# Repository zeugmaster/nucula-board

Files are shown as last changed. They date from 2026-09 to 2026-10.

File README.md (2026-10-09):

# Nucula Board

An ESP32-C3 hardware prototype with USB-C, battery charging, PN7160 NFC,
an SSD1309 OLED interface, and a detachable I²C keyboard section.

**Current production files: [production-2026-10-09-package.zip](manufacturing/production-2026-10-09-package.zip).**
The current board preserves rev-A NFC copper, matching values and placement,
including its small vias, filled/capped fabrication and JLC04161H-3313 stackup.
It retains the corrected display mapping, USB isolation redesign, MINI-1 module,
six M2 holes, inward battery connector and rounded cable notch.
[Production instructions and validation scope](docs/production-release.md).
All previous October packages are superseded for this order. Revised USB/display
operation and the new NFC substitutes still require bench validation. See the
stock-substitution qualification included in this release.

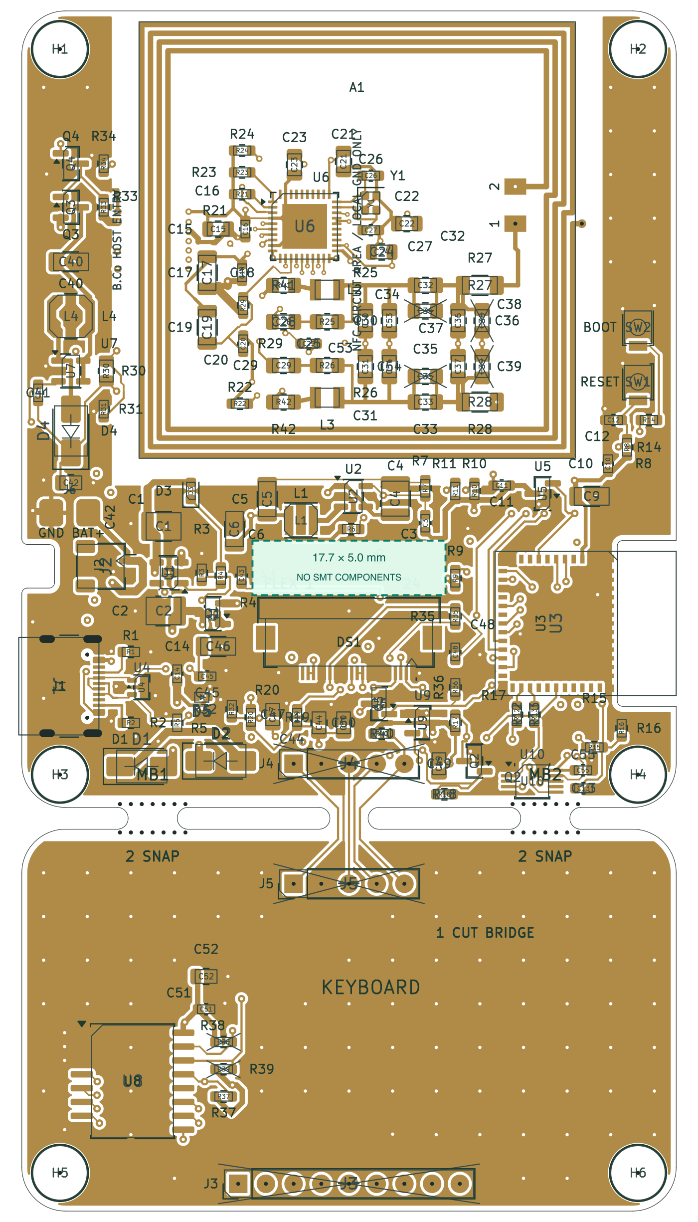
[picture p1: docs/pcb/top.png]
Nucula v2 PCB layout


## Open the design

Clone this repository and open `nucula-v2.kicad_pro` in **KiCad 10** with its
standard symbol, footprint and 3D libraries installed. Project-specific libraries
use relative paths. The project filenames retain the hardware revision name
`nucula-v2`; the GitHub repository is `nucula-board`.

```sh
git clone https://github.com/zeugmaster/nucula-board.git
cd nucula-board
python3 tools/check_schematic.py
```

The check requires Python 3 and KiCad CLI. See [validation and repository
notes](docs/publication.md) for other checks, dependencies and historical inputs.

## Hardware and documentation

The five-sheet schematic contains the ESP32-C3-MINI-1-H4X, native USB-C data,
a 100 mA single-cell Li-ion charger with JST-SH connector, USB/battery supply
selection, a 3.31 V buck rail, and boot/reset/voltage supervision. It is adapted
from Olimex ESP32-C3-DevKit-Lipo **revision C**. It now includes the PN7160 NFC
controller and antenna matching tree, SSD1309 OLED glass driver/boost supply,
and a detachable PCF8574T keyboard section. The four-layer PCB is placed and
routed, with all components on top and the NFC circuitry inside the coil.

- [M2 mounting-hole positions, clearances and validation](docs/mounting-holes.md)
- [MINI-1 compatibility, pin map, antenna fit and firmware requirements](docs/esp32-mini.md)
- [Completed PCB layout, layer drawings and validation](docs/pcb-layout.md)
- [Rev-A display correction, backfeed investigation and measurements](docs/bringup/rev-b-display-and-usb.md)
- [Rev-A bench procedure with enlarged probe-pad map (PDF)](docs/bringup/rev-A-usb-bench-guide.pdf)
- [Routing repair, before/after comparison and geometry audit](docs/routing-review.md)
- [Standard manufacturing package and order settings](docs/manufacturing-release.md)
- [Current prototype manufacturing ZIP](manufacturing/production-2026-10-09-package.zip)
- [Side-entry battery connector selection, polarity and assembly instructions](docs/battery-connector.md)
- [Circuit simulation screening, findings and model limits](docs/simulation/README.md)
- [Schematic PDF](docs/schematic.pdf)
- [Design choices, datasheets and outstanding hardware limits](docs/power-design.md)
- [NFC, OLED, I²C pin map and breakaway keyboard design](docs/peripherals-design.md)
- [35 mm keyboard breakaway geometry and separation instructions](docs/keyboard-breakaway.md)
- [40 mm NFC coil, calculated matching values and prototype tuning guide](docs/nfc-antenna.md)
- [Selected crystal, capacitor calculations and confirmed prototype interfaces](docs/component-refinements.md)
- [Five-board assembly audit and historical sourcing notes](docs/assembly-readiness.md)
- [Manufacturing simplification and ribbon-clearance changes](docs/standard-fabrication.md)
- [BOM](docs/bom.csv) and [verification results](docs/verification.json)
- [Project library sources and licenses](libraries/README.md)

Battery target: approximately 400 mAh, protected single-cell Li-ion/LiPo,
3.7 V nominal / 4.2 V full. J2 is **JST SH SM02B-SRSS-TB(LF)(SN), C160402**:
**side entry, 1.00 mm pitch, 2.95 mm mated height**, opening toward the left
edge. Use an **SHR-02V-S-B** lead, pin 1 positive and pin 2 ground; the old
PH plug no longer fits. Charging remains 100 mA (0.25C at 400 mAh).
Battery operation remains optional. The user accepts intermittent peaks above
the connector's 1 A rating; no current limit is added. Runtime, discharge
qualification and low-battery improvements remain deferred.
[Connector dimensions, current assumption and assembly details](docs/battery-connector.md).
The intended USB source is a dedicated **5 V / at least 1.5 A** supply; the
steady-state planning budget is about 1.10 A including charging. Startup/inrush
must be tested; operation from arbitrary computer hosts is not qualified.

Run `python3 tools/check_schematic.py` to repeat ERC, connectivity, pad/model and
voltage checks. KiCad's standard symbols, footprints and 3D models are required;
`KICAD_CLI` and `KICAD_SHARE` can override their locations. The project-specific
parts and the ESP32 STEP model are included with relative paths in `libraries/`.
The optional PN7160 3D model is omitted because its terms prohibit redistribution;
its symbol and electrical footprint are included.
All 130 schematic components have assigned footprints; the PCB also includes
two breakaway footprints and six mechanical mounting holes. A1 is a reusable four-turn
40 × 40 mm PCB coil with its bottom return and copper keepout included. The NFC
tree retains the rev-A values, 0805 tuning pads and TX isolation links; no retuning
change was made for this release. [A separate bare-coil coupon](prototypes/nfc-antenna/nfc-antenna.kicad_pro)
is available for fabrication and measurement. The OLED now uses the **24-contact
CON24 pinout** in the reference breakout schematic, superseding the earlier
26-contact assumption. DS1 is a Hirose FH12A-24S-0.5SH(55), 0.5 mm top-contact socket (C506794).
[Pinout and regression checks](docs/oled24/README.md) cover all 24 connections.
In the mounted PCB top view, panel pin 1 is left and pin 24 right:
**panel pin n connects to Hirose socket pad 25−n**. The manufacturer footprint
numbering is preserved; the mounted-contact checker now verifies this distinction.
The target panel has ribbon marking **NFP1309-02Y**: 2.4-inch COG,
0.50 mm pitch, 0.30 mm flex, contacts on the emitting face. In its confirmed
mounted position the tip contacts face away from the PCB. The
[top-contact update and checks](docs/oled24/top-contact.md) cover the new lands,
paste apertures and 0.20 mm placement adjustment. The display and external keypad are excluded
from the assembly BOM; DS1 purchases the socket only.
See the library notes for unavailable models.

The shared I²C bus runs at 100 kHz: PN7160 `0x28`, SSD1309 `0x3C`, PCF8574T `0x20`.
PCF8574T is an eight-bit I/O expander; no bus multiplexer is needed.
Its SOIC-16W_7.5x10.3mm_P1.27mm footprint matches the earlier BOM.
J3 is the user-fitted, DNP nine-pin keyboard header: **pins 1 and 9 are NC;
pins 2–8 connect to P0–P6**, preserving the early board's seven-line order.
[Keypad pinout and scanning notes](docs/keyboard-interface.md).
J4/J5 are optional DNP
five-pin headers for reconnecting the keyboard section after separation.

Y1 is now NDK NX2016SA-27.12MHZ-EXS00A-CS06346 (JLCPCB C3008209),
2.0 × 1.6 mm, with calculated 12 pF / 15 pF load-capacitor starts. Power
capacitor ordering codes and larger bulk footprints are selected using archived
manufacturer DC-bias curves. Run `python3 tools/check_component_choices.py` to
reproduce those estimates. RF tuning, oscillator qualification and power
measurements remain prototype bring-up work. **Placement and routing are complete**
for the agreed USB-powered prototype. Native PCB DRC has zero errors and zero unconnected or schematic-parity findings.
The 33 reviewed warnings are cosmetic. The exact NFC comparison covers 43
footprints and 366 routing objects. Strict routing findings inherited from the
proven NFC layout are disclosed and preserved; there are no new routing findings.
The 261 preflight and 57 USB SPICE cases were rerun, plus the independent NFC
numerical cross-check. [Full scope](docs/production-release.md).

Git tracks design files, project libraries and documentation. Local editor state,
lock files, automatic backups and KiCad's `.history` are ignored.

Manufacturing files now target five bare four-layer boards, nominal 1.6 mm,
black mask, white legend and ENIG using the rev-A JLC04161H-3313 stackup.
All small plated round holes require epoxy filling and copper capping; the
restored NFC uses 0.20 mm drill / 0.45 mm land and 0.30 / 0.60 mm vias.
There is no controlled-impedance requirement. The October package includes
119-part placements, stencil data, assembly drawings, and JLCPCB BOM/CPL inputs.
Its BOM includes the USB redesign and side-entry J2. J6 direct battery wire pads
are etched copper and need no purchased component.
[Manufacturing changes and validation](docs/standard-fabrication.md).

The [JLCPCB r2 archive](manufacturing/jlcpcb-2026-09-21-r2-package.zip) records
the previously submitted board and remains unchanged. Its order settings and
placements belong to that earlier design. Use the October prototype package
for the revised design; USB reconnection, ESD and display operation still need
validation on revised hardware.

## License and attribution

The hardware design is distributed under [CERN-OHL-S-2.0](LICENSE), retaining
the attribution and license of the Olimex ESP32-C3-DevKit-Lipo revision C design
from which the power section was adapted. Third-party library assets and
reference documents retain their own terms; see [library attribution](libraries/README.md)
and [LICENSES](LICENSES/). These notices do not grant additional rights to
third-party material. Firmware is not included in this repository.

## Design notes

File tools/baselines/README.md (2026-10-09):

# Sanitized regression inputs

These ZIPs contain the design/report files used by the historical USB and OLED
regression checks. They preserve comparison geometry without publishing private
Git history. Filenames identify the original revision. Personal filesystem paths
and the restricted optional PN7160 3D-model reference have been removed; circuit
connections, pad geometry, placement and routing are preserved.

Read them through `historical_source.read_baseline`. The hardware license and
third-party attribution at the repository root apply to these inputs as well.

`rev-A-nfc.zip` pins the submitted rev-A board/schematic, manufacturing export
stackup and native copper-geometry extraction for the exact NFC freeze audit.
The source board SHA-256 is independently checked against the recorded release.

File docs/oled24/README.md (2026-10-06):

# OLED correction to the 24-contact interface

2026-09-21 · KiCad 10.0.6

**Current socket: FH12A-24S-0.5SH(55), C506794, top contacts.**
The [subsequent top-contact update](top-contact.md) supersedes the socket and
placement described in the historical 26-to-24-contact correction below.
**October correction:** mounted panel pin 1 is PCB-left and pin 24 PCB-right.
Display pin n now maps to **DS1 socket pad 25−n** at the unchanged 180° placement.
Use the [mounted-contact checks](mounted-mapping-check.json) and
[current correction report](../bringup/rev-b-display-and-usb.md).
The sections below record the historical September change against `600d88a`;
their contact numbers describe the panel, not the corrected socket pads.

The user's [exact breakout schematic](../../parts%20documentation/i2c-display-breakout-schematic.png.png)
shows **J1 CON24**. This supersedes the previous 26-contact assumption.
The project symbol, schematic, PCB footprint, 3D socket model, BOM and purchasing
data now use **24 contacts**. The symbol describes the glass interface; the
purchased DS1 item is the socket, **Hirose FH12-24S-0.5SH(55), C202112**.

## Pinout checked against the supplied image

| Contacts | Breakout function | Project connection |
|---|---|---|
| 1, 2, 3 | GND, VLSS, VSS | GND |
| 4 | N.C. | Explicitly unconnected |
| 5 | VDD | +3V0 logic supply |
| 6 | BS1 | +3V0; I²C interface selection |
| 7, 8 | BS2, CS# | GND |
| 9 | RES# | OLED_RES_N, Q5/R35/C48 reset network |
| 10 | D/C# | GND; I²C address 0x3C |
| 11, 12 | R/W#, E/RD# | GND |
| 13 | D0 | I2C_SCL |
| 14, 15 | D1, D2 | Both connect to I2C_SDA |
| 16–20 | D3–D7 | GND |
| 21 | IREF | OLED_IREF, R32 = 910 kΩ to GND |
| 22 | VCOM | OLED_VCOMH, C47 to GND |
| 23 | VOP | OLED_12V5 panel supply |
| 24 | GND | GND |

Pins 1–24 retain their previous net assignments. Only the nonexistent ground
contacts 25 and 26 were removed. Pin 2's label is corrected to VLSS and pin 23's
label to VOP_PANEL. The project's existing 3.0 V logic supply, switched AP3012
boost, reset translation and component values remain unchanged; this update
does not claim to duplicate the breakout's XC6206/HM1308 circuitry.

[Machine-readable source map](pinout.json) records the reference image hash and
all 24 expected connections independently of the symbol and PCB.

## Placement and routing

DS1 remains locked at **(80, 108.65 mm), 180° on F.Cu**. The standard 24-position
footprint is 1 mm narrower than the former 26-position version. Keeping its
center fixed moves each retained contact 0.50 mm left on the board.

The local pad escapes were rerouted, with 43 old segments replaced by 40 new
segments and five existing vias shifted. The board now has **1,066 trace segments
and 321 vias**. Changes are confined to the OLED connector area. Copper zones
were refilled on all four layers without altering zone boundaries or rules.

All other 129 footprints are identical to the saved baseline. Component
positions, population flags, values, antenna copper and keepouts, symmetric NFC
matching branches, USB routing, keyboard breakaway and all board graphics are
preserved, including the user's back silkscreen and black mask settings.

## Regression results

- Native ERC: **0 violations**, five sheets, 128 physical components, 91 nets.
- Native PCB DRC with all-track checking: **0 errors, 0 unconnected items,
  0 schematic parity issues**. The same two U3 silkscreen-edge warnings remain,
  with the same affected item UUIDs as the freshly checked baseline.
- **23/23 existing layout checks pass**, including all-layer NFC pour exclusion,
  fixed placements, matched RF geometry, breakaway crossings and USB ground reference.
- **31/31 connector and regression checks pass**. All 91 nets are identical
  except for removing DS1.25/26 from GND. No unrelated validation constraints
  were relaxed. KiCad's omission of an empty `zone_defaults` element is ignored
  as serialization normalization; actual setup and stackup settings match.
- All physical symbols resolve to footprint pads; referenced 3D models resolve.
  Assembly audit passes with the new exact socket MPN and C-code.
- All **261 scoped ngspice cases** completed without solver errors. Numerical
  results match the previous run exactly, including its already documented
  600 pF I²C stress-limit failure. This is regression evidence for the modeled
  circuits, not full-board or panel simulation.
- The updated OLED schematic and connector rendering were visually reviewed.
  The PCB editor was reloaded after confirming it held no intervening edits.

[Regression report](regression-check.json) · [Baseline DRC](baseline-drc.json) ·
[Current DRC](../pcb/drc.json) · [Layout checks](../pcb/layout-check.json) ·
[Schematic PDF](../schematic.pdf) · [PCB layer PDF](../pcb/layers.pdf) ·
[Simulation scope and findings](../simulation/README.md)

Reproduce with `tools/check_schematic.py`, native KiCad PCB DRC,
`tools/check_pcb_layout.py` (KiCad's Python), `tools/check_assembly_readiness.py`,
`tools/simulate_preflight.py` and finally `tools/check_oled24_update.py`.
The last check compares against commit `600d88a` and requires fresh simulation
and netlist results for the current saved design.

## Panel identification and remaining mechanical check

On 2026-09-21 the user identified one of the intended displays as a **2.4-inch
chip-on-glass panel with `NFP1309-02Y` printed on its ribbon**, and confirmed:

- **0.50 mm contact pitch**.
- **0.30 mm insertion thickness**.
- **Exposed contacts on the same face as the light-emitting display surface**.
- **With the display mounted and ribbon folded into DS1, the tip contacts face
  away from the PCB** (subsequently confirmed by the user).

These are user-confirmed properties of that panel. An exact-marking web search
did not locate a manufacturer datasheet; the ribbon marking is not treated as a
verified manufacturer ordering code. Other display variants must be checked
separately. The supplied CON24 breakout remains the electrical pin-map source.

The selected socket is now **Hirose FH12A-24S-0.5SH(55), C506794**, with top
contacts matching the confirmed insertion orientation. Its manufacturer drawing,
lands, pin order, paste pattern and updated placement have been checked. The
[completed connector update](top-contact.md) includes the revised schematic/PCB,
BOM, sourcing observation and regression reports. The 0.20 mm move toward the
keyboard clears the larger latch while keeping all other footprints fixed.

The panel pin-1 reversal was confirmed during Rev-A testing and corrected in
October. Insertion length, fold strain, enclosure clearance and operation with
the corrected board still require physical prototype checks.

The **OLED panel and external keyboard/keypad remain excluded from the assembly
BOM and CPL**. DS1 purchases only the PCB socket; onboard display support and
keyboard interface components remain populated as specified. J3/J4/J5 remain
DNP/user-fitted. Panel current, sequencing and optical operation still require
prototype validation; no glass assembly model or validated panel SPICE model
is claimed.

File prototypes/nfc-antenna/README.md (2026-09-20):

# Bare NFC coil measurement coupon

Open `nfc-antenna.kicad_pro` in KiCad 10. This **46 × 48 mm** coupon contains
the same reusable antenna footprint assigned to A1 in the main schematic.
It is a passive two-terminal coil, without NFC controller, matching network or
ground plane. It is not the main product PCB.

Fabrication assumptions:

- Two copper layers, 1.6 mm FR4, 35 µm finished copper per layer.
- Four turns, 40 × 40 mm outer winding copper, 0.50 mm traces / 0.30 mm gaps.
- Two **plated** 0.40 mm holes complete the bottom-layer return; do not make them NPTH.
- Retain soldermask over the windings and underpass. Expose only the feed pads
  shown in the mask Gerbers. The inner hole has no mask opening.
- No copper pours, metal backing, ferrite, components or added test loops.
- `gerbers/` contains the copper/mask/silk/outline files and separate PTH/NPTH
  Excellon drill files. The NPTH drill file is intentionally empty.

Solder a short calibrated fixture to terminals 1 and 2 and measure while
unpowered. The two terminals are expected to be DC-connected through the coil.
Avoid adding a cable loop or measurement-fixture ground plane behind the coil.
Save the raw impedance sweep, fixture calibration and final assembly environment.

See [the design and tuning guide](../../docs/nfc-antenna.md) for measurements,
calculations, limitations and how to use the footprint in the main layout.
Native KiCad DRC and independent same-net clearance checks pass; RF behavior
still requires measurement.

Regenerate the coupon using `tools/nfc/check_coil.py` with KiCad's `pcbnew`
Python. This regenerates the `.kicad_pcb` and validation preview, so preserve
any manual coupon changes first. Re-export Gerber/drill outputs after edits.

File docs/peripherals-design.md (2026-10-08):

# NFC, OLED and detachable keyboard

Updated for MINI-1, 2026-10-08; peripheral circuitry is unchanged. The project now has five schematic sheets:
system interconnect, power/ESP32, NFC, OLED, and keyboard.
[Combined drawing](schematic.pdf), [BOM](bom.csv), [verification](verification.json).
The main PCB is placed and routed, with its 35 mm detachable keyboard section
and five preserved breakaway interconnects. See the [layout report](pcb-layout.md)
for layer drawings and validation. Firmware remains to be completed. A separate
NFC coil measurement coupon and reusable coil footprint are available.

## Shared I²C and MCU connections

| Function | ESP32 GPIO | MINI-1 module pad | Notes |
|---|---:|---:|---|
| SDA | 4 | 18 | Shared open-drain data |
| SCL | 5 | 19 | Shared open-drain clock |
| NFC IRQ | 6 | 20 | PN7160 interrupt |
| NFC VEN | 7 | 21 | High enables NFC; external default low |
| OLED power | 3 | 6 | High connects boost input; external default low |
| OLED reset | 10 | 16 | High asserts reset through Q5 |
| Keyboard INT_N | 20 | 30 | Active-low, open-drain interrupt |

USB stays on GPIO18/19; battery ADC, USB detection, boot straps and reset
supervision are preserved. GPIO21 remains available for later additions.

| Device | Reference | Seven-bit address | Address selection |
|---|---|---|---|
| PN7160A1HN/C100E | U6 | `0x28` | ADR1/ADR0 pulled low |
| SSD1309 OLED glass | DS1 | `0x3C` | SA0 low |
| PCF8574T | U8 | `0x20` | A2/A1/A0 grounded |

Use **100 kHz**, the PCF8574T's maximum bus speed. R19/R20 provide the only
populated SDA/SCL pull-ups: 2.2 kΩ to **3.0 V**. Keep ESP internal pull-ups off.
U9, MCP1700T-3002E/TT, supplies the OLED logic and these pull-ups from +3V3.
Its SOT-23 pinout is **1 GND, 2 OUT, 3 IN**. C49/C50 provide local bypassing.

The SSD1309 specifies 3.3 V maximum operating logic supply, while the existing
buck's static upper bound is 3.393 V. A dedicated 3.0 V rail provides margin.
The estimated regulated range, including temperature and a full-load allowance,
is 2.865–3.135 V. This exceeds the largest calculated high-level requirement
of 2.545 V across the bus devices. At 400 pF, the pull-up RC estimate is 753 ns,
within the 1 µs standard-mode rise-time limit; low-level sink current is about
1.26 mA at 0.4 V. These checks assume U9 is regulating: measure low-current
dropout, startup and load transients on hardware, especially near low-battery
reset. Keep wiring short and total capacitance at or below 400 pF.
[MCP1700 datasheet](https://ww1.microchip.com/downloads/en/DeviceDoc/MCP1700-Data-Sheet-20001826F.pdf),
[PCF8574 datasheet](https://www.nxp.com/docs/en/data-sheet/PCF8574_PCF8574A.pdf),
[ESP32-C3-MINI-1 datasheet](https://documentation.espressif.com/esp32-c3-mini-1_datasheet_en.pdf).

## PN7160 and antenna network

The full balanced matching tree comes from the user-supplied
[PN7160 breakout schematic](../parts%20documentation/PN7160_schematic-3.pdf).
The I²C variant is **PN7160A1HN/C100E**, with a local symbol, HVQFN40 footprint
and STEP model. Pin numbers were checked against the
[NXP datasheet](https://www.nxp.com/docs/en/data-sheet/PN7160_PN7161.pdf) and
[hardware design guide AN12988](https://www.nxp.com/docs/en/application-note/AN12988.pdf).

VDD_PAD uses +3V3. VBAT/VBAT2 and VDD_UP use VSYS, allowing USB-only operation
without a battery. R29 is the 0 Ω VDD_UP feed. Internal regulator output pin 31
feeds VDDA/VDD pins 26/27; internal TX regulator pin 14 feeds pins 18/22.
Neither internal output is tied to an external supply. C15–C25 decouple each
domain and VMID; all ground pads, including exposed pad 41, are connected.

VEN and DWL_REQ default low. WKUP_REQ is grounded for I²C wake-up. ANT1/ANT2
and VDHF are unused; firmware must use the corresponding normal RF-detection
configuration. I²C address selection is documented in
[NXP UM11495](https://www.nxp.com/docs/en/user-manual/UM11495.pdf).

| Supplied RF reference | Project refs | Role |
|---|---|---|
| L1 / L2 | L2 / L3 | Series EMC inductors |
| C53 / C54 | C30 / C31 | Post-inductor shunt capacitors |
| C52 / C56 | C32 / C33 | Primary series matching |
| C51 / C55 | C34 / C35 | Parallel series trim, DNP |
| C61 / C63 | C36 / C37 | Antenna-side shunt capacitors |
| C62 / C64 | C38 / C39 | Parallel shunt trim, DNP |
| R13 / R14 | R27 / R28 | Series damping |
| C59 + R11 | C28 + R25 | RXN tap from the TX1 post-inductor node |
| C58 + R12 | C29 + R26 | RXP tap from the TX2 post-inductor node |
| A1 | A1 | New etched loop: pads 1/2 only, no ground or center tap |

The [NFC antenna design and tuning guide](nfc-antenna.md) supersedes the former
RF placeholders. A1 is now a 40 × 40 mm four-turn loop, 0.50 mm tracks, 0.30 mm
gaps and 35 µm copper, with an estimated 1.56 µH inductance. The complete
starting tree uses 150 nH / (330 + 33) pF EMC filtering, 68 pF series / 100 pF shunt
matching, 2.7 Ω damping and 2.2 kΩ / 1 nF RX taps. RF capacitors use hand-solder
0805 footprints and 100 V C0G. Damping resistors use high-power 1206 parts.
C53/C54 are populated 33 pF parallel EMC capacitors; R41/R42 add removable TX isolation links.
The selected target is 20 Ω differential; start at TVDD ≤3.3 V. Values remain
prototype starts requiring VNA, receive-level and current/thermal validation.

Y1 is NDK **NX2016SA-27.12MHZ-EXS00A-CS06346**, 27.12 MHz, 10 pF load,
2.0 × 1.6 mm, an explicit AN14518 reference (JLCPCB C3008209).
C26 = 12 pF and C27 = 15 pF are calculated prototype starts, 0603 C0G.
C21/C22 and C23/C24 are now separate 2.2 µF 0805 capacitors for the local
logic and TX supply pins, per AN12988. Selected ordering codes, oscillator
assumptions and power-capacitor bias calculations are in
[component refinements](component-refinements.md). Frequency/startup/drive
and power transients still need measurement after layout.

## OLED glass and boost supply

The supplied [exact CON24 breakout schematic](../parts%20documentation/i2c-display-breakout-schematic.png.png)
defines a **24-contact SSD1309 glass interface**, correcting the earlier
26-contact assumption. DS1 represents the glass interface; the controller is
already on the glass. Pin 6/BS1 is high, BS2 and CS are low, and pin 10/SA0 is
low. Pin 13/D0 is SCL; **14/D1 and 15/D2 both connect to SDA** for data and
acknowledgement. Unused parallel inputs are grounded; pin 4 is NC.
[All 24 pins are independently checked](oled24/README.md).

The project retains its shared 3.0 V logic supply and switched AP3012 boost
instead of the breakout's XC6206 and HM1308 stages. All I²C hosts share compatible
voltage levels and open-drain signaling. Q5 translates the MCU reset signal
without applying a 3.3 V push-pull level to the OLED logic rail.

U7 is **AP3012KTR-E1**, with 10 µH Coilcraft LPS4018-103MRC and an SS14
Schottky output diode. R30/R31 = 1.8 MΩ / 200 kΩ, both 0.1%, set nominal
**12.5 V**. Reference/bias/divider corner estimates are 11.50–13.50 V, within
SSD1309's 7–16 V range. R32 = 910 kΩ retains the reference IREF starting point;
contrast and actual panel current still require validation.
[AP3012 datasheet](https://www.diodes.com/datasheet/download/AP3012.pdf),
[Coilcraft LPS4018 specifications](https://www.coilcraft.com/en-us/products/power/shielded-inductors/ferrite-drum/lps/lps4018/lps4018-103/),
[SSD1309 datasheet](https://files.waveshare.com/wiki/2.42inch-OLED-Module/SSD1309Datasheet.pdf).

Q3/Q4 disconnect the **input** of the boost stage, including its diode
feed-through path, while the OLED logic stays powered. The boost defaults off.
There is no active OLED-rail discharge, following SSD1309's guidance to let
VCC float when switched off. Firmware must:

1. Keep OLED power off while logic stabilizes; assert GPIO10 high for reset.
2. Hold reset for at least 3 µs (use 1 ms), release it, and allow the reset RC
   to rise (at least 5 ms for the present 10 kΩ / 100 nF network).
3. Initialize the SSD1309, enable OLED power, wait for the boost to settle,
   then issue display-on `AFh`.
4. On shutdown, issue display-off `AEh`, disable the boost and keep logic
   powered. Validate power-fail/rapid restart behavior on the actual glass.

A 30 mA panel-load scenario at 3 V input, 75% assumed efficiency, minimum
switching frequency and −20% inductance gives approximately 0.313 A peak
inductor current. The AP3012's 500 mA switch limit is **typical**, not a
guaranteed display-output rating. Full-white current, efficiency and overshoot
must be measured before fixing brightness limits.

DS1 uses **Hirose FH12A-24S-0.5SH(55)**, a 24-way 0.50 mm top-contact socket,
JLCPCB **C506794**. The OLED panel is supplied separately and excluded from the
assembly BOM. The user-confirmed NFP1309-02Y flex has 0.30 mm thickness and its
mounted tip contacts face away from the PCB. The
[connector update](oled24/top-contact.md) preserves all 24 net assignments and
rotates nothing, moving DS1 only 0.20 mm toward the keyboard for latch clearance.

## Breakaway keyboard

U8 is **PCF8574T**, an eight-bit quasi-bidirectional I/O expander, in the same
wide SOIC-16 footprint as the earlier BOM. J3 is a **DNP/user-fitted 1×9,
2.54 mm header**: **pins 1 and 9 are unconnected**, and **pins 2–8 connect
to P0–P6**. U8 P7/pin 12 is also unused and marked NC. This preserves the old
board's J2.1–7 → P0–P6 order, shifted into the center seven positions.
All seven are matrix signals; the keypad header has no fixed ground or power
pin. For the common Adafruit 3845 arrangement, rows are P1/P6/P5/P3 and
columns are P2/P0/P4. Other keypad families can use another firmware map.
Write 1 to release a PCF pin for input and drive one scan column low at a time.
See [researched pinout, orientation and scanning notes](keyboard-interface.md).

Every physical part on `keyboard.kicad_sch` carries
`PCB Region = BREAKAWAY_KEYBOARD`. Only five nets cross the break line:
+3V3, GND, SDA, SCL and INT_N. J4 on the main board and J5 on the detachable
section are DNP 1×5, 2.54 mm headers with matching pin order:

| Pin | Signal |
|---:|---|
| 1 | +3V3 |
| 2 | GND |
| 3 | SDA |
| 4 | SCL |
| 5 | INT_N |

The [implemented 35 mm breakaway](keyboard-breakaway.md) uses two perforated
support tabs and a separate central electrical bridge. Cut that bridge before
snapping the support tabs. While attached, PCB traces provide these connections. After separation,
populate J4/J5 and reconnect straight through. R37 provides the module INT
pull-up; R40 keeps the MCU input defined when the module is absent. R38/R39
are DNP optional bus pull-ups for standalone use; leave them unpopulated when
connected to the main board. Layout must keep parts/pads away from fracture
areas and control every trace and plane crossing. Hot-plug operation and long
cables are not designed or qualified.

## Power budget

NFC transmitter and OLED boost power come directly from VSYS; their load is
additional to the existing buck rail. An illustrative simultaneous upper-load
scenario at 3.2 V VSYS is:

| Load assumption | Approximate VSYS current |
|---|---:|
| 3.31 V rail at its 500 mA design target, 85% buck efficiency | 609 mA |
| NFC allowance: 250 mA transmitter plus 40 mA controller | 290 mA |
| OLED at 12.5 V / 30 mA, 75% boost efficiency | 156 mA |
| Total, before small auxiliary currents | 1.06 A |

This is a planning scenario, not a measured consumption claim or guaranteed
worst case. NFC matching/configuration and display content affect actual load.
A 400 mAh pack would need roughly 2.7C capability for this scenario; many small
packs cannot supply it. Select a suitable protected cell or constrain concurrent
RF/Wi-Fi/display use and brightness. D1/D2 are upgraded to B340A for current
margin, but voltage drop, temperature and copper still need verification.

Battery performance is now deferred by user instruction. Charging remains
100 mA. For this USB-powered prototype, use the user-confirmed source of
5 V / at least 1.5 A; the updated steady-state estimate is 1.10 A including
charging. See [USB calculation and limits](component-refinements.md#usb-operation-and-deferred-battery-work).
Ordinary USB-host current/suspend behavior and inrush are not qualified.

## Verification and remaining selections

`python3 tools/check_schematic.py` passes native ERC on all five sheets:
**128 components, 91 nets, zero errors/warnings**. It checks 58 named net groups,
additional internal connections and ground/NC pads, all physical symbol-to-pad
mappings, DNP/region/address fields, available model paths and static voltage
calculations. The five-page PDF was rendered and visually inspected.

Crystal and critical supply MLCC ordering codes are now selected; see
[component refinements](component-refinements.md). The user supplied the
24-contact OLED reference and confirmed the 5 V / at least 1.5 A USB-C supply.
PCB placement and routing are complete. RF/oscillator tuning, display sequencing/current and USB power
transients require prototype measurements. Battery runtime and improved
low-battery behavior are deferred, as accepted by the user.

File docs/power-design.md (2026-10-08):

# USB-C, battery power and ESP32-C3 draft

**6 October redesign:** the accepted Rev-A backfeed path is removed in the
editable design. U4 now clamps data to ground, D5 protects VBUS separately,
and U10 isolates the data pair when VBUS is absent. R17/R18 are now 10 kΩ.
See the [current circuit, checks and remaining bench validation](bringup/usb-backfeed-fix.md).
The September circuit discussion below is historical where it describes U4 or USB tuning capacitors.

Revision B-draft, updated 2026-09-20. Open `nucula-v2.kicad_pro` in KiCad 10.
The schematic is complete for this draft. The PCB is now placed and routed;
see the [layout and validation report](pcb-layout.md).
[PDF drawing](schematic.pdf), [BOM](bom.csv), [verification results](verification.json).

## Reference and scope

Adapted from Olimex **ESP32-C3-DevKit-Lipo revision C**, dated 2026-01-09,
from the local reference repository at commit
`5d93e79d46cf3b05782d9fe0f95a8a2e1ca6abbe`:
`HARDWARE/ESP32-C3-DevKit-Lipo_Rev_C/ESP32-C3-DevKit-Lipo_Rev_C.kicad_sch`.
[Upstream hardware repository](https://github.com/OLIMEX/ESP32-C3-DevKit-Lipo).

The retained circuit is TP4054 charging, Schottky/MOSFET USB-priority power
selection, and an SY8089 buck converter. The current MINI-1-H4X uses the smaller module family from the reference
design, replacing the previous WROOM-02-N4. Its 53 physical pins were checked
against Espressif's datasheet. [Compatibility and pin map](esp32-mini.md).
This circuit is now on `power-mcu.kicad_sch`. NFC, OLED and I/O expansion are
integrated on separate sheets; see [peripheral design](peripherals-design.md).
Firmware remains outside this draft. PCB placement and routing are documented
in the separate layout report.

## Power behavior

- USB: J1 VBUS → D1 → `USB_5V`. This supplies the charger and, through D2,
  `VSYS`. Q1 is off, separating the running system from charge-current sensing.
- Battery only: R5 pulls Q1's gate low. Q1 conducts from battery to `VSYS`.
  **Q1 drain is VBAT; source is VSYS.** Its body diode points from battery
  toward the system. D2 blocks current toward the USB supply branch.
- U2 converts `VSYS` to nominal 3.31 V. EN is tied to its input supply.
  The present rail target is 500 mA, conditional on input power and thermal/layout
  verification; the IC's advertised 2 A rating is not a rating for this board.
- USB can run the circuit without a battery. Battery-only operation is supported.
  Hot-plug/load-step performance still requires measurements on a laid-out board.

Battery target: **approximately 400 mAh, protected single-cell Li-ion/LiPo,
3.7 V nominal / 4.2 V full**, with pack protection against overdischarge,
short circuit and overcurrent. J6 offers direct BAT+/GND wire solder pads in parallel with J2; use one battery
connection at a time. J2 is **2-pin JST-SH, 1.0 mm pitch**,
side-entry SM02B-SRSS-TB(LF)(SN) / C160402, **2.95 mm mated height**: **pin 1 positive, pin 2 ground**. Purchased packs do not have universal
connector polarity. The exact pack, polarity, charge limits and discharge-current
rating must be checked before assembly. There is no battery protection IC,
cell-temperature sensor, or physical off switch in this draft.

For the current iteration, battery operation is an optional experiment. The
user accepts the present low-battery/reset behavior and defers runtime and
discharge-budget refinement. USB operation does not require a battery.

Use a matching **SHR-02V-S-B** housing and **SSH-003T-P0.2-H** contacts with
28 AWG wire. The old PH lead is incompatible. SH is available on small flat
packs, including [LiPol's protected 400 mAh LP572528](https://www.lipobattery.us/lp572528-400mah-3-7v-1-48wh-lipo-battery-with-pcm-and-cables-50mm-and-jst-shr-02v-s-b/).
No final battery model is selected. Keep **100 mA charge current**, equivalent
to **0.25C at 400 mAh**, subject to the chosen pack's own limits.

JST rates this connector at **1 A with 28 AWG**. On 7 October the user accepted
intermittent excursions above that rating and requested no new current limiter
or operating restriction. This is a prototype assumption, not a manufacturer
pulse-current guarantee. Confirm voltage drop and heating under actual peak
loads as part of battery validation. [Selection and assembly notes](battery-connector.md).

U1 is the Top Power **TP4054-42-SOT25R**, not the BL4054 symbol name carried by
the reference. R3 = 10 kΩ sets 100 mA nominal; the data sheet specifies
90–110 mA at its stated conditions; the existing 115 mA power-budget allowance
remains conservative. Termination is approximately 10 mA.
C1 and C2 provide input/battery bypassing. D3 indicates charging.
The charger has internal thermal regulation, which does not measure cell temperature.
[Selected C32574 manufacturer datasheet](../parts%20documentation/TP4054-42-SOT25R-C32574-datasheet.pdf).
The catalogue ordering suffix replaces the former SOT235 entry; pins 1–5
remain CHRG, GND, BAT, VCC, PROG and the 10 kΩ setting remains 100 mA.

D1/D2 now use **B340A-13-F**, 3 A / 40 V in SMA, for additional current margin
with NFC and OLED loads. The footprint and topology are unchanged. This rating
depends on terminal temperature and copper area; verify both diode temperatures
in the finished layout. Their forward drop reduces charging headroom: a low USB
voltage or resistive cable can prevent reaching full charge. At a pessimistic
4.75 V input and 0.5 V D1 drop, only 4.25 V reaches U1, close to the battery's
4.242 V maximum float voltage and sleep threshold. Full-charge performance at
minimum VBUS is **not guaranteed**. Validate this corner or replace D1 with a
lower-loss input stage before a product release.
[B340A datasheet](https://www.diodes.com/datasheet/download/B340A.pdf),
[Q1 IRLML6402 pinout and ratings](https://www.infineon.com/assets/row/public/documents/24/49/infineon-irlml6402-datasheet-en.pdf).

## Regulator and low battery

R6/R7 are **220 kΩ / 48.7 kΩ, both 0.1%**. With the 0.6 V feedback reference,
`VOUT = 0.6 × (1 + 220 / 48.7) = 3.310 V`.
Static limits including reference tolerance and ±50 nA feedback current are
approximately 3.228–3.393 V. C3 = 22 pF is the feed-forward capacitor.
C5/C6 provide 44 µF nominal output capacitance; C9/C10 decouple the module.
[Silergy SY8089 application note, supplied by Olimex](https://www.olimex.com/Products/Components/IC/SY8009A/resources/SY8089AAAC.pdf).

L1 is Taiyo Yuden **LSXND3030QKT2R2MNG**, the renamed NRS3015T2R2MNGH used in
Rev C: 2.2 µH, 1.48 A rated current. A 500 mA load scenario with 5.5 V input,
−20% inductance and an assumed 0.8 MHz switching frequency gives about
0.962 A peak. The app note specifies 1 MHz typical, not a guaranteed minimum;
this estimate is not a worst-case guarantee. The 69.6 mΩ maximum DCR exceeds
Silergy's preferred 50 mΩ target; verify loss and temperature in layout.
[Manufacturer specifications and name change](https://ds.yuden.co.jp/TYCOMPAS/eu/detail?pn=LSXND3030QKT2R2MNG&u=M).

The buck cannot maintain 3.3 V over the entire battery discharge curve.
U5, **TLV803EA30DBZR**, monitors the rail and pulls ESP_EN low around 3.08 V.
Its minimum static falling threshold is 3.018 V; maximum release threshold,
including hysteresis, is about 3.189 V, below the calculated minimum regulated
rail. Reset release is delayed about 200 ms. Fast dips still require transient
verification; the supervisor has propagation/glitch delays and EN has capacitance.
It does not disconnect the cell, so a protected battery remains necessary.
The stocked **DBZ/SOT-23 variant has pins 1 GND, 2 RESET, 3 VDD**.
It replaces the out-of-stock DCK/SC70 package; threshold, delay and wiring remain
the same. Use the new SOT-23 footprint, not the old SC70 land pattern.
[TI datasheet](https://www.ti.com/lit/ds/symlink/tlv803e.pdf).

## USB, boot and sensing

J1 has separate 5.1 kΩ CC pulldowns. Both D− contacts feed U4 channel 1,
then R12 = 22 Ω and **GPIO18 / module pin 26**. Both D+ contacts feed U4 channel 2,
then R13 = 22 Ω and **GPIO19 / module pin 27**. U4's pass-through pairs are
pins 1–6 and 3–4. C7/C8 are **DNP**, reserved for USB tuning.
Native USB provides Serial/JTAG and ROM download; there is no UART bridge.
[ST USBLC6-2 datasheet](https://www.st.com/resource/en/datasheet/usblc6-2.pdf),
[Espressif schematic guidance](https://docs.espressif.com/projects/esp-hardware-design-guidelines/en/latest/esp32c3/schematic-checklist.html).

GPIO2/8/9 have pullups. Hold BOOT and tap RESET for download mode.
ESP_EN has the recommended 10 kΩ / 1 µF network plus the supervisor.
GPIO21 remains reserved with an explicit no-connect marker. GPIO4/5 now carry
I²C; GPIO6/7 control NFC; GPIO3/10 control the OLED; GPIO20 receives keyboard INT.

GPIO0/ADC1 senses half the battery voltage through 470 kΩ / 470 kΩ and 100 nF.
The calculated maximum is 2.142 V; use calibrated 11/12 dB attenuation and
allow at least 200 ms after the sensed rail settles for an initial <0.1% RC
settling target. The [simulation screening](simulation/README.md) finds that
120 ms can leave about 1% settling error at +R/+C tolerance; ADC acquisition,
leakage and capacitor temperature effects are separate. High divider impedance and
ADC sampling/calibration need firmware validation. GPIO1 receives inverted
VBUS presence through Q2: LOW means USB present. This avoids a 5 V divider
injecting current into an unpowered GPIO. R18 discharges the VBUS detector.
Firmware must manage USB attachment when VBUS is absent; this is not implemented
by the schematic alone. See the
[ESP32-C3-MINI-1 datasheet](https://documentation.espressif.com/esp32-c3-mini-1_datasheet_en.pdf).

## Boundaries before PCB

This preserves Rev C's simple input arrangement. **It does not implement USB
input-current negotiation/limiting, charger suspend control, or controlled
charging of the input capacitors.** C1+C4 alone total 44 µF nominal behind the
diodes. Do not treat two CC resistors or a zero-error ERC as USB compliance.
A full 500 mA rail load plus charging can exceed a legacy USB 2.0 port's 500 mA
budget. The prototype's user-confirmed source is **5 V USB-C with at least
1.5 A available at 5 V**; the updated planning estimate is 1.10 A including
charging. See [component refinements](component-refinements.md). Adequate
source current capability does not replace USB host enumeration, suspend or
inrush requirements. Product-level use with arbitrary hosts needs a power-budget
and input-management revision before layout. The added NFC and OLED loads are
supplied from VSYS. Simultaneous peak use can exceed 1 A at a low battery;
the 400 mAh capacity alone does not establish a suitable discharge rating.
See the explicit load assumptions in [peripheral power budget](peripherals-design.md#power-budget).
[USB-IF specifications](https://www.usb.org/document-library/usb-20-specification).

Critical MLCC ordering codes are now selected using archived manufacturer
DC-bias curves: C1/C2/C4 use 22 µF 25 V X7R 1210; C5/C6/C9 use 22 µF
25 V X5R 1206. The screening estimates retain >10 µF each at the input
and >22 µF combined for C5/C6. These are estimates, not guaranteed
combined-corner specifications. Check charger heat, Wi-Fi load steps, low-cell reset,
USB insertion/removal, charging termination and battery-only leakage. Verify
90 Ω USB routing, short ESD return paths, buck switching loops and feedback
routing, and the module antenna keepout when PCB work begins.

## Verification and libraries

`python3 tools/check_schematic.py` runs native KiCad ERC, exports the netlist,
checks critical pin groups independently of drawing coordinates, checks selected
values/tolerances and DNP flags, matches physical symbol pins to footprint pads,
resolves assigned models, and recalculates the static limits above.
The combined draft has **128 components across five sheets and zero ERC
errors/warnings**. Footprint
filter checking is enabled. The drawing was also rendered and visually inspected.
This is schematic verification, not circuit simulation or hardware validation.

`Nucula_Project` is registered with `${KIPRJMOD}` paths. It contains the exact H4X
module, TP4054, SY8089 and TLV803 symbols, module footprint/STEP and the inductor
footprint. Standard components use KiCad's installed libraries/models.
L1 has **no assigned 3D model**: the stock footprint's referenced model is missing,
and the manufacturer's old/new part download links returned HTTP 404. The local
footprint omits that broken reference. All other assigned models resolve.
BOM passives remain specification-based rather than procurement-ready ordering
codes. Downloaded datasheets are under `parts documentation/`; ST's PDF link is
recorded above because its direct file download failed.

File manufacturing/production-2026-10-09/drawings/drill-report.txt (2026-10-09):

Drill report for nucula-v2.kicad_pcb
Created on 2026-10-09T12:55:11

Copper Layer Stackup:
    =============================================================
    L1 :  F.Cu                      front
    L2 :  In1.Cu                    in1
    L3 :  In2.Cu                    in2
    L4 :  B.Cu                      back

Drill file 'nucula-v2-PTH.drl' contains
    plated through holes:
    =============================================================
    T1  0.200mm  0.0079"  (14 holes))
    T2  0.300mm  0.0118"  (299 holes))
    T3  0.400mm  0.0157"  (2 holes))
    T4  0.700mm  0.0276"  (4 holes)  (with 4 slots)
    T5  1.000mm  0.0394"  (19 holes))

    Total plated holes count 338

Drill file 'nucula-v2-NPTH.drl' contains
    unplated through holes:
    =============================================================
    T1  0.600mm  0.0236"  (28 holes))
    T2  0.650mm  0.0256"  (2 holes))
    T3  2.200mm  0.0866"  (6 holes))

    Total unplated holes count 36

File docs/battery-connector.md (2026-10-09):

# Battery connector, cable notch and direct wire pads — 8 October 2026

Fit **JST SM02B-SRSS-TB(LF)(SN), JLCPCB C160402**, a **1.00 mm pitch JST-SH
side-entry SMT header, 2.95 mm high when mated**. Its opening faces the left
PCB edge; the battery lead lies parallel to the board. Use a matching
**SHR-02V-S-B** crimp housing (or SHR-02V-S without handling protrusions),
with **SSH-003T-P0.2-H** contacts and 28 AWG wire. **The existing 2.0 mm JST-PH
battery plug does not fit.** Preserve **pin 1 = battery positive, pin 2 = GND**;
purchased battery leads do not have universal polarity.

**J6 provides two direct battery-lead solder pads above J2.** Each exposed
front copper land is **2.2 × 2.5 mm**, on **3.4 mm centres**, with no holes or
stencil paste. Viewed from the top with USB at the bottom, the **left pad is
GND (pin 2)** and the **right pad is BAT+ (pin 1)**; both are marked on the
front silkscreen. J6 is wired directly in parallel with J2 and adds no height
before soldering. The ground pad uses **0.25 mm thermal clearance and 0.4 mm
copper spokes** to make hand soldering easier. Use either J2 or J6 for **one protected 1S battery**, not two
batteries simultaneously. Secure the cable in the enclosure so pulling it does
not load the solder joints. The charge circuit and its 100 mA setting are unchanged.

J6 is etched PCB copper, excluded from the purchasing BOM and placement files.
No assembly-house component is needed. Its pad centres are **(56.1, 96.0) mm
for BAT+** and **(52.7, 96.0) mm for GND**, in native PCB coordinates.

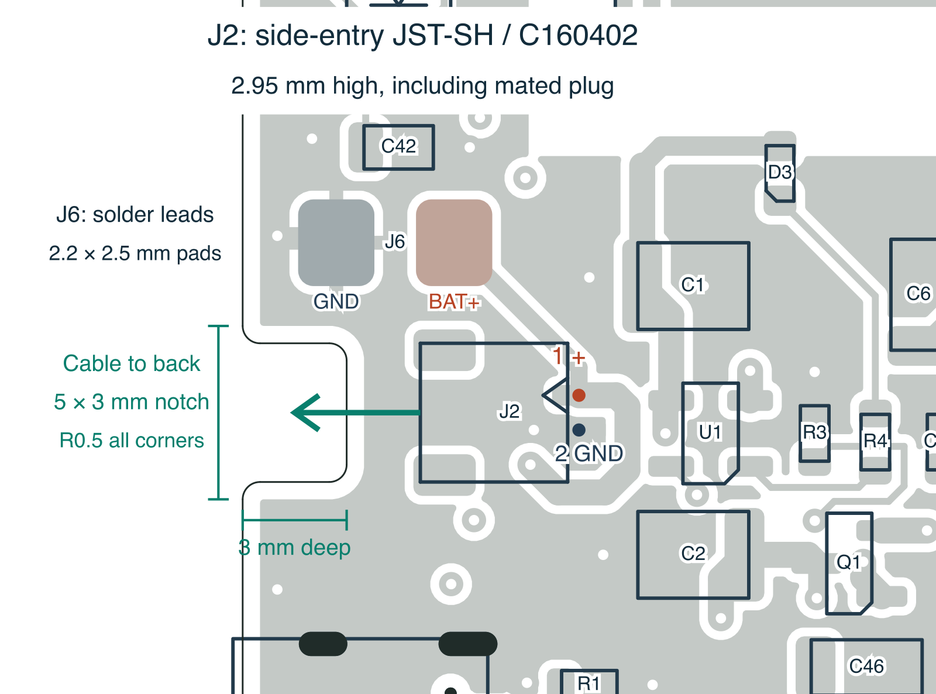
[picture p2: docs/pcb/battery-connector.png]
Socket, cable direction and pad polarity


## Selection and availability

[JST's SH drawing](https://www.jst-mfg.com/product/pdf/eng/eSH.pdf), pages 1
and 3, gives the side-entry land pattern and body dimensions. The assembled
height is 2.95 mm, including the 0.05 mm stand-off beneath the 2.90 mm body.
This is 2.55 mm lower than the previously selected 5.5 mm PH side-entry part
and meets the requested approximately 4 mm maximum. It has a 4.0 mm-wide
housing, two signal lands and two soldered hold-down tabs.

SH is available on some small flat single-cell packs, but ready-made retail
options are narrower than for JST-PH. For example,
[LiPol's protected LP572528 400 mAh / 3.7 V pack](https://www.lipobattery.us/lp572528-400mah-3-7v-1-48wh-lipo-battery-with-pcm-and-cables-50mm-and-jst-shr-02v-s-b/)
is offered with the exact SHR-02V-S-B housing. This demonstrates availability
of the connector family on the target battery format; it does not qualify that
pack's discharge rating or select it for this board. Specify the housing,
28 AWG leads, and pin-1-positive wiring when purchasing the final protected pack.

[JLCPCB C160402](https://jlcpcb.com/partdetail/JST-SM02B_SRSS_TB_LF_SN/C160402)
is an extended-library SMT part available for Economic and Standard assembly.
The fresh public API observation on **2026-10-07** reported **29,259 in stock,
27,621 available to order**, and **USD 0.1319** initial unit price before assembly
charges. Inventory is not reserved. The stock snapshot retains exact MPN,
package, query, retrieval timestamp and response hash; other BOM observations
retain their own dates. Signed media URLs are excluded.

JST rates SH at **1 A with 28 AWG wire**. The user explicitly accepted possible
intermittent excursions above 1 A for this prototype and requested **no new
current limit or operating restriction**. That assumption is recorded, not
promoted to a manufacturer pulse-current rating or a measured thermal result.
The existing **100 mA charge setting** and power circuit remain unchanged.
Battery performance, pack protection/discharge capability and actual peak
waveforms still belong to the existing prototype validation work.

| Compared option | Mated height | Selection consequence |
| --- | --- | --- |
| JST SH SM02B-SRSS-TB / C160402 | 2.95 mm | Retained: side entry, limited ready-made battery selection; J6 also accepts direct leads |
| JST PH S2B-PH-SM4-TB / C295747 | 5.5 mm | Preserved old plug but exceeds the new height target |
| Molex PicoBlade 532610271 / C177225 | 3.4 mm | Common battery lead; formal specification is also 1 A, despite higher reference derating values |
| Hirose DF13A-2P-1.25H(21) / C530976 | 3.6 mm | 2 A specification with two positions and 28 AWG; less common lead for the target packs |

Comparison sources: [JST PH](https://www.jst-mfg.com/product/pdf/eng/ePH.pdf),
[Molex dimensions](https://www.molex.com/en-us/products/series-chart/53261),
[Molex current specification](https://www.molex.com/content/dam/molex/molex-dot-com/products/automated/en-us/productspecificationpdf/510/51021/510211124-PS-000.pdf),
[Hirose specifications](https://www.hirose.com/en/product/p/CL0536-0301-8-21).

## Footprint and placement

The project-local footprint is copied from the installed KiCad library:
`JST_SH_SM02B-SRSS-TB_1x02-1MP_P1.00mm_Horizontal`. The JST top-view land drawing
confirms circuit numbering and these nominal dimensions:

| Land | Local centre, mm | Size, mm | Connection |
| --- | --- | --- | --- |
| 1 | −0.50, −2.00 | 0.60 × 1.55 | VBAT positive |
| 2 | +0.50, −2.00 | 0.60 × 1.55 | GND |
| MP | −1.80, +1.875 | 1.20 × 1.80 | Unconnected hold-down |
| MP | +1.80, +1.875 | 1.20 × 1.80 | Unconnected hold-down |

All four pads have mask and paste openings, with no drilled holes. The
standard KiCad SH STEP model is assigned and resolves in the checked
installation. Library and board lands, body, courtyard and model agree.
KiCad assets retain the library license with design exception.

J2 is locked at **(57.70, 100.90) mm, −90°**, moved **4.00 mm inward** from
its previous X = 53.70 mm position. The mating face is at **X = 55.125 mm**.
The full courtyard remains on the board, and the approach corridor contains
no other component courtyard.

A cable notch is centred opposite J2 at **Y = 100.90 mm**. It opens from the
left edge at **X = 50 mm**, extends **3.00 mm inward to X = 53 mm**, and spans
**5.00 mm overall from Y = 98.40 to 103.40 mm**. All four transitions use
**0.50 mm radii**, including the outer shoulders and inner corners. The parallel
channel walls are 4.00 mm apart after the rounded shoulders. The mating face
is **2.125 mm behind the deepest notch edge**, leaving room for leads to turn
through the notch toward the back without going beyond the board's original
60 × 110 mm envelope. Actual plug length, wire bend radius and enclosure fit
still need a physical check; this drawing does not model a particular cable.

Only J2 changes component position. Its reference label shifts within the body
to clear an exposed via. Local VBAT/GND connections and the SCL via escape are
rerouted; one GND, one VBAT and one SCL via move. J6 and every other footprint,
all mounting holes, the display, antenna and remaining outline primitives are
preserved. The geometry amendment is recorded in
[battery-notch-amendments.json](pcb/battery-notch-amendments.json).
This footprint is **not compatible with an already fabricated Rev A board**.
The original Rev A files specified vertical B2B-PH-SM4-TB / C160352, so the
received upright part is consistent with those records; they do not establish
a manufacturer substitution.

## Assembly and verification

**Do not substitute a PH, ZH, or top-entry SH header.** Confirm exact C160402,
left-facing opening and pad alignment in the supplier preview. With export
origin (50,160) and Y upward:

| Feature | X, mm | Y, mm | Rotation |
| --- | --- | --- | --- |
| J2 footprint anchor | 7.700 | 59.100 | 270° |
| Pin 1, VBAT positive | 9.700 | 59.600 | — |
| Pin 2, GND | 9.700 | 58.600 | — |
| J6 pin 1, BAT+ wire pad | 6.100 | 64.000 | — |
| J6 pin 2, GND wire pad | 2.700 | 64.000 | — |

CPL coordinates preserve the KiCad anchor without assumed centre offsets.
Use the pad-coordinate CSV and enlarged placement-reference drawing for an
independent preview check. **production-2026-10-08 includes this connector move
and notch.** Earlier packages, including mounting-2026-10-08, retain the old
outline and J2 coordinates and must not be used for the current order.

The [connector audit](assembly/battery-connector-check.json) checks exact part,
land dimensions, polarity, orientation, model, paste and plug approach.
The audit also checks notch dimensions, all four corner radii and removed
material. DRC with copper refill has zero errors, zero unconnected items and
zero schematic-parity findings. There are 33 reviewed cosmetic warnings.
The current production Gerber readback checks the notch, all connector lands,
and all 119 placement anchors. The routing regression preserves only identical
rev-A NFC findings. The October USB/display redesigns still require testing
on revised hardware.

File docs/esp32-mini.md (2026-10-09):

# ESP32-C3-MINI-1 compatibility and antenna fit

The current design uses **ESP32-C3-MINI-1-H4X, JLCPCB C41349510** in place of
WROOM-02-N4. Electrical interfaces are compatible after changing the physical
pad numbers and PCB routing. This is a new PCB revision: the modules are not
interchangeable on the old footprint.

The 4 MB H4X part is recommended by Espressif and was available in JLCPCB's
public catalog on 8 October 2026 (829 available to order at that observation;
inventory is not reserved). The older MINI-1-N4 is NRND. H4X has a higher ambient
temperature rating than the former N4 module; this does not raise the assembled
board's temperature rating. The catalog search did not expose the H4X assembly
process field, so automated assembly still requires the supplier's placement
preview and quotation. The prototype supports the established manual reflow process.

The module body changes from 18 × 20 × 3.2 mm to **13.2 × 16.6 × 2.4 mm**:
39.1% less module area and 0.8 mm less module height. The full PCB remains
60 × 110 mm, including its detachable keyboard. Other components still set the
overall assembly height.

## Electrical compatibility

The 3.0–3.6 V supply range, 500 mA external supply requirement, boot straps,
native USB Serial/JTAG, ADC1 battery measurement, shared 100 kHz I²C bus, Wi-Fi
and BLE functions are retained. The regulator, EN supervisor and RC timing,
VBUS-controlled USB isolation, display circuitry, NFC circuit and keyboard are
unchanged. There is no GPIO reassignment in firmware.

| Function | GPIO | Old WROOM pad | MINI pad |
|---|---:|---:|---:|
| 3.3 V | — | 1 | 3 |
| EN/reset | — | 2 | 8 |
| I²C SDA | 4 | 3 | 18 |
| I²C SCL | 5 | 4 | 19 |
| NFC IRQ | 6 | 5 | 20 |
| NFC VEN | 7 | 6 | 21 |
| GPIO8 strap | 8 | 7 | 22 |
| BOOT | 9 | 8 | 23 |
| OLED reset control | 10 | 10 | 16 |
| Keyboard interrupt | 20 | 11 | 30 |
| Reserved, NC | 21 | 12 | 31 |
| USB D− | 18 | 13 | 26 |
| USB D+ | 19 | 14 | 27 |
| OLED power control | 3 | 15 | 6 |
| GPIO2 strap | 2 | 16 | 5 |
| USB present, inverted | 1 | 17 | 13 |
| Battery ADC | 0 | 18 | 12 |

MINI ground pins 1, 2, 11, 14 and 36–53 all connect to GND. Factory NC pads
4, 7, 9, 10, 15, 17, 24, 25, 28, 29 and 32–35 remain isolated. The optional
centre joint, pad 49, is masked without paste or thermal holes; Espressif
permits omitting that solder joint. All perimeter pads have mask and paste.

R12/R13 retain 22 Ω and move beside the module. Both resistor-to-module USB
routes are 1.800685 mm, on F.Cu without vias. The independent routing audit
checks every trace for full entries, centreline joins, 45-degree geometry and
short/duplicate/acute segments. Earlier connector-to-switch USB skew and two
reference-plane sampling gaps remain documented layout advisories; this change
does not qualify USB signal integrity or arbitrary host operation.

## Firmware

H4X contains ESP32-C3 chip revision **1.1**. The user confirmed **ESP-IDF 5.4 or
newer**, which meets the chip revision's framework compatibility requirements.
Firmware is not present in this repository, so existing binaries have not been
built or boot-tested here. Espressif also lists support
from 4.3.7, 4.4.7, 5.0.5, 5.1.3 and 5.2, depending on release branch; non-UART0
primary consoles need the additional fixes in 5.0.8, 5.1.6, 5.2.4 or 5.3.2.
For Arduino or another framework, check its bundled ESP-IDF version. Keep the
4 MB flash configuration and GPIO assignments. Test ROM download, boot/reset,
USB reconnect, Wi-Fi/BLE and peripherals on the first revised board.

## Flush antenna and cutout

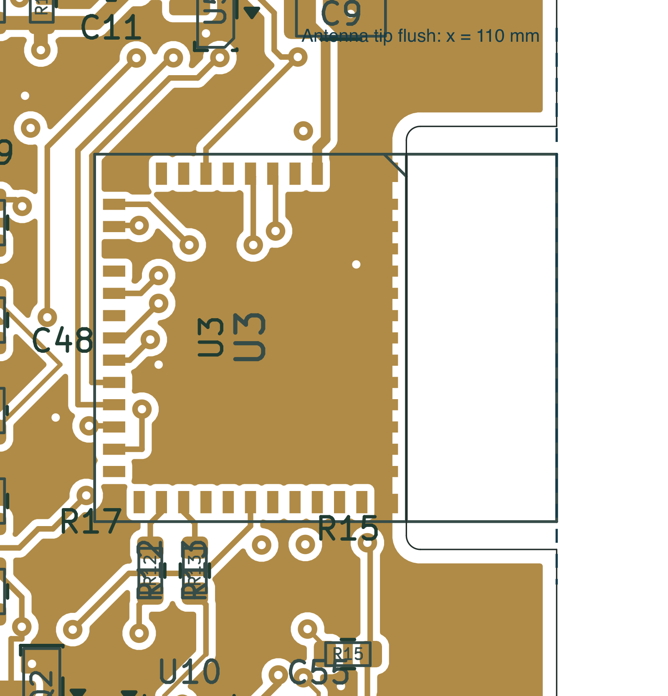
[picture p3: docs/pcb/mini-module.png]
MINI module and flush antenna cutout


U3 is locked at **(101.70, 106.14) mm, −90°**. Its physical antenna tip is at
**x = 110.00 mm**, exactly aligned with the PCB's right outer edge in nominal
CAD geometry. The antenna area is x = 104.60–110.00 mm,
y = 99.54–112.74 mm. No baseboard material or copper remains beneath it.

The notch is x = 104.60–110.00 mm, y = 98.54–113.74 mm, with **1.00 mm clearance
on either side of the antenna** and **0.50 mm internal corner radii**. It opens
to the right edge. Module and board tolerances mean an assembled unit may not
be perfectly flush; the design adds no intentional overhang.

The manufacturer's antenna-side ground lands end at x = 104.30 mm, leaving
**0.30 mm copper-to-cutout clearance**. A custom DRC rule requires at least
0.25 mm for U3 ground lands only. Other copper retains the existing 0.50 mm
edge rule. This dimension and the milled notch must be accepted by supplier CAM.
The OLED ribbon access and keyboard breakaway remain. The current production
release restores the rev-A NFC layout and requires filled/capped vias and the
rev-A stackup; see the production instructions. The antenna keepout prohibits pads, tracks, vias and pours
on all four copper layers. Ground stitching sits on the module side of the cutout.

Espressif recommends this open notch arrangement when the antenna cannot
project past the outer edge. Final enclosure clearance, antenna range and RF
performance still need measurement; CAD clearance is not RF qualification.

## Validation and source records

Current checks: zero schematic ERC violations; zero native DRC errors,
unconnected items or schematic-parity findings; 43 cosmetic DRC warnings;
17 MINI compatibility/fit checks, 16 fabrication checks and all six independent
routing-quality checks pass. USB backfeed, display mapping and battery checks
remain applicable. The required 261 scoped ngspice cases were rerun against
the updated design with no solver errors. Component values and peripheral
topology are unchanged; these models do not simulate the new layout's parasitics,
complete ICs or MCU firmware.

All 32 independent export checks pass for the current mounting package, covering Gerber
copper, solder mask, stencil apertures, drill data, placement data and the
resized board outline.

- [MINI pin/fit verification](pcb/mini-module-check.json)
- [Native DRC](pcb/drc.json) and [routing quality](pcb/routing-quality.json)
- [Footprint amendments](pcb/mini-footprint-amendments.json) and [outline amendment](pcb/mini-outline-amendment.json)
- [Espressif MINI-1 datasheet v2.2](https://documentation.espressif.com/esp32-c3-mini-1_datasheet_en.pdf), tables 1-1, 3-1, 6-2 and figures 10-1, 11-1
- [Espressif module placement guidance](https://docs.espressif.com/projects/esp-hardware-design-guidelines/en/latest/esp32c3/pcb-layout-design.html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)
- [Espressif chip/SDK compatibility](https://github.com/espressif/esp-idf/blob/master/COMPATIBILITY.md#esp32-c3)
- [Espressif source footprint and model](https://github.com/espressif/kicad-libraries), licensed as recorded in [library notes](../libraries/README.md)
- [Exact selected JLCPCB part](https://jlcpcb.com/partdetail/Espressif-ESP32_C3_MINI_1H4X/C41349510)

Run `tools/check_mini_module.py` with KiCad's Python after schematic export and
native DRC with zone refill. Use the **production-2026-10-08** manufacturing package;
the previous MINI and WROOM packages remain historical records.

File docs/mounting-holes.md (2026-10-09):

# Six M2 mounting holes

The current PCB has **six 2.2 mm non-plated clearance holes**: H1–H4 at the
four corners of the main board and H5/H6 at the lower two corners of the
detachable keyboard. These are through holes for M2 screws, without threads,
countersinks, copper annuli or stencil paste. Screws and standoffs are supplied
separately; select screw length for the actual enclosure and mounting stack.

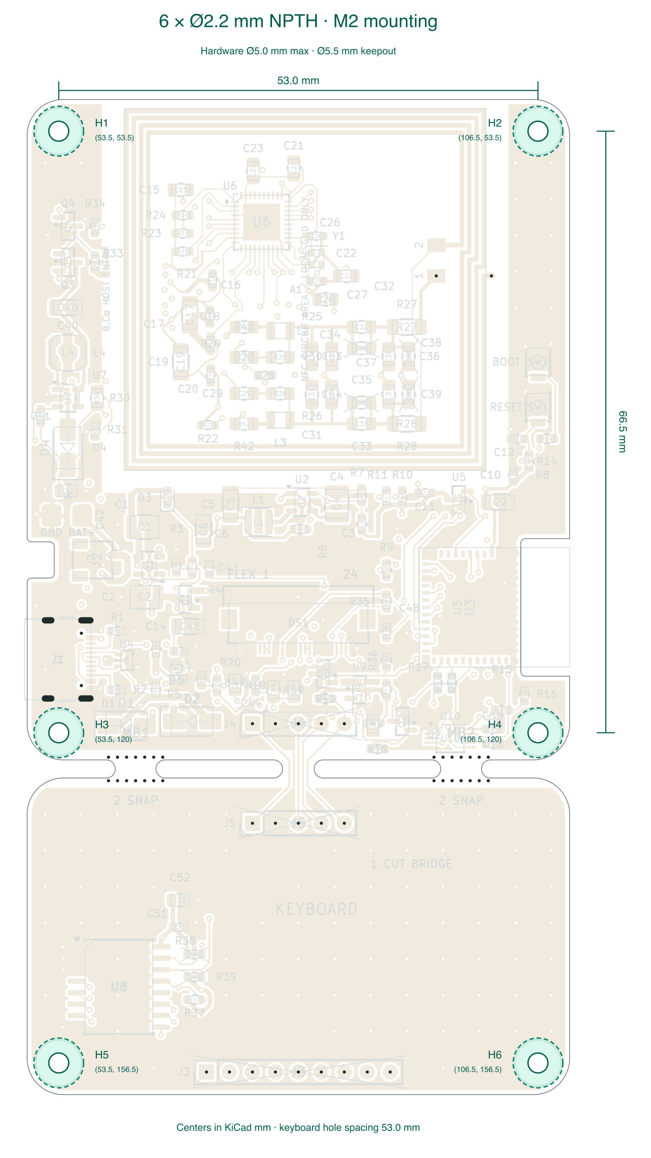
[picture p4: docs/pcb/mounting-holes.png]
Mounting-hole positions and dimensions


Coordinates are in KiCad millimetres, viewed from the top, with Y increasing
down the drawing. The outer board spans X = 50–110 and Y = 50–160 mm.

| Hole | Location | KiCad X | KiCad Y | X from left edge | Y from top edge |
|---|---|---:|---:|---:|---:|
| H1 | Main upper left | 53.5 | 53.5 | 3.5 | 3.5 |
| H2 | Main upper right | 106.5 | 53.5 | 56.5 | 3.5 |
| H3 | Main lower left | 53.5 | 120.0 | 3.5 | 70.0 |
| H4 | Main lower right | 106.5 | 120.0 | 56.5 | 70.0 |
| H5 | Keyboard lower left | 53.5 | 156.5 | 3.5 | 106.5 |
| H6 | Keyboard lower right | 106.5 | 156.5 | 56.5 | 106.5 |

The main-board mounting rectangle is **53.0 × 66.5 mm**. The lower keyboard
holes are **53.0 mm apart**. Main lower holes sit 3.0 mm above the Y = 123 mm
separation edge; their vertical position clears the existing USB connector.
All six positions are locked. The 60 × 110 mm envelope, corner radii, antenna
notch, routed breakaway slots and mouse bites retain their previous geometry.

Each hole reserves a **5.5 mm diameter copper and component clearance** on
both faces and all four copper layers. Use screw heads, washers and standoffs
no larger than **5.0 mm across** at the PCB; this allows 0.25 mm radial margin.
Standard M2 washers are nominally 2.2 mm inside / 5 mm outside, as listed by
[Bossard](https://nederland.bossard.com/en-us/standard-fastening-elements/washers/washers-flat-without-chamfer/125a00200020000).
The entire seating area fits within the rounded outline. Enclosure fit,
tightening torque, mechanical strength and RF behaviour with actual hardware
remain physical checks; the circuit model does not model nearby metal.

## Local changes

R16 (470 kΩ, battery ADC divider) moves from **(104.00, 120.00)** to
**(105.00, 115.75)** mm, retaining its 90° rotation, value and pin connections.
Its short ADC connection and the nearby branch to C13 are rerouted. Eleven
ground-stitching vias inside the mounting clearances are removed. All other
component placements, the USB routes, GPIO assignments, the NFC winding and
the five functional keyboard bridge traces are preserved.

H1–H6 are board-only mechanical footprints, excluded from BOM, placement and
stencil data. The assembly still contains 119 populated parts. The separate
NPTH drill file now has **36 holes**: six 2.2 mm mounts, two 0.65 mm USB
locators and 28 0.60 mm mouse bites.

## Validation

- Native KiCad ERC: zero violations. DRC with zone refill, all-track errors
  and schematic parity: zero errors, zero unconnected items and zero parity
  findings; the same 43 cosmetic warnings remain.
- Ten independent mounting checks verify the hole count, positions, drill
  type/size, hardware area, pad/component clearance and copper on every layer.
- Existing layout, MINI, battery, display, USB, fabrication and all six
  routing-quality checks pass. The existing USB skew/reference-plane advisory
  findings remain; this mechanical change does not qualify USB performance.
- The 261 scoped simulation cases were rerun against the revised board, with
  no solver errors. Electrical component values and topology are unchanged.
- The manufacturing export is checked independently for drill sizes and
  positions, preserved mouse bites/USB slots, and exclusion of H1–H6 from
  assembly and stencil data.

[Mounting checks](pcb/mounting-holes-check.json) ·
[Footprint amendment record](pcb/mounting-footprint-amendments.json) ·
[Native DRC](pcb/drc.json) · [Routing audit](pcb/routing-quality.json)

Use the **production-2026-10-08** manufacturing package. The earlier MINI and
battery/connector packages remain unchanged historical records.

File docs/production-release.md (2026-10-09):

# Production package — 8 October 2026

Release `production-2026-10-08` is prepared for **five engineering prototypes**
from the current design, including the battery cable notch and latest artwork.
Use only files from this package together. Earlier October packages contain
changed NFC layouts and are superseded for this order.

## Files to send

| Purpose | File |
|---|---|
| PCB fabrication | `nucula-v2-gerbers.zip` |
| Assembly BOM | `assembly/jlcpcb-bom.csv` |
| Placement | `assembly/jlcpcb-cpl.csv` |
| Assembly drawing | `drawings/assembly-top.pdf` |
| Enlarged anchor and pad-number reference | `drawings/placement-reference.pdf` |
| Independent placement evidence | `assembly/placement-audit.csv`, `assembly/pad-coordinates.csv` |
| Fabrication outline and layers | `drawings/fabrication-outline.pdf`, `drawings/layers.pdf` |
| Editable source and libraries | `nucula-v2-design-snapshot.zip` |
| Integrity and validation | `manifest.json`, `validation/` |

The BOM and CPL describe **119 fitted components per board, all on top**.
Order five assemblies with the single-board files. A1, J6, H1–H6, mouse bites,
and DNP components are excluded. The display panel, battery, mounting hardware
and optional keyboard headers are not purchased by this BOM. Inventory is a
dated observation, not reserved stock; exact-part availability is settled by
the supplier's BOM matching. U3 assembly service eligibility needs supplier confirmation.

## Mandatory fabrication instructions

| Setting | Required value |
|---|---|
| Board | Four-layer FR-4, 60 × 110 mm envelope, nominal 1.6 mm |
| Stackup | **JLC04161H-3313, as submitted for rev A**; retain the Gerber job material stack |
| Copper | 1 oz outer, 0.5 oz inner |
| Finish / mask / legend | ENIG / **black** / white, matching rev A |
| Via treatment | **Epoxy filled and copper capped** for all 0.20 / 0.30 / 0.40 mm plated round holes; preserve supplied mask openings |
| Smallest via | 0.20 mm hole / 0.45 mm land; restored NFC via-in-pad requires filling/capping |
| USB mounting slots | Four plated routed slots, 0.70 mm wide |
| Mounting holes | Six 2.2 mm NPTH, M2 clearance; no plating or countersink |
| Stencil | 100 µm, top only, using supplied F.Paste |
| Test | Electrical test required |
| Delivery | Keyboard remains attached; supplier may add assembly rails/fiducials outside finished outline |

**Do not use the earlier ordinary/open-via or generic-stackup instructions.**
Do not substitute ink plugging for filled/capped via-in-pad. Do not resize,
retune or reroute the NFC antenna, matching tree, controller, crystal or local
vias. No copper thieving, test pads, order markings or supplier-added metal
inside or beside the antenna. Preserve all four-layer NFC copper exclusions.
The supplied board has no blanket controlled-impedance certification. Any
supplier USB impedance proposal must avoid changing the frozen NFC geometry.

JLCPCB's [via-covering instructions](https://jlcpcb.com/help/article/pcb-via-covering)
distinguish filled/capped processing from ink plugging. This package preserves
the recorded rev-A manufacturing specification; actual supplier CAM changes
on the previous physical boards are not available in the repository.

## Placement instructions — prevent the previous offset error

CPL X/Y use **native KiCad footprint anchors**, relative to (50,160) mm with
positive Y upward. Rotations are native KiCad angles normalized to 0–360°.
There are **no body-center offsets or unverified angle corrections**.
Every CPL row is independently compared with the source PCB; pad coordinates
are independently compared with exported copper. Do not apply the earlier
ESP32 +3.10 mm X, display +1.90 mm Y, or battery −1.75 mm X shifts.

Before the supplier releases its assembly job, check its **2D lead-to-pad
alignment** for all parts, especially U3, DS1, J2, U6, U4 and U10. Align actual
pin numbers, not a 3D body center. Supplier catalogue model anchors cannot be
certified from local files; use the supplied audit and pad table to resolve
any supplier-specific discrepancy.

- **U3:** ESP32-C3-MINI-1-H4X, **C41349510**. WROOM-02 is incompatible. Antenna points
  right and is flush with the cutout. Pad 49 is masked with no paste; perimeter
  ground pads are soldered. Use compatible ESP32-C3 revision-1.1 firmware.
- **DS1:** FH12A-24S-0.5SH(55), **C506794**, top-contact socket. The corrected mounted
  panel relationship is panel pin n = socket pad 25−n. Do not renumber or rotate
  the footprint to “correct” this intended reversal.
- **J2:** JST SM02B-SRSS-TB(LF)(SN), **C160402**, side entry, 1 mm pitch. Opening faces
  left, toward the cable notch. CPL X=7.700 mm, Y=59.100 mm, rotation=270°.
  Positive pad 1 is (9.700,59.600); ground pad 2 is (9.700,58.600) mm.
  SHR-02V-S-B mating lead; the old PH plug does not fit. Verify lead polarity.
- **J6:** hand-solder battery lands only. Left pad is GND; right pad is BAT+.
  No component or stencil paste. Use J2 or J6 for one battery connection.

## Validation and scope

Native ERC: zero violations. Native PCB DRC: zero errors, zero unconnected
items, zero schematic-parity findings. The 33 warnings are 32 reviewed library
footprint differences and one clipped R17 silkscreen reference. Export subtracts
solder mask from silkscreen. These warnings do not alter placement coordinates.

The NFC schematic is byte-identical to submitted rev A. All **43 local NFC
footprints and 366 tracks/vias** match its geometry, position, values and nets;
the submitted stackup and via process are restored. Independent Gerber readback
confirms the NFC area matches rev A on all four copper layers and both mask layers. User reports rev-A NFC
worked without tuning. No matching values were changed. The seven power/digital
feeders are identical through their entry into the NFC area; their remote
routing connects to the revised board. Mounting holes and circuitry elsewhere
differ, so this is not a claim of complete electromagnetic equivalence.

The strict routing report retains rev-A NFC findings (seven non-45° tracks,
12 shallow endpoints, five weak-connectivity groups, one duplicate and 22 short
segments) because changing them would violate the requested proven-layout
freeze. Each retained finding is reproduced on identical baseline copper;
**no new routing findings are accepted**. Both raw and regression reports are
included. Native clearance/connectivity DRC passes without excluding these items.

**261 preflight SPICE cases and 57 USB-backfeed cases completed without solver
errors**, with current input hashes, circuit decks and logs included. The
independent full/half-circuit NFC numerical comparison and 12 native antenna
keepout fixtures also pass. These cover
passive NFC sensitivity, I²C, reset/ADC RC timing, ideal converter DC setpoints
and modeled USB isolation/backfeed. They are not a full assembled-board
simulation, switching-converter stability analysis, USB compliance test or
full-board RF field simulation.

Use I²C at 100 kHz within the 400 pF modeled budget; allow 200 ms initial battery
ADC settling. The modeled 600 pF bus deliberately exceeds the rise-time limit.
USB copper lengths are D− 63.5329 mm / D+ 53.1877 mm; two of 2,097 sampled
reference-plane points are uncovered. These remain documented advisories; revised
USB enumeration/reconnection, ESD, display operation and power transients need
physical bring-up. Use the established dedicated 5 V / at least 1.5 A supply.
NFC production repeatability should be checked on assembled boards using the
same tag/setup as rev A; this is not an instruction to retune the matching tree.

The package is ready for supplier upload and CAM/assembly review. No order has
been placed and no supplier preview approval is claimed. Bench qualification
of the changed hardware remains distinct from production-file readiness.

## Reproduce this release

Use KiCad 10's pcbnew-enabled Python for the native board checks and exporter,
and a Python environment with `tools/nfc/requirements.txt` plus Gerbonara 1.5.0
for numerical and Gerber checks. Run the schematic check before simulations;
refill the board, then run native DRC with schematic parity before geometry checks.
Run `check_nfc_rev_a.py`, `check_pcb_layout.py --drc docs/pcb/drc.json`,
`check_mini_module.py`, `check_mounting_holes.py`, `check_battery_connector.py`,
`check_standard_fabrication.py`, `export_routing_geometry.py`, then
`check_release_routing.py`. Repeat the display/USB/component/assembly checks and
both simulation scripts. `check_nfc_gerbers.py` additionally reads the historical
submitted rev-A Gerbers from the repository.

Set `VALIDATION_PYTHON` to the numerical environment's Python when running
`tools/export_standard_fabrication.py` with KiCad Python. The exporter refuses
stale evidence, runs independent Gerber/NFC/placement readback, hashes every
file and creates both ZIPs. Finish with
`python tools/verify_production_package.py manufacturing/production-2026-10-08`.
Existing packages are not overwritten; choose a new release identifier for
subsequent exports. Archived regression-only checks for superseded display/USB
revisions are not current-release acceptance tests.

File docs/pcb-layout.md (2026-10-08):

# PCB placement and routing

Current MCU revision (8 October 2026): **ESP32-C3-MINI-1-H4X / C41349510**.
The antenna is flush with the right PCB edge; the smaller milled notch includes
1 mm side clearance and 0.5 mm internal corner radii. GPIO functions and the
display/USB/battery corrections remain. [Compatibility and verification](esp32-mini.md).
The **mounting-2026-10-08** archive includes six M2 mounting holes but predates
the latest battery cable notch and 4 mm inward move of J2. Regenerate manufacturing
files from the editable PCB before ordering this newer geometry.
The earlier MINI package has no mounting holes; older packages use WROOM-02.

**8 October update:** [J2 is now side-entry JST-SH C160402](battery-connector.md),
2.95 mm high when mated with its opening toward the left edge. The display pin mapping and local routing are corrected
at the unchanged socket orientation. The [USB backfeed redesign](bringup/usb-backfeed-fix.md)
is also routed. With the MINI module and [six M2 mounting holes](mounting-holes.md),
the board has 138 footprints, 119 populated parts, 1,157 trace segments and
318 routing vias. Current JSON reports and drawings reflect these changes;
the September narrative below is historical. USB signal-integrity advisories
are recorded in the current report.

22 September 2026 · KiCad 10.0.6 · routing-review revision

All 130 footprints are on top, with 116 populated purchased components and all
91 nets connected. Nineteen parts have been rearranged for ordinary 0.30/0.70 mm
vias and the **17.70 × 5.00 mm display-ribbon access area**. DS1 remains at
(80.00, 108.85) mm, rotated 180°. Its insertion area is enforced by a front
component keepout and independently checked against every component courtyard.
[Changes, dimensions and checks](standard-fabrication.md). The subsequent
[routing repair](routing-review.md) preserves every footprint's placement.

[Top view](pcb/top.svg) · [Ribbon clearance](pcb/display-clearance.svg) ·
[NFC detail](pcb/nfc.svg) · [All copper layers](pcb/copper-layers.svg) ·
[Layer PDF](../manufacturing/routing-review-2026-09-22/drawings/layers.pdf) ·
[Native DRC](pcb/drc.json) · [Layout checks](pcb/layout-check.json)

Current PCB, top copper and component outlines

J6 adds two labeled 2.2 × 2.5 mm hand-solder pads above J2, connected in parallel
to BAT+ and GND. It is excluded from the assembly BOM/CPL and stencil paste.
J2 now sits 4 mm farther inward, opposite a 5 × 3 mm cable notch with R0.5
inner corners and outer shoulders. The board envelope and other component
positions remain unchanged. [Dimensions and current validation](battery-connector.md).

## Preserved geometry

The board outline, 40 mm coil copper and antenna rule areas remain unchanged.
All 42 NFC support/controller footprints remain inside the coil's open courtyard;
other circuitry remains outside. U6 and its decoupling move upward, while the
eleven matching-component pairs and their mirrored matching-tree copper are
preserved. The original antenna feed corridor and five 0.20 mm functional
keyboard breakaway crossings are retained. The fracture band has no vias or
pours. Fixed connector positions and component values/nets are unchanged.

The all-layer pour exclusion remains x = 58.25–103.25 mm, y = 48.5–93.5 mm.
No pour occurs inside or beneath the winding. NFC ground connections use traces
and vias. Antenna tuning and complete populated-board performance require
measurements; matching-tree symmetry alone does not establish RF performance.

## Manufacturing and routing

The revised board has **1,021 trace segments and 312 routing vias**. Every trace
follows the 45-degree convention. Pad/via entries and centreline joins pass the
independent geometry audit, with no edge-only connections, acute return bends,
duplicate traces or exposed segments shorter than 0.20 mm. The audit permits
short segments buried inside lands. [Before/after evidence](routing-review.md).
All routing vias are ordinary through-vias with 0.30 mm holes and 0.70 mm lands,
separated from solderable SMT lands by at least 0.10 mm mask-opening separation.
The optional ESP32 centre joint/thermal holes are omitted. The PN7160 centre
pad remains soldered without via holes in its wettable land.

Routing retains the 0.15 mm minimum track and 0.20 mm net clearance. General
NPTH clearance is 0.25 mm; J1 no longer needs a footprint-specific exception.
Its USB shell slots are widened to 0.70 mm with 0.30 mm minimum rings. See the
[standard-fabrication report](standard-fabrication.md) for adapted USB lands,
fit limitations and the complete fabrication settings.

The USB D−/D+ traces between U4 and R12/R13 are 41.3053 mm and 42.2968 mm long
(0.9915 mm skew). The reference-plane sampling has two uncovered points out of
2,171. The 0.5 mm skew advisory and complete reference-coverage advisory are
unmet. Both are reported as **advisory**, following
the request to focus on manufacturing compatibility. There is no controlled
impedance order or custom stackup; USB signal integrity has not been qualified.

## Validation

- Native KiCad DRC with zone refill, all-track checks and schematic parity:
  **0 errors, 0 unconnected items, 0 parity findings**.
- Schematic ERC and independent pin/net checks: **0 violations**.
- **21 layout checks and 16 standard-fabrication checks pass**, including
  keepout enforcement, via-to-pad separation, preserved geometry and no dangling copper.
- **Six routing-quality checks pass** across all four copper layers; five
  regression tests exercise the audit's handling of good and marginal joins.
- **40 cosmetic warnings** remain: 37 deliberate front-legend/library differences,
  two existing ESP32 legend/edge warnings and one preserved back-artwork overlap
  clipped against mask during Gerber export. A separate footprint hash audit
  confirms that legend editing changed no other geometry.
- Component choices and the five-board assembly audit pass. **261 partial circuit
  simulations** complete without solver errors; their limitations and findings
  are in the [simulation report](simulation/README.md).

References that cannot print legibly beside the open vias remain in the
[assembly drawing](../manufacturing/routing-review-2026-09-22/drawings/assembly-top.pdf).
The original rear artwork and locally added U6 3D-model reference are preserved.

## Reproduce

Run from the project directory. The PCB tools require KiCad's `pcbnew` Python;
the routing-quality checker requires Shapely 2. SPICE additionally requires
numpy/matplotlib and a shared ngspice library. Use a suitable Python environment
for each tool; the geometry JSON connects the KiCad and Shapely environments.

```sh
kicad-cli pcb drc --refill-zones --save-board --schematic-parity \
  --all-track-errors --severity-all --format json -o docs/pcb/drc.json nucula-v2.kicad_pcb
python3 tools/check_pcb_layout.py --drc docs/pcb/drc.json
python3 tools/check_standard_fabrication.py
python3 tools/export_routing_geometry.py
python3 tools/check_routing_quality.py
python3 tools/test_routing_quality.py
python3 tools/check_schematic.py
python3 tools/check_display_mapping.py
python3 tools/test_display_mapping.py
python3 tools/check_component_choices.py
python3 tools/check_assembly_readiness.py --boards 5
python3 tools/simulate_preflight.py
python3 tools/analyze_usb_backfeed.py
python3 tools/render_pcb_review.py
python3 tools/export_standard_fabrication.py --out /tmp/nucula-validation-export
```

The [constraints](pcb/constraints.json) retain the original geometric baseline
with the explicitly documented placement/land-pattern amendments. The isolated
older OLED and USB regression scripts remain historical records; this broader
revision uses the current layout and fabrication audits.
The export directory must be fresh; archived packages are never overwritten.
USB backfeed analysis is a diagnostic screen, not a verified hardware fix.

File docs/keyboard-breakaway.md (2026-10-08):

# Detachable 35 mm keyboard section

The board remains 60 × 110 mm, from X = 50–110 and Y = 50–160 mm.
The keyboard body occupies Y = 125–160 mm: **60 × 35 mm**. A 2 mm routed
gap at Y = 123–125 mm separates it from the main body, which is 73 mm high.
Small tab remnants remain after separation and may need trimming.
The four corners at the left and right ends of the gap have a 4 mm radius,
matching the board's outer corners.

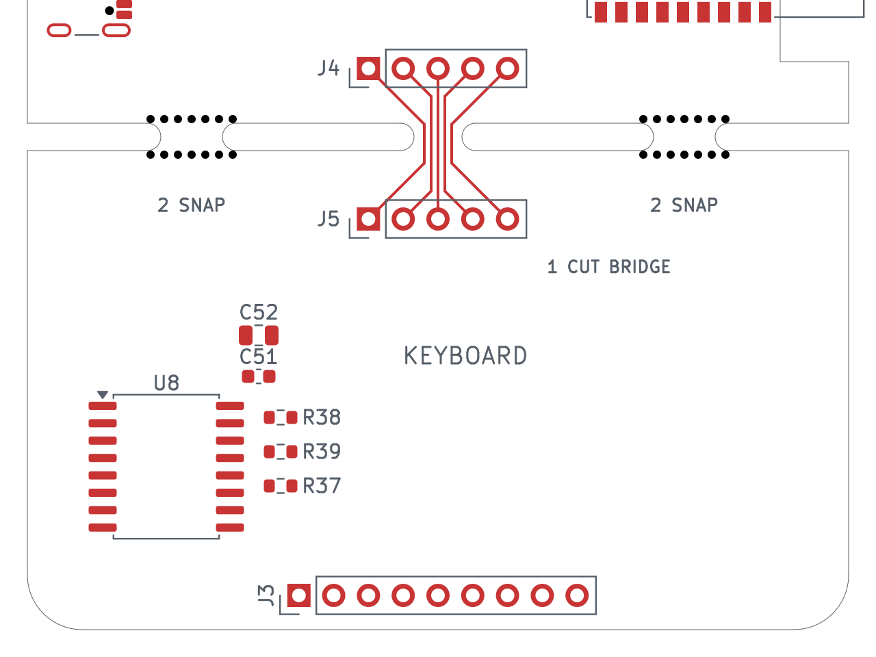
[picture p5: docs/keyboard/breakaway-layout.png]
Saved PCB layout around the breakaway


The lower two keyboard corners now have **2.2 mm NPTH M2 clearance holes**,
H5/H6 at (53.5, 156.5) and (106.5, 156.5) mm. The main board has four more.
[Mounting plan and hardware limits](mounting-holes.md).

## Mechanical connection

Two perforated support tabs, MB1 and MB2, are centered at X = 62 and 98 mm.
Each has a 4.5 mm minimum neck width and two rows of seven **0.60 mm NPTH
holes on 1.00 mm centers**. The 0.40 mm material between holes and 2 mm
routing gap follow the dimensions in
[JLCPCB's mouse-bite guide](https://jlcpcb.com/blog/mouse-bite-panelization-guide),
checked 2026-09-21. There are 28 added non-plated holes in total.

The two edge notches form part of the outer Edge.Cuts outline; the two
interior slots are closed cutouts. There is no routed line across the tabs.
MB1/MB2 are board-only mechanical footprints, excluded from the assembly BOM
and placement files. Their drill holes remain included in fabrication output.

## Electrical connection and separation

A separate **3.5 mm-wide central bridge** at X = 80 mm carries five 0.20 mm
F.Cu tracks between J4 and J5. The perforated support tabs carry no copper.
The trace order is identical on both optional five-pin headers:

| Pin | Connection |
|---|---|
| 1 | +3V3 |
| 2 | GND |
| 3 | SDA |
| 4 | SCL |
| 5 | INT_N |

Leave the section attached during assembly and normal use. To detach it:

1. Disconnect USB and the battery.
2. Support both sections and **cut through the central FR-4 bridge and its
   five traces**, at approximately Y = 124 mm. Do this before bending the board;
   do not rely on tearing the copper traces apart.
3. Separate the two perforated support tabs while supporting the board close
   to the tabs. Trim rough remnants and inspect the cut conductors for shorts.
4. If the detached keyboard will still be used, fit J4/J5 or solder a short
   five-wire connection, matching pins 1–5 straight through.

The silkscreen marks `1 CUT BRIDGE` and `2 SNAP`. The intended central cut
is drawn on Dwgs.User only; it is **not** a manufacturing Edge.Cuts feature.
J4 and J5 remain DNP/user-fitted parts.

## Placement and routing

U8 (PCF8574T) and the centered J3 keyboard header retain their existing
positions. C51, C52, R37, R38, R39 and J5 are placed on the lower section;
J4 is placed on the main board above the gap. The display connector, battery
connector, NFC assembly and ESP antenna notch retain their placement/geometry.

A rule-area band from Y = 121.9–126.1 mm excludes copper pours and vias on
all four copper layers. Additional areas prohibit inner/back-layer tracks
and front-layer tracks through the mechanical tab regions. The five deliberate
front-layer bridge traces are allowed. Keep component bodies and pads away
from the fracture band when continuing placement.

All keyboard and main-board routing is complete. The five original J4-to-J5
bridge connections and the fracture-band restrictions are preserved; see the
[current layout checks](pcb-layout.md).

## Verification and fabrication

The [original breakaway verification](keyboard/breakaway-check.json) records the
mechanical construction before full-board routing:

- One connected board outline with two closed internal slots.
- All eight keyboard-region footprints within the lower 35 mm section.
- The 28 NPTH holes, their pitch, and their presence in the separate NPTH drill file.
- Five continuous J4-to-J5 paths with the correct nets.
- Plane/via keepouts on all four layers and library matches for MB1/MB2.
- Preservation of the other 121 existing footprints and all original pad nets.
- No new DRC violations: the same 18 existing findings remain, with 303
  unconnected items still to route.

That report is historical. The [manufacturing package](manufacturing-release.md)
contains freshly checked Edge.Cuts and separate PTH/NPTH drills, with zero
unconnected items. Its independent drill readback confirms all 28 mouse bites.
Identify this as an intentional functional breakaway that must remain attached
through assembly and delivery. Confirm the fabricator's interpretation of the
tabs and central cut bridge during CAM review.

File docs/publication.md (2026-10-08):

# Public repository and validation

This repository publishes the Nucula v2 hardware as `nucula-board`. Its original
17 development commits retain their sequence, messages, author dates and
committer dates. Personal email addresses and private file details are scrubbed
throughout that history. The publication cleanup remains a separate commit.
See the [history map](history.md) for the rewritten commit IDs.

Workstation configuration is excluded and is not required to open or validate
the design.

## Validation

Use KiCad 10 with the standard libraries and Python 3:

```sh
python3 tools/check_schematic.py
python3 tools/check_component_choices.py
python3 tools/check_assembly_readiness.py
python3 tools/check_display_mapping.py
python3 tools/check_usb_backfeed.py
python3 -m unittest discover -s tools -p 'test_*.py'
```

`KICAD_CLI` and `KICAD_SHARE` override the CLI and standard library locations.
The PCB layout and manufacturing exporter use KiCad's `pcbnew` Python module;
run them with KiCad's bundled Python or an environment providing that module.
Run `tools/check_battery_connector.py` with that interpreter to verify the
side-entry J2 lands, battery polarity and left-edge plug access.
Run `tools/check_mini_module.py` with that interpreter to verify the 53 MINI-1
pins, unchanged GPIO functions, USB fanout and flush antenna cutout.
Run `tools/check_mounting_holes.py` with that interpreter to verify the six
2.2 mm NPTH drills and 5.5 mm hardware clearances on all four copper layers.
The independent Gerber audit requires `gerbonara==1.5.0`, `reportlab` and
`rsvg-convert`. Simulation dependencies are listed in
[the simulation guide](simulation/README.md) and
[NFC requirements](../tools/nfc/requirements.txt).

The USB and display-change regression tools read sanitized design snapshots
from `tools/baselines/`, so they work without private Git commits. The filenames
identify the original development revisions, not the rewritten public commit
IDs; the [history map](history.md) links them to their sanitized counterparts.
Only their required design/report inputs are retained. The historical
`check_usb_clearance.py` and `check_top_contact_update.py` compare entire older
revisions and are not current-board acceptance tests. Current checks are
`check_standard_fabrication.py`, `check_display_mapping.py` and
`check_usb_backfeed.py`, alongside native ERC/DRC and routing/export audits.
Local paths and the
restricted PN7160 visualization model were removed consistently from both
the baselines and current design. The older `check_oled24_update.py` describes
the earlier 26-to-24-contact transition; use `check_top_contact_update.py` for
the current top-contact connector.

## Manufacturing archive

Only the corrected r2 release is published. The public repack preserves all
Gerber, drill, BOM and CPL bytes. It removes editor state, local paths and the
restricted optional 3D model, refreshes the source snapshot and validation
records, and recalculates the manifest and archive checksums. `source_commit`
records the original development baseline before history scrubbing; the
[history map](history.md) identifies its public counterpart. The snapshot's file
hashes identify the release inputs independently of commit IDs. Later changes
to repository documentation do not change the archived release snapshot.

The design still needs the physical qualification and supplier review described
in [the manufacturing instructions](manufacturing-release.md). Successful
software checks do not establish electrical, RF or manufacturing qualification.

## Publication hygiene

Workstation configuration, editor state, backups, virtual environments and
credential files are ignored. Before publishing a new release, scan the proposed
Git history and recursively inspect all archive members and PDF metadata/text.
Run Gitleaks on both the Git history and the unpacked release contents. Check
that release manifests and `.sha256` files match the actual files. Git author
and committer identities should use the maintainer's GitHub no-reply address.

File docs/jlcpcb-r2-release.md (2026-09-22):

# Archived JLCPCB r2 release instructions

Historical instructions for the already-submitted order. The current contingency
revision is described in [manufacturing release](manufacturing-release.md).

Revision **r2**, prepared 2026-09-21 for **10 assembled prototypes**, with the confirmed
FH12A-24S-0.5SH(55) top-contact OLED socket. The approved 0.04 mm J1 ground-land trim is included. The circuit, placement, routing,
antenna and board outline are locked. The display connector questions are closed.

**Files are prepared for quotation and CAM review. Do not authorize production
until the supplier manufacturing reviews below are complete.**
The user is reviewing the JLCPCB upload. No parts have been reserved by these tools.

**r2 replaces the original CPL.** The original exporter added unverified
body-center offsets to U3, DS1 and J2. U3 and DS1 were visibly displaced in
JLCPCB's 2D and 3D previews. This revision removes all three offsets; confirm
lead-to-pad alignment in the updated JLCPCB 2D preview before production.
The PCB, Gerber geometry, BOM, component selections and rotations are unchanged.

## Upload these files

| JLCPCB input | File inside this package |
|---|---|
| PCB fabrication | `nucula-v2-gerbers.zip` |
| Assembly BOM | `assembly/jlcpcb-bom.csv` |
| Placement / CPL | `assembly/jlcpcb-cpl.csv` |
| Supporting drawings | `drawings/assembly-top.pdf`, `drawings/fabrication-outline.pdf`, `drawings/fabrication-notes.pdf` |
| Layer and stencil review | `drawings/layers.pdf`, `gerbers/nucula-v2-F_Paste.gtp` |
| USB clearance detail | `drawings/usb-copper.png`, `drawings/usb-mask.png`, `drawings/usb-paste.png` (blue lands, red NPTH) |
| Procurement quantities | `assembly/purchasing-10-boards.csv` — reference only, not the assembly BOM |

The BOM has **55 exact JLCPCB parts and 116 placements per board**. The CPL has
the same 116 designators, each exactly once. Upload the single-board BOM/CPL
and request 10 assemblies; do not multiply the reference designators by ten.
The fabrication ZIP contains four copper layers, both solder masks and
silkscreens, both paste layers, the outline, separate PTH/NPTH Excellon files,
and a Gerber job file. Bottom paste is intentionally empty. Drill maps are
outside the fabrication ZIP to avoid accidental layer recognition.

`nucula-v2-design-snapshot.zip` archives the input design, libraries and exporter.
`validation/export-board.kicad_pcb` records the derived plotting board, with the
manufacturing stackup/origin and DNP paste omissions. It is an export record;
continue editing the main project, then regenerate a new package.
`manifest.json` ties the outputs to exact input hashes; its source commit records
the baseline HEAD at export. The archived snapshot includes the approved USB fix.
The public r2 package was repacked for publication: local paths, editor locks
and the restricted PN7160 visualization model were removed, and hashes were
recalculated. Its fabrication, BOM and placement bytes are unchanged.

## Order configuration

| Setting | Selection |
|---|---|
| Quantity | 10 PCBs, 10 top-side assemblies |
| Service | Standard PCBA |
| Board | FR-4, four layers, 60 × 110 mm finished envelope |
| Thickness | 1.6 mm nominal |
| Color | Black solder mask, white silkscreen |
| Finish | ENIG |
| Copper | 1 oz outer; 0.5 oz inner |
| Stackup | **JLC04161H-3313**, not “No requirement” |
| Impedance | Request 90 Ω differential, ±10%, for the USB pair; CAM confirmation required |
| Via treatment | **Epoxy Filled & Capped**, all plated round holes of 0.20 / 0.30 / 0.40 mm; preserve supplied mask openings |
| Minimum via | 0.20 mm finished hole / 0.45 mm pad |
| Electrical test | Required |
| Edge rails / fiducials / tooling | **Added by JLCPCB**, supplier-generated carrier |
| Factory depanelization | Keep rails for delivery; **never detach the functional keyboard** |
| Order number | Remove order number; do not add markings over antenna, pads or instructions |

The selected stackup has 0.035 mm outer copper, 0.0152 mm inner copper,
0.0994 mm 3313 prepreg at each surface and 1.265 mm core. Nominal thickness
and finished copper weights follow the supplier's convention; these individual
layer dimensions do not add to exactly 1.600 mm. Prepreg Dk is 4.1. Core Dk 4.6
is an engineering nominal in the export metadata; obtain actual laminate data
if the fabricator changes materials. The locked source board's older nominal
stackup is superseded by this manufacturing specification in the export copy.

This retains the existing 0.15 mm USB trace width and 0.21 mm edge spacing
on B.Cu, referenced to In2.Cu. A simple uncoated IPC-2141 screening estimate
is about 93 Ω differential with the selected prepreg, within the 90 Ω ±10%
target. That approximation is **not** a field-solver or finished-board
qualification: mask, etching and local coupling matter. Have JLCPCB confirm
the actual construction/impedance before production; do not permit automatic
trace changes to the locked design. The exported geometry check verifies
ground reference and 0.2184 mm pair skew.

Standard assembly supports this black/ENIG/specified-stackup combination.
The 60 mm board width is below its 70 mm minimum, so the supplier must add a
carrier meeting its assembly dimensions. Use at least 5 mm process rails,
1 mm fiducials with 2 mm mask openings and supplier tooling holes on the carrier.
Do not add metal, rails or support tabs across the ESP32 antenna notch/overhang.
Avoid carrier attachment near the NFC winding and the keyboard fracture band.
The carrier must support both keyboard and main board during assembly; supplier
CAM must determine tab positions from the actual copper clearance. Approve the
carrier drawing before production. JLCPCB must transform this single-board CPL
to its own panel coordinates; do not upload a manually offset or replicated CPL.

## USB clearance resolved and final manufacturing review

J1 uses the project-local USB4105 footprint with the two outer ground lands
shortened by **0.04 mm at the hole-facing end**. Copper, mask and paste follow
this trim. Minimum nominal NPTH-to-pad clearance is **0.2333 mm**, above
JLCPCB's 0.20 mm requirement; the local KiCad rule is raised to 0.20 mm.
Holes, shell stakes, connector placement, signals and routing are unchanged.
The footprint is a project adaptation, not a new manufacturer land drawing.
`validation/usb-clearance-check.json` and `validation/gerber-readback.json`
verify the source and exported geometry. No hole-clearance waiver is required.

1. Confirm the specified 3313 stackup and USB impedance without geometry changes.
2. Confirm supplier carrier dimensions, tooling and attachment locations, preserving
   the ESP32 overhang, NFC exclusion and attached functional keyboard.
3. Match all 55 C-codes and inspect all 116 placements in JLCPCB's assembly preview.
   The exported rotations are KiCad counterclockwise angles normalized to 0–360°.
   **Catalogue-specific rotations have not been verified in a logged-in preview.**
   Use the pad coordinates and assembly drawing to check pin 1, diode/LED cathodes,
   MOSFET pin order, module antenna direction and all connector openings. Record
   any necessary corrections in `docs/manufacturing-spec.json`, then regenerate.
4. Check the final quote's quantities, loss allowance and availability before payment.

Two existing ESP32 silk-to-edge warnings are accepted for this export: they
concern the outline at the antenna overhang. CAM may clip off-board silkscreen
only. No copper, pads, outline or component position may change. All other
electrical/routing/parity errors must remain zero. DRC's ignored checks are
listed in `validation/drc.json`; it is not a blanket process certification.

## Assembly and stencil details

Do not assemble **C7, C8, C34, C35, C38, C39, J3, J4, J5, R38, R39**.
Their copper and drill geometry remains; their stencil apertures are omitted.
**A1** is the etched antenna, and **MB1/MB2** are mechanical mouse-bite patterns.
None is a purchased or placed component. OLED glass, external keypad and battery
are user-supplied and excluded. DS1 purchases the socket only.

The PN7160 U6 exposed pad uses nine rounded 1.1 mm stencil apertures, approximately
62% total coverage of its 4.1 mm square copper land. Preserve this windowing.
DS1's 24 signal apertures are 0.25 × 1.30 mm on 0.50 mm pitch, with separate
hold-down apertures. Use a nominal **0.10 mm stencil**, subject to assembler
paste-volume review for connectors and the exposed pad. Do not add paste to DNP
pads or turn the exposed-pad windows into one full-size aperture.

Fill and copper-cap **all 335 plated round holes of 0.20, 0.30 and 0.40 mm**.
This includes U3's twelve 0.20 mm thermal pad holes, the via centered in R28
pad 2, and vias overlapping other exposed lands. Tenting alone cannot prevent
solder wicking where a pad's mask opening intersects a hole. Preserve the
specified mask apertures over the caps. **Leave the four 0.60 mm USB connector
slots, nineteen 1.00 mm header holes and every NPTH hole open.** The diameter
selection is unambiguous in the separate PTH drill file. Select “Confirm
production files” to verify the fill interpretation. This process adds cost;
the final quote must include it. [JLCPCB via-covering instructions](https://jlcpcb.com/help/article/pcb-via-covering).

CPL coordinates use the board's lower-left envelope corner: KiCad (50,160 mm)
becomes (0,0), +X right, +Y up in the top view. Gerbers and drills use the same
origin. The board envelope is X = 0–60, Y = 0–110 mm.

CPL coordinates now preserve the **native KiCad footprint origins**, without
re-centering on the F.Fab body outline. KiCad's model is already positioned
relative to its footprint; JLCPCB renders its own catalogue model using the
uploaded placement reference. A body center is not automatically that reference.

The three changes from the original upload are:

| Reference | Original CPL X, Y (mm) | r2 CPL X, Y (mm) | Rotation |
|---|---|---|---|
| U3, ESP32 | 51.000, 53.860 | **47.900, 53.860** | 270° |
| DS1, display socket | 30.000, 53.050 | **30.000, 51.150** | 180° |
| J2, battery socket | 5.000, 59.100 | **6.750, 59.100** | 90° |

The U3 and DS1 offset directions match the user's observed error. J2's
unverified shift came from the same export rule and is also removed; its
catalogue alignment has not yet been reported. The other 113 placement rows
are unchanged. Recheck all three in JLCPCB's 2D pad view, including pin 1 and
connector entry/antenna direction. A correct KiCad 3D view does not validate
JLCPCB's independent model origins or zero-degree orientations.

`assembly/placement-audit.csv` records native origins and explicit offsets.
`validation/gerber-readback.json` verifies all 116 CPL coordinates against the
native KiCad export and the selected BOM. It does not certify alignment of
JLCPCB's catalogue models. `assembly/pad-coordinates.csv` supplies the board
pad positions/nets for the final assembly review. See JLCPCB's
[native KiCad CPL export instructions](https://jlcpcb.com/help/article/how-to-generate-the-bom-and-centroid-file-from-kicad).

## Keyboard and routing instructions

The keyboard is an intentional functional part of **one board**, not a second
customer design to separate in the factory. It occupies the lower 35 mm of the
60 × 110 mm envelope. Keep it attached throughout assembly and shipment.

In KiCad coordinates the 2 mm routing gap is Y = 123–125 mm. Two perforated
support tabs are centered at X = 62 and 98 mm, with 4.5 mm necks. Each carries
two rows of seven 0.60 mm NPTH holes on 1.00 mm pitch: **28 mouse-bite holes**.
The separate 3.5 mm central bridge at X = 80 mm carries five electrical traces.
The intended later user cut at Y = 124 mm is on Dwgs.User **only**. It must not
be routed, V-scored or drilled by the factory. Fabricate only the actual Edge.Cuts
features and supplied drills. Preserve the two closed internal slots, outer
notches and the separate PTH connector slots.

Paste this into the order's engineering remarks:

> One functional PCB with attached keyboard: DO NOT separate, V-score or route
> through the central electrical bridge or the two internal mouse-bite tabs.
> Keep keyboard and external assembly rails attached for delivery. Use
> JLC04161H-3313, black mask, ENIG, top assembly. Confirm 90-ohm USB differential
> impedance on B.Cu/In2.Cu without copper edits. Add carrier/rails/fiducials/tooling
> clear of ESP32 antenna overhang and NFC winding. J1 supplied lands have
> 0.233 mm NPTH clearance. No unapproved copper/pad/hole/component changes. Preserve U6 windowed paste and DNP omissions.
> Epoxy-fill and copper-cap all 0.20/0.30/0.40 mm plated round holes (335 total),
> including U3 thermal holes; preserve the supplied solder-mask openings. Leave
> 0.60 mm plated connector slots, 1.00 mm headers and all NPTH holes open.

## Stock and prototype acceptance

All 55 exact C-codes were refreshed on 2026-09-21 and have enough available
quantity for the saved ten-board purchasing plan, including the catalogue's
minimum placement/loss fields. Stock is not reserved. **L2/L3 C20417049: 21
available / 20 planned. C36/C37 C527192: 50 available / 28 planned.** Recheck
these first at checkout. No part substitutions were made.

For each delivered board, record its identifier and:

- Inspect assembly, connector contact side, polarity and solder joints; measure
  resistance from each power rail to ground before power-up.
- Use the agreed dedicated 5 V / at least 1.5 A USB supply with current monitoring;
  verify VSYS, 3.3 V, 3.0 V and enabled OLED boost, reset and startup current.
- Program and check USB enumeration, then I²C PN7160 0x28, OLED 0x3C and keypad
  expander 0x20 at 100 kHz; exercise display and all keys.
- Follow the existing NFC oscillator/antenna tuning procedure in the actual
  enclosure; calculations and DRC do not qualify RF performance.
- If used, verify battery polarity and 100 mA charging before unattended use.
  Test keyboard separation/reconnection on one unit only after attached operation
  works, with USB and battery disconnected.

## Reproduce

From the source repository:

```sh
python3 tools/check_schematic.py
python3 tools/refresh_jlc_stock.py
python3 tools/check_assembly_readiness.py --boards 10
python3 tools/check_usb_clearance.py
python3 tools/check_top_contact_update.py
# Use a Python interpreter that can import pcbnew and wx:
python3 tools/prepare_jlcpcb.py --output manufacturing/NEW-RELEASE
```

On this Mac the last command uses
`/Applications/KiCad/KiCad.app/Contents/Frameworks/Python.framework/Versions/3.9/bin/python3.9`.
Exports use KiCad 10.0.6. A separate Gerbonara readback checks actual Gerber/drill
outputs and produces the fabrication notes and inspection views. Its command is
`python3 tools/inspect_jlcpcb.py manufacturing/NEW-RELEASE` with Gerbonara 1.5.0
and ReportLab installed, plus `rsvg-convert` for PNG previews. KiCad exports contain
timestamps, so reproduce geometry and audit counts; use manifest hashes to
identify the exact delivered archive rather than expecting byte-identical PDFs.

Sources checked on 2026-09-21: [JLCPCB fabrication capabilities](https://jlcpcb.com/capabilities/Capab),
[assembly capabilities](https://jlcpcb.com/capabilities/pcb-assembly-capabilities),
[stackup](https://jlcpcb.com/impedance),
[carrier requirements](https://jlcpcb.com/help/article/how-to-add-edge-rails-fiducials-for-pcb-assembly-order),
[Gerber export](https://jlcpcb.com/help/article/how-to-generate-gerber-and-drill-files-in-kicad-9),
[BOM format](https://jlcpcb.com/help/article/bill-of-materials-for-pcb-assembly),
[CPL format](https://jlcpcb.com/help/article/pick-place-file-for-pcb-assembly).

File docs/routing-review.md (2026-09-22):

# Full-board routing repair

22 September 2026 · `routing-review-2026-09-22`

The first standard-fabrication revision introduced free-form fragments and
marginal copper joins. Passing connectivity DRC was insufficient: some routes
connected through small copper overlaps without meeting at their centrelines
or entering their pads properly. This revision repairs that regression across
all four copper layers and adds an independent check for those patterns.

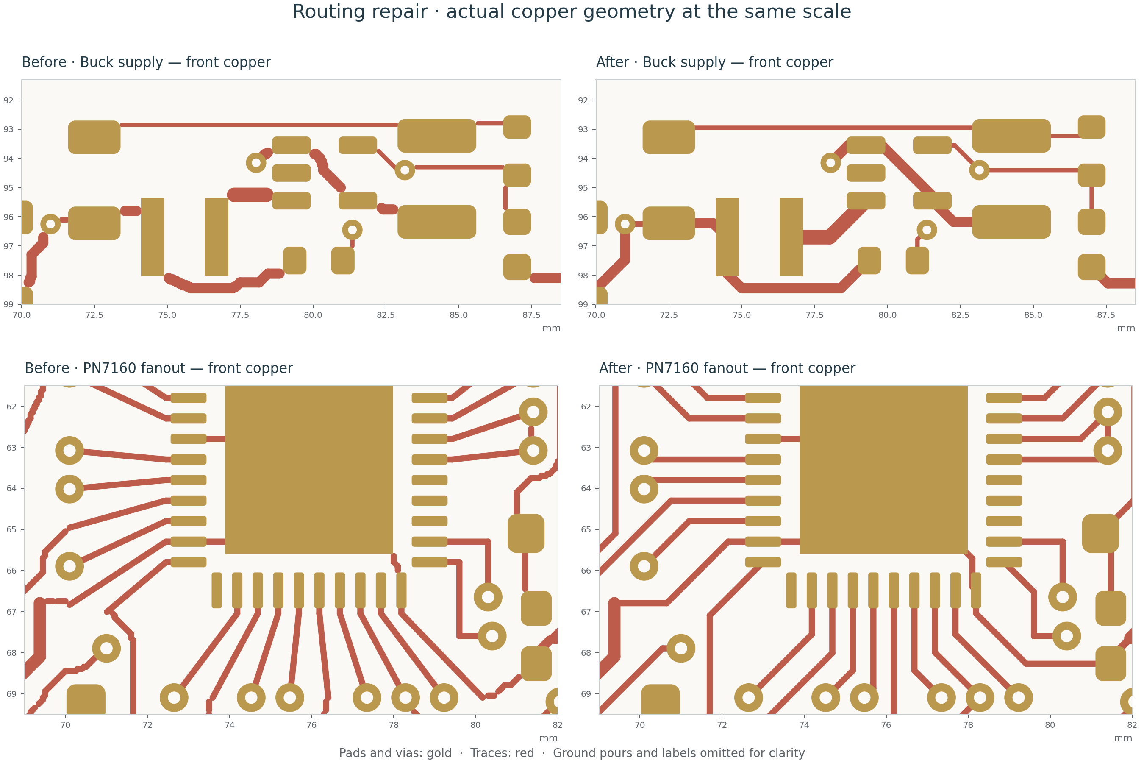
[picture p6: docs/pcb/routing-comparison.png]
Routing before and after, with actual copper widths


[Full-resolution comparison](pcb/routing-comparison.svg) ·
[Current top view](pcb/top.svg) · [All copper layers](pcb/copper-layers.svg) ·
[Manufacturing package](../manufacturing/routing-review-2026-09-22-package.zip)

| Geometry audit | Before repair | Current board |
|---|---:|---:|
| Trace segments | 1,931 | 1,021 |
| Routing vias | 316 | 312 |
| Non-45-degree segments | 141 | 0 |
| Shallow or unsupported trace endpoints | 286 | 0 |
| Connected groups relying on copper-edge overlap | 38 | 0 |
| Duplicate segments | 3 | 0 |
| Acute two-segment return bends | 3 | 0 |
| Exposed segments shorter than 0.20 mm | 793 | 0 |

Counts come from the same checker on the saved
[before](pcb/routing-before.json) and [after](pcb/routing-quality.json) geometry.
They identify routing patterns, not predicted manufacturing failures; findings
can overlap. Fewer segments alone is not a quality criterion.

Routes now follow horizontal, vertical and 45-degree lines, with continuous
centreline joins and substantial entries into pad/via lands. Redundant tails,
tiny staircases, duplicate copper and sharp return bends have been removed.
Power connections were rebuilt at appropriate existing widths, with several
formerly narrow connections widened. The NFC matching buses remain exactly
mirrored. Explicit ground and supply connections were restored wherever the
old layout depended on marginal copper overlap.

Five unused vias were removed and one ground via was added for C43's local
ground island. An existing 3V3 via near the NFC address routes moved 0.15 mm
left to permit a clean diagonal without a tiny jog. All remaining routing vias
retain the ordinary 0.30 mm drill / 0.70 mm land construction.
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

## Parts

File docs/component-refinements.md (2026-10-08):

# Prototype component refinements — 2026-09-20

The first main-board prototype is intended to operate from a **dedicated 5 V
USB-C supply rated for at least 1.5 A at 5 V**, confirmed by the user. Battery runtime,
discharge capability and improved low-battery behavior are deferred by the
user. The charger, battery connector and existing buck/reset behavior remain.

OLED correction, 2026-09-21: the user's exact breakout schematic specifies
**24 contacts**, superseding the earlier 26-contact assumption. The schematic,
socket, routing and purchasing data now use the CON24 map.

## Crystal selected from NXP's recommended references

Y1 is **NDK NX2016SA-27.12MHZ-EXS00A-CS06346**, JLCPCB **C3008209**.
It is explicitly listed in NXP AN14518 rev. 6.0, section 7.2, Table 9.
Its **2.0 × 1.6 mm** four-pad package replaces the unselected Epson 3225
candidate. The smaller package permits short oscillator routing; the crystal
can be assembled by the board assembler, while the load capacitors remain
0603 for adjustment. The RF antenna tuning capacitors remain hand-solder 0805.

The project footprint `Crystal_NDK_NX2016SA_2.0x1.6mm` uses NDK drawing
EXD14B-00467: **0.85 × 0.75 mm pads**, with centers spaced **1.35 × 1.05 mm**.
Pins 1/3 are the resonator; 2/4 connect to its metal cover and ground.

| Characteristic | NDK specification used |
|---|---|
| Frequency / mode | 27.120 MHz, fundamental |
| Nominal load | 10 pF |
| ESR | 25 Ω typical, **100 Ω maximum** |
| Crystal shunt capacitance | 0.60 pF ±20% |
| Motional capacitance | 1.54 fF ±20% |
| Drive | 10 µW typical, 100 µW maximum |
| Initial tolerance | ±15 ppm at 25 °C |
| Temperature shift | ±15 ppm over −20…+70 °C; ±40 ppm over −40…+105 °C |
| Aging | ±2 ppm first year in the newer NDK specification |

Use the actual NDK specification rather than the distributor's generic
60 Ω / −40…+125 °C catalogue attributes. The two downloaded NDK versions
agree on the oscillator parameters; the newer EXS11B-10535 includes the aging
limit. This selection does not guarantee a ±50 ppm total error over the
entire extended temperature range: initial, temperature, aging and PCB
loading errors must all be budgeted. Room-temperature tuning and cold/hot
start tests are still necessary.

The refreshed public JLCPCB page shows **8,538 available to order**, sufficient
for ten boards. The raw field `overseasStockCount` is displayed by the site as
“In Stock”; its name alone does not establish a separate overseas sourcing route.
`preMinPurchaseNum = 24` applies to a pre-order beyond available stock, not to
this in-stock assembly quantity. Stock is not reserved. The original cautious
interpretation is superseded by the [assembly stock audit](assembly-readiness.md)
and refreshed [crystal observation](components/crystal-jlc-stock.json).

Sources: [NXP oscillator guide](https://www.nxp.com/docs/en/application-note/AN14518.pdf),
[PN7160 datasheet rev. 4.2](https://www.nxp.com/docs/en/data-sheet/PN7160_PN7161.pdf),
[NDK exact-part specification](https://mm.digikey.com/Volume0/opasdata/d220001/medias/docus/6749/CS06346-27.12M.pdf),
[JLCPCB C3008209](https://jlcpcb.com/partdetail/C3008209).
Copies of the NXP and NDK PDFs are in `parts documentation/`.

## Crystal load calculation and adjustment

C26 = **12 pF**, Samsung CL10C120JB8NNNC (C38523), and C27 = **15 pF**,
Samsung CL10C150JB8NNNC (C1644). Both are **0603, 50 V, C0G, ±5%**.
Both exact JLCPCB codes are now verified. These are starting values, not a claim
of final frequency.

We used NXP AN14518 rev. 6.0 Figure 5's explicitly stated model:

```text
A = C26 + C_IC_IN + C_PCB_IN
B = C27 + C_IC_OUT + C_PCB_OUT
C_seen,NXP = A × B / (A + B) + C_PCB_CROSS + C_crystal_shunt
```

PN7160 Table 46 specifies 2 pF typical at each oscillator pin. In the absence
of this PCB, the calculation uses NXP's measured OM27160 board parasitics
as a reference: 1.19 pF input-to-ground, 1.31 pF output-to-ground, 1.39 pF
cross-coupling. **These are not measurements of our design.** Crystal shunt
capacitance is 0.60 pF. NXP's Figure 5 convention includes this shunt term;
do not silently interchange it with a Pierce formula that defines external
load separately from the crystal's internal capacitance.

Under that model, equal capacitors would be **12.770 pF**. The readily
available E12 combination **12 pF / 15 pF** yields 10.292 pF. The indicative
pull from the nominal 10 pF load is about **−1.95 ppm**, ignoring initial
crystal frequency error. Different loading on the two oscillator pins is
allowed by the two-capacitor model; this is separate from the antenna's
balanced network, whose corresponding branches must remain matched.

NXP recommends measuring and adjusting the RF carrier to **−5…0 ppm**
relative to 13.56 MHz. The calculated offset above cannot establish that
result before layout. Keep 10, 12, 15, 18 and 22 pF C0G 0603 parts for
replacement, and small 0.5–2.2 pF parts for temporary parallel adjustment.
Do not add long oscillator test-point stubs. Measure the carrier with loose
coupling so that probing the oscillator does not change its load. Increasing
load generally reduces frequency, but retest start-up after changing it.

Place Y1 immediately beside U6 pins 29/30 with short traces, local ground
returns for both capacitors and the case, and no switching-node routing
nearby. Measure repeated cold starts, standby wake-ups, frequency and drive
over the intended supply/temperature range. PN7160's stated oscillator
start-up maximum is 3 ms. AN14518 recommends using the retry/boosted-start
feature available in firmware 12.50.11; the retained C100E device originally
ships with older firmware, so check/update firmware before relying on it.
The labeled `NFC_DWL_REQ` net must be accessible for download-mode recovery.

Sources: [12 pF manufacturer data](https://product.samsungsem.com/mlcc/CL10C120JB8NNN.do),
[15 pF manufacturer data](https://product.samsungsem.com/mlcc/CL10C150JB8NNN.do).

## PN7160 decoupling and power capacitor selection

AN12988 rev. 1.6 section 7.1 calls for separate 2.2 µF capacitors close to
the digital/analog pins and two 2.2 µF capacitors on the transmitter supply.
The former single 10 µF plus 100 nF on each rail has been changed accordingly:

| References | Selected value/package | Placement / purpose |
|---|---|---|
| C21 / C22 | 2.2 µF each, 25 V X7R 10%, 0805 | U6.26 VDDA / U6.27 VDD, respectively |
| C23 / C24 | 2.2 µF each, 25 V X7R 10%, 0805 | U6.18 TVDD_IN / U6.22 TVDD, respectively |
| C17 / C19 | 10 µF, 25 V X7R 10%, 1206 | VBAT / VDD_UP; margin for 4.7 µF reference requirement |
| C15 | 1 µF, 50 V X7R 10%, 0805 | VDD_PAD |
| C16 / C18 / C20 / C25 | 100 nF, 50 V X7R 10%, 0603 | Additional local bypass / VMID |
| C1 / C2 / C4 | 22 µF, 25 V X7R 10%, **1210** | Charger input / battery / VSYS |
| C5 / C6 / C9 | 22 µF, 25 V X5R 10%, **1206** | Buck output and ESP32 local bulk |
| C40 | 10 µF, 25 V X7R 10%, 1206 | OLED boost input |
| C42 / C46 | 1 µF 50 V 0805 / 4.7 µF 50 V 1206 | OLED boosted-rail capacitors, X7R 10% |
| C44 / C47 | 4.7 µF / 2.2 µF, 25 V X7R 10%, 0805 | OLED logic bulk / VCOMH |

Exact manufacturer and LCSC codes are in [the BOM](bom.csv). In particular,
C1/C2/C4 use CL32B226KAJNNNE, C5/C6/C9 use CL31A226KAHNNNE, and
C17/C19/C40 use CL31B106KAHNNNE. The 2.2 µF CL21B225KAFNNNE/C19110
is a catalogue-supported prototype selection, but Samsung marks it **NRND**;
requalify its suggested successor for a production revision. The reference
2.2 µF values are nominal values, not promises of 2.2 µF minimum at bias.

Samsung's numerical, typical DC-bias curves were downloaded and archived as
JSON in `docs/components/`. For screening we multiply biased capacitance by
0.90 for tolerance, 0.85 for temperature and an additional 0.95 allowance.
The 5% allowance is an engineering assumption, not a manufacturer lifetime
guarantee. Combining typical bias data with independent derating factors is
a useful design screen, not a guaranteed combined-corner specification.

| Capacitor group | Evaluated voltage | Typical at bias | Screened estimate per part |
|---|---:|---:|---:|
| C1/C2/C4 | 5.5 V | 16.64 µF | 12.09 µF; target >10 µF |
| C5/C6/C9 | 3.393 V | 17.26 µF | 12.54 µF; C5+C6 >22 µF |
| C17/C19/C40 | 5.5 V | 6.86 µF | 4.98 µF; reference target 4.7 µF |

This is why several bulk capacitors now occupy 1206/1210 instead of generic
0805. Verify input/output ripple, load-step response and regulator stability
on the prototype. Keep the buck input loop compact despite the larger part.

Sources: [NXP hardware guide](https://www.nxp.com/docs/en/application-note/AN12988.pdf),
[1210 bulk capacitor](https://product.samsungsem.com/mlcc/CL32B226KAJNNN.do),
[1206 bulk capacitor](https://product.samsungsem.com/mlcc/CL31A226KAHNNN.do),
[10 µF capacitor](https://product.samsungsem.com/mlcc/CL31B106KAHNNN.do),
[2.2 µF capacitor](https://product.samsungsem.com/mlcc/CL21B225KAFNNN.do).
Each archived curve also records its source, AC measurement conditions and date.

## USB operation and deferred battery work

The schematic supports USB operation with **J2 empty**: power reaches VSYS
through D1/D2, independently of the battery and charger output. The separate
5.1 kΩ CC resistors remain. No USB-PD voltage above 5 V is requested.

Use a known USB-C source that offers at least **1.5 A at 5 V**. For a
4.75 V connector voltage and conservative 0.5 V allowance per diode,
VSYS is 3.75 V. The following planning case totals **1.10 A at USB**:

```text
I_USB = [(3.393 V × 0.5 A / 0.85) + (13.5 V × 0.030 A / 0.75)] / 3.75 V
        + 0.290 A NFC + 0.115 A charging + 0.020 A auxiliary
      = 1.101 A
```

The 500 mA logic-rail and 30 mA OLED currents are load assumptions, not
measured worst cases. Measure the actual panel current to validate this
budget. At VSYS 3.75 V the initial NFC TVDD setting of 3.3 V
retains more than NXP's typical 0.3 V TXLDO headroom requirement.

This closes a **steady-state prototype source budget**, not USB host
qualification: the circuit does not detect the source's advertised current,
limit input current, control capacitor inrush, or suspend charging with the
host. A 500 mA computer port is not the specified source. Verify power-up,
hot-plug and D1/D2 temperatures with the selected adapter/cable and loads.
The source must not fold back during input-capacitor charging. If it does,
input soft-start is needed before relying on that source. Firmware still
needs to initialize PN7160 power/clock settings and sequence OLED power.

J2 now uses **JST SM02B-SRSS-TB(LF)(SN), C160402, 1.00 mm pitch, side-entry SMT**,
2.95 mm high when mated, with its opening toward the left edge. An SHR-02V-S-B
lead replaces the PH plug. The user accepts intermittent peaks above its 1 A
rating; the 100 mA charging circuit and battery operation remain unchanged.
[Connector selection and validation](battery-connector.md). Pin 1 is battery positive,
pin 2 ground. Battery testing is optional; existing charge current, lack of a
physical off switch and low-battery reset behavior are accepted for this
iteration. Pack selection/polarity/protection must be checked before attaching
a battery, but battery runtime is not a USB-prototype layout criterion.

## Confirmed OLED interface

The exact [CON24 breakout schematic](../parts%20documentation/i2c-display-breakout-schematic.png.png)
is now the electrical reference. DS1 has **24 contacts**, with SCL on 13,
SDA on 14 and 15, reset on 9, IREF on 21, VCOM on 22 and panel power on 23.
Pins 1–24 retain their previous signal assignments; the extra ground contacts
25 and 26 were removed. Pin 4 remains NC. See the [complete map and checks](oled24/README.md).

DS1's purchased item is **Hirose FH12A-24S-0.5SH(55)**, JLCPCB **C506794**;
the OLED glass is supplied separately and excluded from the assembly BOM.
The top-contact socket matches the user-confirmed NFP1309-02Y ribbon: 0.50 mm
pitch, 0.30 mm thickness and mounted tip contacts facing away from the PCB.
Its drawing-derived footprint/paste and local routing pass the
[connector update checks](oled24/top-contact.md). DS1 moved 0.20 mm toward the
keyboard while retaining its 180° orientation. Physical insertion, panel pin-1
correspondence and operation still need prototype validation.

## Reproduction

Run `python3 tools/check_component_choices.py` to regenerate
[calculated results](components/calculations.json) from the archived curves.
Run `python3 tools/check_schematic.py` for native KiCad ERC, independent pin/net
checks, footprint checks, selected component checks and regenerated BOM.
Native KiCad PDF export generates `docs/schematic.pdf`.
No PCB layout, measured oscillator qualification, full-wave RF validation,
USB compliance claim or fabrication release is included in these refinements.

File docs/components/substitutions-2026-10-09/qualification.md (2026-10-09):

# Stock substitution qualification — 9 October 2026

Status: engineering screening for five prototypes; **physical RF qualification is outstanding**.
The user explicitly accepted a different RF part after revalidation. There is
no claim of identical electrical specifications or guaranteed unchanged read range.

## Selected parts

| References | Original | Selected / JLC code | Preserved / changed |
|---|---|---|---|
| C10 C11 C13 C14 C16 C18 C20 C25 C43 C45 C48 C51 C55 | CL10B104KB8NNNC | CL10B104KB8NNNL / C913912 | 0603, 100 nF, 50 V, X7R, 10%; Samsung confirms C and L are reel-packaging alternatives of the same component |
| C28 C29 | GRM2165C2A102JA01D | CC0805JRNPO0BN102 / C326940 | 0805, 1 nF, 100 V, C0G/NP0, 5%; manufacturer changes |
| C36 C37 | CC0805GRNPO0BN101 | 0805CG101F101NT / C464454 | 0805, 100 pF, 100 V, C0G; tolerance tightens from 2% to 1% |
| L2 L3 | 0805HP-151XGRC | 0805CS-151XGLC / C38190612 | 150 nH, 2%; different RF impedance and terminations, described below |

The original-BOM live check found four unavailable lines, including C36/C37
which were not in the initial user list. Inventory observations are not reserved
parts. See the package purchasing table for quantities, minimums and loss allowances.

The 150 nH catalogue search returned 314 records across seven pages. Additional
part-number searches covered alternative HP packaging, CS/HT/HQ, R15G/R15F,
151XG and air-core families. No exact stocked HP electrical equivalent was
verified. The CS option has a directly published manufacturer RF model and
allows retention of the original copper. Murata LQW2BANR15G00L and larger
Coilcraft 1008CS/1206CS/1812SMS candidates also differ electrically; the larger
parts offer no established equivalence and would alter the mounted geometry.

## Inductor electrical screening

The original and new ceramic-core inductors are both 150 nH ±2% at the vendor's
100 MHz test frequency. HP DCR maximum is 0.288 Ω versus CS 0.560 Ω. HP SRF is
1150 MHz typical versus CS 920 MHz typical. HP Q is 80 typical at 250 MHz;
CS Q is 50 minimum at 250 MHz: these are different statistical specifications,
not a measured side-by-side Q ratio. The 15°C-rise DC reference current changes
from 0.60 A to 0.40 A; it is not an absolute maximum or an RF thermal guarantee.

Published typical models use the topology
`Rdc + ((k*sqrt(f) + jwL) || (Rpar + 1/jwC))`:

| Part | Rdc Ω | k | L nH | C pF | Rpar Ω |
|---|---:|---:|---:|---:|---:|
| 0805HP-151 | 0.288 | 1.554e-4 | 148.8 | 0.135 | 10 |
| 0805CS-151 | 0.560 | 2.230e-4 | 149.0 | 0.110 | 24 |

No matching capacitance, resistance or nominal inductance was retuned.
`rf-qualification.json` contains 237 paired cases, 474 ngspice runs, and hashes
of the exact board/netlist/model/script inputs. These include coil L ±10%,
assumed coil R/C and receiver-load corners, 200 independent component-tolerance
samples, and replacement-capacitor ESR scenarios from 0.003 to 0.3 Ω.
The ESR bounds are engineering assumptions, not guaranteed vendor limits.

Acceptance limits chosen for this engineering substitution are <10% relative
change in carrier input impedance and coil current, terminal current <0.4 A,
capacitor peak voltages below ratings, and each damping resistor below the
existing 0.5 W screening limit. These are project criteria, not an NXP RF
conformance specification. Models do not establish global worst-case bounds.

At 13.56 MHz nominal, input impedance changes from 18.84 − j0.14 Ω to
19.88 − j0.11 Ω; coil current under the modeled 3.3 V drive decreases from
251.4 mA to 238.3 mA. Across tested scenarios, the largest impedance change is
8.44% and coil-current change 6.89%. At the deliberately conservative ideal
5.5 V square-drive fundamental, maximum terminal current is 378.5 mA,
capacitor peak voltage 42.84 V and damping-resistor power 0.441 W.

The separate frequency-dependent odd-harmonic estimate (1st–39th harmonics)
gives nominal CS terminal current 251.0 mA and inductor dissipation 87.7 mW
at 5.5 V. A DC-derived thermal-resistance estimate gives ~14.7°C nominal rise.
Doubling that nominal loss at 85°C ambient remains below the 140°C part limit.
This is a screening estimate only; neither board thermal resistance nor
worst-case RF heating has been measured. Check temperature on assembled boards.

## Mechanical and placement review

All 19 substitutions retain their original footprint anchors, orientation,
net connections and pad copper/mask/paste. Capacitor packages remain 0603 or
0805 as originally laid out. L2/L3 now use the explicitly named custom footprint
`L_Coilcraft_0805CS_RevALands`, with a 2.29 × 1.73 mm maximum body drawing.
The original HP maximum body length was 2.21 mm, so this is +0.04 mm per end.
The existing 3.66 × 2.48 mm courtyard contains the new body.

CS datasheet dimensions A/B/C are 2.29/1.73/1.52 mm maximum. Terminal wraparound
is approximately 0.38 mm at both ends. The retained pads span x = −1.58…−0.56
and +0.56…+1.58 mm, y = ±0.99 mm, relative to the footprint anchor. They cover
the contact strips indicated by the manufacturer's body/terminal drawing and
provide toe/side solder area. These retained 1.02 × 1.98 mm pads with 1.12 mm
gap differ from the manufacturer's recommended 1.02 × 1.78 mm pads with 0.76 mm
gap. Terminal-wrap dimensions are approximate; this is an engineering fit
review, not a manufacturer endorsement of the custom land pattern. Inspect
first-article joints. No body-center or catalogue rotation offsets are added.

The selected L termination is RoHS-compliant silver/palladium/platinum glass
frit and **is not halogen-free**. The archived CS datasheet explicitly covers
this suffix. The maximum body and terminal pattern are common to the series.

The updated regression permits only the listed metadata/tolerance/body-drawing
amendments. It still rejects pad, placement, routing, matching-value, stackup
or via-process changes. Nine mutation tests exercise this behavior, including
moving a substituted inductor, changing its pad and selecting an unreviewed MPN.
Independent fabrication Gerber comparison continues to require exact rev-A
NFC copper and solder-mask geometry.

## Scope and sources

This review does not simulate the complete PN7160 controller, firmware, tags,
RF emissions, assembled-board electromagnetic coupling or read range. Use the
same test tags/setup as rev A and check AGC, temperature and supply current.
A simulation pass cannot guarantee that no physical tuning will be needed.

- [Samsung common family and packaging codes](https://product.samsungsem.com/cn/mlcc/CL10B104KB8NNN.do)
- Yageo and Fenghua manufacturer datasheets archived as C326940.pdf / C464454.pdf; ordering codes retain voltage and dielectric ratings.
- [Coilcraft CS datasheet](https://www.coilcraft.com/getmedia/dd5f20e4-1ff7-43df-8317-b693eb2dce3e/0805cs.pdf), archived as 0805cs.pdf.
- [Coilcraft CS RF model, doc 158-6, 2025-01-16](https://www.coilcraft.com/getmedia/c86a99da-e310-4932-bb03-09af08346f8a/spice_0805cs.pdf), archived as 0805cs-spice.pdf.
- [Coilcraft HP reference model](https://www.coilcraft.com/getmedia/d2f56f9b-ef33-42ca-bf60-5b64b7e705a7/spice_0805hp.pdf).

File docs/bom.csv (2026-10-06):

Reference | Value | Footprint | Manufacturer | MPN | LCSC | Tolerance | Voltage | Rating | Dielectric | DNP | PCB Region | Status | Datasheet
C1 | 22uF | Capacitor_SMD:C_1210_3225Metric | Samsung Electro-Mechanics | CL32B226KAJNNNE | C309062 | 10% | 25 V |  | X7R | no | MAIN | SELECTED: manufacturer DC-bias curve checked; retain exact part or re-evaluate | https://product.samsungsem.com/mlcc/CL32B226KAJNNN.do
C2 | 22uF | Capacitor_SMD:C_1210_3225Metric | Samsung Electro-Mechanics | CL32B226KAJNNNE | C309062 | 10% | 25 V |  | X7R | no | MAIN | SELECTED: manufacturer DC-bias curve checked; retain exact part or re-evaluate | https://product.samsungsem.com/mlcc/CL32B226KAJNNN.do
C3 | 22pF | Capacitor_SMD:C_0603_1608Metric | Samsung Electro-Mechanics | CL10C220JB8NNNC | C1653 | 5% | 50 V |  | C0G | no | MAIN |  | https://www.lcsc.com/datasheet/lcsc_datasheet_2304140030_Samsung-Electro-Mechanics-CL10C220JB8NNNC_C1653.pdf
C4 | 22uF | Capacitor_SMD:C_1210_3225Metric | Samsung Electro-Mechanics | CL32B226KAJNNNE | C309062 | 10% | 25 V |  | X7R | no | MAIN | SELECTED: manufacturer DC-bias curve checked; retain exact part or re-evaluate | https://product.samsungsem.com/mlcc/CL32B226KAJNNN.do
C5 | 22uF | Capacitor_SMD:C_1206_3216Metric | Samsung Electro-Mechanics | CL31A226KAHNNNE | C12891 | 10% | 25 V |  | X5R | no | MAIN | SELECTED: manufacturer DC-bias curve checked | https://product.samsungsem.com/mlcc/CL31A226KAHNNN.do
C6 | 22uF | Capacitor_SMD:C_1206_3216Metric | Samsung Electro-Mechanics | CL31A226KAHNNNE | C12891 | 10% | 25 V |  | X5R | no | MAIN | SELECTED: manufacturer DC-bias curve checked | https://product.samsungsem.com/mlcc/CL31A226KAHNNN.do
C9 | 22uF | Capacitor_SMD:C_1206_3216Metric | Samsung Electro-Mechanics | CL31A226KAHNNNE | C12891 | 10% | 25 V |  | X5R | no | MAIN | SELECTED: manufacturer DC-bias curve checked | https://product.samsungsem.com/mlcc/CL31A226KAHNNN.do
C10 | 100nF | Capacitor_SMD:C_0603_1608Metric | Samsung Electro-Mechanics | CL10B104KB8NNNC | C1591 | 10% | 50 V |  | X7R | no | MAIN |  | https://www.lcsc.com/datasheet/lcsc_datasheet_2304140030_Samsung-Electro-Mechanics-CL10B104KB8NNNC_C1591.pdf
C11 | 100nF | Capacitor_SMD:C_0603_1608Metric | Samsung Electro-Mechanics | CL10B104KB8NNNC | C1591 | 10% | 50 V |  | X7R | no | MAIN |  | https://www.lcsc.com/datasheet/lcsc_datasheet_2304140030_Samsung-Electro-Mechanics-CL10B104KB8NNNC_C1591.pdf
C12 | 1uF | Capacitor_SMD:C_0603_1608Metric | Samsung Electro-Mechanics | CL10B105KA8NNNC | C29936 | 10% | 25 V |  | X7R | no | MAIN |  | https://www.lcsc.com/datasheet/lcsc_datasheet_2304140030_Samsung-Electro-Mechanics-CL10B105KA8NNNC_C29936.pdf
C13 | 100nF | Capacitor_SMD:C_0603_1608Metric | Samsung Electro-Mechanics | CL10B104KB8NNNC | C1591 | 10% | 50 V |  | X7R | no | MAIN |  | https://www.lcsc.com/datasheet/lcsc_datasheet_2304140030_Samsung-Electro-Mechanics-CL10B104KB8NNNC_C1591.pdf
C14 | 100nF | Capacitor_SMD:C_0603_1608Metric | Samsung Electro-Mechanics | CL10B104KB8NNNC | C1591 | 10% | 50 V |  | X7R | no | MAIN |  | https://www.lcsc.com/datasheet/lcsc_datasheet_2304140030_Samsung-Electro-Mechanics-CL10B104KB8NNNC_C1591.pdf
C15 | 1uF | Capacitor_SMD:C_0805_2012Metric | Samsung Electro-Mechanics | CL21B105KBFNNNE | C28323 | 10% | 50 V |  | X7R | no | MAIN |  | https://product.samsungsem.com/mlcc/CL21B105KBFNNN.do
C16 | 100nF | Capacitor_SMD:C_0603_1608Metric | Samsung Electro-Mechanics | CL10B104KB8NNNC | C1591 | 10% | 50 V |  | X7R | no | MAIN |  | https://product.samsungsem.com/mlcc/CL10B104KB8NNN.do
C17 | 10uF | Capacitor_SMD:C_1206_3216Metric | Samsung Electro-Mechanics | CL31B106KAHNNNE | C14860 | 10% | 25 V |  | X7R | no | MAIN |  | https://product.samsungsem.com/mlcc/CL31B106KAHNNN.do
C18 | 100nF | Capacitor_SMD:C_0603_1608Metric | Samsung Electro-Mechanics | CL10B104KB8NNNC | C1591 | 10% | 50 V |  | X7R | no | MAIN |  | https://product.samsungsem.com/mlcc/CL10B104KB8NNN.do
C19 | 10uF | Capacitor_SMD:C_1206_3216Metric | Samsung Electro-Mechanics | CL31B106KAHNNNE | C14860 | 10% | 25 V |  | X7R | no | MAIN |  | https://product.samsungsem.com/mlcc/CL31B106KAHNNN.do
C20 | 100nF | Capacitor_SMD:C_0603_1608Metric | Samsung Electro-Mechanics | CL10B104KB8NNNC | C1591 | 10% | 50 V |  | X7R | no | MAIN |  | https://product.samsungsem.com/mlcc/CL10B104KB8NNN.do
C21 | 2.2uF | Capacitor_SMD:C_0805_2012Metric | Samsung Electro-Mechanics | CL21B225KAFNNNE | C19110 | 10% | 25 V |  | X7R | no | MAIN | PN7160 AN12988 local decoupling; selected stocked prototype part is NRND; do not substitute without checking bias | https://product.samsungsem.com/mlcc/CL21B225KAFNNN.do
C22 | 2.2uF | Capacitor_SMD:C_0805_2012Metric | Samsung Electro-Mechanics | CL21B225KAFNNNE | C19110 | 10% | 25 V |  | X7R | no | MAIN | PN7160 AN12988 local decoupling; selected stocked prototype part is NRND; do not substitute without checking bias | https://product.samsungsem.com/mlcc/CL21B225KAFNNN.do
C23 | 2.2uF | Capacitor_SMD:C_0805_2012Metric | Samsung Electro-Mechanics | CL21B225KAFNNNE | C19110 | 10% | 25 V |  | X7R | no | MAIN | PN7160 AN12988 local decoupling; selected stocked prototype part is NRND; do not substitute without checking bias | https://product.samsungsem.com/mlcc/CL21B225KAFNNN.do
C24 | 2.2uF | Capacitor_SMD:C_0805_2012Metric | Samsung Electro-Mechanics | CL21B225KAFNNNE | C19110 | 10% | 25 V |  | X7R | no | MAIN | PN7160 AN12988 local decoupling; selected stocked prototype part is NRND; do not substitute without checking bias | https://product.samsungsem.com/mlcc/CL21B225KAFNNN.do
C25 | 100nF | Capacitor_SMD:C_0603_1608Metric | Samsung Electro-Mechanics | CL10B104KB8NNNC | C1591 | 10% | 50 V |  | X7R | no | MAIN |  | https://product.samsungsem.com/mlcc/CL10B104KB8NNN.do
C26 | 12pF | Capacitor_SMD:C_0603_1608Metric | Samsung Electro-Mechanics | CL10C120JB8NNNC | C38523 | 5% | 50 V |  | C0G | no | MAIN | PROTOTYPE START: 12pF/15pF pair; tune carrier to -5..0ppm per AN14518 | https://product.samsungsem.com/mlcc/CL10C120JB8NNN.do
C27 | 15pF | Capacitor_SMD:C_0603_1608Metric | Samsung Electro-Mechanics | CL10C150JB8NNNC | C1644 | 5% | 50 V |  | C0G | no | MAIN | PROTOTYPE START: 12pF/15pF pair; tune carrier to -5..0ppm per AN14518 | https://product.samsungsem.com/mlcc/CL10C150JB8NNN.do
C28 | 1nF | Capacitor_SMD:C_0805_2012Metric_Pad1.18x1.45mm_HandSolder | Murata Electronics | GRM2165C2A102JA01D | C162289 | 5% | 100 V |  | C0G/NP0 | no | MAIN | PROTOTYPE START: validate with VNA / AGC / RF stress measurements | https://www.lcsc.com/datasheet/lcsc_datasheet_2304140030_Murata-Electronics-GRM2165C2A102JA01D_C162289.pdf
C29 | 1nF | Capacitor_SMD:C_0805_2012Metric_Pad1.18x1.45mm_HandSolder | Murata Electronics | GRM2165C2A102JA01D | C162289 | 5% | 100 V |  | C0G/NP0 | no | MAIN | PROTOTYPE START: validate with VNA / AGC / RF stress measurements | https://www.lcsc.com/datasheet/lcsc_datasheet_2304140030_Murata-Electronics-GRM2165C2A102JA01D_C162289.pdf
C30 | 330pF | Capacitor_SMD:C_0805_2012Metric_Pad1.18x1.45mm_HandSolder | YAGEO | CC0805FRNPO0BN331 | C527075 | 1% | 100 V |  | C0G/NP0 | no | MAIN | PROTOTYPE: 330pF 1% + 33pF 5% in parallel = 363pF +/-1.364%; fit symmetrically; measure and retune | https://wmsc.lcsc.com/wmsc/upload/file/pdf/v2/lcsc/2005261832_YAGEO-CC0805FRNPO0BN331_C527075.pdf
C31 | 330pF | Capacitor_SMD:C_0805_2012Metric_Pad1.18x1.45mm_HandSolder | YAGEO | CC0805FRNPO0BN331 | C527075 | 1% | 100 V |  | C0G/NP0 | no | MAIN | PROTOTYPE: 330pF 1% + 33pF 5% in parallel = 363pF +/-1.364%; fit symmetrically; measure and retune | https://wmsc.lcsc.com/wmsc/upload/file/pdf/v2/lcsc/2005261832_YAGEO-CC0805FRNPO0BN331_C527075.pdf
C32 | 68pF | Capacitor_SMD:C_0805_2012Metric_Pad1.18x1.45mm_HandSolder | YAGEO | CC0805FRNPO0BN680 | C576904 | 1% | 100 V |  | C0G/NP0 | no | MAIN | PROTOTYPE START: validate with VNA / AGC / RF stress measurements | https://wmsc.lcsc.com/wmsc/upload/file/pdf/v2/lcsc/2212091030_YAGEO-CC0805FRNPO0BN680_C576904.pdf
C33 | 68pF | Capacitor_SMD:C_0805_2012Metric_Pad1.18x1.45mm_HandSolder | YAGEO | CC0805FRNPO0BN680 | C576904 | 1% | 100 V |  | C0G/NP0 | no | MAIN | PROTOTYPE START: validate with VNA / AGC / RF stress measurements | https://wmsc.lcsc.com/wmsc/upload/file/pdf/v2/lcsc/2212091030_YAGEO-CC0805FRNPO0BN680_C576904.pdf
C34 | DNP / TRIM | Nucula_Project:C_0805_HandSolder_NoPaste |  |  |  | <=2% or +/-0.1pF for small trims | 100 V |  | C0G/NP0 | yes | MAIN | DNP: fit equal pairs; 0.5-22pF typical fine trim
C35 | DNP / TRIM | Nucula_Project:C_0805_HandSolder_NoPaste |  |  |  | <=2% or +/-0.1pF for small trims | 100 V |  | C0G/NP0 | yes | MAIN | DNP: fit equal pairs; 0.5-22pF typical fine trim
C36 | 100pF | Capacitor_SMD:C_0805_2012Metric_Pad1.18x1.45mm_HandSolder | YAGEO | CC0805GRNPO0BN101 | C527192 | 2% | 100 V |  | C0G/NP0 | no | MAIN | PROTOTYPE START: validate with VNA / AGC / RF stress measurements | https://wmsc.lcsc.com/wmsc/upload/file/pdf/v2/lcsc/2005222139_YAGEO-CC0805GRNPO0BN101_C527192.pdf
C37 | 100pF | Capacitor_SMD:C_0805_2012Metric_Pad1.18x1.45mm_HandSolder | YAGEO | CC0805GRNPO0BN101 | C527192 | 2% | 100 V |  | C0G/NP0 | no | MAIN | PROTOTYPE START: validate with VNA / AGC / RF stress measurements | https://wmsc.lcsc.com/wmsc/upload/file/pdf/v2/lcsc/2005222139_YAGEO-CC0805GRNPO0BN101_C527192.pdf
C38 | DNP / TRIM | Nucula_Project:C_0805_HandSolder_NoPaste |  |  |  | <=2% or +/-0.1pF for small trims | 100 V |  | C0G/NP0 | yes | MAIN | DNP: fit equal pairs; 0.5-22pF typical fine trim
C39 | DNP / TRIM | Nucula_Project:C_0805_HandSolder_NoPaste |  |  |  | <=2% or +/-0.1pF for small trims | 100 V |  | C0G/NP0 | yes | MAIN | DNP: fit equal pairs; 0.5-22pF typical fine trim
C40 | 10uF | Capacitor_SMD:C_1206_3216Metric | Samsung Electro-Mechanics | CL31B106KAHNNNE | C14860 | 10% | 25 V |  | X7R | no | MAIN |  | https://product.samsungsem.com/mlcc/CL31B106KAHNNN.do
C41 | 22pF | Capacitor_SMD:C_0603_1608Metric | Samsung Electro-Mechanics | CL10C220JB8NNNC | C1653 | 5% | 50 V |  | C0G | no | MAIN |  | https://www.lcsc.com/datasheet/lcsc_datasheet_2304140030_Samsung-Electro-Mechanics-CL10C220JB8NNNC_C1653.pdf
C42 | 1uF | Capacitor_SMD:C_0805_2012Metric | Samsung Electro-Mechanics | CL21B105KBFNNNE | C28323 | 10% | 50 V |  | X7R | no | MAIN |  | https://product.samsungsem.com/mlcc/CL21B105KBFNNN.do
C43 | 100nF | Capacitor_SMD:C_0603_1608Metric | Samsung Electro-Mechanics | CL10B104KB8NNNC | C1591 | 10% | 50 V |  | X7R | no | MAIN |  | https://www.lcsc.com/datasheet/lcsc_datasheet_2304140030_Samsung-Electro-Mechanics-CL10B104KB8NNNC_C1591.pdf
C44 | 4.7uF | Capacitor_SMD:C_0805_2012Metric | Samsung Electro-Mechanics | CL21B475KAFNNNE | C98195 | 10% | 25 V |  | X7R | no | MAIN |  | https://product.samsungsem.com/mlcc/CL21B475KAFNNN.do
C45 | 100nF | Capacitor_SMD:C_0603_1608Metric | Samsung Electro-Mechanics | CL10B104KB8NNNC | C1591 | 10% | 50 V |  | X7R | no | MAIN |  | https://www.lcsc.com/datasheet/lcsc_datasheet_2304140030_Samsung-Electro-Mechanics-CL10B104KB8NNNC_C1591.pdf
C46 | 4.7uF | Capacitor_SMD:C_1206_3216Metric | Samsung Electro-Mechanics | CL31B475KBHNNNE | C51205 | 10% | 50 V |  | X7R | no | MAIN |  | https://product.samsungsem.com/mlcc/CL31B475KBHNNN.do
C47 | 2.2uF | Capacitor_SMD:C_0805_2012Metric | Samsung Electro-Mechanics | CL21B225KAFNNNE | C19110 | 10% | 25 V |  | X7R | no | MAIN |  | https://product.samsungsem.com/mlcc/CL21B225KAFNNN.do
C48 | 100nF | Capacitor_SMD:C_0603_1608Metric | Samsung Electro-Mechanics | CL10B104KB8NNNC | C1591 | 10% | 50 V |  | X7R | no | MAIN |  | https://www.lcsc.com/datasheet/lcsc_datasheet_2304140030_Samsung-Electro-Mechanics-CL10B104KB8NNNC_C1591.pdf
C49 | 1uF | Capacitor_SMD:C_0805_2012Metric | Samsung Electro-Mechanics | CL21B105KBFNNNE | C28323 | 10% | 50 V |  | X7R | no | MAIN |  | https://www.lcsc.com/datasheet/lcsc_datasheet_2304140030_Samsung-Electro-Mechanics-CL21B105KBFNNNE_C28323.pdf
C50 | 2.2uF | Capacitor_SMD:C_0805_2012Metric | Samsung Electro-Mechanics | CL21B225KAFNNNE | C19110 | 10% | 25 V |  | X7R | no | MAIN |  | https://www.lcsc.com/datasheet/lcsc_datasheet_2304140030_Samsung-Electro-Mechanics-CL21B225KAFNNNE_C19110.pdf
C51 | 100nF | Capacitor_SMD:C_0603_1608Metric | Samsung Electro-Mechanics | CL10B104KB8NNNC | C1591 | 10% | 50 V |  | X7R | no | BREAKAWAY_KEYBOARD |  | https://www.lcsc.com/datasheet/lcsc_datasheet_2304140030_Samsung-Electro-Mechanics-CL10B104KB8NNNC_C1591.pdf
C52 | 1uF | Capacitor_SMD:C_0805_2012Metric | Samsung Electro-Mechanics | CL21B105KBFNNNE | C28323 | 10% | 50 V |  | X7R | no | BREAKAWAY_KEYBOARD |  | https://www.lcsc.com/datasheet/lcsc_datasheet_2304140030_Samsung-Electro-Mechanics-CL21B105KBFNNNE_C28323.pdf
C53 | 33pF | Capacitor_SMD:C_0805_2012Metric_Pad1.18x1.45mm_HandSolder | YAGEO | CC0805JRNPO0BN330 | C309485 | 5% | 100 V |  | C0G/NP0 | no | MAIN | PROTOTYPE: 330pF 1% + 33pF 5% in parallel = 363pF +/-1.364%; fit symmetrically; measure and retune | https://wmsc.lcsc.com/wmsc/upload/file/pdf/v2/lcsc/2304140030_YAGEO-CC0805JRNPO0BN330_C309485.pdf
C54 | 33pF | Capacitor_SMD:C_0805_2012Metric_Pad1.18x1.45mm_HandSolder | YAGEO | CC0805JRNPO0BN330 | C309485 | 5% | 100 V |  | C0G/NP0 | no | MAIN | PROTOTYPE: 330pF 1% + 33pF 5% in parallel = 363pF +/-1.364%; fit symmetrically; measure and retune | https://wmsc.lcsc.com/wmsc/upload/file/pdf/v2/lcsc/2304140030_YAGEO-CC0805JRNPO0BN330_C309485.pdf
C55 | 100nF | Capacitor_SMD:C_0603_1608Metric | Samsung Electro-Mechanics | CL10B104KB8NNNC | C1591 | 10% | 50 V |  | X7R | no | MAIN |  | https://www.lcsc.com/datasheet/lcsc_datasheet_2304140030_Samsung-Electro-Mechanics-CL10B104KB8NNNC_C1591.pdf
D1 | B340A | Diode_SMD:D_SMA | Diodes Incorporated | B340A-13-F | C85098 |  |  | 3 A / 40 V; SMA; layout thermal derating required |  | no | MAIN |  | https://www.diodes.com/datasheet/download/B340A.pdf
D2 | B340A | Diode_SMD:D_SMA | Diodes Incorporated | B340A-13-F | C85098 |  |  | 3 A / 40 V; SMA; layout thermal derating required |  | no | MAIN |  | https://www.diodes.com/datasheet/download/B340A.pdf
D3 | CHARGE (red) | LED_SMD:LED_0603_1608Metric | Hubei KENTO Elec | KT-0603R | C2286 |  |  |  |  | no | MAIN |  | https://www.lcsc.com/datasheet/lcsc_datasheet_1810231112_Hubei-KENTO-Elec-KT-0603R_C2286.pdf
D4 | SS14 | Diode_SMD:D_SMA | Vishay Intertech | SS14-E3/61T | C47460 |  |  |  |  | no | MAIN |  | https://www.vishay.com/docs/88746/ss12.pdf
D5 | TPD1E10B06DYAR | Diode_SMD:D_SOD-523 | Texas Instruments | TPD1E10B06DYAR | C3712135 |  |  |  |  | no | MAIN |  | https://www.ti.com/lit/ds/symlink/tpd1e10b06.pdf
DS1 | SSD1309 OLED / 24-pin | Nucula_Project:Hirose_FH12A-24S-0.5SH_1x24-1MP_P0.50mm_Horizontal | HRS(Hirose) | FH12A-24S-0.5SH(55) | C506794 |  |  |  |  | no | MAIN | Top-contact socket selected for user-confirmed ribbon orientation; DS1 BOM is socket only; display and keyboard modules excluded; panel pin 1 confirmed PCB-left on 2026-10-06; validate operation on corrected board | https://www.hirose.com/en/product/p/CL0586-0555-2-55
J1 | USB4105-GF-A-120 | Nucula_Project:USB_C_GCT_USB4105_16P_Standard | Global Connector Technology | USB4105-GF-A-120 | C5184243 |  |  |  |  | no | MAIN |  | https://gct.co/files/drawings/usb4105.pdf
J2 | JST-PH / 1S Li-ion | Nucula_Project:JST_PH_B2B-PH-SM4-TB_1x02-1MP_P2.00mm_Vertical | JST | B2B-PH-SM4-TB(LF)(SN) | C160352 |  |  |  |  | no | MAIN | OPTIONAL BATTERY TEST: SMT top-entry JST-PH 2.00 mm; pin 1 BAT+, pin 2 GND; mounting tabs unconnected; USB operation does not require a battery | https://www.jst-mfg.com/product/pdf/eng/ePH.pdf
J3 | KEYBOARD / USER FIT | Connector_PinHeader_2.54mm:PinHeader_1x09_P2.54mm_Vertical |  |  |  |  |  |  |  | yes | BREAKAWAY_KEYBOARD | DNP/user-fitted 9-pin header; pins 1 and 9 isolated; 3x4 matrix on center seven
J4 | MAIN LINK / OPTIONAL | Connector_PinHeader_2.54mm:PinHeader_1x05_P2.54mm_Vertical |  |  |  |  |  |  |  | yes | MAIN
J5 | MODULE LINK / OPTIONAL | Connector_PinHeader_2.54mm:PinHeader_1x05_P2.54mm_Vertical |  |  |  |  |  |  |  | yes | BREAKAWAY_KEYBOARD
L1 | 2.2uH | Nucula_Project:L_Taiyo-Yuden_NR-30xx | Taiyo Yuden | LSXND3030QKT2R2MNG | C6980123 |  |  | Isat >=1.48 A, Irms >=1.5 A; 2.2uH +/-20% |  | no | MAIN |  | https://ds.yuden.co.jp/TYCOMPAS/eu/detail?pn=LSXND3030QKT2R2MNG&u=M
L2 | 150nH | Nucula_Project:L_Coilcraft_0805HP | Coilcraft | 0805HP-151XGRC | C20417049 | 2% |  |  |  | no | MAIN | PROTOTYPE: RF model included; 0.60A thermal reference, verify actual RF heating | https://www.coilcraft.com/en-us/products/rf/ceramic-core-chip-inductors/0805-(2012)/0805hp/0805hp-151/
L3 | 150nH | Nucula_Project:L_Coilcraft_0805HP | Coilcraft | 0805HP-151XGRC | C20417049 | 2% |  |  |  | no | MAIN | PROTOTYPE: RF model included; 0.60A thermal reference, verify actual RF heating | https://www.coilcraft.com/en-us/products/rf/ceramic-core-chip-inductors/0805-(2012)/0805hp/0805hp-151/
L4 | 10uH | Nucula_Project:L_Coilcraft_LPS4018 | Coilcraft | LPS4018-103MRC | C6127589 |  |  | Isat 1.1 A at 10% drop; Irms 0.9 A at 20 C rise |  | no | MAIN |  | https://www.coilcraft.com/en-us/products/power/shielded-inductors/ferrite-drum/lps/lps4018/lps4018-103/
Q1 | IRLML6402 | Package_TO_SOT_SMD:SOT-23 | Infineon Technologies | IRLML6402TRPBF | C2593 |  |  |  |  | no | MAIN |  | https://www.infineon.com/assets/row/public/documents/24/49/infineon-irlml6402-datasheet-en.pdf
Q2 | BSS138 | Package_TO_SOT_SMD:SOT-23 | onsemi | BSS138 | C52895 |  |  |  |  | no | MAIN |  | https://www.onsemi.com/pub/Collateral/BSS138-D.PDF
Q3 | IRLML6402 | Package_TO_SOT_SMD:SOT-23 | Infineon Technologies | IRLML6402TRPBF | C2593 |  |  |  |  | no | MAIN |  | https://www.infineon.com/dgdl/irlml6402pbf.pdf?fileId=5546d462533600a401535668d5c2263c
Q4 | BSS138 | Package_TO_SOT_SMD:SOT-23 | onsemi | BSS138 | C52895 |  |  |  |  | no | MAIN |  | https://www.onsemi.com/pub/Collateral/BSS138-D.PDF
Q5 | BSS138 | Package_TO_SOT_SMD:SOT-23 | onsemi | BSS138 | C52895 |  |  |  |  | no | MAIN |  | https://www.onsemi.com/pub/Collateral/BSS138-D.PDF
R1 | 5.1k | Resistor_SMD:R_0603_1608Metric | UNI-ROYAL(Uniroyal Elec) | 0603WAF5101T5E | C23186 | 1% |  | 0.1 W |  | no | MAIN |  | https://www.lcsc.com/datasheet/lcsc_datasheet_2206010116_UNI-ROYAL-Uniroyal-Elec-0603WAF5101T5E_C23186.pdf
R2 | 5.1k | Resistor_SMD:R_0603_1608Metric | UNI-ROYAL(Uniroyal Elec) | 0603WAF5101T5E | C23186 | 1% |  | 0.1 W |  | no | MAIN |  | https://www.lcsc.com/datasheet/lcsc_datasheet_2206010116_UNI-ROYAL-Uniroyal-Elec-0603WAF5101T5E_C23186.pdf
R3 | 10k | Resistor_SMD:R_0603_1608Metric | UNI-ROYAL(Uniroyal Elec) | 0603WAF1002T5E | C25804 | 1% |  | 0.1 W |  | no | MAIN |  | https://www.lcsc.com/datasheet/lcsc_datasheet_2206010045_UNI-ROYAL-Uniroyal-Elec-0603WAF1002T5E_C25804.pdf
R4 | 2.2k | Resistor_SMD:R_0603_1608Metric | UNI-ROYAL(Uniroyal Elec) | 0603WAF2201T5E | C4190 | 1% |  | 0.1 W |  | no | MAIN |  | https://www.lcsc.com/datasheet/lcsc_datasheet_2206010230_UNI-ROYAL-Uniroyal-Elec-0603WAF2201T5E_C4190.pdf
R5 | 10k | Resistor_SMD:R_0603_1608Metric | UNI-ROYAL(Uniroyal Elec) | 0603WAF1002T5E | C25804 | 1% |  | 0.1 W |  | no | MAIN |  | https://www.lcsc.com/datasheet/lcsc_datasheet_2206010045_UNI-ROYAL-Uniroyal-Elec-0603WAF1002T5E_C25804.pdf
R6 | 220k | Resistor_SMD:R_0603_1608Metric | YAGEO | RT0603BRD07220KL | C861231 | 0.1% |  | 0.1 W |  | no | MAIN |  | https://wmsc.lcsc.com/wmsc/upload/file/pdf/v2/lcsc/2210190000_YAGEO-RT0603BRD07220KL_C861231.pdf
R7 | 48.7k | Resistor_SMD:R_0603_1608Metric | YAGEO | RT0603BRD0748K7L | C861429 | 0.1% |  | 0.1 W |  | no | MAIN |  | https://wmsc.lcsc.com/wmsc/upload/file/pdf/v2/lcsc/2210190000_YAGEO-RT0603BRD0748K7L_C861429.pdf
R8 | 10k | Resistor_SMD:R_0603_1608Metric | UNI-ROYAL(Uniroyal Elec) | 0603WAF1002T5E | C25804 | 1% |  | 0.1 W |  | no | MAIN |  | https://www.lcsc.com/datasheet/lcsc_datasheet_2206010045_UNI-ROYAL-Uniroyal-Elec-0603WAF1002T5E_C25804.pdf
R9 | 10k | Resistor_SMD:R_0603_1608Metric | UNI-ROYAL(Uniroyal Elec) | 0603WAF1002T5E | C25804 | 1% |  | 0.1 W |  | no | MAIN |  | https://www.lcsc.com/datasheet/lcsc_datasheet_2206010045_UNI-ROYAL-Uniroyal-Elec-0603WAF1002T5E_C25804.pdf
R10 | 10k | Resistor_SMD:R_0603_1608Metric | UNI-ROYAL(Uniroyal Elec) | 0603WAF1002T5E | C25804 | 1% |  | 0.1 W |  | no | MAIN |  | https://www.lcsc.com/datasheet/lcsc_datasheet_2206010045_UNI-ROYAL-Uniroyal-Elec-0603WAF1002T5E_C25804.pdf
R11 | 10k | Resistor_SMD:R_0603_1608Metric | UNI-ROYAL(Uniroyal Elec) | 0603WAF1002T5E | C25804 | 1% |  | 0.1 W |  | no | MAIN |  | https://www.lcsc.com/datasheet/lcsc_datasheet_2206010045_UNI-ROYAL-Uniroyal-Elec-0603WAF1002T5E_C25804.pdf
R12 | 22R | Resistor_SMD:R_0603_1608Metric | UNI-ROYAL(Uniroyal Elec) | 0603WAF220JT5E | C23345 | 1% |  | 0.1 W |  | no | MAIN |  | https://www.lcsc.com/datasheet/lcsc_datasheet_2206010100_UNI-ROYAL-Uniroyal-Elec-0603WAF220JT5E_C23345.pdf
R13 | 22R | Resistor_SMD:R_0603_1608Metric | UNI-ROYAL(Uniroyal Elec) | 0603WAF220JT5E | C23345 | 1% |  | 0.1 W |  | no | MAIN |  | https://www.lcsc.com/datasheet/lcsc_datasheet_2206010100_UNI-ROYAL-Uniroyal-Elec-0603WAF220JT5E_C23345.pdf
R14 | 100R | Resistor_SMD:R_0603_1608Metric | UNI-ROYAL(Uniroyal Elec) | 0603WAF1000T5E | C22775 | 1% |  | 0.1 W |  | no | MAIN |  | https://www.lcsc.com/datasheet/lcsc_datasheet_2411221126_UNI-ROYAL-Uniroyal-Elec-0603WAF1000T5E_C22775.pdf
R15 | 470k | Resistor_SMD:R_0603_1608Metric | UNI-ROYAL(Uniroyal Elec) | 0603WAF4703T5E | C23178 | 1% |  | 0.1 W |  | no | MAIN |  | https://www.lcsc.com/datasheet/lcsc_datasheet_2206010116_UNI-ROYAL-Uniroyal-Elec-0603WAF4703T5E_C23178.pdf
R16 | 470k | Resistor_SMD:R_0603_1608Metric | UNI-ROYAL(Uniroyal Elec) | 0603WAF4703T5E | C23178 | 1% |  | 0.1 W |  | no | MAIN |  | https://www.lcsc.com/datasheet/lcsc_datasheet_2206010116_UNI-ROYAL-Uniroyal-Elec-0603WAF4703T5E_C23178.pdf
R17 | 10k | Resistor_SMD:R_0603_1608Metric | UNI-ROYAL(Uniroyal Elec) | 0603WAF1002T5E | C25804 | 1% |  | 0.1 W |  | no | MAIN |  | https://www.lcsc.com/datasheet/lcsc_datasheet_2206010045_UNI-ROYAL-Uniroyal-Elec-0603WAF1002T5E_C25804.pdf
R18 | 10k | Resistor_SMD:R_0603_1608Metric | UNI-ROYAL(Uniroyal Elec) | 0603WAF1002T5E | C25804 | 1% |  | 0.1 W |  | no | MAIN |  | https://www.lcsc.com/datasheet/lcsc_datasheet_2206010045_UNI-ROYAL-Uniroyal-Elec-0603WAF1002T5E_C25804.pdf
R19 | 2.2k | Resistor_SMD:R_0603_1608Metric | UNI-ROYAL(Uniroyal Elec) | 0603WAF2201T5E | C4190 | 1% |  | 0.1 W |  | no | MAIN |  | https://www.lcsc.com/datasheet/lcsc_datasheet_2206010230_UNI-ROYAL-Uniroyal-Elec-0603WAF2201T5E_C4190.pdf
R20 | 2.2k | Resistor_SMD:R_0603_1608Metric | UNI-ROYAL(Uniroyal Elec) | 0603WAF2201T5E | C4190 | 1% |  | 0.1 W |  | no | MAIN |  | https://www.lcsc.com/datasheet/lcsc_datasheet_2206010230_UNI-ROYAL-Uniroyal-Elec-0603WAF2201T5E_C4190.pdf
R21 | 10k | Resistor_SMD:R_0603_1608Metric | UNI-ROYAL(Uniroyal Elec) | 0603WAF1002T5E | C25804 | 1% |  | 0.1 W |  | no | MAIN |  | https://www.lcsc.com/datasheet/lcsc_datasheet_2206010045_UNI-ROYAL-Uniroyal-Elec-0603WAF1002T5E_C25804.pdf
R22 | 100k | Resistor_SMD:R_0603_1608Metric | UNI-ROYAL(Uniroyal Elec) | 0603WAF1003T5E | C25803 | 1% |  | 0.1 W |  | no | MAIN |  | https://www.lcsc.com/datasheet/lcsc_datasheet_2206010045_UNI-ROYAL-Uniroyal-Elec-0603WAF1003T5E_C25803.pdf
R23 | 100k | Resistor_SMD:R_0603_1608Metric | UNI-ROYAL(Uniroyal Elec) | 0603WAF1003T5E | C25803 | 1% |  | 0.1 W |  | no | MAIN |  | https://www.lcsc.com/datasheet/lcsc_datasheet_2206010045_UNI-ROYAL-Uniroyal-Elec-0603WAF1003T5E_C25803.pdf
R24 | 100k | Resistor_SMD:R_0603_1608Metric | UNI-ROYAL(Uniroyal Elec) | 0603WAF1003T5E | C25803 | 1% |  | 0.1 W |  | no | MAIN |  | https://www.lcsc.com/datasheet/lcsc_datasheet_2206010045_UNI-ROYAL-Uniroyal-Elec-0603WAF1003T5E_C25803.pdf
R25 | 2.2k | Resistor_SMD:R_0805_2012Metric_Pad1.20x1.40mm_HandSolder | UNI-ROYAL(Uniroyal Elec) | 0805W8F2201T5E | C17520 | 1% |  | 0.125 W |  | no | MAIN | PROTOTYPE: tune equal RX resistors for AGC 500-800 decimal | https://www.lcsc.com/datasheet/lcsc_datasheet_2206010200_UNI-ROYAL-Uniroyal-Elec-0805W8F2201T5E_C17520.pdf
R26 | 2.2k | Resistor_SMD:R_0805_2012Metric_Pad1.20x1.40mm_HandSolder | UNI-ROYAL(Uniroyal Elec) | 0805W8F2201T5E | C17520 | 1% |  | 0.125 W |  | no | MAIN | PROTOTYPE: tune equal RX resistors for AGC 500-800 decimal | https://www.lcsc.com/datasheet/lcsc_datasheet_2206010200_UNI-ROYAL-Uniroyal-Elec-0805W8F2201T5E_C17520.pdf
R27 | 2.7R | Resistor_SMD:R_1206_3216Metric_Pad1.30x1.75mm_HandSolder | Vishay Intertech | CRCW12062R70FKEAHP | C2079511 | 1% |  | 0.75 W P70 only with Rth <=110 K/W; limit to 0.5W pending thermal validation |  | no | MAIN | PROTOTYPE: Q about 20; also lift to measure bare antenna | https://www.vishay.com/docs/20043/crcwhpe3.pdf
R28 | 2.7R | Resistor_SMD:R_1206_3216Metric_Pad1.30x1.75mm_HandSolder | Vishay Intertech | CRCW12062R70FKEAHP | C2079511 | 1% |  | 0.75 W P70 only with Rth <=110 K/W; limit to 0.5W pending thermal validation |  | no | MAIN | PROTOTYPE: Q about 20; also lift to measure bare antenna | https://www.vishay.com/docs/20043/crcwhpe3.pdf
R29 | 0R | Resistor_SMD:R_0603_1608Metric | UNI-ROYAL(Uniroyal Elec) | 0603WAF0000T5E | C21189 | 1% |  | 0.1 W |  | no | MAIN |  | https://www.lcsc.com/datasheet/lcsc_datasheet_2411221126_UNI-ROYAL-Uniroyal-Elec-0603WAF0000T5E_C21189.pdf
R30 | 1.8M | Resistor_SMD:R_0805_2012Metric | TE Connectivity | CPF0805B1M8E | C2088132 | 0.1% |  | 0.1 W; 100 V; 25 ppm/K |  | no | MAIN |  | https://wmsc.lcsc.com/wmsc/upload/file/pdf/v2/lcsc/2304140030_TE-Connectivity-CPF0805B1M8E_C2088132.pdf
R31 | 200k | Resistor_SMD:R_0603_1608Metric | YAGEO | RT0603BRD07200KL | C728585 | 0.1% |  | 0.1 W |  | no | MAIN |  | https://wmsc.lcsc.com/wmsc/upload/file/pdf/v2/lcsc/2304140030_YAGEO-RT0603BRD07200KL_C728585.pdf
R32 | 910k | Resistor_SMD:R_0603_1608Metric | UNI-ROYAL(Uniroyal Elec) | 0603WAF9103T5E | C23263 | 1% |  | 0.1 W |  | no | MAIN |  | https://www.lcsc.com/datasheet/lcsc_datasheet_2206010100_UNI-ROYAL-Uniroyal-Elec-0603WAF9103T5E_C23263.pdf
R33 | 100k | Resistor_SMD:R_0603_1608Metric | UNI-ROYAL(Uniroyal Elec) | 0603WAF1003T5E | C25803 | 1% |  | 0.1 W |  | no | MAIN |  | https://www.lcsc.com/datasheet/lcsc_datasheet_2206010045_UNI-ROYAL-Uniroyal-Elec-0603WAF1003T5E_C25803.pdf
R34 | 100k | Resistor_SMD:R_0603_1608Metric | UNI-ROYAL(Uniroyal Elec) | 0603WAF1003T5E | C25803 | 1% |  | 0.1 W |  | no | MAIN |  | https://www.lcsc.com/datasheet/lcsc_datasheet_2206010045_UNI-ROYAL-Uniroyal-Elec-0603WAF1003T5E_C25803.pdf
R35 | 10k | Resistor_SMD:R_0603_1608Metric | UNI-ROYAL(Uniroyal Elec) | 0603WAF1002T5E | C25804 | 1% |  | 0.1 W |  | no | MAIN |  | https://www.lcsc.com/datasheet/lcsc_datasheet_2206010045_UNI-ROYAL-Uniroyal-Elec-0603WAF1002T5E_C25804.pdf
R36 | 100k | Resistor_SMD:R_0603_1608Metric | UNI-ROYAL(Uniroyal Elec) | 0603WAF1003T5E | C25803 | 1% |  | 0.1 W |  | no | MAIN |  | https://www.lcsc.com/datasheet/lcsc_datasheet_2206010045_UNI-ROYAL-Uniroyal-Elec-0603WAF1003T5E_C25803.pdf
R37 | 10k | Resistor_SMD:R_0603_1608Metric | UNI-ROYAL(Uniroyal Elec) | 0603WAF1002T5E | C25804 | 1% |  | 0.1 W |  | no | BREAKAWAY_KEYBOARD |  | https://www.lcsc.com/datasheet/lcsc_datasheet_2206010045_UNI-ROYAL-Uniroyal-Elec-0603WAF1002T5E_C25804.pdf
R38 | 4.7k | Resistor_SMD:R_0603_1608Metric |  |  |  | 1% |  | 0.1 W |  | yes | BREAKAWAY_KEYBOARD
R39 | 4.7k | Resistor_SMD:R_0603_1608Metric |  |  |  | 1% |  | 0.1 W |  | yes | BREAKAWAY_KEYBOARD
R40 | 100k | Resistor_SMD:R_0603_1608Metric | UNI-ROYAL(Uniroyal Elec) | 0603WAF1003T5E | C25803 | 1% |  | 0.1 W |  | no | MAIN |  | https://www.lcsc.com/datasheet/lcsc_datasheet_2206010045_UNI-ROYAL-Uniroyal-Elec-0603WAF1003T5E_C25803.pdf
R41 | 0R | Resistor_SMD:R_0805_2012Metric_Pad1.20x1.40mm_HandSolder | YAGEO | RC0805JR-070RL | C96345 | Jumper |  | Jumper: 2 A rated; initial R <50 mOhm; 0.125 W package |  | no | MAIN | FIT: remove along with R42/R25/R26 for isolated full RF-tree VNA measurement | https://www.lcsc.com/datasheet/lcsc_datasheet_2304140030_YAGEO-RC0805JR-070RL_C96345.pdf
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

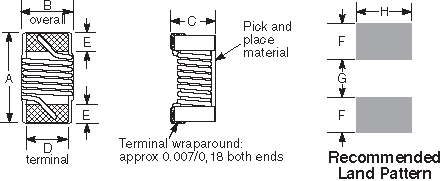
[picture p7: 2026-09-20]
parts documentation/Coilcraft-0805HP-land-pattern.png

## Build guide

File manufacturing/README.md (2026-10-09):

# Manufacturing release

**Latest package: [production-2026-10-09-package.zip](production-2026-10-09-package.zip).**

Prepared for five engineering prototypes. Use only the files from this release together.

- [Production instructions](production-2026-10-09/README.md)
- [Gerbers for PCB fabrication](production-2026-10-09/nucula-v2-gerbers.zip)
- [Assembly BOM](production-2026-10-09/assembly/jlcpcb-bom.csv)
- [Placement CPL](production-2026-10-09/assembly/jlcpcb-cpl.csv)
- [Package checksum](production-2026-10-09-package.zip.sha256)

Required fabrication settings: black mask, ENIG, JLC04161H-3313 stackup,
and filled/capped vias. All 119 placement anchors and 413 assembly pad
coordinates were independently checked. Physical NFC/USB/display qualification
and supplier CAM/assembly review remain separate from the completed file checks.

Older packages have been removed from this directory to avoid mixing releases.

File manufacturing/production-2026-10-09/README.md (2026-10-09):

# Production package — 9 October 2026

Release `production-2026-10-09` is prepared for **five engineering prototypes**
from the current design, including the battery cable notch and latest artwork.
Use only files from this package together. This package supersedes the 8 October release because four BOM lines became unavailable.
Use its updated BOM and source together; do not substitute an older BOM.

## Files to send

| Purpose | File |
|---|---|
| PCB fabrication | `nucula-v2-gerbers.zip` |
| Assembly BOM | `assembly/jlcpcb-bom.csv` |
| Placement | `assembly/jlcpcb-cpl.csv` |
| Assembly drawing | `drawings/assembly-top.pdf` |
| Enlarged anchor and pad-number reference | `drawings/placement-reference.pdf` |
| Independent placement evidence | `assembly/placement-audit.csv`, `assembly/pad-coordinates.csv` |
| Fabrication outline and layers | `drawings/fabrication-outline.pdf`, `drawings/layers.pdf` |
| Editable source and libraries | `nucula-v2-design-snapshot.zip` |
| Integrity and validation | `manifest.json`, `validation/` |

The BOM and CPL describe **119 fitted components per board, all on top**.
Order five assemblies with the single-board files. A1, J6, H1–H6, mouse bites,
and DNP components are excluded. The display panel, battery, mounting hardware
and optional keyboard headers are not purchased by this BOM. Inventory is a
dated observation, not reserved stock; exact-part availability is settled by
the supplier's BOM matching. The four new selections are listed for SMT assembly on JLC detail pages. U3 assembly-service eligibility still needs supplier confirmation.

## Mandatory fabrication instructions

| Setting | Required value |
|---|---|
| Board | Four-layer FR-4, 60 × 110 mm envelope, nominal 1.6 mm |
| Stackup | **JLC04161H-3313, as submitted for rev A**; retain the Gerber job material stack |
| Copper | 1 oz outer, 0.5 oz inner |
| Finish / mask / legend | ENIG / **black** / white, matching rev A |
| Via treatment | **Epoxy filled and copper capped** for all 0.20 / 0.30 / 0.40 mm plated round holes; preserve supplied mask openings |
| Smallest via | 0.20 mm hole / 0.45 mm land; restored NFC via-in-pad requires filling/capping |
| USB mounting slots | Four plated routed slots, 0.70 mm wide |
| Mounting holes | Six 2.2 mm NPTH, M2 clearance; no plating or countersink |
| Stencil | 100 µm, top only, using supplied F.Paste |
| Test | Electrical test required |
| Delivery | Keyboard remains attached; supplier may add assembly rails/fiducials outside finished outline |

**Do not use the earlier ordinary/open-via or generic-stackup instructions.**
Do not substitute ink plugging for filled/capped via-in-pad. Do not resize,
retune or reroute the NFC antenna, matching tree, controller, crystal or local
vias. No copper thieving, test pads, order markings or supplier-added metal
inside or beside the antenna. Preserve all four-layer NFC copper exclusions.
The supplied board has no blanket controlled-impedance certification. Any
supplier USB impedance proposal must avoid changing the frozen NFC geometry.

JLCPCB's [via-covering instructions](https://jlcpcb.com/help/article/pcb-via-covering)
distinguish filled/capped processing from ink plugging. This package preserves
the recorded rev-A manufacturing specification; actual supplier CAM changes
on the previous physical boards are not available in the repository.

## Placement instructions — prevent the previous offset error

CPL X/Y use **native KiCad footprint anchors**, relative to (50,160) mm with
positive Y upward. Rotations are native KiCad angles normalized to 0–360°.
There are **no body-center offsets or unverified angle corrections**.
Every CPL row is independently compared with the source PCB; pad coordinates
are independently compared with exported copper. Do not apply the earlier
ESP32 +3.10 mm X, display +1.90 mm Y, or battery −1.75 mm X shifts.

Before the supplier releases its assembly job, check its **2D lead-to-pad
alignment** for all parts, especially U3, DS1, J2, U6, U4 and U10. Align actual
pin numbers, not a 3D body center. Supplier catalogue model anchors cannot be
certified from local files; use the supplied audit and pad table to resolve
any supplier-specific discrepancy.

- **U3:** ESP32-C3-MINI-1-H4X, **C41349510**. WROOM-02 is incompatible. Antenna points
  right and is flush with the cutout. Pad 49 is masked with no paste; perimeter
  ground pads are soldered. Use compatible ESP32-C3 revision-1.1 firmware.
- **DS1:** FH12A-24S-0.5SH(55), **C506794**, top-contact socket. The corrected mounted
  panel relationship is panel pin n = socket pad 25−n. Do not renumber or rotate
  the footprint to “correct” this intended reversal.
- **J2:** JST SM02B-SRSS-TB(LF)(SN), **C160402**, side entry, 1 mm pitch. Opening faces
  left, toward the cable notch. CPL X=7.700 mm, Y=59.100 mm, rotation=270°.
  Positive pad 1 is (9.700,59.600); ground pad 2 is (9.700,58.600) mm.
  SHR-02V-S-B mating lead; the old PH plug does not fit. Verify lead polarity.
- **J6:** hand-solder battery lands only. Left pad is GND; right pad is BAT+.
  No component or stencil paste. Use J2 or J6 for one battery connection.

## Validation and scope

Native ERC: zero violations. Native PCB DRC: zero errors, zero unconnected
items, zero schematic-parity findings. The 33 warnings are 32 reviewed library
footprint differences and one clipped R17 silkscreen reference. Export subtracts
solder mask from silkscreen. These warnings do not alter placement coordinates.

The NFC antenna, all pad positions/shapes, the 366 local tracks/vias, matching
values, stackup and via process remain those of submitted rev A. Independent
Gerber readback compares all four copper layers and both mask layers with rev A.
The seven feeders remain identical through the NFC area; remote routing differs.

The user explicitly authorized a different RF part after revalidation. Four
purchasing substitutions affect 19 placements:

| References | New part | JLC code | Change |
|---|---|---|---|
| C10/C11/C13/C14/C16/C18/C20/C25/C43/C45/C48/C51/C55 | Samsung CL10B104KB8NNNL | C913912 | Same 100 nF/50 V/X7R/10%/0603 component, different reel packaging |
| C28/C29 | Yageo CC0805JRNPO0BN102 | C326940 | Same 1 nF/100 V/C0G/5%/0805 ratings |
| C36/C37 | Fenghua 0805CG101F101NT | C464454 | Same 100 pF/100 V/C0G/0805; tolerance tightened from 2% to 1% |
| L2/L3 | Coilcraft 0805CS-151XGLC | C38190612 | 150 nH/2%; different RF loss, 0.40 A DC thermal reference |

L2/L3 use a dedicated body drawing on retained rev-A lands. Keep their existing
CPL anchors and rotations. The L termination is RoHS compliant silver/palladium/
platinum glass frit, **not halogen-free**. No automatic substitution of other
Coilcraft suffixes is permitted. The custom land pattern covers the terminal
contact regions but is not the CS datasheet's recommended land pattern; inspect
solder joints during first-article assembly.

Paired manufacturer-model screening compares the original and replacement
inductors without changing matching values. Nominal impedance moves from
18.84 − j0.14 Ω to 19.88 − j0.11 Ω; modeled coil current falls about 5.2%.
The separate qualification report records 237 paired cases (474 ngspice runs),
component stress, harmonic loss estimates, explicit acceptance limits and source
hashes. Those engineering limits are not NXP certification requirements.
**The replacement has not been tested on hardware.** Rev-A's demonstrated read
range and no-tuning behavior cannot be guaranteed for this new BOM. Verify NFC
operation, range, AGC and inductor temperature on the first assembled boards.

The strict routing report retains rev-A NFC findings (seven non-45° tracks,
12 shallow endpoints, five weak-connectivity groups, one duplicate and 22 short
segments) because changing them would violate the requested proven-layout
freeze. Each retained finding is reproduced on identical baseline copper;
**no new routing findings are accepted**. Both raw and regression reports are
included. Native clearance/connectivity DRC passes without excluding these items.

**261 preflight SPICE cases, 57 USB-backfeed cases and 474 paired RF substitution
cases completed without solver errors**, with current input hashes, circuit decks and logs included. The
independent full/half-circuit NFC numerical comparison and 12 native antenna
keepout fixtures also pass. These cover
passive NFC sensitivity, I²C, reset/ADC RC timing, ideal converter DC setpoints
and modeled USB isolation/backfeed. They are not a full assembled-board
simulation, switching-converter stability analysis, USB compliance test or
full-board RF field simulation.

Use I²C at 100 kHz within the 400 pF modeled budget; allow 200 ms initial battery
ADC settling. The modeled 600 pF bus deliberately exceeds the rise-time limit.
USB copper lengths are D− 63.5329 mm / D+ 53.1877 mm; two of 2,097 sampled
reference-plane points are uncovered. These remain documented advisories; revised
USB enumeration/reconnection, ESD, display operation and power transients need
physical bring-up. Use the established dedicated 5 V / at least 1.5 A supply.
Check NFC production repeatability with the same tags/setup as rev A. No matching
values were retuned in this release; physical validation may reveal adjustments.

The package is ready for supplier upload and CAM/assembly review. No order has
been placed and no supplier preview approval is claimed. Bench qualification
of the changed hardware remains distinct from production-file readiness.

## Reproduce this release

Use KiCad 10's pcbnew-enabled Python for the native board checks and exporter,
and a Python environment with `tools/nfc/requirements.txt` plus Gerbonara 1.5.0
for numerical and Gerber checks. Run the schematic check before simulations;
refill the board, then run native DRC with schematic parity before geometry checks.
Run `check_nfc_rev_a.py`, `check_pcb_layout.py --drc docs/pcb/drc.json`,
`check_mini_module.py`, `check_mounting_holes.py`, `check_battery_connector.py`,
`check_standard_fabrication.py`, `export_routing_geometry.py`, then
`check_release_routing.py`. Repeat the display/USB/component/assembly checks and
both simulation scripts and `tools/nfc/qualify_substitution.py`. `check_nfc_gerbers.py` additionally reads the historical
submitted rev-A Gerbers from the repository.

Set `VALIDATION_PYTHON` to the numerical environment's Python when running
`tools/export_standard_fabrication.py` with KiCad Python. The exporter refuses
stale evidence, runs independent Gerber/NFC/placement readback, hashes every
file and creates both ZIPs. Finish with
`python tools/verify_production_package.py manufacturing/production-2026-10-09`.
Existing packages are not overwritten; choose a new release identifier for
subsequent exports. Archived regression-only checks for superseded display/USB
revisions are not current-release acceptance tests.

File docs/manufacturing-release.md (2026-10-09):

# Standard fabrication release — five bare boards

**Superseded for the current order:** use [production-2026-10-08](production-release.md), which restores rev-A NFC and requires its filled/capped vias, black mask and JLC04161H-3313 stackup. The specifications below describe earlier releases.

Current MCU revision (8 October 2026): **ESP32-C3-MINI-1-H4X / C41349510**.
The antenna is flush with the right PCB edge; the smaller milled notch includes
1 mm side clearance and 0.5 mm internal corner radii. GPIO functions and the
display/USB/battery corrections remain. [Compatibility and verification](esp32-mini.md).
Use **mounting-2026-10-08** for the current board, including six M2 mounting holes.
The earlier MINI package has no mounting holes; older packages use WROOM-02.

**Historical release — do not use for the October correction.** This package
predates the confirmed display reversal and retains the USB backfeed path.
The [editable design and bench follow-up](bringup/rev-b-display-and-usb.md)
supersede its wiring. The new [October prototype package](../manufacturing/mounting-2026-10-08-package.zip)
includes those corrections, [side-entry J2 and direct wire pads J6](battery-connector.md); see its
[current assembly instructions](../manufacturing/mounting-2026-10-08/README.md).
The rest of this page documents the September archive.

22 September 2026 · `routing-review-2026-09-22` · manual top-side reflow assembly

The archived [complete package](../manufacturing/routing-review-2026-09-22-package.zip) includes
its [Gerber ZIP](../manufacturing/routing-review-2026-09-22/nucula-v2-gerbers.zip).
This revision includes the connector-width ribbon access area and ordinary
unfilled through-vias, with the free-form routing regression repaired throughout
the board. [Routing review and validation](routing-review.md) ·
[Retained fabrication changes](standard-fabrication.md).

| Order field | Selection |
|---|---|
| Quantity | Five bare PCBs |
| Construction | Four-layer FR-4, nominal 1.6 mm, supplier standard stackup/tolerances |
| Size | 60 × 110 mm finished envelope |
| Copper | 1 oz outer; supplier standard inner copper |
| Mask / legend / finish | Green / white / ENIG |
| Via treatment | Ordinary open through-vias; no filling, capping or plugging |
| Minimum routing via | 0.30 mm finished hole / 0.70 mm land |
| Routing / net clearance | 0.15 mm / 0.20 mm |
| NPTH copper clearance | At least 0.25 mm |
| Plated USB slots | 0.70 mm wide, at least 0.30 mm annular ring |
| Impedance | No controlled impedance or custom dielectric requirement |
| Electrical test | Required |
| Keyboard | Delivered attached; preserve the functional bridge and mouse bites |
| Stencil | One 100 µm top stencil from included F.Paste; arrange holder size for the lab |

The ZIP contains four copper layers, both masks and legends, top paste, outline,
separate plated/nonplated Excellon drill files and a Gerber job file. The job
records layer order and nominal thickness, without individual custom material
stack dimensions. Plated slots
are Excellon routed ovals. Drill maps are kept outside the upload ZIP. Bottom
paste is absent because all components are on top. DNP and ESP32 centre paste
are omitted; the PN7160 exposed pad remains soldered.

The package provides 116 updated top placements, the engineering BOM, a
five-board purchasing list, IPC-D-356 netlist and assembly/layer/outline drawings.
The purchasing list retains the earlier LCSC/Mouser sourcing proposal and its
explicit substitution notes. Those observations are not a reservation or a
confirmed delivery date. The engineering BOM retains its original exact MPNs.
[Private-customer sourcing plan](../manufacturing/contingency-2026-09-22/README.md).
Use the new Gerbers, stencil and drawings with that plan.

[Assembly drawing](../manufacturing/routing-review-2026-09-22/drawings/assembly-top.pdf) ·
[Layer review PDF](../manufacturing/routing-review-2026-09-22/drawings/layers.pdf) ·
[Fabrication outline](../manufacturing/routing-review-2026-09-22/drawings/fabrication-outline.pdf)

Local checks pass with zero ERC/DRC errors and zero unconnected or parity
findings. Forty documented cosmetic DRC warnings remain; the legend is clipped
against mask in the Gerbers. The validation directory includes the exact reports,
board hashes, footprint-geometry audit, six passing routing-quality checks and
261-case partial simulation results. USB length skew and reference-plane
coverage remain advisory findings, documented in the routing review.
`manifest.json` records SHA-256 hashes for the package contents. Supplier CAM
acceptance, the retained keyboard breakaway, connector-fit testing and physical
bring-up are not established by these software checks.

Regenerate after repeating the checks described in [PCB layout](pcb-layout.md):

```sh
python3 tools/export_standard_fabrication.py
```

Use KiCad's `pcbnew`-enabled Python. The exporter rejects stale board, routing
audit, schematic or simulation results. `validation/export-board.kicad_pcb` is a derived plotting
copy with the (50, 160) mm drill/placement origin and DNP paste omissions; edit
the root project instead.

The [JLCPCB r2 archive](../manufacturing/jlcpcb-2026-09-21-r2-package.zip) remains
unchanged and records the board already sent to manufacturing. Its black-mask,
filled-via/custom-stackup instructions apply only to that archived order.
[Historical r2 instructions](jlcpcb-r2-release.md).
The first `standard-2026-09-22` package is also retained as a superseded archive;
use the routing-review package for new orders.

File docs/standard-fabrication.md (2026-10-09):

# Standard-fabrication revision and OLED ribbon access

**Superseded for the current order:** use [production-2026-10-08](production-release.md), which restores rev-A NFC and requires its filled/capped vias, black mask and JLC04161H-3313 stackup. The specifications below describe earlier releases.

The current release is **mounting-2026-10-08**, adding [six M2 mounting holes](mounting-holes.md). The MINI revision adds the smaller
ESP32-C3-MINI-1-H4X and flush antenna cutout; see [MINI checks](esp32-mini.md).
The sections below also retain the September fabrication history. It retains the fabrication
and placement changes below and repairs the routing regression introduced with
them. [Routing review, before/after comparison and current validation](routing-review.md).

This revision is for five bare boards and manual top-side reflow assembly. It
replaces the filled/capped-via fabrication specification for new contingency
orders. The JLCPCB r2 order already submitted uses its archived files.

The OLED connector DS1 remains at (80.00, 108.85) mm, rotated 180°. A **17.70 ×
5.00 mm component keepout** sits immediately above its open-latch courtyard,
toward the antenna: x = 71.15–88.85 mm, y = 98.55–103.55 mm. KiCad forbids front
footprints there. An independent check also tests component courtyards against
the rectangle. Copper, tracks and vias are permitted. This is installation
clearance, not a measured flex bend-radius or enclosure fit guarantee.

Nineteen components move. C3/C4/C6, L1, U2 and R6/R7 move above the access area;
C43 moves to its left; R35/C48/R36 move to the connector's right. U6 and C21/C23
move farther toward the top of the antenna aperture to give the larger vias
space to escape. R21/R23/R24 shift left, and C15/C17 move to make room for
ordinary via lands and soldermask separation. Exact before/after positions are in `pcb/standard-changes.json`.
Values, manufacturer part numbers and the 116 populated placements per board
are unchanged. Connector positions, the antenna copper, matching-tree symmetry,
board outline and five functional breakaway crossings remain constrained.

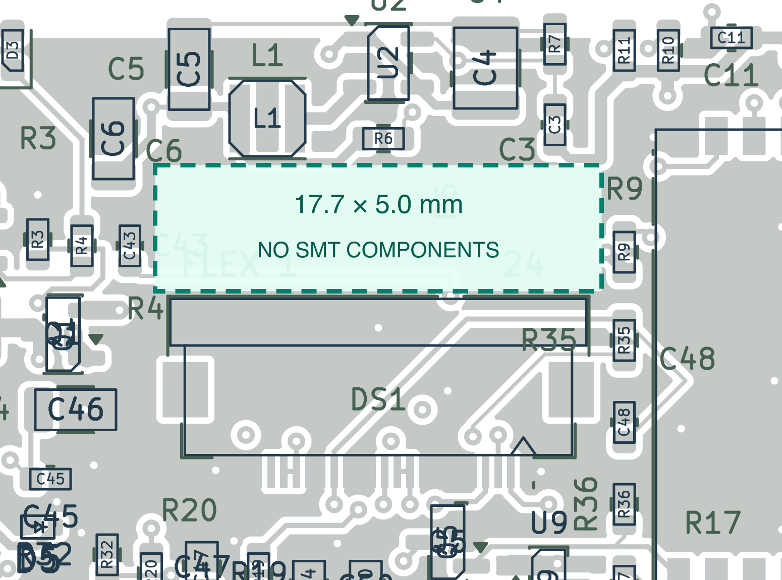
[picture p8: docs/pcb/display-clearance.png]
Ribbon insertion clearance


[Complete five-board package](../manufacturing/routing-review-2026-09-22-package.zip) ·
[Order settings](manufacturing-release.md) · [Current board view](pcb/top.svg)

## Fabrication changes

| Feature | Current specification |
|---|---|
| Board | Four layers, nominal 1.6 mm FR-4; supplier standard stackup and tolerances |
| Copper | 1 oz outer, supplier standard inner copper |
| Mask / legend / finish | Green / white / ENIG |
| Routing vias | 0.30 mm finished holes, 0.70 mm lands; ordinary open through-vias |
| Via treatment | No filling, capping, plugging or custom via-in-pad process |
| Tracks / net clearance | At least 0.15 mm / 0.20 mm |
| NPTH-to-copper clearance | At least 0.25 mm |
| USB shell slots | 0.70 mm width, at least 0.30 mm annular ring |
| Impedance | No controlled-impedance order or custom dielectric requirement |
| Assembly | All parts on top; 100 µm top stencil, DNP paste omitted |

The MINI-1 module's optional centre solder joint is omitted. Its pad 49 remains
GND copper under soldermask, with no paste or thermal-hole array. All 21
perimeter GND pads remain soldered. Espressif permits omission of the centre solder
joint; the altered thermal path still requires prototype temperature checks.
See the [ESP32-C3-MINI-1 datasheet, peripheral schematic notes](https://documentation.espressif.com/esp32-c3-mini-1_datasheet_en.pdf#page=34).
The PN7160 exposed pad remains soldered, without vias in its wettable pad.

J1 still uses GCT USB4105-GF-A-120. Its custom `_Standard` footprint retains the
slot centres and peg holes from the GCT drawing. The four plated slots widen
from 0.60 to 0.70 mm and their copper lands widen to 1.30 mm. The four outer GND
lands become 0.60 × 1.05 mm at local y = −3.73 mm, preserving their outer toe
edge and shortening the hole-facing heel another 0.06 mm from r2. This provides
ordinary 0.25 mm NPTH clearance. It is a project land-pattern adaptation; the
physical connector fit and solder joint have not been bench-tested.

These dimensions are intended to fit common prototype processes. Representative
published limits are [Eurocircuits PCBProto](https://www.eurocircuits.com/services/pcb-proto/)
and [AISLER four-layer ENIG rules](https://community.aisler.net/t/4-layer-35-m-enig-design-rules/3733),
checked 22 September 2026. Supplier CAM acceptance, available service options
and delivery times are not established by a local DRC pass. The retained
functional keyboard breakaway is still an outline feature a supplier may review.

## Verification and model limits

Final checks on 22 September 2026:

- Schematic ERC: **0 violations**; 128 physical components and 91 nets verified.
- Native PCB DRC: **0 errors, 0 unconnected items, 0 schematic-parity findings**;
  no dangling copper or component courtyard collisions.
- **21 layout checks and 16 standard-fabrication checks pass**, including the
  empty ribbon area, unchanged coil/outline, net membership and open-via clearance.
- **Six routing-quality checks pass** after the subsequent routing repair;
  pad/via entries are substantial and trace joins meet at their centrelines.
- **261 scoped ngspice cases complete with no solver errors**. The existing
  400 pF I²C load ceiling and 200 ms ADC settling recommendation remain.
- Component/footprint and five-board assembly audits pass: 116 populated parts
  per board, 55 distinct BOM lines. Stock observations are dated, not reservations.

The native report retains **40 cosmetic warnings**: 37 footprint-library
mismatches solely from clipping front legend around the open vias, two existing
ESP32 legend/edge warnings at its overhang, and one preserved back-artwork/mask
overlap. Export subtracts soldermask from legend. The
[silk audit](pcb/standard-silk-audit.json) independently hashes every footprint's
non-legend geometry to verify that the clipping changed no pads, courtyards,
models or embedded rules.

[Native DRC](pcb/drc.json) · [Layout checks](pcb/layout-check.json) ·
[Fabrication checks](pcb/standard-fabrication-check.json) ·
[Schematic verification](verification.json) · [Simulation results](simulation/results.json)

Native KiCad DRC refills the copper zones and checks all track errors and
schematic parity. `check_pcb_layout.py` separately checks placements, logical
nets, values, antenna/outline preservation, RF symmetry, pour exclusions and
breakaway geometry. `check_standard_fabrication.py` checks the cable keepout,
via/pad separation, USB slots, ESP32 land change and fabrication settings.

The USB trace-length and reference-plane observations are still reported but
are advisory for this revision, following the requested scope. Supplier stackup
changes are not compensated by an impedance optimization.

The electrical preflight reruns 261 scoped ngspice cases using the saved design's
values and verified connectivity: NFC passive-network sensitivity, I²C rise
times, RC timing and converter DC setpoints. The report records source hashes.
These models do not extract the new PCB's parasitics or simulate complete ICs,
USB signal integrity, RF radiation, switching startup, thermals or firmware.
See [simulation findings and assumptions](simulation/README.md).

Historical `check_top_contact_update.py` and `check_usb_clearance.py` test isolated
changes against earlier locked boards. They are historical regression records;
the current checks above cover this broader authorized revision.

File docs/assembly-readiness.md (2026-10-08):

# Component and footprint readiness

Current MCU revision (8 October 2026): **ESP32-C3-MINI-1-H4X / C41349510**.
The antenna is flush with the right PCB edge; the smaller milled notch includes
1 mm side clearance and 0.5 mm internal corner radii. GPIO functions and the
display/USB/battery corrections remain. [Compatibility and verification](esp32-mini.md).
Use **mounting-2026-10-08** for the current board, including six M2 mounting holes.
The earlier MINI package has no mounting holes; older packages use WROOM-02.

**8 October update:** [J2 is now JST-SH C160402](battery-connector.md),
side entry at 2.95 mm mated height, requiring an SHR-02V-S-B lead. The [USB redesign](bringup/usb-backfeed-fix.md) has 119
populated parts per board. The current BOM, five-board purchasing list and
readiness JSON include the new U4, U10, D5 and C55 selections and the replacement
J2. The [October prototype package](../manufacturing/mounting-2026-10-08-package.zip)
contains matching production inputs plus J6 direct battery wire pads. J6 is etched
copper with no paste or purchased component, so the assembly count stays 119.
Earlier archives remain unchanged.

## Historical five-board revision — 22 September 2026

The component, footprint and assembly checks pass for the revised board: 116
populated components per board, 55 distinct BOM parts, with values and MPNs
unchanged. Use the [current fabrication/assembly package](manufacturing-release.md)
and its updated placement drawing. The 19 component moves and two adapted
footprints are documented in [standard fabrication](standard-fabrication.md).

[Current readiness result](assembly/readiness.json) ·
[Footprint audit](assembly/footprint-audit.csv) ·
[Five-board LCSC/Mouser proposal](../manufacturing/contingency-2026-09-22/purchasing-5-boards.csv)

The readiness tool reuses the dated 21 September JLC catalogue snapshot; it does
not establish present stock or delivery. Its five-board JLC purchasing report is
a catalogue cross-check, not the separate manual-assembly sourcing proposal.
That proposal includes explicitly marked substitute MPNs; the design BOM remains
unchanged. Nothing is reserved or ordered by these checks.

## Historical ten-board sourcing notes — 21 September 2026

The following records describe the earlier JLCPCB order. The newer release above
supersedes its layout, footprint and fabrication instructions.

All 55 exact selections refreshed 2026-09-21 against JLCPCB's public catalogue;
native schematic checks repeated with KiCad 10.0.6.
DS1 now uses the 24-position **top-contact FH12A-24S-0.5SH(55), C506794**.
Its manufacturer land pattern, pin order and updated placement are checked;
the public catalogue record was refreshed on 2026-09-21, with 5,189 available
against ten needed. All other BOM part observations were refreshed in the same run.
[Connector update and verification](oled24/top-contact.md).
**Every physical symbol has a resolving
footprint and every populated purchased item has an exact manufacturer part
number and JLCPCB C-code.** The [manufacturing package](manufacturing-release.md)
now includes Gerbers, drills, stencil data and a matching 116-placement CPL.
It has zero DRC errors and zero unconnected items. JLCPCB CAM acceptance,
catalogue-specific assembly preview and physical prototype qualification remain.

There are **128 physical symbols**: 116 populated purchased components,
11 DNP components, and one etched PCB antenna. The populated BOM contains
**55 distinct purchased parts**, grouped by exact C-code rather than value alone.
The stock screen passes for ten boards, but two RF parts have limited stock.

## Files to use

- [JLCPCB BOM](assembly/jlcpcb-bom.csv): one-board reference designators, exact
  MPNs, catalogue packages and C-codes. Select **10 assembled boards** in the
  order; do not multiply designators or upload the purchasing report as the BOM.
- [Ten-board purchasing report](assembly/purchasing-10-boards.csv): quantity per
  board, total placements, public loss/minimum fields, stock and source links.
- [Footprint/model audit](assembly/footprint-audit.csv): every physical reference,
  including DNP pads and A1, with resolved footprint hashes and model paths.
- [Stock snapshot](assembly/jlc-stock-snapshot.json) and
  [machine-readable readiness result](assembly/readiness.json).
- [Updated schematic](schematic.pdf) and [complete engineering BOM](bom.csv).

DS1's purchased item is the Hirose FPC **socket**, not the OLED glass. The OLED
and keypad are user-supplied external modules, excluded from assembly BOM/CPL
as explicitly reconfirmed by the user on 2026-09-21. J3/J4/J5 remain DNP; J3 still has
isolated end pins 1/9 and P0–P6 on pins 2–8. A1 is manufactured copper, excluded
from the assembly BOM and CPL. J2 is the populated **JST-SH 1 mm side-entry
SM02B-SRSS-TB(LF)(SN) / C160402**, **2.95 mm high when mated**. It requires
an SHR-02V-S-B battery lead in place of PH, opening toward the left edge.
JLCPCB lists Economic and Standard SMT assembly. The fresh 2026-10-07 API
observation reports **27,621 available to order**; stock is dated and unreserved.
[JLCPCB C160402](https://jlcpcb.com/partdetail/JST-SM02B_SRSS_TB_LF_SN/C160402).

The local KiCad footprint has two signal lands and two unconnected hold-downs,
all with paste and no holes. Pin 1 is VBAT, pin 2 GND. Its SH STEP model resolves.
The user accepts intermittent peaks above the 1 A connector rating; no new
limiter is introduced. [Selection and full checks](battery-connector.md).

Historical placement milestones (the current completed routing and DRC are
reported in [PCB layout](pcb-layout.md), and the newer DS1 correction in
[24-pin OLED update](oled24/README.md)):

J3 and DS1 are centered on the board's X = 80 mm centerline (edges at X = 50
and 110 mm). J3 moved 2 mm left and DS1 moved 0.5 mm left; their Y positions
and rotations are unchanged. The [saved-board check](assembly/connector-update-check.json)
confirms zero DRC findings on the three changed connectors, with the other 125
footprints and board outline unchanged. The preliminary board still has 18
unrelated DRC findings. The subsequent [35 mm keyboard breakaway](keyboard-breakaway.md)
adds two mechanical footprints (130 PCB footprints total), places the keyboard
support parts, and routes the five J4-to-J5 connections. Its
[verification](keyboard/breakaway-check.json) confirms no new DRC findings;
303 unconnected items remain. MB1/MB2 are excluded from BOM and placement output.

## Sourcing changes applied before placement

| Reference | Final selection | Why / footprint consequence |
|---|---|---|
| DS1 | Hirose FH12A-24S-0.5SH(55), **C506794** | Top-contact socket for confirmed mounted flex orientation; 24-contact CON24 map retained, manufacturer-derived lands/paste and larger body outline. Moved 0.20 mm toward keyboard. |
| J2 | JST SM02B-SRSS-TB(LF)(SN), **C160402** | Side-entry SH, 2.95 mm mated height. New 1 mm SH lead, preserved polarity, revised lands and local routing. |
| U5 | TI TLV803EA30DBZR, **C5218924** | The DCKR variant was out of stock. Same 3.08 V threshold and nominal 200 ms delay; **SOT-23 replaces SC70**. Both selected variants use 1=GND, 2=RESET, 3=VDD. |
| J1 | GCT USB4105-GF-A-120, **C5184243** | Unsuffixed part had zero available order quantity. Original XY pattern with [0.04 mm outer ground-land trim](usb-connector-clearance.md); holes unchanged. Shell stakes are **1.20 mm**, suitable for the specified 1.6 mm board. |
| R30 | TE CPF0805B1M8E, **C2088132** | Stocked 1.8 MΩ, **0.1%**, 0.1 W, 100 V; **0805 replaces 0603**. Divider voltage and precision remain unchanged. |
| U1 | TOPPOWER TP4054-42-SOT25R, **C32574** | Exact stocked catalogue ordering code replaces SOT235. Catalogue-linked manufacturer sheet confirms the same five-pin assignment and 100 mA with 10 kΩ. SOT-23-5 footprint retained. |
| C30/C31 + C53/C54 | 330 pF 1% **C527075** + 33 pF 5% **C309485** | Replaces the poorly stocked 360 pF 2% selection with **363 pF ±1.364%**, 100 V C0G, using the existing parallel pads. C53/C54 now populated with paste openings. |
| C32/C33 | Yageo CC0805FRNPO0BN680, **C576904** | Stocked 68 pF, 100 V NP0, **1%**; tighter than the previous 2% requirement. |
| R41/R42 | Yageo RC0805JR-070RL, **C96345** | 0805 removable links, **2 A rated jumper**, initial resistance <50 mΩ. Package is 0.125 W; the previous generic 0.25 W description is replaced by the meaningful jumper current rating. |
| Remaining populated items | Exact MPN + C-code assigned | Generic resistors, LED and bypass capacitors are now specified. Previously calculated bulk MLCC choices and precision divider tolerances are retained. |

Sources: [TI pinout and ordering table](https://www.ti.com/lit/ds/symlink/tlv803e.pdf),
[GCT ordering/dimensional drawing](https://gct.co/files/drawings/usb4105.pdf),
[TE exact resistor](https://www.te.com/en/product-7-1614894-6.html),
[C32574 manufacturer sheet](../parts%20documentation/TP4054-42-SOT25R-C32574-datasheet.pdf),
[Yageo resistor selection guide, RC0805 jumper rating](https://www1.futureelectronics.com/doc/YAGEO%20AMERICA%20CORPORATION/RL0805FR-070R4L.pdf).
Individual current catalogue sources are linked in the purchasing CSV.
[Archived drawing provenance and hashes](assembly/sources.json).

The revised NFC network calculates **18.838 − j0.140 Ω at 13.56 MHz** under the
documented assumed antenna model. Independent full differential ngspice agrees
with Python to 3.01e-12 relative difference. These checks validate the arithmetic,
not measured RF performance. Four free 0805 no-paste tuning pads remain at
C34/C35 and C38/C39; the EMC stage can be adjusted by changing the populated
33 pF parts in matched pairs. The [NFC guide](nfc-antenna.md) includes the updated
tolerances, ESR model, voltage/current estimates and tuning procedure.

## Parts to secure before placing the assembly order

| References | JLCPCB part | Needed for 10 boards | Planning quantity incl. published allowances | Available order quantity at audit |
|---|---|---:|---:|---:|
| **L2/L3** | [C20417049, Coilcraft 0805HP-151XGRC](https://jlcpcb.com/partdetail/C20417049) | 20 | 20 | **21** |
| **C36/C37** | [C527192, Yageo CC0805GRNPO0BN101](https://jlcpcb.com/partdetail/C527192) | 20 | 28 | **50** |
| R27/R28 | [C2079511, Vishay CRCW12062R70FKEAHP](https://jlcpcb.com/partdetail/C2079511) | 20 | 24 | 130 |
| R30 | [C2088132, TE CPF0805B1M8E](https://jlcpcb.com/partdetail/C2088132) | 10 | 10 | 154 |
| Y1 | [C3008209, NDK NX2016SA-27.12MHZ-EXS00A-CS06346](https://jlcpcb.com/partdetail/C3008209) | 10 | 10 | 8,538 |

**L2/L3 remain the primary procurement risk.** Only one part remains beyond the
20 placements, and no parts are reserved by this audit. Check/secure this exact
part before relying on a quick assembly turn. A generic 150 nH 0805 inductor is
not automatically equivalent: body/lands, RF loss and impedance differ, and the
calculation uses the Coilcraft model. Murata LQW2BANR15G00L (C2046580) was found
with more stock, but is **not qualified as a drop-in alternative**. It would need
its own land-pattern and RF-model review. R27/R28 must remain the specified
high-power series, not an ordinary 1206 resistor with the same resistance.

CL21B225KAFNNNE/C19110 remains **NRND**, as already documented. The snapshot
shows ample stock for this prototype; qualify a current successor and its
DC-bias behavior before a production revision. Stock availability today cannot
guarantee supply on a later date. The audit makes exact parts easy to find and
identifies the exceptions instead of claiming future availability.

## How stock and quantities were interpreted

JLCPCB's part pages and public search endpoint were read without an account.
The raw page field `overseasStockCount` is displayed as **In Stock**; its name
does not establish Global Sourcing. `canPresaleNumber` is **Available Order Qty**.
Negative values are treated as zero. This distinction rejected the old USB
connector even though its gross stock count was nonzero.

For planning, the checker uses:

```text
placements = references per board × 10
planning quantity = max(placements, leastPatchNumber) + lossNumber
```

This is a conservative screen using the public minimum-placement and loss fields,
not an authenticated assembly quotation. JLCPCB's final BOM matching page controls
actual consumption, attrition, service eligibility and price. `preMinPurchaseNum`
is recorded for possible replenishment; it is **not imposed as an in-stock assembly
MOQ**. For example, Y1's pre-order minimum of 24 does not force 24 crystals onto
this ten-board build. Most selections are Extended parts; expect applicable
setup/handling charges rather than an all-Basic BOM.

Sources: [JLCPCB BOM format](https://jlcpcb.com/help/article/bill-of-materials-for-pcb-assembly),
[minimum/loss and matching explanations](https://jlcpcb.com/help/article/common-bom-and-cpl-matching-issues-and-explanations),
[in-stock versus pre-order rules](https://jlcpcb.com/help/article/how-to-build-your-own-parts-library-in-jlcpcb),
[parts sourcing services](https://jlcpcb.com/help/article/pcba-parts-sourcing-instruction).

## Footprints and 3D coverage

All assigned footprint files resolve, and every schematic physical pin has a
matching numbered footprint pad. **121 of 128 symbols have resolving 3D models.**
The exceptions are J2, A1 (etched copper, no separate body), U6 and L1–L4 (footprints
ready, optional body models absent). The ESP32 STEP file is bundled; the optional
PN7160 model is omitted because its terms prohibit redistribution. The
other assigned models use installed KiCad libraries. These are visual package
representations, not a certification of every selected vendor variant. In
particular, the generic USB4105 model may depict the original stake length.

The L1 land drawing was additionally checked against the exact current Taiyo
Yuden part: **0.8 × 2.7 mm pads on 2.2 mm centers**, matching the project footprint.
[Archived manufacturer drawing](../parts%20documentation/LSXND3030QKT2R2MNG-datasheet.pdf).
The source explicitly identifies NRS3015T2R2MNGH as the former part number.
The RF inductors retain their manufacturer-derived 0805HP lands; the NDK crystal
retains its specific 2016 land pattern. U8 is the **wide 7.5 mm SOIC-16** variant.
The Hirose socket accepts 0.30 mm flex and has **top contacts**, matching the
user-confirmed NFP1309-02Y panel pitch/thickness and mounted contacts facing away
from the PCB. The project-local footprint and simplified envelope model are
checked against the manufacturer drawing. Actual insertion length, panel pin-1
correspondence, enclosure clearance and operation remain prototype checks.
See the [connector update](oled24/top-contact.md).

## Reproduce and refresh

```sh
python3 tools/check_schematic.py
python3 tools/check_assembly_readiness.py --boards 10
python3 tools/check_component_choices.py
python3 tools/nfc/calculate.py
python3 tools/nfc/check_spice.py
```

The last two commands need the dependencies in `tools/nfc/requirements.txt` and
KiCad's ngspice library. The assembly checker is offline and uses the dated
snapshot. To refresh public quantities without placing any order:

```sh
python3 tools/refresh_jlc_stock.py
python3 tools/check_assembly_readiness.py --boards 10
```

The refresh script rejects part-number/manufacturer/package changes rather than
silently substituting a part. JLCPCB's undocumented public endpoint may change;
if retrieval fails, inspect the linked part pages. The stock report is dated and
should always be regenerated close to ordering. Export the CPL from the
final placed PCB and verify every polarized part's orientation in JLCPCB's
assembly preview.

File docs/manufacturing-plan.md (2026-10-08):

# JLCPCB prototype manufacturing plan

Current MCU revision (8 October 2026): **ESP32-C3-MINI-1-H4X / C41349510**.
The antenna is flush with the right PCB edge; the smaller milled notch includes
1 mm side clearance and 0.5 mm internal corner radii. GPIO functions and the
display/USB/battery corrections remain. [Compatibility and verification](esp32-mini.md).
Use **mounting-2026-10-08** for the current board, including six M2 mounting holes.
The earlier MINI package has no mounting holes; older packages use WROOM-02.

**Superseded by the [prepared manufacturing package](manufacturing-release.md)
on 2026-09-21.** The design and OLED connector are locked. Gerbers, drills, BOM,
CPL, stencil and drawings are generated, and all 55 selected parts were refreshed
in stock for ten boards. The release instructions record the remaining supplier
CAM/preview checks, including J1 hole clearance and filled/capped via processing.
The plan below is retained as the preparation history.

Prepared 2026-09-21 against saved design `96c8114`. This is a preparation plan,
not a manufacturing release or an order. The planning basis remains **10 assembled
boards**, with assembly on the top side and the keyboard attached.

## Starting point

- Main PCB: 60 × 110 mm envelope, four copper layers, nominal 1.6 mm thickness,
  black solder mask. Surface finish is not specified in the PCB setup.
- Saved checks report zero ERC violations, zero PCB DRC errors, zero unconnected
  items and zero schematic/PCB parity findings. Two ESP32 outline silkscreen-edge
  warnings remain. These reports were inspected for this plan, not rerun.
- The existing assembly BOM has 55 exact purchased parts and 116 placements per
  board. There are 11 DNP references, an etched antenna and two mechanical
  mouse-bite footprints. The main board has no release Gerber archive or CPL yet;
  existing Gerbers under `prototypes/nfc-antenna/` are for the separate coil coupon.
- The current board has no fiducial footprints. A1 is excluded from the BOM but
  does not explicitly carry `exclude_from_pos_files`; the release exporter must
  exclude it reliably.

Sources for the baseline: [layout](pcb-layout.md), [saved DRC](pcb/drc.json),
[assembly audit](assembly/readiness.json), [OLED update](oled24/README.md).
Some earlier narrative documents still describe preliminary, unrouted layouts;
update those statements as part of release documentation.

## 1. Resolve the choices that could change the PCB

- **OLED connector update completed:** DS1 is now **Hirose FH12A-24S-0.5SH(55),
  C506794**, top contact, matching the user-confirmed 24-pin NFP1309-02Y flex
  (0.50 mm pitch, 0.30 mm thickness, mounted contacts away from PCB). The
  schematic, footprint, PCB, BOM and checks are updated; DS1 moved 0.20 mm for
  latch clearance. [Update report](oled24/top-contact.md). Physical panel pin-1
  correspondence, insertion length, fold/enclosure fit and any other display
  variants still need confirmation.
- **Assembly service and finish:** evaluate the existing black-mask design with
  a proposed ENIG finish under Standard assembly. Compare an Economic quote only
  for a supported color/finish/stackup combination; do not silently change the
  user's black-mask choice. Final service eligibility must include every part.
- **Actual stackup:** select an available JLCPCB four-layer, 1.6 mm construction
  and record its layer order, copper thicknesses and dielectric data in KiCad.
  Recalculate the USB pair's 90-ohm differential target against that construction.
  The current 0.15 mm width / 0.21 mm gap assumes 0.10 mm dielectric to In2.Cu;
  nominal board thickness alone does not establish impedance. Change the USB
  geometry if needed, then repeat reference-plane and skew checks.
- **Assembly carrier:** agree tooling/rail/fiducial locations for the selected
  service. JLCPCB lists a 70 × 70 mm minimum for Standard assembly, plus rails and
  fiducials, so the 60 mm-wide finished board needs a suitable carrier/panel.
  Ensure it accommodates the ESP32 antenna overhang and does not alter NFC copper.
- **Functional breakaway:** prepare a dimensioned drawing identifying the two
  support tabs, 28 NPTH mouse-bite holes, routed slots and central electrical
  bridge. Require the keyboard to stay attached through assembly and delivery.
  The central bridge is cut by the user later; it is not a factory routing line.

JLCPCB's [assembly capabilities](https://jlcpcb.com/capabilities/pcb-assembly-capabilities)
distinguish Economic and Standard service, including carrier and stackup limits.
Use the selected order's actual stackup with its
[impedance parameters](https://cart.jlcpcb.com/client/template/placeOrder/impedance.html).

**Completion condition:** OLED fit is resolved, the manufacturing specification
is recorded, and the assembly/carrier approach is defined.

## 2. Refresh sourcing while those choices are resolved

- Refresh all 55 exact C-codes and regenerate the ten-board purchasing report.
  Include placement losses/minimums from the final quote, not just 10× the BOM.
- Prioritize L2/L3, **C20417049 / Coilcraft 0805HP-151XGRC**: the September 20
  snapshot had 21 available against 20 placements. C36/C37, **C527192**, had 50
  against a planning requirement of 28. Neither figure is live or reserved.
- DS1 is updated to top-contact **C506794**, with 5,189 available at the latest
  observation; refresh again close to ordering. Confirm side-entry SMT J2 **C160402**
  matches the final BOM.
  Treat any replacement as a component/footprint review; RF inductors must also
  preserve the required RF characteristics or trigger recalculation and tuning.
- Identify procurement lead times and any parts that need purchasing/reservation
  before order placement. Obtain the final cost before committing expenditure.

Use `tools/refresh_jlc_stock.py` followed by
`tools/check_assembly_readiness.py --boards 10`. The latter alone is an offline
check against the saved snapshot.

**Completion condition:** every populated reference has an exact available or
explicitly sourced part and a realistic quantity/lead time.

## 3. Complete fabrication and assembly checks

- Compare the design against the chosen JLCPCB process: 0.15 mm minimum tracks,
  0.20 mm copper clearance, 0.20 mm minimum via drill and 0.125 mm annular ring.
  Review board-edge, slot, hole and mask clearances, including process tolerances.
- Completed: J1's [approved local ground-land trim](usb-connector-clearance.md)
  raises NPTH-to-pad clearance from 0.1944 to 0.2333 mm. Its KiCad rule now
  requires JLCPCB's 0.20 mm minimum; the holes and connector part are unchanged.
- Check PN7160 exposed-pad paste coverage and nearby vias, fine-pitch connector
  paste/mask openings, connector mechanical lands and all DNP paste apertures.
  Confirm via tenting and any via-in-pad treatment actually required by geometry.
- Remove or explicitly accept the two ESP32 silkscreen-edge warnings. Check
  polarity/pin-1 marks, battery polarity, interface labels, revision marking,
  breakaway instructions and any manufacturer order-number placement.
- Preserve the NFC all-layer pour exclusions, ESP32 antenna clearance, USB ground
  reference and breakaway keepouts through any manufacturing edits.
- Refill zones and rerun native ERC, DRC with schematic parity/all-track checking,
  the layout checks and assembly audit on the final saved files. Review ignored
  checks and custom exceptions. Rerun circuit-specific checks if affected by edits.

Use the current [fabrication capabilities](https://jlcpcb.com/capabilities/Capab)
and the project's existing verification tools.

**Completion condition:** zero unresolved electrical/routing/parity errors, with
every remaining manufacturing exception documented and resolved for the process.

## 4. Generate a reproducible release package

Create a release directory tied to a commit and file hashes. Generate all outputs
from the same frozen revision:

| Deliverable | Contents / acceptance check |
|---|---|
| Fabrication ZIP | F.Cu, In1.Cu, In2.Cu, B.Cu; both masks and silkscreens; Edge.Cuts; separate PTH and NPTH Excellon drills. Include the mouse bites and connector slots with correct plating. |
| Assembly BOM CSV | Exact MPN/C-code groups; currently 55 lines covering 116 populated references. Reconcile counts if any approved changes occur. |
| CPL CSV | Designator, Mid X, Mid Y, Layer, Rotation; millimetres; exactly the same populated reference set as the BOM, each appearing once. |
| Paste data | Top stencil/paste Gerber with intentional DNP omissions and reviewed exposed-pad apertures. |
| Assembly drawing | Reference positions, pin-1/polarity marks and explicit DNP list. |
| Fabrication drawing and notes | Stackup, finish, thickness, dimensions, slots, tooling/carrier and attached-keyboard requirement. |
| Release record | Source revision, tool versions, checks, dated sourcing report and hashes. |

Explicitly omit **C7, C8, C34, C35, C38, C39, J3, J4, J5, R38, R39**, **A1** and
**MB1/MB2** from the assembly BOM/CPL. Retain their intended fabrication geometry.
The OLED glass (including **NFP1309-02Y**), external keyboard/keypad and battery
are external items, excluded from the assembly BOM and CPL. The user explicitly
reconfirmed the display and keyboard exclusions on 2026-09-21. DS1 orders the
socket only; onboard display support and keyboard interface electronics remain
in the populated BOM. J3/J4/J5 remain DNP/user-fitted.

Use a documented, consistent coordinate origin and orientation across the Gerber,
drill and placement exports. Check component centroids as well as rotations;
footprint origins and assembler package origins can differ. If panelization
changes coordinates, keep the panel data and BOM/CPL workflow consistent.

JLCPCB documents its [BOM fields](https://jlcpcb.com/help/article/bill-of-materials-for-pcb-assembly),
[CPL fields](https://jlcpcb.com/help/article/pick-place-file-for-pcb-assembly) and
[Gerber/drill preparation](https://jlcpcb.com/help/article/how-to-generate-gerber-and-drill-files-in-kicad-9).

**Completion condition:** repeatable exports with no missing/extra placements and
an independently inspected Gerber/drill/paste view.

## 5. Review the quote and manufacturing interpretation

- Upload the package for quotation; check layer recognition, dimensions, all
  routed slots and PTH/NPTH holes in the manufacturing preview.
- Review every BOM match against the exact C-code and every assembly placement.
  Check IC pin 1, transistors, diode/LED polarity, crystal orientation, the ESP32
  module, USB, battery and OLED connectors. Record any required CPL corrections
  in the reproducible export process.
- Confirm the keyboard is treated as an attached functional section, and that
  tooling/rails do not damage the antenna or obstruct overhanging components.
- Review fabrication/assembly engineering questions and obtain the final quote,
  including parts, losses, Extended-part fees, assembly, inspection, shipping and
  applicable import charges. Commit the order only after reviewing that result.

**Completion condition:** accepted fabrication interpretation, verified assembly
preview, sourced parts and a reviewed final price.

## 6. Prepare prototype acceptance before delivery

Write a board-by-board bring-up sheet: visual inspection and resistance checks,
current-limited USB power-up, supply rails/reset, programming and USB enumeration,
I²C devices, keyboard and OLED operation, then NFC oscillator/antenna tuning.
Test the existing dedicated 5 V / at least 1.5 A supply assumption, startup/inrush
and load transients. If battery operation is exercised, follow the existing
battery/charger design checks. Test separation and reconnection on one unit only
after attached-board operation is established.

NFC tuning, oscillator startup and real display operation remain prototype
measurements; their existing calculations are not hardware qualification.

**Immediate next work:** resolve the manufacturing specification, refresh critical
stock, and complete the remaining fabrication/assembly audit findings. DS1
replacement and its electrical/layout regression checks are complete.

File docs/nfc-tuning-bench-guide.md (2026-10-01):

**PN7160 antenna tuning: a bench guide for Nucula v2**

Researched 2026-09-23 for phone-to-board, bidirectional communication, with the
board acting as an emulated card. The phone is the reader and supplies the RF
field; the powered PN7160 and ESP32 answer it. No RF measurements of a physical
Nucula board were available. All existing component values are starting values.

The recommended equipment is a **100–200 MHz oscilloscope, at least 1 GSa/s on
the channels in use, and a calibrated VNA that works well at 13.56 MHz**. A scope
alone does not give the complex impedance needed to select matching components.
Start with a small inductive pickup loop for the scope. Borrow suitable RF voltage
probes and a calibrated NFC test bench for the measurements they uniquely enable.

This guide was checked against a fresh schematic netlist and the saved PCB,
including the pad numbers below. Design files were not changed. The existing
[antenna design note](nfc-antenna.md), [RF schematic](nfc/schematic.pdf),
[PCB detail](pcb/nfc.png), and [matching calculator](../tools/nfc/calculate.py)
provide the board-specific background.

**What you are trying to achieve**

For application data, begin with NFC-A / ISO-DEP card emulation, initially at
106 kbit/s. The phone sends command APDUs; your ESP32 processes them and supplies
response APDUs through PN7160. Both directions can carry application data without
switching the RF roles. This is distinct from NFC peer-to-peer. PN7160's current
datasheet limits its P2P support to older firmware; do not assume an old P2P demo
is the right foundation for a current phone application. If the phone is instead
the emulated card, the board must be configured as the reader and generate RF.
[AN13861, sections 2–5](https://www.nxp.com/docs/en/application-note/AN13861.pdf)
describes host-based versus internal NDEF card emulation;
[datasheet, sections 2 and 6](https://www.nxp.com/docs/en/data-sheet/PN7160_PN7161.pdf)
records the firmware differences.

PN7160 uses active load modulation (ALM) to reply in card mode. The same matching
network is used for reader and card operation, but successful reader-mode tuning
does not establish successful card-mode replies. Card-mode phase, amplitude,
receiver behavior, and phone interoperability must also be checked. See the
project's [AN13219 rev. 1.6, section 7](../parts%20documentation/AN13219-rev1.6.pdf).

The engineering sequence is: measure the isolated antenna in its intended
mechanical environment; calculate the matching network; fit and measure it;
verify powered operation; optimize the intended communication mode; then check
multiple devices, loads, and production samples. This is also the general
approach in [ST AN4974](https://www.st.com/resource/en/application_note/dm00347152.pdf)
and [TI SLOA241](https://www.ti.com/lit/an/sloa241c/sloa241c.pdf).
Their chip-specific impedances, register settings, and networks do not transfer
to PN7160.

**Equipment and oscilloscope specifications**

| Item | Minimum or useful capability | Recommendation for this project |
|---|---|---|
| Scope analog bandwidth | NXP specifies at least 50 MHz for carrier-envelope shaping checks | Buy 100 MHz or 200 MHz; 200 MHz adds margin for edges and general embedded work |
| Real-time sample rate | 500 MSa/s is a usable engineering floor for these observations | At least 1 GSa/s with the intended channels enabled; check shared ADC limitations |
| Channels | Two: RF pickup and trigger/power/logic | Four are convenient for RF, TVDD, IRQ, and a firmware marker |
| Record length | Enough to retain useful time resolution over a transaction | At least 1 Mpoint/channel; around 10 Mpoints is convenient |
| Acquisition | Single shot, edge trigger, waveform zoom, peak-to-peak and timing measurements | Pulse-width trigger, persistence, waveform export, and segmented capture are useful |
| Resolution | An ordinary 8-bit scope can support initial tuning | More effective resolution helps see small replies on a large carrier, but does not replace an NFC measurement fixture |
| RF pickup | Small loop held in a fixed nonmetallic fixture | Make one or use a small H-field probe; it does not touch the board electrically |
| Direct RF voltage probe | Adequate bandwidth, input range, low capacitance, and RF voltage rating | Prefer approximately 1–2 pF or less loading where practical; verify each input and differential specifications |
| VNA | Complex S11 / R+jX, calibration, and coverage of 5–25 MHz | Coverage to 100 MHz is useful for antenna self-resonance; export Touchstone data and use hundreds of points near the carrier |
| Other bench equipment | DMM, current-limited supply, fine rework tools | Microscope, temperature measurement, spare C0G capacitors/resistors, and nonmetallic distance spacers |

The scope minimum comes from [AN13219 rev. 1.6, section 10.2, p. 45](../parts%20documentation/AN13219-rev1.6.pdf).
The stronger purchase specifications above are engineering recommendations,
not additional NXP requirements. The 13.56 MHz period is about 73.75 ns, so
1 GSa/s gives about 74 samples per cycle. Tektronix's amplitude-measurement
guidance uses roughly five times the highest frequency of interest; five times
the carrier is 67.8 MHz. A 100 MHz measurement system therefore has sensible
margin for the carrier. Faster edges and harmonics need more bandwidth.
[Tektronix bandwidth guidance](https://www.tek.com/en/support/faqs/why-it-important-use-oscilloscope-more-bandwidth-my-device-under-test).

Probe loading is often more important than buying extra scope bandwidth. A
10 pF probe is a substantial addition to a 68 pF or 100 pF matching component,
depending on the node and connection. Its reactance is about 1.17 kΩ at
13.56 MHz. A 1× probe is generally a particularly poor choice for RF nodes.
Two ordinary probes with channel subtraction still add both probes' loading.
[Tektronix probe-loading explanation](https://www.tek.com/en/documents/application-note/how-oscilloscope-probes-affect-your-measurement).

For direct antenna voltage measurements, low capacitance alone is insufficient.
The project's unverified model predicts about **47 V peak differential,
94 V peak-to-peak**, even at TVDD = 3.3 V. A useful initial probe selection target
is a linear differential range of at least ±100 V, with adequate per-input
common-mode range, **rated at 13.56 MHz**; this is not a guarantee that unknown
external fields stay within that range. Check frequency derating and the linear
measurement range, not merely a DC damage rating. Many low-capacitance logic
probes cannot measure these voltages. Borrowing a suitable probe is reasonable.

For a powered board, ordinary scope ground clips connect only to PCB GND.
**Never clip one to either antenna terminal or a driven TX terminal.** Scope
channel grounds are commonly connected together and to protective earth. Do not
remove protective earth. Do not connect a bare scope 50 Ω input across the coil.
A small inductive pickup is the easiest starting point: NXP shows a probe with
its ground lead connected to its own tip, forming a loop held above the antenna.
The indicated voltage depends on loop position and is not calibrated antenna
voltage or magnetic field strength.

NXP explicitly demonstrates economical VNA measurements in
[AN12810](https://www.nxp.com/docs/en/application-note/AN12810.pdf). A NanoVNA-class
instrument can be sufficient; an expensive microwave frequency limit is not
needed. Choose usable impedance display, stable calibration, data export, and
appropriate fixtures. A scalar SWR meter and a low-frequency LCR meter do not
provide the same information. Some instruments sold as two-port VNAs only
measure S11 and S21 in one direction, so two connectors alone do not establish
full differential measurement capability.

**The actual tuning components**

Each row describes equal components on the two branches, unless stated otherwise.
NXP's generic names C0/C1/C2 are functions, not your schematic reference numbers.

| Project references | Present value, each branch | Purpose and expected changes |
|---|---|---|
| A1 | 40 × 40 mm, four-turn PCB coil | Leave the copper geometry intact initially; measure its installed impedance |
| L2 / L3 | 150 nH, Coilcraft 0805HP-151XGRC | EMC filter inductors; retain initially |
| C30 / C31 | 330 pF | Main EMC capacitor C0 |
| C53 / C54 | 33 pF, populated | In parallel with C30/C31: total C0 = 363 pF per branch |
| C32 / C33 | 68 pF | Series matching capacitor C1; likely replacement candidates |
| C34 / C35 | DNP | Parallel trims for C32/C33; add the same value to both |
| C36 / C37 | 100 pF | Shunt matching capacitor C2; likely replacement candidates |
| C38 / C39 | DNP | Parallel trims for C36/C37; add the same value to both |
| R27 / R28 | 2.7 Ω, high-power 1206 | Set antenna damping/Q; remove both temporarily to measure the isolated coil |
| R25 / R26 | 2.2 kΩ | Receiver attenuation; remove for isolated passive-network measurement, tune later if needed |
| C28 / C29 | 1 nF | Receiver AC coupling; normally keep these values |
| R41 / R42 | 0 Ω | Transmitter isolation; remove both for passive-network measurement, refit before powered operation |
| R29 | 0 Ω, 0603 | TX-LDO supply input link; optional location for temporary supply-current sensing |

The per-branch path is:

```text
TX -- R41/R42 -- L2/L3 -- EMC node -- C1 -- match node -- Rq -- coil end
                            |                  |
                            C0                 C2
                            |                  |
                           GND                GND

Separate receive branch: EMC node -- Rrx -- Crx -- RX
```

On the positive branch, C1 = C32 + C34, C2 = C36 + C38, C0 = C30 + C53. On the negative branch,
C1 = C33 + C35, C2 = C37 + C39, C0 = C31 + C54. There is no coil center tap.
Retain the saved RXP/RXN branch association when restoring the components.

Use 0805 C0G/NP0 capacitors rated 100 V, preferably 1–2% for the main matching
values. Keep the existing high-power damping-resistor specification; an arbitrary
quarter-watt 1206 is not equivalent. Sensible tuning stock consists of paired
56, 62, 68, 75, 82, 100, and 120 pF parts, and paired 0.5, 1, 2.2, 3.3, 4.7,
6.8, 10, 15, 22, and 33 pF trims. Tight absolute tolerances matter at sub-pF
values. Have high-power 1.8, 2.2, 2.7, and 3.3 Ω resistor pairs available;
order intermediate values if the measurement calls for them.

Parallel trims can only increase capacitance. To get 65 pF from an existing
68 pF position, replace the base, for example with 62 pF plus a small trim.
Do not solder a potentiometer, long flying leads, or a leaded variable capacitor
into this matching network. Do not change C26/C27, the crystal load capacitors,
as an antenna-tuning adjustment.

**Board states and exact measurement pads**

| Measurement | Board electrical state | Components to remove | Connection |
|---|---|---|---|
| Isolated coil impedance | Entire board unpowered, external RF absent | R27 and R28 | A1 pads 1 and 2, equivalently R27 pad 2 and R28 pad 2 |
| Complete passive matching impedance | Entire board unpowered, external RF absent | R41, R42, R25, R26; R27/R28 fitted | R41 pad 2 (`RF_DRV_P`) and R42 pad 2 (`RF_DRV_N`) |
| Powered RF/current/AGC checks | Controlled supply; explicit diagnostic firmware state | Remove all VNA connections, restore every RF link | Pickup loop; TVDD and supply measurement points as appropriate |
| Phone/card-emulation tests | Board powered and configured as an ISO-DEP listener | RF links fitted, VNA absent | Phone generates RF; scope pickup and firmware logs observe transactions |

For passive measurements disconnect USB, battery, programmer, debug cable,
scope, and bench supply. VEN low is not equivalent to this isolation procedure.
Keep the intended display, battery, enclosure, ferrite, and metalwork physically
in their normal places where possible, but disconnect power. Their geometry
changes the antenna. The four-layer populated board is the relevant specimen;
the bare two-layer coupon is only a useful earlier comparison.

No transmitting phone or reader may be near the antenna while the VNA is
attached, even if the board itself has no power. The antenna can couple external
RF into the VNA input.

For the full network, choose one of these measurement arrangements:

* **Practical one-port arrangement:** connect the S11 center conductor to R41
  pad 2 and its shield return to R42 pad 2. Keep PCB GND entirely disconnected
  from instrument ground/earth; retain the board's internal ground connections
  and all shunt capacitors. This treats the isolated, approximately symmetric
  network as a floating two-terminal load, following NXP's two-wire fixture
  approach. Unintended capacitance from the board/metalwork to earth can disturb
  the result, so keep cable and fixture position repeatable and check stability.
* **Balanced fixture:** use a characterized RF transformer/balun fixture suitable
  for 13.56 MHz and calibrate at its DUT terminals. Its impedance transformation
  must be known. A nominal transformer ratio alone is not a calibration.
* **Full two-port arrangement:** both cable shields go to PCB RF ground; each
  center conductor goes to one of the two network input pads. Acquire all four
  calibrated S-parameters and convert to differential impedance. For equal
  50 Ω ports and negligible mode conversion, `Sdd11 = (S11-S12-S21+S22)/2` and
  `Zdiff = 100*(1+Sdd11)/(1-Sdd11)`. Significant mode conversion needs a fuller
  mixed-mode treatment with the intended common-mode termination.

The first arrangement is conditional on keeping the assembly floating. Do not
connect its shield to both R42 pad 2 and PCB GND: that grounds one RF input and
measures a different circuit. If your enclosure must be earthed or measurements
change substantially when the cable moves, use the balanced/full two-port
method. These are passive VNA arrangements, not permission to ground a driven
antenna terminal during powered scope tests.

**Step-by-step procedure**

1. **Establish the mechanics and prepare one development board.** Choose the
   actual display, battery position, enclosure, and any ferrite before final
   tuning. Keep the antenna away from an unintended metal workbench or conductive
   mat using a nonmetallic fixture. Start without a phone/tag nearby. Photograph
   the board, record fitted values, and inspect for bridges between coil turns.
   A1 should show low DC resistance, not an open circuit: it is a continuous
   winding. Subtract meter lead resistance; the old bare-coupon estimate of
   roughly 0.6 Ω is only a sanity check, not the RF resistance specification.

2. **Make digital bring-up reproducible before powered RF tests.** Confirm the
   supply rails, PN7160 reset/IRQ operation, I²C communication, and firmware
   version. The current board uses SDA GPIO4, SCL GPIO5, IRQ GPIO6, VEN GPIO7.
   A fresh export still shows **R23/R24 = 100 kΩ**. The
   [existing wiring audit](nfc-wiring-audit.md) found these insufficient to
   guarantee low address bits against the internal pull-ups. For fixed address
   0x28, fit 0 Ω at both positions; 10 kΩ pull-downs are another documented
   option. This is a bring-up correction, not an RF matching adjustment.
   The project contains no firmware, so a diagnostic host application is needed.
   This step can run in parallel with preparing the passive measurement setup.

3. **Make and calibrate a short VNA fixture.** Set a 5–25 MHz sweep, approximately
   801 points, with a marker exactly at 13.56 MHz. Display R+jX or magnitude and
   phase, not just return loss. If the VNA only supports a small number of points,
   use a narrower sweep or segmented PC acquisition. Calibrate open, short, and
   50 Ω load at the ends of the fixture that will contact the board. Include the
   cable and connector in that calibration. NXP's homemade calibration method
   uses a short two-pin fixture and an SMD resistor load. Check a separate known
   resistor near 20 Ω afterward: it should read close to its resistance with
   little reactance. Recalibrate when the fixture or relevant sweep setup changes.
   See [AN12810, sections 2.1 and 2.3](https://www.nxp.com/docs/en/application-note/AN12810.pdf).

4. **Measure the isolated coil.** Remove R27/R28, disconnect all power and
   instruments except the VNA fixture, and connect at their coil-side pads.
   Measure in the intended mechanical assembly. Save S11 and impedance versus
   frequency. At 13.56 MHz write down `Zcoil = R + jX`. For an inductive coil,
   the apparent series inductance is `Lapp = X/(2*pi*f)` and `Qcoil = X/R`.
   Extracting a small resistance alongside a large reactance is sensitive to
   fixture and calibration error; repeat the setup before trusting a very
   precise Q or damping result.
   NXP recommends bare-coil self-resonance above 25 MHz; extend and recalibrate
   the sweep to investigate it if your fixture allows. The bare coil itself is
   not supposed to self-resonate at 13.56 MHz. See
   [AN13219, sections 2.1.4 and 4.1.2](../parts%20documentation/AN13219-rev1.6.pdf).

5. **Turn the measurement into a model and choose damping.** For a first
   calculation at the carrier, use the measured apparent series R and L and
   explicitly set `Ca = 0` in this project's calculator. This is a local
   single-frequency approximation. For useful wider-band prediction, fit the
   model `(Ra + j*w*La) || 1/(j*w*Ca)` to a sweep. One complex measurement cannot
   determine all three parameters. Do not put an apparent inductance that
   already includes self-capacitance into the calculator and then add that
   capacitance again.

   Begin with a damped antenna-branch Q near 20; values around 15–20 are NXP's
   usual starting range. The two equal series damping resistors satisfy, at
   the carrier, `Rq_each = max(0, (X/Qtarget - R)/2)`. For an illustrative
   `Lapp = 1.62 uH`, `R = 1.80 ohm`, `X` is about 138.02 Ω and each resistor
   works out to 2.55 Ω. These are invented example measurements, not this
   board's results. If the isolated coil already has Q below the target,
   additional damping cannot improve it; investigate metal, loss, and geometry.
   This branch Q is not the loaded Q of the whole EMC/matching network.

6. **Calculate C1 and C2 for the existing network.** Start with the project's
   conservative **20 + j0 Ω differential** target at 13.56 MHz, its 150 nH
   inductors, and 363 pF per-branch EMC capacitance. The EMC LC frequency is
   about 21.57 MHz. This follows NXP's high-cutoff, asymmetric-frequency-response
   approach. Both physical branches still use equal component values: the word
   "asymmetric" refers to the frequency response, not unequal capacitors.

   NXP's typical higher-output target for TVDD ≤3.3 V is 13 Ω; the repository's
   20 Ω at that voltage deliberately sacrifices output for current margin.
   Start with 20 Ω, then consider a lower target only if measured card-mode
   performance needs it and current/thermal checks permit. The 20 Ω choice is
   not a uniquely optimal card-emulation match. Keep reader-mode DPC and
   card-mode DLMA conceptually separate. Do not lower the EMC cutoff toward
   NXP's roughly 14.6 MHz symmetric-response design without its associated
   DPC/tuning work. See
   [AN13219, sections 4.1.3.2–4.1.3.8](../parts%20documentation/AN13219-rev1.6.pdf).

   Use the existing Python calculator or NXP's PN7160 matching calculator.
   AN13219 references an Excel attachment, but the local PDF has no embedded
   spreadsheet; obtaining it may require NXP's design resources. The project
   calculator is already available. With its dependencies installed, this
   illustrative command preserves the repository's baseline output:

   ```sh
   python3 tools/nfc/calculate.py \
     --la-uh 1.62 --ra-ohm 1.80 --ca-pf 0 \
     --target-ohm 20 --out /tmp/nucula-nfc-measured
   ```

   Dependencies are in `tools/nfc/requirements.txt`; use a Python virtual
   environment. For those example inputs the continuous solution is approximately
   C1 = 65.96 pF, C2 = 100.17 pF, Rq = 2.55 Ω **per branch**. It includes the
   calculator's assumed receiver loading. The physical passive test removes
   that loading; use `network(..., rx=False)` for the corresponding simulation.
   The calculator's `exact_solve` is the new solution, while its `assembly`
   field continues to evaluate the original 68 pF / 100 pF / 2.7 Ω build.
   Running it does not change the schematic or assemble the calculated values.

   The existing, unmeasured repository coil model instead produces approximately
   66.45 pF / 102.28 pF / 2.61 Ω. Its fitted BOM rounds to 68 pF / 100 pF /
   2.7 Ω and predicts about 18.80 − j0.24 Ω with RX isolated. Do not regard
   agreement with that prediction as a physical pass criterion.

7. **Fit parts and measure the entire passive network.** Restore the selected
   R27/R28 damping resistors. Remove R41/R42 and R25/R26 and attach the fixture
   at R41 pad 2 and R42 pad 2. Keep all power disconnected. Record the sweep
   and 13.56 MHz impedance. Tune toward the chosen resistance with reactance
   near zero. Do not tune for minimum 50 Ω SWR: 20 Ω is intentionally a mismatch
   to a 50 Ω instrument. An ideal 20 Ω resistance gives S11 magnitude 0.429,
   return loss 7.36 dB, and SWR 2.5 on a 50 Ω display.

8. **Fine-tune in equal pairs and keep a log.** C1 is the main resistance/
   impedance-level adjustment; compensate the resulting reactance with C2.
   Both interact. Try about 1–2.2 pF per branch initially, record the direction
   of movement, and reduce the step near the target. Replace base parts when
   capacitance must decrease. Keep C0/L0 unchanged initially; changing the EMC
   stage changes the whole response and detuning behavior. If Q/ringing needs
   adjustment, change R27/R28 and then recalculate/retune C1/C2.
   Power must be absent for each rework; let the board cool, clean flux, and
   dry it before measuring. Avoid adding long stubs or stacks of components.
   As a provisional bench stopping window, approximately 18–22 Ω and
   |X| ≤2 Ω is reasonable around a 20 Ω target, provided the sweep is stable;
   this is an engineering starting window, not an NXP compliance specification.
   Recheck across several boards and environmental cases later.

9. **Remove the VNA and restore the board before powering it.** Refit R41/R42
   and R25/R26. Remove measurement pigtails. Inspect the rework and establish
   a controlled supply. Start with TVDD around 2.7–3.3 V and verify the actual
   RF-state voltage at C23/C24 (`NFC_TVDD`), not just its software setting.
   VDD(UP), accessible at R29 pad 2/C19/C20, is supplied from VSYS; it is not
   a guaranteed 5 V RF rail. The datasheet specifies selecting TVDD below
   VDD(UP) −0.3 V for proper regulation. Battery operation may require a lower
   setting. A 5 V firmware preset does not create a 5 V supply. See
   [datasheet section 11.4.3](https://www.nxp.com/docs/en/data-sheet/PN7160_PN7161.pdf).

10. **Use a deliberate RF diagnostic mode.** Even for a card-emulation product,
    a temporary reader-mode continuous carrier gives a repeatable initial RF,
    current, and receiver check. A normal polling loop repeatedly turns RF on
    and off; pure card/listen mode normally waits for an external field. No
    continuous carrier in listen mode is therefore expected.
    [UM11495 section 12](https://www.nxp.com/docs/en/user-manual/UM11495.pdf)
    specifies reset/init, test, and reset/init sequencing. Its
    `TEST_ANTENNA_CMD` test ID `0x20` controls the RF field and requires Standby
    disabled first. Test ID `0x01` measures TX-LDO current; ID `0x02` measures
    AGC. PRBS is a separate modulation test and needs hardware reset through
    VEN to stop. The old separate `TEST_RF_FIELD_CMD` has been replaced.
    Do not run diagnostic carrier generation while a phone is interrogating
    the board as a card.

11. **Check current, temperature, and waveform behavior.** Use the internal
    TX-LDO-current diagnostic and check the transmitter supply independently.
    R29 is an accessible supply-sense location: a temporary low-inductance
    0.1 Ω resistor gives 25 mV at 250 mA. Use short connections, keep downstream
    decoupling fitted, and account for measurement burden and bandwidth. This
    is TX-LDO input current, including regulator overhead. The whole board's
    USB current includes MCU/display/charging and cannot substitute for it.
    A DMM reading of burst-mode average current can hide a high active current;
    local capacitors also mask fast current changes at this sensing point.
    Use RF-on diagnostic readings and appropriate time-resolved measurements
    for the active intervals.

    The transmitter's maximum continuous current is **250 mA**. Its roughly
    300 mA current limiter is above the permitted operating current; it is not
    the tuning target. Keep margin below 250 mA and stop if limiting, substantial
    TVDD droop, or abnormal heating appears. Check L2/L3 and R27/R28 temperatures,
    and use a properly rated probe for component voltage stress. Compare the
    pickup waveform before and after direct probing to detect probe detuning.
    See [datasheet sections 5 and 11.4.3](https://www.nxp.com/docs/en/data-sheet/PN7160_PN7161.pdf)
    and [AN13892 section 6](https://www.nxp.com/docs/en/application-note/AN13892.pdf).

12. **Set the receiver attenuation with a defined test condition.** Keep
    C28/C29 = 1 nF and start with R25/R26 = 2.2 kΩ, appropriate for the existing
    EMC taps. In the steady diagnostic RF condition, AN13219's command
    `2F 3D 04 02 C8 60 03` reads AGC. After checking response status and length,
    the result is little-endian: low byte + 256 × high byte. The recommended
    diagnostic range is 500–800 decimal. Increase both RX resistors if above
    800; decrease both if below 500, then repeat.

    This is a baseline receiver adjustment, not a requirement to maintain the
    same AGC at all phone distances. External-field AGC changes with coupling;
    card-mode operation must be tested at strong and weak fields. Do not chase
    a fixed number by moving the phone and resoldering repeatedly. Avoid using
    the older AN13219 rev. 1.5 voltage illustration as a universal RX amplitude
    target: rev. 1.6 revised that section to the AGC workflow. The datasheet also
    gives a typical RX input capacitance of 6 pF, making a conventional probe a
    material load on the receiver. See
    [AN13219 rev. 1.6, section 6](../parts%20documentation/AN13219-rev1.6.pdf) and
    [datasheet section 15.3.7](https://www.nxp.com/docs/en/data-sheet/PN7160_PN7161.pdf).

13. **Prove a real command/response exchange.** Reset out of test mode and
    configure NFC-A ISO-DEP listener/card emulation with host routing to the
    ESP32. Start with a known working NDEF Type 4 example or a deterministic
    application SELECT/command/reply sequence. Log field detection, activation,
    received APDUs, sent responses, status, and timeouts. Distinguish a missing
    RF activation from an application command that arrives but is not answered.
    Keep the OLED/Wi-Fi workload quiet first, then add the intended concurrent
    activity. For active card emulation the board must have its own power;
    the phone's field is not a power supply for the whole ESP32 board.

14. **Optimize card-mode ALM using controlled trials.** NXP's procedure selects
    a load-modulation mode, adjusts the ALM phase, and then adjusts amplitude/
    conductance. Freeze dynamic behavior during this characterization; DLMA
    can otherwise change several effective drive settings as coupling changes.
    The relevant parameters are `CLIF_TX_CONTROL_REG`,
    `CLOCK_CONFIG_DLL_ALM` (configuration tag `0xA03A`), and
    `CLIF_ANA_TX_AMPLITUDE_REG`. Use the documented NCI configuration format,
    apply changes in the required state, preserve reserved bits, and record
    the complete configuration and firmware version.

    NXP defines phase values over 0–355° in 5° steps. With phone-only equipment,
    an engineering screening approach is a coarse 15–30° sweep, followed by
    5° steps near a promising region. At each setting use identical positions,
    transaction counts, and firmware behavior. Select a broad reliable region
    across several phones, including near-contact operation, rather than the
    greatest range on one phone. Revisit phase if the hardware match changes.
    This empirical screening does not measure standardized load-modulation
    amplitude. NXP's full phase/amplitude procedure uses a calibrated test bench.
    [AN13218, sections 4–5](https://www.nxp.com/docs/en/application-note/AN13218.pdf).

    In particular, **a card that works farther away but fails against the phone
    may be replying too strongly**. NXP documents default DLMA tuning intended
    for its evaluation antenna and recommends trying **DLMA disabled with ALM
    Mode 1** for this symptom on custom hardware. Mode 1 uses one transmitter;
    do not assume Mode 3 or maximum output is best. Keep the TX-LDO voltage
    limits compatible with your supply when using DLMA. This diagnostic is
    described in [AN13892, section 11, pp. 22–23](https://www.nxp.com/docs/en/application-note/AN13892.pdf).

    If a fixed ALM configuration gives the required operating range, DLMA need
    not automatically become another tuning project. If dynamic optimization
    is needed, use calibrated external field strengths, characterize received
    level and reply amplitude, and derive this antenna's DLMA scaling/gain
    parameters with [AN13223](https://www.nxp.com/docs/en/application-note/AN13223.pdf).
    A phone and an uncalibrated pickup loop cannot supply that absolute field
    calibration. DPC is the separate reader-mode power-control feature.

15. **Validate the complete product and record the final configuration.** Test
    multiple phones, near contact and increasing gaps, lateral offsets, both
    relevant orientations, and phone cases. A simple starting matrix uses
    0/5/10/20/30 mm gaps where the geometry permits, then locates the actual
    failure boundary. Test repeated short exchanges and the longest intended
    transfer, with supply extremes, USB/battery operation, enclosure, display,
    Wi-Fi, and charging states. A criterion such as 100/100 repeated successful
    transactions in each required operating position is a useful project
    acceptance test, not a substitute for a standards test.

    Check several assembled boards. Save final C/R values, part numbers,
    passive sweeps, fixture calibration details, supply/current/temperature
    results, firmware RF configuration, and transaction logs. Change the
    schematic/BOM only after choosing a measured result. Production normally
    uses fixed components and RF settings, with sample characterization and
    an appropriate production functional/self-test; it does not require hand
    tuning every unit. If certification or robust quantified margins are
    required, use an NFC Forum/ISO analog test bench to measure listener
    sensitivity, load-modulation amplitude, and timing over the required fields.
    A phone success test and a pickup-loop waveform cannot prove those margins.

**Where tuning stops being the right remedy**

| Observation | Next check |
|---|---|
| No I²C response | Supplies, address straps, VEN, IRQ polarity, host mapping, clock configuration |
| VNA trace changes greatly with cable or hand position | Fixture calibration, common-mode/earth coupling, unintended nearby conductors |
| Good impedance but poor phone detection | Listener configuration, receiver level, antenna environment, field-detection path |
| Activation occurs and APDUs arrive, but transfer stops | Host response/timeout handling first; then RF quality under long transfers |
| Works at a gap but fails very close | Excess ALM/default DLMA mismatch, supply behavior, strong-field behavior |
| Narrow range or excessive ringing | Damping/Q and EMC response, followed by matching and phase recheck |
| Adding ferrite or moving the display changes everything | Repeat installed-coil measurement and matching; these are antenna changes |
| Stable carrier but no board-originated signal in listen mode | Expected until a reader field and a response transaction are present |

Capacitors can compensate reactance and transform impedance; they cannot
recover magnetic coupling lost behind poorly placed metal or remove dissipative
losses in a loaded coil. The populated island inside A1 and any nearby battery or
display make measurements of the final assembly particularly important.

**Source map and revision notes**

| Source | Revision inspected | Most useful parts |
|---|---|---|
| [PN7160/PN7161 datasheet](https://www.nxp.com/docs/en/data-sheet/PN7160_PN7161.pdf) | 4.2, 22 July 2026; local copy in `parts documentation` | Firmware support; §11.4.3 supplies/current; §15.3.7 receiver limits |
| [AN13219 antenna design and matching](https://www.nxp.com/docs/en/application-note/AN13219.pdf) | 1.6, 25 June 2026; local copy inspected | §4 calculation/measurement; §5 fine tuning; §6 AGC; §7 shared RM/CM matching; §10 verification |
| [AN12988 hardware design](https://www.nxp.com/docs/en/application-note/AN12988.pdf) | 1.6, 7 May 2025; local copy inspected | Power, clocks, I²C interface, and layout |
| [AN12810 NanoVNA method](https://www.nxp.com/docs/en/application-note/AN12810.pdf) | 1.0, 21 April 2020 | Practical fixture, calibration, sweep and impedance display |
| [AN13218 RF settings](https://www.nxp.com/docs/en/application-note/AN13218.pdf) | 1.4, 31 July 2024 | §4 configuration procedure; §5 card ALM phase/amplitude; protected register fields |
| [AN13892 PN7160 FAQ](https://www.nxp.com/docs/en/application-note/AN13892.pdf) | 1.2, 6 September 2024 | §6 current measurement; §11 close-range card-emulation failures |
| [AN13223 DLMA](https://www.nxp.com/docs/en/application-note/AN13223.pdf) | 1.1, 13 September 2021 | External field / receive level / TX gain characterization |
| [AN13861 card emulation](https://www.nxp.com/docs/en/application-note/AN13861.pdf) | 1.0, 26 April 2023 | Host and internal NDEF architectures and ISO-DEP setup |
| [UM11495 PN7160 user manual](https://www.nxp.com/docs/en/user-manual/UM11495.pdf) | 1.8, 2 June 2025 | §12 test sessions, RF on/off, TX-LDO current, AGC, PRBS |

Public search snippets can still display older AN13219 revisions. The receiver
instructions above follow the actual local rev. 1.6 PDF. The PN7160 product
page also carries a newer qualification warning than some older application-note
introductions: do not infer EMVCo 3.x payment compliance merely from the guides'
use of EMV test equipment. For this phone data-transfer project, focus on the
intended NFC-A/ISO-DEP behavior and the relevant NFC Forum/ISO measurements.
[Current PN7160 product information](https://www.nxp.com/products/PN7160).

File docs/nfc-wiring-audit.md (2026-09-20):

# NFC wiring audit against the early prototype

Audit date: 2026-09-20. Current design: commit `162260c`.
Reference: `legacy-design`.

**VEN and IRQ are not interchanged in the saved designs.** The early board
connects the breakout's labeled VEN to XIAO GPIO0 and IRQ to GPIO1. V2 keeps
the same signal directions on ESP32-C3 GPIO7 and GPIO6. The important new
finding is insufficient guaranteed low-level margin on V2's 100 kΩ address
pull-downs. This audit recommends correcting those straps before fabrication.
No schematic or PCB was changed by this audit.

## Evidence and scope

- Exported the early schematic netlist with the KiCad MCP tool and checked
  J3, U1, U2, R1 and R2 against the saved PCB pad nets. The production
  `production/netlist.ipc` independently agrees on VEN, IRQ and the SCL/SDL split.
- Inspected the early schematic PDF and the archived Elechouse PDF visually.
- Exported a fresh V2 netlist with KiCad CLI and compared its connectivity to
  `docs/netlist.xml`: identical. Reviewed all 40 U6 pins plus exposed pad 41.
- Cross-checked NXP PN7160/PN7161 datasheet rev. 4.2, AN12988 rev. 1.6 and
  UM11495 rev. 1.8. Inspected Elechouse's current module documentation too.
- [Machine-readable evidence and input hashes](nfc/wiring-audit.json).

This establishes the saved wiring. It cannot reveal a crossed jumper,
silkscreen mistake on an individual module, hand rework, or the old module's
firmware/nonvolatile configuration. The early folder has no Git history.
This was a pin/net review, not a new routing/DRC audit of the early PCB.

## Breakout-to-chip mapping

J3 below belongs to the **early** board. U6 and U3 belong to **V2**. GPIO
numbers are not module pad numbers.

| Breakout signal | Early connection | V2 connection | Assessment |
|---|---|---|---|
| VEN | J3.5 → U1.1, XIAO GPIO0 / D0 | U3.6, ESP32-C3 GPIO7 → U6.10; R22 = 100 kΩ to GND | Same direction; new GPIO and external default-low resistor |
| IRQ | J3.4 → U1.2, XIAO GPIO1 / D1 | U6.8 → U3.5, ESP32-C3 GPIO6 | Same direction; new GPIO; no external inverter or pull-up |
| SDA | J3.2 → U1.5, GPIO22 / D4 | U3.3, GPIO4 ↔ U6.5 | GPIO changed; shared bus retained |
| SCL | J3.3 → U1.6, GPIO23 / D5 | U3.4, GPIO5 ↔ U6.7 | GPIO changed; clock net corrected as described below |
| DWL | J3.1, accessible but no host GPIO connection | U6.2 → R21 = 10 kΩ → GND | Normal boot preserved; dedicated connector access lost |
| VDD | J3.6 → +3V3 | U6.6 VDD(PAD) → +3V3, nominal 3.31 V | Same host-logic supply role |
| GND | J3.7 → GND | U6.4, .9, .20 and exposed pad .41 → GND | Common ground preserved |
| VANT | J3.8 → XIAO VBUS | U6.12/.28 → VSYS; U6.13 → VSYS through R29 = 0 Ω | Supply changed from USB VBUS to the rail after D1/D2 |

### VEN and IRQ behavior

VEN is the chip's **input** at pin 10: the host drives it. IRQ is the chip's
**output** at pin 8: the host receives it. Datasheet Table 7 distinguishes
VEN's VBAT reference from IRQ's VDD(PAD) output domain. VEN accepts a high
above 1.1 V and a low below 0.4 V; it does not require a 5 V host signal.
Hold VEN low for at least 10 µs to reset, then allow the specified 2.5 ms
boot interval after raising it with supplies valid. See datasheet Tables
36/48/49 and section 11.5.

IRQ polarity is a significant configuration detail: UM11495 section 11.1,
page 94 gives `IRQ_POLARITY_CFG` = `0xA005`, default `0x00`. Bit 1 = 0 means
active high; bit 1 = 1 means active low. The setting is in EEPROM and persists
after firmware download. Thus a used breakout and a new IC need not have
the same IRQ polarity. This is a possible explanation for unexpected behavior,
not proof of what happened on the old prototype. Keep GPIO6 as an input and
make the firmware's IRQ interpretation match the chip configuration.

Neither the early host board nor the archived breakout circuit shows an IRQ
pull-up or inverter. Elechouse **R9 = 10 kΩ is on DWL_REQ**, not IRQ; this was
checked visually and against the PDF's embedded pin/net information.
V2 adds the 100 kΩ VEN pull-down; at 3.3 V its load is only 33 µA.

Sources: [NXP datasheet](https://www.nxp.com/docs/en/data-sheet/PN7160_PN7161.pdf),
[NXP user manual](https://www.nxp.com/docs/en/user-manual/UM11495.pdf),
[archived Elechouse schematic](../parts%20documentation/PN7160_schematic-3.pdf).

## Discrepancies and consequences

1. **Address straps need correction in V2.** R23/R24 reproduce the breakout's
   100 kΩ pull-downs on ADR0/ADR1, pins 1/3. Datasheet Table 58 specifies
   internal 55–120 kΩ pull-ups unless disabled by firmware. With those enabled:

   ```text
   Vpin / VDD(PAD) = 100k / (100k + Rinternal)
                  = 0.455 ... 0.645
   guaranteed LOW requires <= 0.35
   ```

   Therefore 0x28 is not guaranteed by the present resistor network. This is
   an inherited weakness, not evidence that the old module failed. Populate
   **R23/R24 as 0 Ω to GND** for the fixed address, as direct strapping is
   supported by UM11495 section 4.2.1. Alternatively, 10 kΩ gives at most
   0.154 × VDD(PAD) against the strongest specified pull-up. The previous ERC
   check verified connectivity but did not cover this analog divider margin.

2. **GPIO assignments changed.** Port firmware from VEN=0, IRQ=1, SDA=22,
   SCL=23 to **VEN=7, IRQ=6, SDA=4, SCL=5**. The direction of VEN/IRQ remains
   unchanged. Do not reuse XIAO D-pin numbering as ESP32-C3 GPIO numbering.

3. **RF power no longer comes directly from VBUS.** V2 powers VBAT/VBAT2
   and VDD(UP) from VSYS after two Schottky diodes. The USB planning minimum
   is 3.75 V, with initial VDD(TX) at or below 3.3 V. This requires matching
   PN7160 PMU/TXLDO settings, not blindly reusing a fixed-5-V breakout preset.
   AN12988 section 7.5 specifically calls out disabling TXLDO Check for supply
   values other than the supported 3.6 V/5 V check settings. Firmware remains
   responsible for setting and validating this configuration.

4. **The early board's clock net has an actual label error.** J3.3, the XIAO
   and the display share `SCL`, but PCF8574 U2.14 and its 1 kΩ pull-up R1
   belong to a separate `SDL` net. The label near the keypad clock is also
   misplaced. Both the saved PCB and production netlist retain the split.
   Consequently the old carrier has no R1 pull-up on the NFC clock bus and
   no connection from that bus to the keypad clock. Other attached modules
   or hand rework may have supplied the missing pull-up/connection. V2 has
   one connected `I2C_SCL` bus and 2.2 kΩ pull-ups on both I²C lines to 3.0 V.
   The lower pull-up rail is intentional for the OLED; the project's voltage
   checks retain high-level margin at the PN7160 and MCU.

5. **DWL_REQ has less convenient physical access.** The old J3 exposed DWL.
   V2's R21 reproduces the breakout's default-low resistor, but a net label
   alone is not a test pad. NXP AN12988 section 5.3 recommends host control.
   A reachable DWL_REQ pad, with VEN/GND/+3V3 access, would preserve manual
   firmware-download/recovery access without allocating another MCU GPIO.

6. **WKUP_REQ is explicitly grounded in V2.** The archived breakout leaves
   chip pin 39 open. V2 ties it low and uses I²C wake-up; it therefore cannot
   use dedicated-pin wake-up. This is consistent with the intended interface.
   It is unrelated to VEN or IRQ swapping.

7. **The archived Elechouse PDF is not a trustworthy connector-number map
   for this particular jumper arrangement.** Its P1 order is
   `DWL, GND, VBAT, VDD_PAD, VEN, IRQ, SCL, SDA`. Your J3 order is
   `DWL, SDA, SCL, IRQ, VEN, VDD, GND, VANT`, matching Elechouse's current
   module documentation. Compare named signals, not identical header numbers.
   Additionally, the PDF draws Elechouse R25 = 0 Ω between VDD_PAD and
   VBAT/VDD_UP. Populating that bridge while applying separate 3.3 V and 5 V
   would join the rails. The PDF cannot establish its population on your
   actual module. V2 keeps these domains separate; **V2 R29** only feeds
   VDD(UP) from VSYS. These resistor reference numbers belong to different
   schematics and are not interchangeable.

Sources: [NXP datasheet, Table 58](https://www.nxp.com/docs/en/data-sheet/PN7160_PN7161.pdf#page=54),
[NXP hardware guide](https://www.nxp.com/docs/en/application-note/AN12988.pdf),
[NXP user manual](https://www.nxp.com/docs/en/user-manual/UM11495.pdf),
[Elechouse current pinout](https://www.elechouse.com/docs/pn7160/).

## Remaining chip nets checked

These are the actual V2 assignments; package numbering is HVQFN40, not
breakout header numbering. Supply grouping agrees with datasheet Table 7.

| U6 pins | Current connection / review |
|---|---|
| 1 / 3 | ADR0 / ADR1 → R23 / R24 → GND; correct destination, resistor margin issue above |
| 2 | DWL_REQ → R21 → GND |
| 4 / 9 / 20 / 41 | All ground pins and exposed pad → GND |
| 5 / 7 | SDA / SCL → shared I²C bus |
| 6 | VDD(PAD) → +3V3 with C15/C16 |
| 8 / 10 | IRQ → GPIO6; VEN ← GPIO7, R22 to GND |
| 12 / 28 | VBAT2 / VBAT → VSYS with C17/C18; same supply |
| 13 | VDD(UP) → VSYS through R29 with C19/C20 |
| 14 / 18 / 22 | Internal TXLDO output and both TX supply inputs joined on NFC_TVDD, C23/C24 |
| 15 / 16 | RXN / RXP → C28/R25 and C29/R26 receiver taps respectively |
| 17 | VMID → C25 to GND, no external rail |
| 19 / 21 | TX2 / TX1 → R42/L3 and R41/L2 matching branches respectively |
| 23 / 24 / 25 | ANT1 / ANT2 / VDD(HF) open; enhanced RF-detector path unused |
| 26 / 27 / 31 | Analog/core supply pins joined on NFC_VDD18 with C21/C22; no external rail |
| 29 / 30 | XTAL2 / XTAL1 → crystal Y1.3 / Y1.1, C27 / C26 |
| 11 / 38 | Internally connected pins left open |
| 32–36 | NC pins left open |
| 37 / 40 | Unused DCDC_EN / CLK_REQ outputs left open |

The reference crystal electrodes are connected in the opposite order to Y1
in V2; the passive resonator has no polarity, so this is not a wiring error.
The RXN/TX1 and RXP/TX2 branch pairing remains the same as Elechouse's drawing.
RF values, local decoupling and the coil have intentionally changed as already
documented in [the antenna guide](nfc-antenna.md) and
[component refinements](component-refinements.md).

The actionable electrical correction from this review is **R23/R24**. VEN/IRQ
need the correct firmware GPIO mapping and IRQ polarity, not a hardware swap.
Adding physical recovery test access is a useful layout refinement.

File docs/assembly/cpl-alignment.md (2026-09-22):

# JLCPCB placement reference correction — r2

The first CPL applied three unverified shifts from footprint origins to the
centers of their F.Fab body outlines. Those shifts were introduced in the
exporter, not in the PCB. The user reports correct KiCad 3D placement but an
ESP32 displaced right and a display connector displaced upward in both JLCPCB
2D and 3D. The generated shifts have exactly those directions.

| Part | Shift added by the original exporter | Native KiCad X, Y (mm) |
|---|---|---|
| U3, ESP32 | +3.10 mm X (right) | 47.900, 53.860 |
| DS1, display socket | +1.90 mm Y (up) | 30.000, 51.150 |
| J2, JST battery socket | −1.75 mm X (left) | 6.750, 59.100 |

The other 113 rows were not translated. All rotations, parts and board geometry
are unchanged. The offsets were applied consistently by the exporter, so the
old checks that matched BOM references and board geometry could not catch this
supplier-reference mismatch. Native DRC does not check CPL positions.

KiCad places its 3D model relative to each footprint origin. The CPL contains
only positions and angles; JLCPCB applies those to its own catalogue models.
Moving a coordinate to a body-outline center without verifying that model's
placement anchor can introduce an extra shift. Small symmetric components
usually have coincident origins and body centers; they also had no added shift
in this exporter.

Revision **jlcpcb-2026-09-21-r2** removes all three unverified body-center offsets
and uses native KiCad footprint positions, following the
[JLCPCB native-export workflow](https://jlcpcb.com/help/article/how-to-generate-the-bom-and-centroid-file-from-kicad).
This is the correction to review; it is not a claim that every JLCPCB model has
a standard origin. Catalogue-specific XY/angle corrections need direct evidence
from pin alignment. The public EasyEDA catalogue request was unavailable (HTTP
403), so no exact catalogue-origin measurement is claimed.

Upload the [r2 CPL](../../manufacturing/jlcpcb-2026-09-21-r2/assembly/jlcpcb-cpl.csv)
and inspect JLCPCB's **2D lead-to-pad alignment** for U3, DS1 and J2. The first two
were reported displaced; J2 is an additional check because its unverified shift
came from the same rule. Check pin 1, ESP32 antenna direction and connector entry
as well as translation. JLCPCB preview confirmation is still pending.

The revised independent audit compares all 116 CPL entries, coordinates,
normalized rotations and board sides with the native KiCad position export,
and checks the BOM reference set. The superseded package is excluded from the
public repository; **do not reuse its CPL**. Use the r2 package linked from the root
README. The BOM and fabrication geometry do not need changing for this fix.

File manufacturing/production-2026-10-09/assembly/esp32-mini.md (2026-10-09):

# ESP32-C3-MINI-1 compatibility and antenna fit

The current design uses **ESP32-C3-MINI-1-H4X, JLCPCB C41349510** in place of
WROOM-02-N4. Electrical interfaces are compatible after changing the physical
pad numbers and PCB routing. This is a new PCB revision: the modules are not
interchangeable on the old footprint.

The 4 MB H4X part is recommended by Espressif and was available in JLCPCB's
public catalog on 8 October 2026 (829 available to order at that observation;
inventory is not reserved). The older MINI-1-N4 is NRND. H4X has a higher ambient
temperature rating than the former N4 module; this does not raise the assembled
board's temperature rating. The catalog search did not expose the H4X assembly
process field, so automated assembly still requires the supplier's placement
preview and quotation. The prototype supports the established manual reflow process.

The module body changes from 18 × 20 × 3.2 mm to **13.2 × 16.6 × 2.4 mm**:
39.1% less module area and 0.8 mm less module height. The full PCB remains
60 × 110 mm, including its detachable keyboard. Other components still set the
overall assembly height.

## Electrical compatibility

The 3.0–3.6 V supply range, 500 mA external supply requirement, boot straps,
native USB Serial/JTAG, ADC1 battery measurement, shared 100 kHz I²C bus, Wi-Fi
and BLE functions are retained. The regulator, EN supervisor and RC timing,
VBUS-controlled USB isolation, display circuitry, NFC circuit and keyboard are
unchanged. There is no GPIO reassignment in firmware.

| Function | GPIO | Old WROOM pad | MINI pad |
|---|---:|---:|---:|
| 3.3 V | — | 1 | 3 |
| EN/reset | — | 2 | 8 |
| I²C SDA | 4 | 3 | 18 |
| I²C SCL | 5 | 4 | 19 |
| NFC IRQ | 6 | 5 | 20 |
| NFC VEN | 7 | 6 | 21 |
| GPIO8 strap | 8 | 7 | 22 |
| BOOT | 9 | 8 | 23 |
| OLED reset control | 10 | 10 | 16 |
| Keyboard interrupt | 20 | 11 | 30 |
| Reserved, NC | 21 | 12 | 31 |
| USB D− | 18 | 13 | 26 |
| USB D+ | 19 | 14 | 27 |
| OLED power control | 3 | 15 | 6 |
| GPIO2 strap | 2 | 16 | 5 |
| USB present, inverted | 1 | 17 | 13 |
| Battery ADC | 0 | 18 | 12 |

MINI ground pins 1, 2, 11, 14 and 36–53 all connect to GND. Factory NC pads
4, 7, 9, 10, 15, 17, 24, 25, 28, 29 and 32–35 remain isolated. The optional
centre joint, pad 49, is masked without paste or thermal holes; Espressif
permits omitting that solder joint. All perimeter pads have mask and paste.

R12/R13 retain 22 Ω and move beside the module. Both resistor-to-module USB
routes are 1.800685 mm, on F.Cu without vias. The independent routing audit
checks every trace for full entries, centreline joins, 45-degree geometry and
short/duplicate/acute segments. Earlier connector-to-switch USB skew and two
reference-plane sampling gaps remain documented layout advisories; this change
does not qualify USB signal integrity or arbitrary host operation.

## Firmware

H4X contains ESP32-C3 chip revision **1.1**. The user confirmed **ESP-IDF 5.4 or
newer**, which meets the chip revision's framework compatibility requirements.
Firmware is not present in this repository, so existing binaries have not been
built or boot-tested here. Espressif also lists support
from 4.3.7, 4.4.7, 5.0.5, 5.1.3 and 5.2, depending on release branch; non-UART0
primary consoles need the additional fixes in 5.0.8, 5.1.6, 5.2.4 or 5.3.2.
For Arduino or another framework, check its bundled ESP-IDF version. Keep the
4 MB flash configuration and GPIO assignments. Test ROM download, boot/reset,
USB reconnect, Wi-Fi/BLE and peripherals on the first revised board.

## Flush antenna and cutout

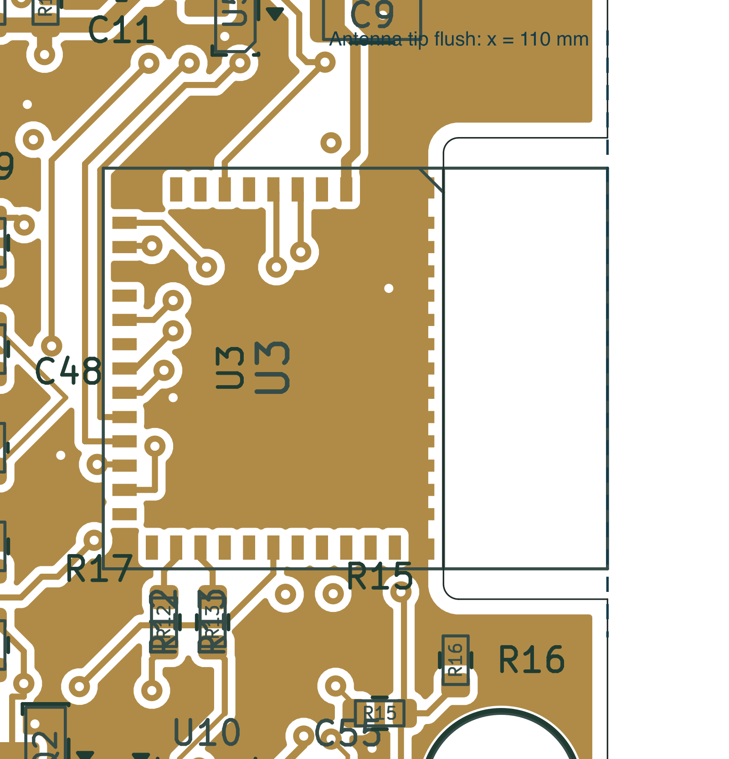
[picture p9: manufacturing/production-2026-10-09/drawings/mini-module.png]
MINI module and flush antenna cutout


U3 is locked at **(101.70, 106.14) mm, −90°**. Its physical antenna tip is at
**x = 110.00 mm**, exactly aligned with the PCB's right outer edge in nominal
CAD geometry. The antenna area is x = 104.60–110.00 mm,
y = 99.54–112.74 mm. No baseboard material or copper remains beneath it.

The notch is x = 104.60–110.00 mm, y = 98.54–113.74 mm, with **1.00 mm clearance
on either side of the antenna** and **0.50 mm internal corner radii**. It opens
to the right edge. Module and board tolerances mean an assembled unit may not
be perfectly flush; the design adds no intentional overhang.

The manufacturer's antenna-side ground lands end at x = 104.30 mm, leaving
**0.30 mm copper-to-cutout clearance**. A custom DRC rule requires at least
0.25 mm for U3 ground lands only. Other copper retains the existing 0.50 mm
edge rule. This dimension and the milled notch must be accepted by supplier CAM.
The OLED ribbon access and keyboard breakaway remain. The current production
release restores the rev-A NFC layout and requires filled/capped vias and the
rev-A stackup; see the production instructions. The antenna keepout prohibits pads, tracks, vias and pours
on all four copper layers. Ground stitching sits on the module side of the cutout.

Espressif recommends this open notch arrangement when the antenna cannot
project past the outer edge. Final enclosure clearance, antenna range and RF
performance still need measurement; CAD clearance is not RF qualification.

## Validation and source records

Current checks: zero schematic ERC violations; zero native DRC errors,
unconnected items or schematic-parity findings; 43 cosmetic DRC warnings;
17 MINI compatibility/fit checks, 16 fabrication checks and all six independent
routing-quality checks pass. USB backfeed, display mapping and battery checks
remain applicable. The required 261 scoped ngspice cases were rerun against
the updated design with no solver errors. Component values and peripheral
topology are unchanged; these models do not simulate the new layout's parasitics,
complete ICs or MCU firmware.

All 32 independent export checks pass for the current mounting package, covering Gerber
copper, solder mask, stencil apertures, drill data, placement data and the
resized board outline.

- [MINI pin/fit verification](../validation/mini-module-check.json)
- [Native DRC](../validation/drc.json) and [routing quality](../validation/routing-quality.json)
- [Footprint amendments](../validation/mini-footprint-amendments.json) and [outline amendment](../validation/mini-outline-amendment.json)
- [Espressif MINI-1 datasheet v2.2](https://documentation.espressif.com/esp32-c3-mini-1_datasheet_en.pdf), tables 1-1, 3-1, 6-2 and figures 10-1, 11-1
- [Espressif module placement guidance](https://docs.espressif.com/projects/esp-hardware-design-guidelines/en/latest/esp32c3/pcb-layout-design.html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)
- [Espressif chip/SDK compatibility](https://github.com/espressif/esp-idf/blob/master/COMPATIBILITY.md#esp32-c3)
- [Espressif source footprint and model](https://github.com/espressif/kicad-libraries), licensed as recorded in [library notes](U3-library-license.md)
- [Exact selected JLCPCB part](https://jlcpcb.com/partdetail/Espressif-ESP32_C3_MINI_1H4X/C41349510)

Run `tools/check_mini_module.py` with KiCad's Python after schematic export and
native DRC with zone refill. Use the **production-2026-10-08** manufacturing package;
the previous MINI and WROOM packages remain historical records.

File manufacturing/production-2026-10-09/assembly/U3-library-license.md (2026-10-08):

### KiCad Libraries License

The libraries provided in this repository are licensed under the [Creative Commons CC-BY-SA 4.0 License](https://creativecommons.org/licenses/by-sa/4.0/legalcode), with the following exception:

---------

_To the extent that the creation of electronic designs that use 'Licensed Material' can be considered to be 'Adapted Material', then the copyright holder waives article 3 of the license with respect to these designs and any generated files which use data provided as part of the 'Licensed Material'._

These are the same license conditions as those used by KiCad project for the official libraries: https://www.kicad.org/libraries/license/.

---------

**Warranty**

The libraries are provided in the hope that they will be useful, but are provided without warranty of any kind, express or implied.

The KiCad libraries are compiled by the KiCad community - if you find an error in the library data, please help the community and contribute a fix!

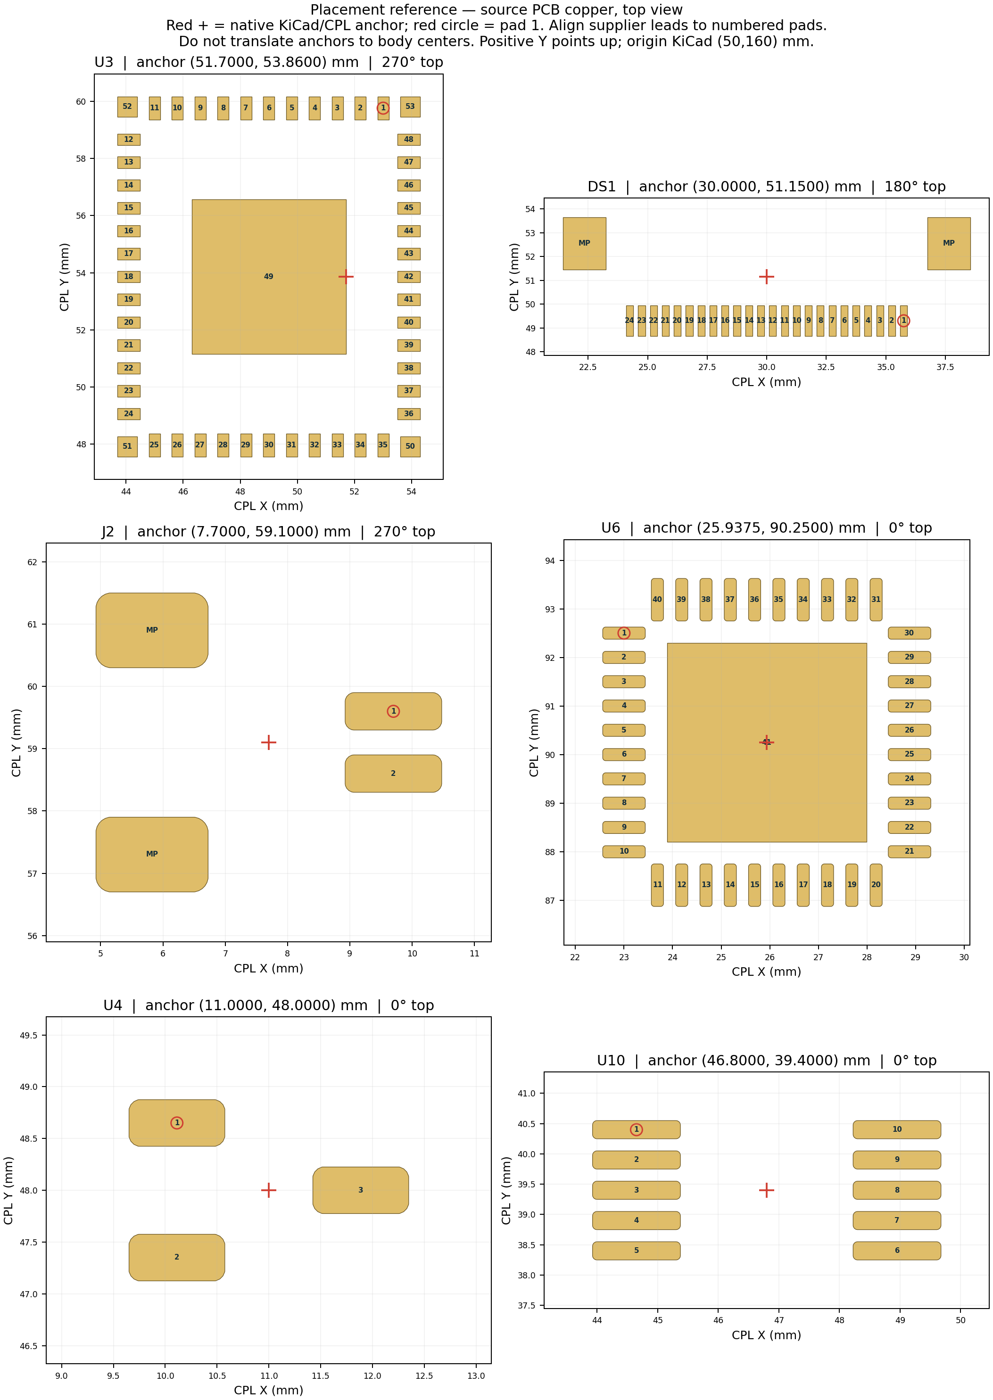
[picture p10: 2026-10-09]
manufacturing/production-2026-10-09/drawings/placement-reference.png

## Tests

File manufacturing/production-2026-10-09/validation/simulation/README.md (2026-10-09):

# Circuit simulation screening

2026-10-09 · production package with qualified stock substitutions · KiCad's bundled ngspice 45.2

The 261 cases were rerun against the revised schematic and routed PCB. Results
record the working-tree file hashes; the modeled electrical findings below
are reported for the selected 0805CS inductors. A separate [57-case analysis](../bringup/backfeed-analysis/results.json)
screens the historical USB backfeed hypothesis and the revised isolation/discharge
circuit. Its assumptions and physical follow-up are described in the
[USB redesign report](../bringup/usb-backfeed-fix.md).

**261 scoped simulation cases completed. This is a partial electrical analysis,
not a complete simulation of the assembled PCB or a fabrication release.**
It highlights antenna-tuning sensitivity, cable-capacitance limits and a battery
measurement settling-time improvement. It does not establish a new definite
PCB wiring defect in the portions modeled.

[Machine-readable results](results.json) · [Solver log](ngspice.log) ·
[Simulation script](../../tools/simulate_preflight.py) · [SPICE node names](node-map.json)

Before simulation, the script checks all 130 schematic components against the
saved PCB for values, pad nets and population flags. The five schematic hashes
must match the independently verified exported netlist. Results record the
design, netlist, assumptions and script hashes. The selected model is bound to each inductor MPN in the exported netlist.

## Findings and actions

The selected 0805CS-151XGLC replaces the unavailable 0805HP. The separate
[substitution qualification](../components/substitutions-2026-10-09/rf-qualification.json)
compares both models in 237 paired scenarios (474 SPICE runs). Copper, placement
and nominal matching values remain unchanged. Physical NFC performance has not
been requalified; the modeled results are not a no-tuning guarantee.

| Area | Result | Consequence |
|---|---|---|
| NFC nominal passive match | 19.88 − j0.11 Ω at 13.56 MHz | Within the documented substitution screening limits; assumed coil/RX model |
| NFC coil and part sensitivity | See machine-readable scenario and tolerance results | These are engineering scenarios, not manufacturing-yield bounds |
| I²C, 400 pF assumed total load | **753 ns** 30–70% rise time with the 2.2 kΩ pull-up at +1% | Passes the 1 µs Standard-mode rise limit. Use 100 kHz; PCF8574T is a 100 kHz device. |
| I²C, 600 pF cable/load scenario | **1.130 µs**, exceeding the rise limit and the design's 400 pF capacitance ceiling | Keep the detached keyboard cable/load within the capacitance budget; a larger extension needs a separate interface design. Actual capacitance is unmeasured. |
| Battery ADC divider startup | At +1% R and +10% C, 120 ms leaves **1.009%** settling error. Reaching 0.1% takes **180.35 ms**; 200 ms leaves **0.047%** | Use at least 200 ms as the initial firmware settling allowance if targeting <0.1% RC settling error under these assumptions. This excludes ADC acquisition, leakage, capacitor temperature effects and divider/calibration error. |
| OLED reset release | R35/C48 reaches 80% of the 3 V rail in **1.79 ms** at +R/+C tolerance | The documented 5 ms wait has margin in this passive RC case. It does not prove complete display sequencing. |
| ESP enable release | R8/C12 reaches 75% of its rail in **15.40 ms**, after ideal reset release | This delay is additional to the supervisor's delay; its output sink, propagation and glitch behavior were not simulated. |
| Buck DC setpoint | **3.228–3.393 V** over 16 reference/bias/resistor cases | Static setpoint remains in the documented range. Minimum regulation is only **39.2 mV above the maximum supervisor release threshold**, or **86.4 mV above its maximum falling threshold**. Dynamic droop and ripple still need validation. |
| OLED boost DC setpoint | **11.499–13.504 V** over 16 reference/bias/resistor cases | Static target lies within the panel's 7–16 V operating range. This does not establish startup overshoot, current capability or loop stability. |

The ADC settling result refines the earlier 120 ms guideline. Most of the other
findings quantify risks already called out in the design documentation. No
component values, routing or footprints were changed based on these assumed
models.

## Models actually exercised

The NFC generator selects the current R41/R42, L2/L3, C28–C39, C53/C54 and
R25–R28 connections from the netlist and excludes DNP parts. It uses:

- Coilcraft's archived 0805HP-151 equivalent circuit, with its frequency-dependent
  loss evaluated at 13.56 MHz. The plotted 10–18 MHz sweeps hold this loss fixed
  and are approximate away from the carrier.
- 0.03 Ω capacitor ESR per populated RF capacitor, an assumption.
- Ideal balanced voltage sources at U6.21/TX1 and U6.19/TX2, and assumed 2.2 kΩ
  receiver loads at U6.15/RXN and U6.16/RXP. Separate 1 kΩ and 10 kΩ receiver-load
  scenarios are included; neither replaces an active AGC model.
- The existing assumed antenna equivalent: **1.559 µH, 1.5 Ω, 2 pF**. The new
  inside feed, four-layer mounting, in-loop circuitry, tag and enclosure are
  not physically represented by this equivalent.
- 1 µΩ numerical shorts for the zero-ohm TX links. Their real mounting and
  interconnect impedance is unknown.

The nominal RF result agrees with the independent earlier half-circuit result
to better than one part per million. The small difference includes the modeled
numerical TX-link resistances. This tests extraction and numerical conventions,
not physical model accuracy.

The ideal 3.3 V differential square-wave **fundamental alone** implies about
47.2 V peak across the modeled coil. This is a stress estimate, not a measured
peak or a guarantee for the 100 V capacitors; driver impedance, harmonics and
external fields are excluded. Coil conductor current in the new output refers
to current through the series RL branch, excluding its parallel capacitance.

The I²C simulation uses an ideal 3 V supply, the actual pull-ups, an assumed
capacitive bus and a switch representing an open-drain sink. R38/R39 remain DNP.
Reset and ADC simulations use only the actual passive networks and idealized
excitation. The buck/boost DC runs enforce ideal feedback regulation; they
are **not switching-converter simulations**. Analytical RC and DC expressions
independently check the numerical measurements.

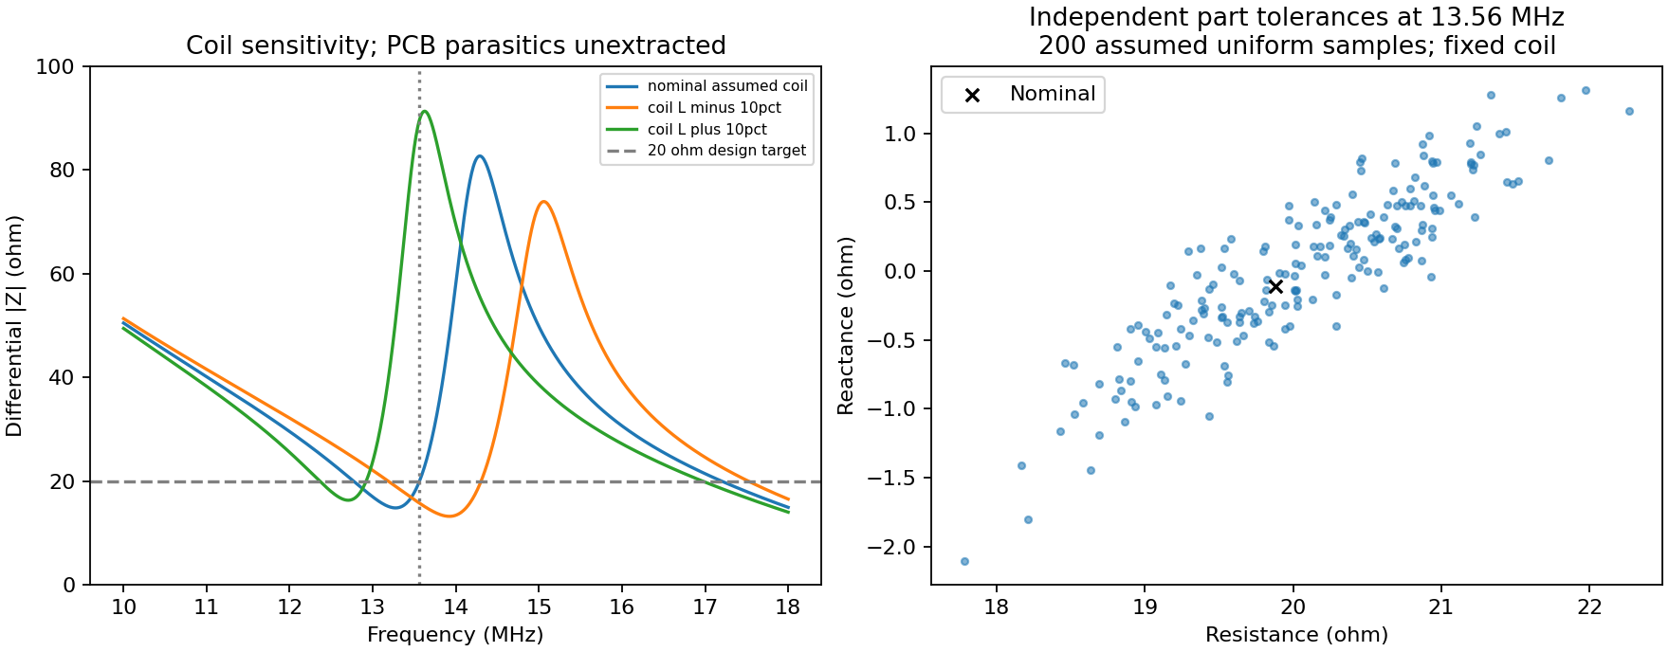
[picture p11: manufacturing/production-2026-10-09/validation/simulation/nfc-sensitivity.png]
NFC sensitivity


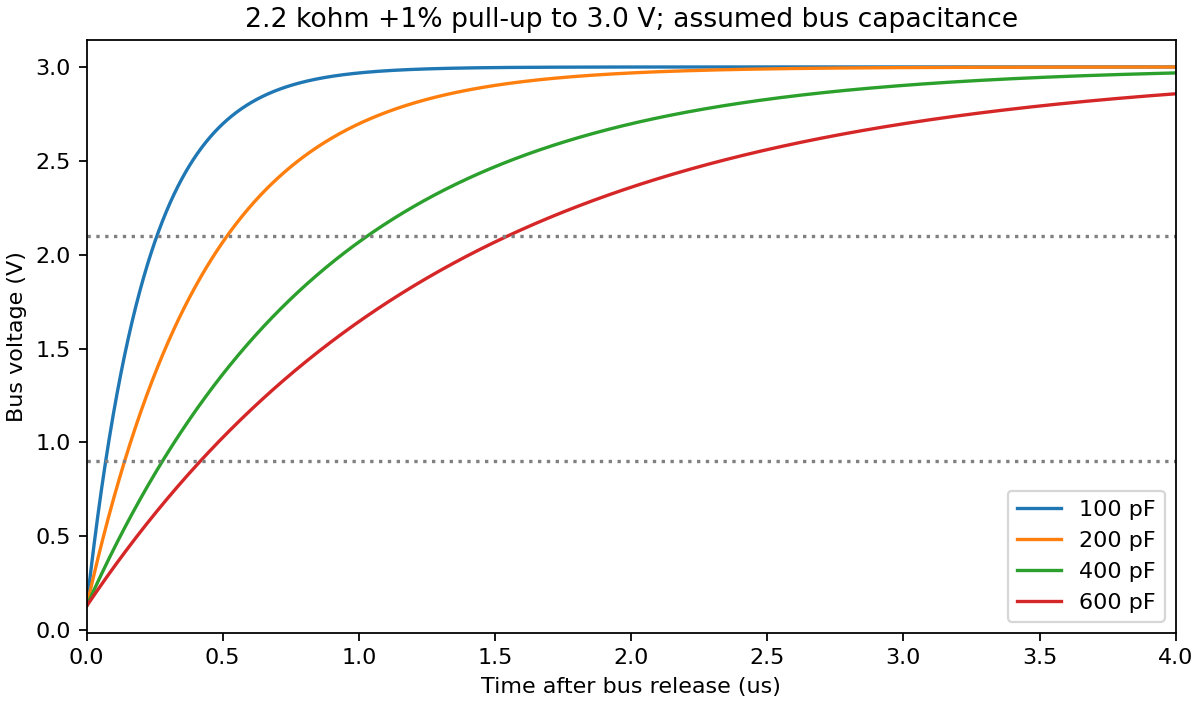
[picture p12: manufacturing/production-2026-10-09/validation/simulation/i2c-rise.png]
I²C rise time


## What still needs a different model or hardware

| Analysis | Required inputs or tool |
|---|---|
| Actual NFC antenna tuning and coupling | An EM model of the full copper/component/enclosure geometry, or a measured complex antenna impedance fitted to an RL/C model. openEMS is one possible field solver. The user reports rev-A operation without tuning; this release restores that local design. Check assembled-board repeatability before considering any tuning change. |
| SY8089 and AP3012 startup/load steps/stability | Validated models for the exact controllers, inductors, biased capacitances, loads and source impedance. The project currently has no validated switching models for these ICs. |
| Reset during fast supply dips | Exact TLV803EA30 output/timing model and buck transient waveform. TI publishes a TLV803EA29DBZ model; its 2.93 V variant cannot be silently substituted for this board's 3.08 V part. |
| USB handover/inrush and charging | Source/cable impedance, D1/D2/Q1 and charger models, battery behavior and actual loads. The existing low-VBUS charging-headroom and uncontrolled-inrush concerns remain open. |
| USB signal quality and power distribution | Extracted trace/via/plane parasitics, stackup material data and appropriate driver/receiver models. Dedicated SI/PI tools such as SIwave address this class of problem. |
| Read range, firmware, oscillator, display and temperatures | Device-specific behavioral/oscillator/thermal models and ultimately prototype measurements. Generic ideal IC substitutes would not establish those behaviors. |

The existing [layout/DRC report](../pcb-layout.md) complements these simulations.
It checks physical connectivity and clearances; it does not prove the above
electrical behaviors.

## Reproduce

Run from the repository with Python, numpy, matplotlib and a shared ngspice
library. The existing [NFC requirements](../../tools/nfc/requirements.txt) contain
the tested numerical packages. Create a local environment:

```sh
python3 -m venv .venv
.venv/bin/python -m pip install -r tools/nfc/requirements.txt
.venv/bin/python tools/simulate_preflight.py
```

With dependencies already installed, run `python3 tools/simulate_preflight.py`; set `NGSPICE_LIBRARY` to
the shared library path if different from KiCad's macOS installation. `--out`
selects another output directory. The saved `.cir` files can also be loaded into
standalone ngspice. `node-map.json` maps their nodes to schematic net names.

The complete run contains 15 NFC parameter cases, 200 part-tolerance cases,
three NFC frequency sweeps, eight I²C cases, three passive RC transients and
32 ideal DC-regulation cases. All completed without solver errors. The bundled
library reports a missing optional `spinit` initialization file; no XSPICE
models or initialization commands are used here, and the independent analytical
cross-checks pass.

## References

- [KiCad simulator and model requirements](https://docs.kicad.org/10.0/en/eeschema/eeschema.html#simulator)
- [Analog Devices LTspice models and demonstration circuits](https://www.analog.com/en/resources/design-tools-and-calculators/ltspice-simulator/lt-spice-demo-circuits.html)
- [openEMS electromagnetic field solver](https://www.openems.de/)
- [Ansys SIwave signal/power integrity and EMI analysis](https://ansys.synopsys.com/products/electronics/ansys-siwave)
- [NXP I²C specification, Table 10](https://www.nxp.com/docs/en/user-guide/UM10204.pdf)
- [NXP PCF8574/PCF8574A datasheet](https://www.nxp.com/docs/en/data-sheet/PCF8574_PCF8574A.pdf)
- [TI TLV803E datasheet and simulation models](https://www.ti.com/product/TLV803E)
- [Existing NFC assumptions and manufacturer-model provenance](../nfc-antenna.md#complete-differential-matching-network)
- [Existing converter, panel and supply assumptions](../peripherals-design.md)

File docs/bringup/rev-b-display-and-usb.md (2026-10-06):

# Rev-A findings: display correction and USB backfeed investigation

6 October 2026. The editable root design builds on revision-B's September routing
repair. The fabricated Rev-A provenance and original measurements remain in
[rev-A-provenance.json](rev-A-provenance.json) and
[rev-A-usb-battery-2026-10-01.json](rev-A-usb-battery-2026-10-01.json).

**Display wiring is corrected and routed. The subsequent [USB hardware redesign](usb-backfeed-fix.md)
implements the remedy based on the accepted U4 diagnosis; physical validation is pending.
No new fabrication release is approved by these software checks.** Archived manufacturing ZIPs have not
been updated and still contain the reversed display wiring.

## Display correction

The user confirmed that the mounted ribbon has display pin 1 on the left and
pin 24 on the right, viewed from the PCB component side. The existing Hirose
socket is correctly sized and oriented. It stays at (80.00, 108.85) mm, 180°,
with the same top-contact lands, mounting pads, paste, body and ribbon access.

At this rotation, **Hirose socket pad 24 is PCB-left and socket pad 1 is
PCB-right**. The corrected connection is therefore:

`display ribbon pin n → DS1 socket pad (25 − n)`

The new `SSD1309_COG_24_ReversedSocket` symbol makes the electrical change while
preserving manufacturer pad numbers in the footprint. DS1 symbol numbers are
socket pads; panel functions keep their names. The schematic note, pinout JSON
and PCB `FLEX 1` / `24` legend explicitly identify the mounted ribbon order.

| Display contacts | Socket pads | Connection |
|---|---|---|
| 1, 2, 3 | 24, 23, 22 | GND |
| 4 | 21 | NC, isolated |
| 5, 6 | 20, 19 | +3V0 |
| 7, 8 | 18, 17 | GND |
| 9 | 16 | OLED_RES_N |
| 10, 11, 12 | 15, 14, 13 | GND |
| 13 | 12 | I2C_SCL |
| 14, 15 | 11, 10 | I2C_SDA |
| 16–20 | 9–5 | GND |
| 21 | 4 | OLED_IREF |
| 22 | 3 | OLED_VCOMH |
| 23 | 2 | OLED_12V5 |
| 24 | 1 | GND |

At commit `03404a2`, the connector fanout and local OLED routes were rebuilt, ground buses restored
and a ground stitching via added to connect the new front copper island. All
130 footprint positions and all component values/population remain unchanged.
The copper outside the display work, including USB and the NFC matching tree,
is preserved. That saved board had 1,044 trace segments and 320 routing vias.
Two reference labels moved to the fabrication layer and one Q5 legend segment
was clipped to clear open vias.

The new [physical contact checker](../../tools/check_display_mapping.py) checks
the left-to-right net sequence independently of schematic parity. Its regression
test deliberately reverses both the schematic and PCB together: they still
agree with each other, but the mounted-panel check rejects them. This closes
the verification gap that allowed Rev-A's electrical reversal to pass ERC/DRC.

Before powering a panel, check continuity from its actual ribbon contacts to
the listed nets, especially display 5/6 (+3V0), 23 (12.5 V), and the grounds.
Then validate reset, I²C response and display operation with the corrected board.

## Backfeed evidence and circuit review

The [6 October measurements](rev-A-usb-battery-2026-10-06.json), transcribed
from the user's [annotated Rev-A sheet](measurements/rev-A-usb-battery-2026-10-06.pdf),
were explicitly confirmed to be taken with USB physically disconnected:

| Battery only | RESET released | RESET held |
|---|---:|---:|
| C14.1 — VBUS | 2.05 V | 0.01 V |
| R13.1 — D+ | 2.84 V | 0.00 V |
| C11.1 — +3V3 | 3.33 V | 3.33 V |

D+ and VBUS fall together while the steady 3.3 V rail stays unchanged. This
strongly supports the suspected USB-data backfeed path and removes a sustained
3.3 V collapse as the explanation for these RESET-held readings. The released
D+−VBUS difference is 0.79 V, consistent with a forward-biased steering diode.
These are steady meter readings, not simultaneous transient captures; U4 has
not yet been physically isolated, so the particular component path is still
an inference. Battery voltage, firmware/mode and meter input impedance were
not supplied.

The earlier sheet's 5.17 V VBUS readings were taken **with USB connected**, as
the user subsequently confirmed. They are retained separately as a powered
control, not battery-only evidence. The original 1 October battery-only result
(approximately 2.1 V, falling near zero on RESET) remains consistent with the
new measurements. The USB reconnect workaround was verified once; ROM
download-mode entry was not independently confirmed.

**Decision, 6 October:** the user does not have the tools for U4 pin-isolation
rework and has instructed us to proceed using the existing measurements as
the basis for the diagnosis. We accept ESP32 D+ → R13 → U4 → VBUS as the
working cause for the redesign. Physical isolation was not performed and is
not a prerequisite for that work. The isolation instructions below remain an
optional diagnostic reference. The subsequent [USB redesign](usb-backfeed-fix.md)
implements the remedy; the following topology describes the historical Rev-A circuit.

The Rev-A schematic and PCB contain this possible DC path:

```mermaid
flowchart LR
  P["ESP32 IO19 / D+ pull-up"] --> R["R13: 22 Ω"]
  R --> U["U4.4: upper steering diode"]
  U --> V["U4.5 / connector VBUS"]
  V --> C["C14: 100 nF"]
  V --> G["R18: 100 kΩ to ground"]
  V --> Q["Q2 gate: USB_PRESENT_N detector"]
```

This inference follows the rail-to-rail topology in the
[ST USBLC6-2 datasheet](https://www.st.com/resource/en/datasheet/usblc6-2.pdf).
D1/D2's power-path isolation does not interrupt this data-line path. At 2.05 V,
nominal 100 kΩ R18 alone draws 20.5 µA, so VBUS is being replenished continuously. USB-C source
attachment checks include VBUS reaching vSafe0V; retained VBUS can therefore
explain the observed failure to turn host power back on.
[USB-IF functional test specification](https://www.usb.org/sites/default/files/USB%20Type%20C%20Functional%20Test%20Specification%202024%2003%2003.pdf).

Q2 is not a precision 5 V detector. Its BSS138 threshold specification is
0.8–1.5 V at the stated test current, so 2.05 V at its gate can plausibly assert
`USB_PRESENT_N` even without USB power. Measure the output before relying on
that signal for a firmware-only remedy.
[onsemi BSS138 datasheet](https://www.onsemi.com/pdf/datasheet/bss138-d.pdf).

The [39 added ngspice cases](backfeed-analysis/results.json) exercise the
suspected path, disabled pull-up, isolated U4.5 and passive discharge. They use
the actual R13/R18/C14 values with an assumed 1.5 kΩ pull-up and a range of
illustrative diode parameters. They establish qualitative plausibility, not
the exact measured voltage or a verified repair. With every source removed, the
R18/C14-only model decays from 5.25 V to 0.8 V in roughly 19–21 ms. Cable
capacitance and other leakage are excluded. Total injected current must stay
below about 7.92 µA to keep VBUS under 0.8 V at R18's +1% corner.

## Measurements to distinguish the paths

Start with the [glanceable Rev-A bench guide](rev-A-usb-bench.md), including
the [printable pad map and six-reading table](rev-A-usb-bench-guide.pdf).
Its locations come from the exact fabricated Rev-A board, not the edited layout.

Use the same Rev-A board/firmware as the recorded failure. Record battery
voltage and meter/probe input impedance. Keep USB physically unplugged for
steps 1–4. Clip the black meter lead to the grounded J1 USB metal shell. The
[CSV worksheet](usb-backfeed-measurements.csv) now contains the six first-pass
readings above; the load/isolation and post-repair rows remain unmeasured.

1. With RESET released, then held, measure C14 pad 1 (raw VBUS), R13 pad 1
   (D+ / U4.4), and C11 pad 1 (+3V3). A scope capture of all three during RESET
   is preferable. Also record C12 pad 1 (ESP_EN), C1 pad 1 (USB_5V), C4 pad 1
   (VSYS), R17 pad 2 (USB_PRESENT_N), and R12 pad 1 (D−). If +3V3 collapses
   during RESET, reassess the power path instead of attributing everything to D+.
2. Repeat with a temporary 10 kΩ resistor from raw VBUS to GND, attached with
   power removed. Record VBUS and D+; the added load current is VBUS / 10 kΩ.
   This distinguishes a weak leakage path from sustained data-line drive.
   Remove the resistor afterward. A stronger pulldown is not a permanent fix.
3. With battery and USB disconnected, isolate **only U4 pin 5** from its VBUS
   pad (lift the lead or cut its exclusive branch after tracing it). Preserve
   J1–D1–C14–R18–Q2 continuity. Verify the isolation with an ohmmeter before
   applying battery power. This is a temporary diagnostic rework; it removes
   U4's protection of raw VBUS, so do not treat it as a released modification.
   In the Rev-A component-side view with NFC above and keyboard below, pin 5
   is U4's **middle leg on the right**, toward C14. The
   [top/side-view illustration](rev-A-U4-pin5-isolation.png) shows lifting just
   this lead clear of its pad. Use flux and heat to release the solder before
   lifting gently; do not pry a cold lead or pull up the PCB pad. Under
   magnification, verify a visible gap and no bridges to pins 4/6. With power
   removed, check that the lead has no near-zero-ohm metallic connection to
   its former pad; other semiconductor paths can still give finite readings.
4. Repeat step 1 on battery only, measuring the lifted U4.5 separately from
   C14.1. VBUS falling below 0.8 V while D+ and +3V3 remain high strongly
   identifies U4's branch. If VBUS remains high, investigate D1/D2 reverse
   leakage, charger coupling, contamination/assembly faults and Q2 before
   choosing a power-path redesign. Restore the temporary rework before normal use.

After isolating the source, the permanent design must break data-to-VBUS
injection while retaining both data-line and VBUS ESD protection. A suitable
direction is ground-referenced USB data protection plus a separate VBUS TVS;
its exact part, clamping behavior and footprint need review before routing.
Simply moving U4.5 to USB_5V can instead energize the charger/Q1 gate branch.
Simply leaving it floating omits the original VBUS protection. Neither is
claimed as the final repair here.

The final remedy must also provide VBUS-dependent USB attachment and be checked
in normal firmware and **protocol-confirmed** ROM download mode. Repeat at
least 20 USB-C unplug/replug cycles with the battery attached, both cable
orientations, low/full battery and more than one source/cable. Capture VBUS
decay, +3V3 continuity, D+ attachment and host enumeration; record actual
worst-case values. The 20-cycle count is a project bench screen, not USB certification.

## Validation and reproduction

Current reports: [ERC/pin checks](../verification.json), [DRC](../pcb/drc.json),
[layout](../pcb/layout-check.json), [fabrication](../pcb/standard-fabrication-check.json),
[routing quality](../pcb/routing-quality.json), [mounted display](../oled24/mounted-mapping-check.json),
[Gerber/drill readback](gerber-readback.json),
[261 existing simulations](../simulation/results.json), and
[backfeed analysis](backfeed-analysis/results.json).

ERC has zero violations. Native DRC has zero errors, unconnected items and
parity findings. All 21 layout, 16 fabrication, six routing-quality and eight
mounted-display checks pass; five routing tests and two display regression
tests pass. Forty previously reviewed cosmetic DRC warnings remain. The two
existing USB routing advisories remain: 0.9915 mm skew and two missing In2
ground-reference samples. They are separate from the DC backfeed investigation.

All 12 independent Gerbonara export checks pass, including the corrected
24-contact display net order, lands/mask/paste, component placement population,
all drill locations/sizes and the closed board outline. Excellon coordinates
are compared within half its 0.001 mm output resolution. The native NFC coupon,
coil simulation/geometry, inside-feed geometry and all 12 inside-feed native
regression fixtures also pass. A before/after
[change audit](rev-b-change-audit.json) records preservation of placement,
non-display pad nets, component values/population, board outline and rules.

Use the full sequence in [PCB layout](../pcb-layout.md#reproduce), then run
`tools/check_display_mapping.py`, `tools/test_display_mapping.py` and
`tools/analyze_usb_backfeed.py`. The last tool needs the same numpy/matplotlib
and ngspice environment as the existing simulator. Export only to a fresh
validation directory with `tools/export_standard_fabrication.py --out <directory>`;
then run `tools/check_standard_export.py <directory>` with Gerbonara installed.
The exporter refuses to overwrite archived packages. The historical isolated
OLED/USB regression scripts describe their earlier changes, not this revision.

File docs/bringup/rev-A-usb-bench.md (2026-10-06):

# Rev-A USB backfeed: first bench measurements

[User-annotated one-page guide (PDF)](rev-A-usb-bench-guide.pdf) ·
[Full-resolution image](rev-A-usb-bench-guide.png) ·
[Measurement worksheet (CSV)](usb-backfeed-measurements.csv)

**6 October results are recorded:** VBUS 2.05 → 0.01 V, D+ 2.84 → 0.00 V,
+3V3 3.33 → 3.33 V (RESET released → held, USB disconnected).
The [preserved measurement sheet](measurements/rev-A-usb-battery-2026-10-06.pdf)
and [structured record](rev-A-usb-battery-2026-10-06.json) retain the evidence.
The image below is the original blank guide; the PDF contains the user's notes.

The user has accepted the U4 backfeed diagnosis from these readings and elected
to proceed without pin-isolation rework because the required tools are not
available. Further isolation is optional; the hardware remedy remains to be designed.

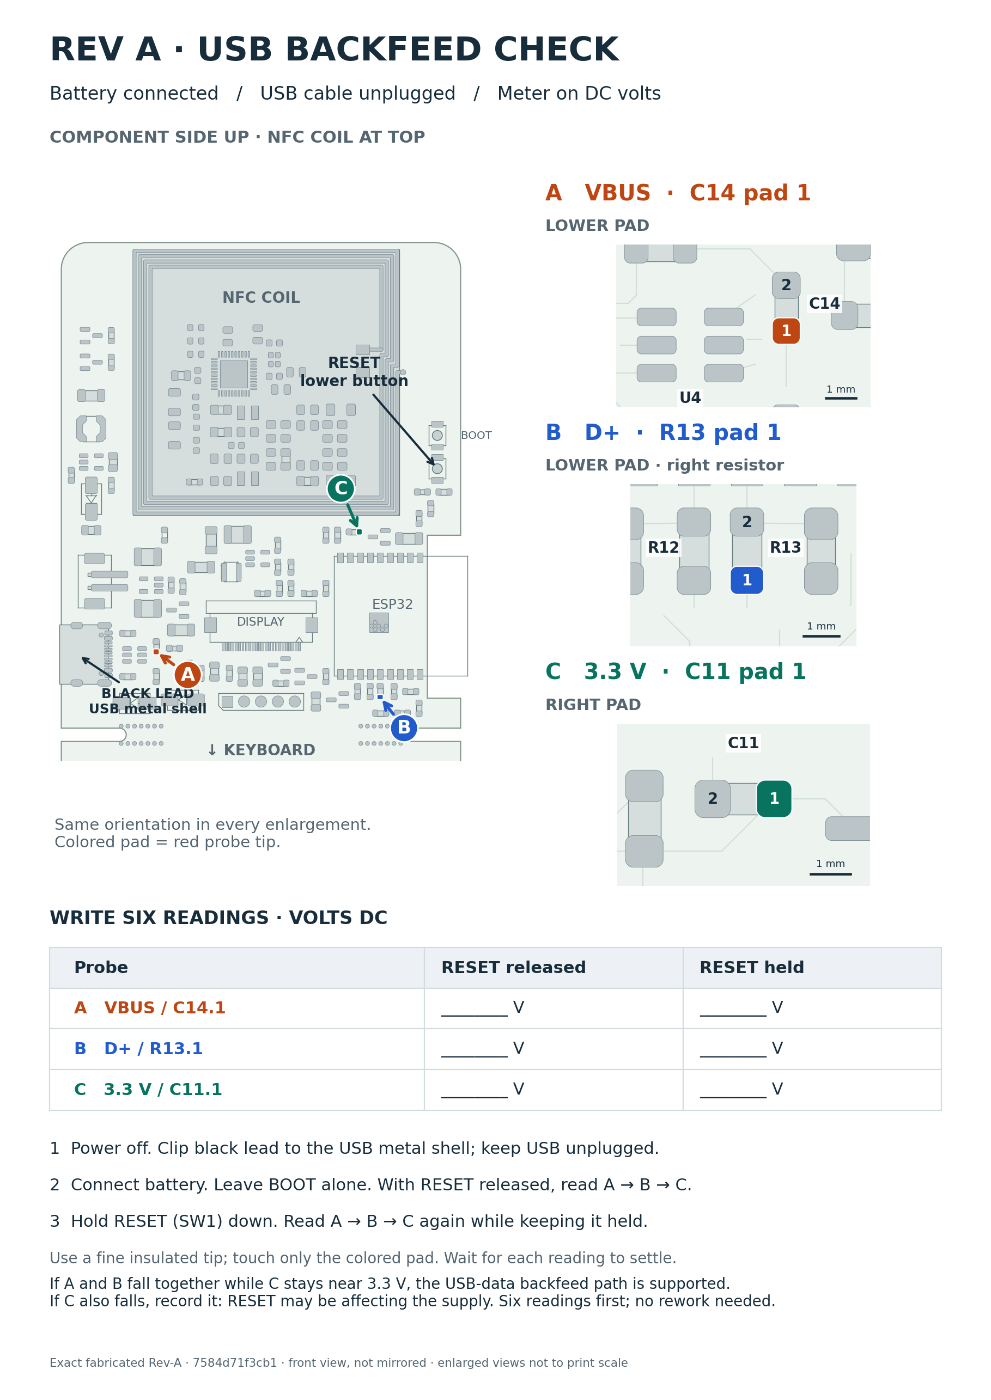
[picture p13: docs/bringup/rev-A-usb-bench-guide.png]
Rev-A probe locations, pad enlargements and six-reading worksheet


## Procedure

1. Disconnect USB and battery. Put the board **component side up, NFC coil at
   the top, keyboard below**. Set the meter to DC volts. Clip its black lead to
   the **USB connector's metal shell**, which is connected to GND. Use a fine
   insulated red probe so it cannot bridge adjacent pads.
2. Connect the battery and let the existing firmware start. Keep USB physically
   unplugged. Leave BOOT alone. With RESET released, record **A, B, C** below.
3. Press and **keep holding RESET (SW1, the lower of the two buttons)**. Record
   **A, B, C** again while it is held. Wait for each reading to settle; record
   the actual voltage, including small residual voltages.
4. Release RESET. Record battery voltage, firmware/mode, meter model/input
   impedance, and any unstable readings. The table below contains the six
   user-reported readings from 6 October; supplementary setup details remain unknown.

| Red probe | Exact pad, in the pictured orientation | RESET released | RESET held |
|---|---|---|---|
| **A — VBUS** | **C14 pad 1: lower pad**, next to U4 near USB | 2.05 V | 0.01 V |
| **B — D+** | **R13 pad 1: lower pad**, the right resistor of R12/R13 below ESP32 | 2.84 V | 0.00 V |
| **C — +3V3** | **C11 pad 1: right pad**, above ESP32 | 3.33 V | 3.33 V |

If VBUS is already near zero after starting on battery alone, repeat the normal
failure sequence: leave the battery attached, connect USB and let it enumerate,
then physically unplug USB and repeat the six readings. Note which sequence
produced each result. Do not leave USB connected during the measurements.

If VBUS and D+ both fall with RESET while +3V3 stays near 3.3 V, this supports
the suspected USB-data-to-VBUS path through U4. It does not alone prove which
component conducts. If +3V3 also drops, investigate the power/reset interaction.
Record a different pattern as observed rather than fitting it to the hypothesis.

No solder rework is needed for this first pass. The
[extended investigation](rev-b-display-and-usb.md#measurements-to-distinguish-the-paths)
covers subsequent load and U4 isolation measurements if needed.

## Map provenance

The graphic uses exact pad polygons and component outlines from the **fabricated
Rev-A commit `7584d71f3cb1b120934be2b80cfab4a015ecddfd`**, viewed from the front
without mirroring. It does not use the changed Rev-B placement. The
[map manifest](rev-A-usb-bench-guide.json) records the verified nets, coordinates,
board hash and original generated output hashes. The user's later PDF annotations
are hashed separately in the measurement record above. All three colored pads are exposed front-side pads;
the USB shell's `SH` pads are GND. Views are enlarged, not to print scale.

Generate a new blank copy with pcbnew/matplotlib-enabled Python. The renderer
refuses to overwrite changed files, preserving handwritten or typed measurements:

```sh
python3 tools/render_rev_a_bench_guide.py --out-stem /tmp/rev-A-usb-bench-blank
```

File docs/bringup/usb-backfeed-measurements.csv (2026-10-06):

timestamp | board_revision | firmware_or_confirmed_ROM | state | VBAT_V | VBUS_C14_1_V | Dplus_R13_1_V | 3V3_C11_1_V | ESP_EN_C12_1_V | USB5V_C1_1_V | VSYS_C4_1_V | USB_PRESENT_N_R17_2_V | Dminus_R12_1_V | isolated_U4_5_V | probe_input_ohm | notes
2026-10-06 | rev-A |  | battery_only_reset_released |  | 2.05 | 2.84 | 3.33 |  |  |  |  |  |  |  | User-annotated PDF; USB physically disconnected; firmware, VBAT and meter impedance not supplied; see rev-A-usb-battery-2026-10-06.json
2026-10-06 | rev-A |  | battery_only_reset_held |  | 0.01 | 0.0 | 3.33 |  |  |  |  |  |  |  | User-annotated PDF; USB physically disconnected; firmware, VBAT and meter impedance not supplied; see rev-A-usb-battery-2026-10-06.json
 |  |  | battery_only_10k_VBUS_load_reset_released
 |  |  | battery_only_U4_pin5_isolated_reset_released
 |  |  | battery_only_U4_pin5_isolated_reset_held
 |  |  | corrected_hardware_USB_unplug_transition
 |  |  | corrected_hardware_USB_reconnect_normal_firmware
 |  |  | corrected_hardware_USB_reconnect_protocol_confirmed_ROM

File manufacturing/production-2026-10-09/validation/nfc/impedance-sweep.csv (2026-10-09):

frequency_Hz | Zdiff_real_ohm | Zdiff_imag_ohm | return_loss_target_dB | coil_voltage_gain
8000000.0 | 3.6901799442212946 | -74.47174278676111 | 0.21517377528249326 | 0.24281268543407053
8010000.0 | 3.6893182091651413 | -74.33097026531608 | 0.21588284532629304 | 0.24385857810401573
8020000.0 | 3.6884687197558907 | -74.19046492852539 | 0.21659475281646842 | 0.24490927024659528
8030000.0 | 3.687631455347657 | -74.05022560575699 | 0.21730951263923898 | 0.24596479019472856
8040000.0 | 3.6868063957579835 | -73.91025113108266 | 0.21802713979272936 | 0.24702516649744063
8050000.0 | 3.685993521267582 | -73.7705403432399 | 0.21874764938804336 | 0.24809042792187874
8060000.0 | 3.6851928126201043 | -73.63109208559408 | 0.21947105665038244 | 0.24916060345535201
8070000.0 | 3.6844042510219666 | -73.49190520610077 | 0.22019737692015703 | 0.25023572230739455
8080000.0 | 3.683627818142191 | -73.35297855726819 | 0.22092662565411034 | 0.2513158139118521
8090000.0 | 3.682863496112307 | -73.21431099612005 | 0.2216588184264792 | 0.25240090792899006
8100000.0 | 3.6821112675262757 | -73.07590138415821 | 0.22239397093013955 | 0.2534910342476264
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

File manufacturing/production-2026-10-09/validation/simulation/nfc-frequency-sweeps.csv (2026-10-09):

scenario | frequency_Hz | z_real_ohm | z_imag_ohm
nominal_assumed_coil | 10000000.0 | 3.999472785822007 | -50.31508020767305
nominal_assumed_coil | 10010000.0 | 4.0006577290512135 | -50.20846165153374
nominal_assumed_coil | 10020000.0 | 4.001863163770807 | -50.10192626992248
nominal_assumed_coil | 10030000.0 | 4.003089727043831 | -49.99547309243082
nominal_assumed_coil | 10040000.0 | 4.004337168794375 | -49.889101289083165
nominal_assumed_coil | 10050000.0 | 4.005605660402475 | -49.78280996009379
nominal_assumed_coil | 10060000.0 | 4.006895500114981 | -49.676598182827064
nominal_assumed_coil | 10070000.0 | 4.00820696798941 | -49.5704650350878
nominal_assumed_coil | 10080000.0 | 4.009539901573686 | -49.46440966435986
nominal_assumed_coil | 10090000.0 | 4.010894550415756 | -49.358431148847885
nominal_assumed_coil | 10100000.0 | 4.012271286483686 | -49.25252854410241
nominal_assumed_coil | 10110000.0 | 4.0136700426219445 | -49.14670097501951
nominal_assumed_coil | 10120000.0 | 4.01509101702856 | -49.04094752058856
nominal_assumed_coil | 10130000.0 | 4.0165345288566145 | -48.935267237137644
nominal_assumed_coil | 10140000.0 | 4.018000463939872 | -48.82965924987791
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

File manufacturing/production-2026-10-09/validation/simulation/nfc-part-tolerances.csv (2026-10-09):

case | z_real_ohm | z_imag_ohm | z_abs_ohm | coil_rms_A_at_3V3_fundamental | coil_peak_V_at_3V3_fundamental
0 | 19.514235561496907 | 0.029346405692270514 | 19.51425762772229 | 0.24053988188660624 | 45.18734543616551
1 | 19.518615284967435 | -0.33498694579286253 | 19.521489668988277 | 0.24009440493736 | 45.10365901946173
2 | 19.81166969231258 | 0.18122911225243019 | 19.812498580149466 | 0.23789689099764658 | 44.690838406448265
3 | 19.21162539653407 | -0.5443407927778894 | 19.21933550556405 | 0.2422088586053053 | 45.50087609445495
4 | 20.47586975160999 | 0.07914449945287966 | 20.476022707955043 | 0.23490101892212692 | 44.12803981647102
5 | 21.197887571445285 | 0.7899809174370113 | 21.212602559364306 | 0.23189612158675774 | 43.56354575906749
6 | 20.006307616394547 | -0.1386982751382368 | 20.006788389277595 | 0.23773163073414222 | 44.65979294090935
7 | 20.21303320354953 | 0.10612260470513135 | 20.213311784441093 | 0.2363111661813002 | 44.392947285520854
8 | 20.010265963489008 | -0.036153734882550505 | 20.010298624011405 | 0.23757344150521098 | 44.630075825909834
9 | 19.94421942897939 | -0.41709048114107256 | 19.94858022769384 | 0.23754646011046487 | 44.62500715457274
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

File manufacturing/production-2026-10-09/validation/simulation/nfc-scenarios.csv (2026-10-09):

scenario | la | ra | ca | z_real_ohm | z_imag_ohm | z_abs_ohm | coil_rms_A_at_3V3_fundamental | coil_peak_V_at_3V3_fundamental | extra_shunt | rin
nominal_assumed_coil | 1.5590049325492093e-06 | 1.5 | 2e-12 | 19.879569663593923 | -0.1068760617018122 | 19.879856953767263 | 0.23826360960529885 | 44.759729437207405
coil_L_minus_10pct | 1.4031044392942883e-06 | 1.5 | 2e-12 | 7.857787545965274 | -13.63174991047695 | 15.734339221566163 | 0.16135449875341373 | 27.280970665642712
coil_L_plus_10pct | 1.7149054258041303e-06 | 1.5 | 2e-12 | 81.07571382765607 | -38.02835812707426 | 89.55125568357485 | 0.11279226420668848 | 23.30756640086217
extra_1pF_each_match_node | 1.5590049325492093e-06 | 1.5 | 2e-12 | 21.667108641922823 | 0.8197797582008055 | 21.682611368394777 | 0.22964380370900803 | 43.14042978688161 | 1e-12
extra_3pF_each_match_node | 1.5590049325492093e-06 | 1.5 | 2e-12 | 26.038714729467507 | 2.542828308518975 | 26.162580923318586 | 0.21125994467395334 | 39.68687446727603 | 3e-12
rx_load_1k | 1.5590049325492093e-06 | 1.5 | 2e-12 | 19.89450514831096 | -0.06959346959788518 | 19.894626871273104 | 0.23791141693563503 | 44.69356722036686 |  | 1000
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

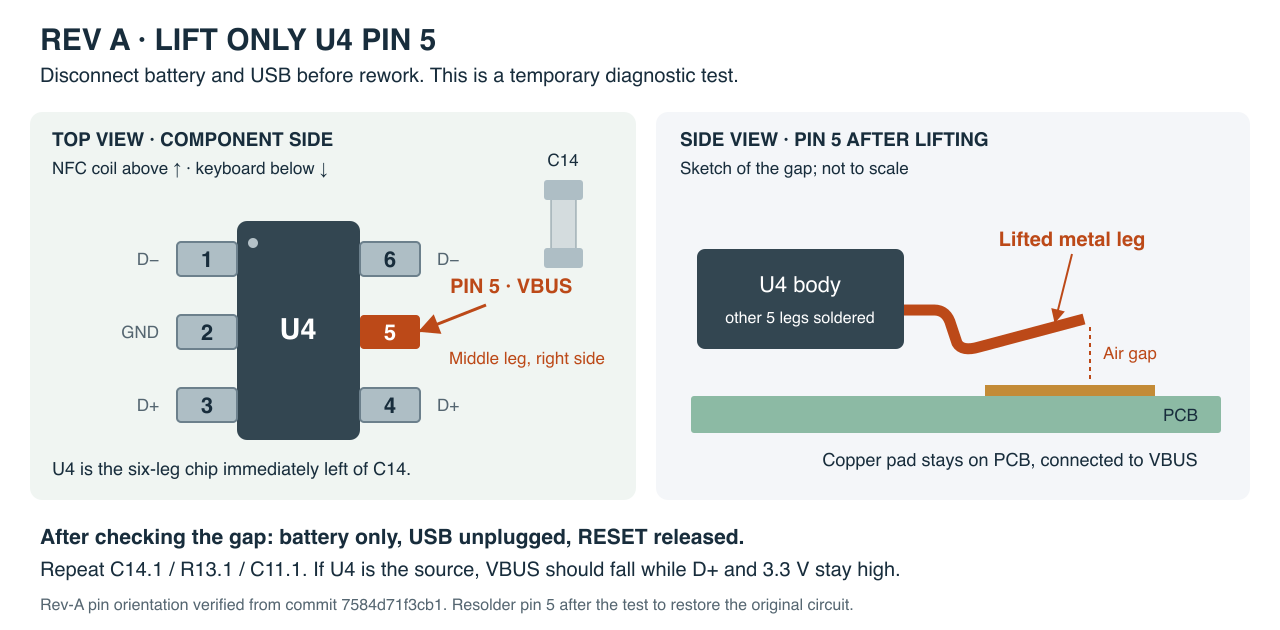
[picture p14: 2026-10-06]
docs/bringup/rev-A-U4-pin5-isolation.png

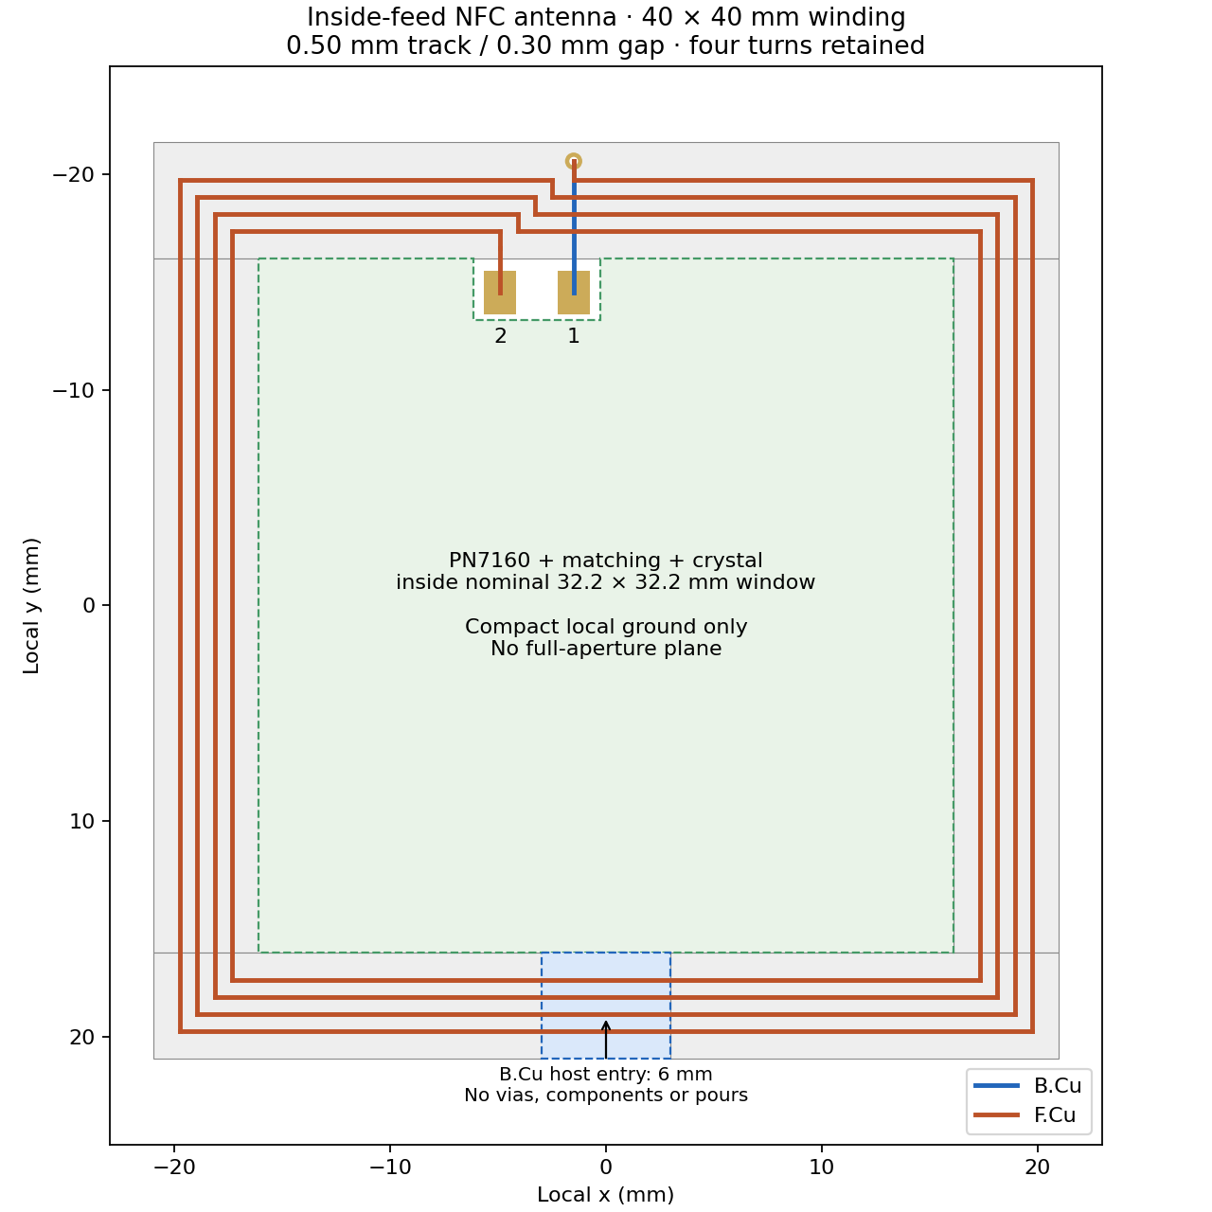
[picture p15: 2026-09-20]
manufacturing/production-2026-10-09/validation/nfc/inside-feed/coil.png

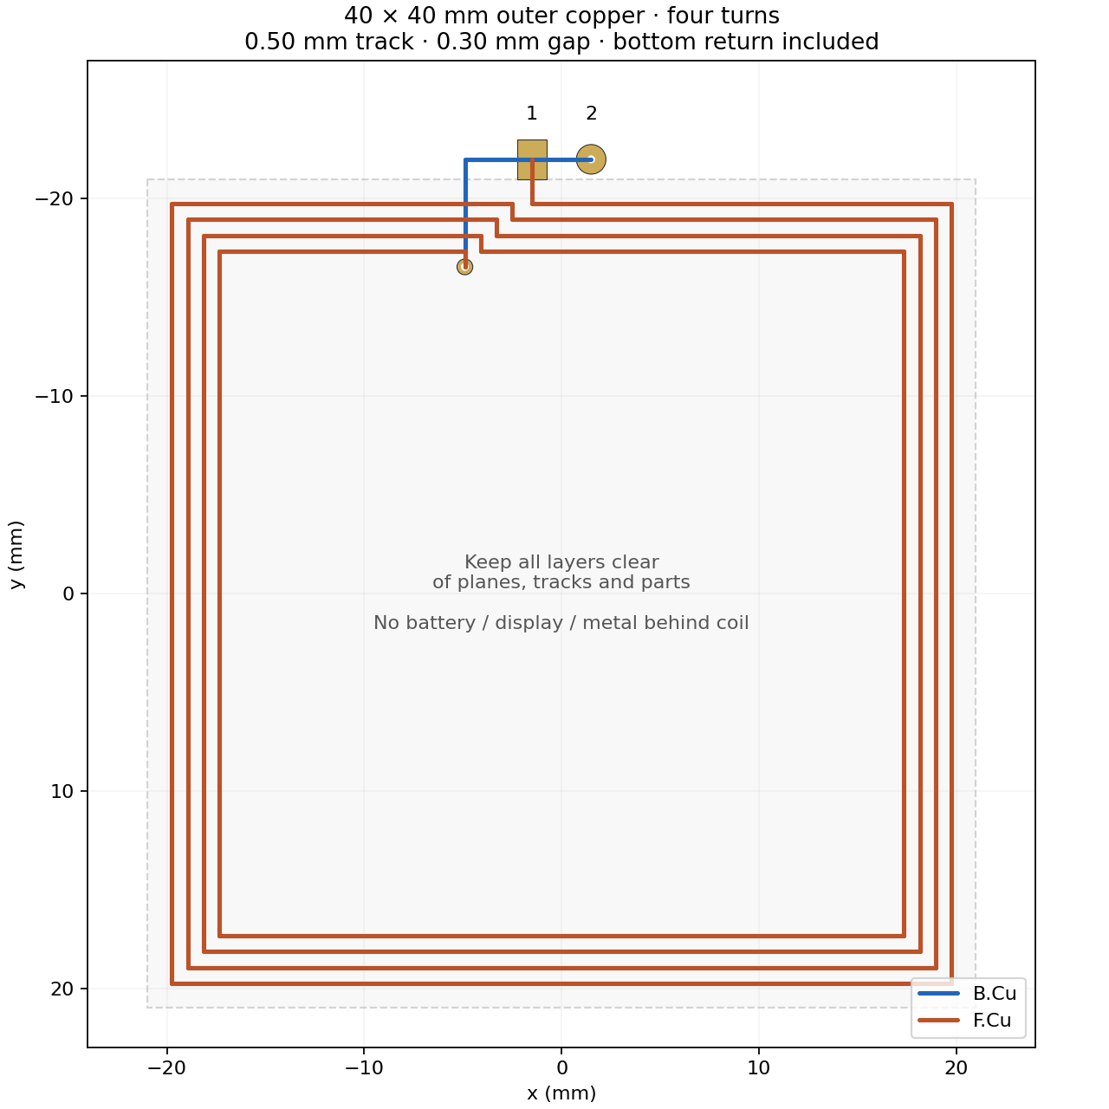
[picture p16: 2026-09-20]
manufacturing/production-2026-10-09/validation/nfc/coil.png

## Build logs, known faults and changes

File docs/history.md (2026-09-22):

# Development history

The 17 original development commits were restored after the initial public
release used a single snapshot. Their original order, messages, author names,
author timestamps and committer timestamps are preserved. Both email fields use
the maintainer's GitHub no-reply identity. Historical personal paths, editor
state, workstation configuration and the restricted PN7160 3D model were removed;
nested archives and their checksums were sanitized as well.

Scrubbing changes Git object IDs. This map connects the original revision IDs
used by design reports, regression baselines and manufacturing manifests with
the corresponding public commits. The publication cleanup follows these commits
with its original September 22 timestamp; r2 changes that were uncommitted before
publication remain part of that cleanup rather than being assigned invented dates.

| Original author timestamp | Original revision | Public revision | Commit message |
|---|---|---|---|
| 2026-09-19T15:51:52+02:00 | `f0c1464` | [6b27609](https://github.com/zeugmaster/nucula-board/commit/6b276092c9259aabafe40b369c41f86b91687fc1) | Initialize KiCad project version control |
| 2026-09-19T16:26:53+02:00 | `213d2f3` | [4f9947c](https://github.com/zeugmaster/nucula-board/commit/4f9947c3936ad34a266f64537e2f12122101958f) | Draft ESP32-C3 USB-C and Li-ion power schematic |
| 2026-09-20T00:24:32+02:00 | `4abfd13` | [14cc2f2](https://github.com/zeugmaster/nucula-board/commit/14cc2f21f3a6a164a49174e989257ac59c567f0f) | Set 400 mAh battery target with JST-PH connector |
| 2026-09-20T01:17:07+02:00 | `b53ab0f` | [cfc0a15](https://github.com/zeugmaster/nucula-board/commit/cfc0a15dc0fa66233eac9acc17762b009c61673a) | Integrate NFC, OLED and breakaway I2C keyboard |
| 2026-09-20T16:59:40+02:00 | `162260c` | [ffa8072](https://github.com/zeugmaster/nucula-board/commit/ffa80729661c13fa6423cbea6232cedc2d707c32) | Add PCB NFC coil and refine prototype component selections |
| 2026-09-20T18:16:53+02:00 | `f72fe92` | [620e9a0](https://github.com/zeugmaster/nucula-board/commit/620e9a0b09c361a7e630645bee37224978bff467) | Keep keypad signals on center seven header pins |
| 2026-09-20T18:49:03+02:00 | `8878c5b` | [60bded4](https://github.com/zeugmaster/nucula-board/commit/60bded409d8906c1d8229b2f33225018ee2bb595) | Prepare components and JLCPCB BOM for 10-board assembly |
| 2026-09-20T23:36:58+02:00 | `6b7182d` | [eabce9f](https://github.com/zeugmaster/nucula-board/commit/eabce9fc502818d9e05a1bf46dd73501d06c9f8d) | Checkpoint preliminary four-layer PCB layout |
| 2026-09-21T00:15:50+02:00 | `210e3b8` | [a9ce620](https://github.com/zeugmaster/nucula-board/commit/a9ce620063e00828887cda2e7313f8e61e5c7d31) | Add inside-feed NFC antenna and ESP antenna notch |
| 2026-09-21T01:21:11+02:00 | `b88f7db` | [0506827](https://github.com/zeugmaster/nucula-board/commit/0506827419b707710ecff99728e8d59d94945ae5) | add break-away mouse bite line |
| 2026-09-21T01:28:15+02:00 | `f8a132d` | [21dbf25](https://github.com/zeugmaster/nucula-board/commit/21dbf25030c9c8159e9478dbf5f90c057cd02f10) | commit again after save |
| 2026-09-21T12:09:13+02:00 | `33dbf43` | [b2c0d92](https://github.com/zeugmaster/nucula-board/commit/b2c0d92daf5ada4d545dca2e925eabf4cfc48889) | Complete four-layer PCB placement and routing |
| 2026-09-21T17:24:24+02:00 | `aa6a3cd` | [d8d1cae](https://github.com/zeugmaster/nucula-board/commit/d8d1cae6b1a1729a299a26f4ac2cd00645b4f6d7) | add silkscreen label |
| 2026-09-21T17:24:43+02:00 | `600d88a` | [4402e20](https://github.com/zeugmaster/nucula-board/commit/4402e20b629fae3611d8a14672760c5120226085) | post save commit |
| 2026-09-21T18:35:52+02:00 | `96c8114` | [1fb2648](https://github.com/zeugmaster/nucula-board/commit/1fb2648f5917b3c9a2210a6645c2e7127f427d9f) | Correct OLED interface and routing for 24-pin display |
| 2026-09-21T19:30:21+02:00 | `d4eaaa9` | [cd4d2bd](https://github.com/zeugmaster/nucula-board/commit/cd4d2bd37eddcca779e9d887e21a10bd1d3ec863) | Use top-contact OLED connector and document manufacturing preparation |
| 2026-09-21T20:25:12+02:00 | `a67a5b6` | [cd4d45d](https://github.com/zeugmaster/nucula-board/commit/cd4d45d83b3ba04304c2bbd4614f6c99d1030e42) | Fix USB connector clearance and prepare JLCPCB manufacturing release |

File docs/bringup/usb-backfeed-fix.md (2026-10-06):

# USB backfeed redesign — 6 October 2026

The editable schematic and PCB remove the accepted Rev-A path from ESP32 D+,
through U4's upper steering diode, into raw VBUS. The measurements and annotated
[Rev-A PDF](measurements/rev-A-usb-battery-2026-10-06.pdf) are preserved. Physical
U4 pin isolation was not performed and is not required for this redesign, as
instructed by the user. Revised hardware has not yet been tested.

## Circuit change

```mermaid
flowchart LR
  J["USB-C D+/D−"] <--> S["U10: TS3USB30E\nVBUS-controlled data switch"]
  S <--> R["R13/R12: 22 Ω"]
  R <--> E["ESP32 native USB"]
  J --- T["U4: TPD2E2U06-Q1\nESD to GND only"]
  V["USB-C VBUS"] --> Q["Q2 + R17\nUSB_PRESENT_N"]
  Q --> S
  V --- D["D5: separate VBUS TVS to GND"]
  V --- B["R18: 10 kΩ to GND"]
```

| Reference | New selection or change | Purpose |
|---|---|---|
| U4 | TI TPD2E2U06QDCKRQ1, SC70-3, C915089 | Data protection has no VBUS/supply pin; pins 1/2 are D−/D+, pin 3 is GND |
| U10 | TI TS3USB30EDGSR, VSSOP-10, C131998 | Isolates both USB data lines when VBUS is absent |
| D5 | TI TPD1E10B06DYAR, SOD-523, C3712135 | Separate bidirectional VBUS-to-GND protection |
| C55 | 100 nF, 0603, C1591 | Local 3.3 V decoupling for U10 |
| R17 | 100 kΩ → 10 kΩ | Firm pull-up on the switch's active-low enable |
| R18 | 100 kΩ → 10 kΩ | Faster VBUS discharge and greater margin against leakage |
| C7/C8 | Remove unpopulated USB tuning capacitors | Remove unused data-line branches and make space for U10 |
| R12/R13 | Retain 22 Ω; relocate | Keep series damping between the switch and ESP32 |

U10's **DGS/VSSOP** pin map is 1=S/GND, 2=D1+/R13, 3=unused D2+,
4=connector D+, 5=GND, 6=connector D−, 7=unused D2−, 8=D1−/R12,
9=active-low OE/USB_PRESENT_N, 10=3.3 V. Pins 3 and 7 are explicitly NC.
C13/R16 move locally to provide clearance; their values and battery-monitor
connections remain unchanged. The display socket, its corrected pin order,
board outline, ESP32 placement and NFC circuitry remain unchanged.

When battery-powered with USB absent, Q2 is off and R17 disables U10. With USB
present, Q2 pulls OE low and port 1 connects both data lines. The mechanism
also applies during RESET and ROM download mode, without a firmware command.
**GPIO1 / USB_PRESENT_N must remain an input**, since it shares this hardware
enable signal. U10's power-off protection covers VCC=0; intermediate supply
ramps and hot plugging still need bench validation.

Simply inserting a switch while retaining the old VBUS-steering array could
leave a feedback loop: backfed VBUS could keep Q2 and the switch enabled.
Replacing U4 removes that loop. Its former pin 5 is not left floating, and no
data clamp is redirected into USB_5V or the charger rail.

## Part checks and model limits

[TI's U4 datasheet](https://www.ti.com/lit/ds/symlink/tpd2e2u06-q1.pdf) specifies
a ground-referenced, 5.5 V working-voltage dual TVS with 1.5 pF typical
capacitance. [D5's datasheet](https://www.ti.com/lit/ds/symlink/tpd1e10b06.pdf)
specifies a bidirectional 5.5 V TVS in the DYA/SOD-523 package. JLC calls DYA
“SOT-5X3”; selection follows the exact TI part number and package drawing.
These devices are transient clamps, not precision overvoltage regulators.
The board's ESD performance is not established by the component ratings.

[TI's switch datasheet](https://www.ti.com/lit/ds/symlink/ts3usb30e.pdf) specifies
3–4.3 V recommended supply, 10 Ω maximum on-resistance, 1 µA maximum disabled
I/O leakage and 2 µA maximum power-off leakage. The retained 22 Ω resistors
therefore give up to about 32 Ω external series resistance per conductor.
Full-speed USB packet integrity and enumeration must be tested; this is not a
controlled-impedance or eye-diagram qualification. The external U4 remains
necessary because U10's HBM rating is not board-level IEC ESD qualification.

The layout audit reports 63.1029 mm of D− copper and 50.8970 mm of D+ copper
from connector through the switch to the series resistors: a 12.2059 mm
imbalance, exceeding its 0.5 mm advisory target. This sum includes connector
branches and is not an extracted propagation delay. Two existing In2 ground
reference gaps remain near the connector, among 2,097 sampled back-layer
trace points. These advisories remain visible; neither DRC nor the DC model
qualifies USB signal integrity.

New-part public catalogue availability was observed on 6 October: U4 5,424,
U10 2,201, D5 4,647. These are dated observations, not reserved inventory.
The [assembly snapshot](../assembly/jlc-stock-snapshot.json) records sources,
timestamps, package alias and response hashes. The BOM now has 119 populated
components per board, 129 schematic components and 131 PCB footprints including
the mechanical breakaway patterns.

## Validation and follow-up

[The independent USB check](usb-backfeed-check.json) checks the exact circuit
and package pins. Fault-injection tests reconnect the TVS to VBUS, force the
switch on, select the wrong port, use the wrong supply and bridge the unused
port. They must fail even when the altered schematic and PCB agree.

[SPICE screening](backfeed-analysis/results.json) retains 36 historical Rev-A
DC cases with the **old 100 kΩ R18**, plus three revised discharge cases and
18 revised DC cases: 57 total. The revised cases assume the switch truth table
and Q2 state; they are not complete IC models. With a 15 kΩ host pull-down and
the modeled disabled leakage, connector D+ stays below 20 mV. A separate
10 µA VBUS injection stress gives at most 101 mV through the new 10 kΩ +1%
bleeder. The bleeder discharges 100 nF from 5.25 V to 0.8 V in approximately
1.88 ms nominal after **all** sources are removed. It draws 0.525 mA at 5.25 V.
Neither calculation reproduces every unplug transient or proves zero leakage.

On the revised assembled board, repeat battery-only RESET released/held readings
at C14.1 (VBUS) and C11.1 (3.3 V). Check connector-side D+ at **U4.2**; R13.1 is
now behind the switch and can legitimately remain high while disconnected.
With no host attached the connector-side data pins can float; the model's
20 mV result assumes a 15 kΩ host pull-down and is not a no-load meter limit.
With USB absent, U10.9 should be near 3.3 V and VBUS near ground. With USB
present, U10.9 should be low. Verify enumeration, ROM flashing, repeated
unplug/replug, battery-only operation and USB-powered startup without a battery.
The old Rev-A pad map remains an evidence record and does not describe U4's
new three-pin package.

Validation: ERC has zero violations; DRC has zero errors, zero unconnected
nets and zero schematic-parity findings. Its 45 reviewed cosmetic warnings
comprise 42 library/legend differences, two existing ESP32 edge/legend warnings
and one back-artwork/mask overlap clipped in the export. All 22 layout checks,
16 fabrication checks, six routing checks, eight display checks, 14 USB
topology checks and 13 Gerber/drill/stencil checks pass. The 13 regression
tests, 261 preflight SPICE cases, 57 USB SPICE cases and 12 native NFC
fixtures also pass within their documented scopes. The two USB layout
advisories above remain unmet. The [validation record](usb-backfeed-validation.json)
binds reports to the saved design. Validation exports are not a new manufacturing
release; historical manufacturing archives remain unchanged.

## Current PCB detail

These drawings show the **revised design**, not the fabricated Rev-A board.

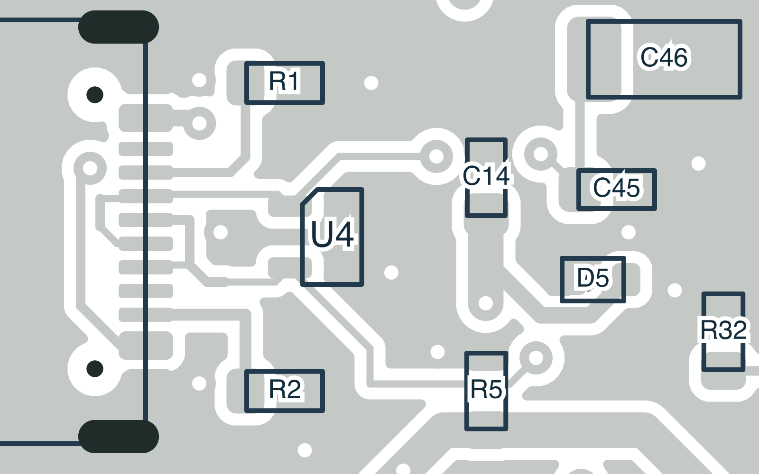
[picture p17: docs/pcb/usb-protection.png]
USB-C, new U4 and separate D5 protection


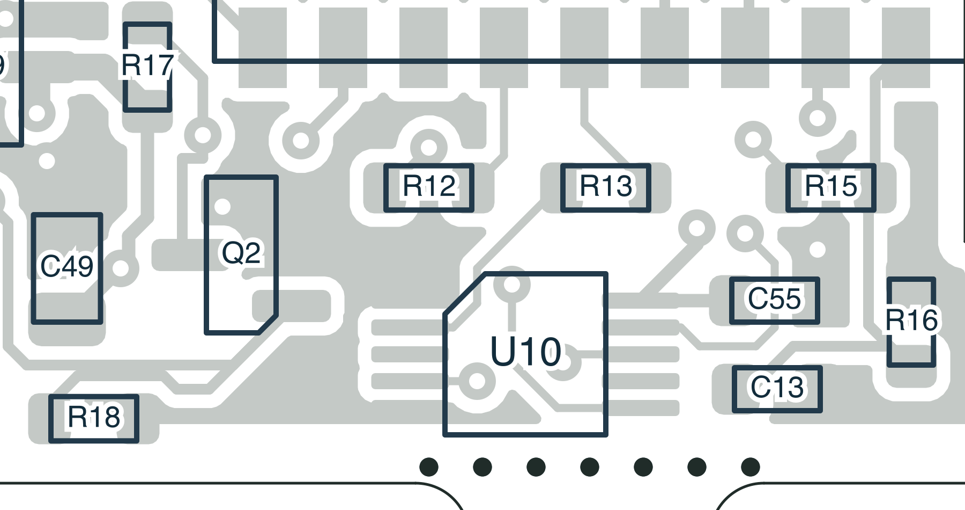
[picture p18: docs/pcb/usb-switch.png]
U10 switch, series resistors and C55 decoupling


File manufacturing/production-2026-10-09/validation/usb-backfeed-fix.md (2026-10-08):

# USB backfeed redesign — 6 October 2026

The editable schematic and PCB remove the accepted Rev-A path from ESP32 D+,
through U4's upper steering diode, into raw VBUS. The measurements and annotated
[Rev-A PDF](rev-A-usb-battery-2026-10-06.pdf) are preserved. Physical
U4 pin isolation was not performed and is not required for this redesign, as
instructed by the user. Revised hardware has not yet been tested.

## Circuit change

```mermaid
flowchart LR
  J["USB-C D+/D−"] <--> S["U10: TS3USB30E\nVBUS-controlled data switch"]
  S <--> R["R13/R12: 22 Ω"]
  R <--> E["ESP32 native USB"]
  J --- T["U4: TPD2E2U06-Q1\nESD to GND only"]
  V["USB-C VBUS"] --> Q["Q2 + R17\nUSB_PRESENT_N"]
  Q --> S
  V --- D["D5: separate VBUS TVS to GND"]
  V --- B["R18: 10 kΩ to GND"]
```

| Reference | New selection or change | Purpose |
|---|---|---|
| U4 | TI TPD2E2U06QDCKRQ1, SC70-3, C915089 | Data protection has no VBUS/supply pin; pins 1/2 are D−/D+, pin 3 is GND |
| U10 | TI TS3USB30EDGSR, VSSOP-10, C131998 | Isolates both USB data lines when VBUS is absent |
| D5 | TI TPD1E10B06DYAR, SOD-523, C3712135 | Separate bidirectional VBUS-to-GND protection |
| C55 | 100 nF, 0603, C1591 | Local 3.3 V decoupling for U10 |
| R17 | 100 kΩ → 10 kΩ | Firm pull-up on the switch's active-low enable |
| R18 | 100 kΩ → 10 kΩ | Faster VBUS discharge and greater margin against leakage |
| C7/C8 | Remove unpopulated USB tuning capacitors | Remove unused data-line branches and make space for U10 |
| R12/R13 | Retain 22 Ω; relocate | Keep series damping between the switch and ESP32 |

U10's **DGS/VSSOP** pin map is 1=S/GND, 2=D1+/R13, 3=unused D2+,
4=connector D+, 5=GND, 6=connector D−, 7=unused D2−, 8=D1−/R12,
9=active-low OE/USB_PRESENT_N, 10=3.3 V. Pins 3 and 7 are explicitly NC.
C13/R16 move locally to provide clearance; their values and battery-monitor
connections remain unchanged. The display socket, its corrected pin order,
board outline, ESP32 placement and NFC circuitry remain unchanged.

When battery-powered with USB absent, Q2 is off and R17 disables U10. With USB
present, Q2 pulls OE low and port 1 connects both data lines. The mechanism
also applies during RESET and ROM download mode, without a firmware command.
**GPIO1 / USB_PRESENT_N must remain an input**, since it shares this hardware
enable signal. U10's power-off protection covers VCC=0; intermediate supply
ramps and hot plugging still need bench validation.

Simply inserting a switch while retaining the old VBUS-steering array could
leave a feedback loop: backfed VBUS could keep Q2 and the switch enabled.
Replacing U4 removes that loop. Its former pin 5 is not left floating, and no
data clamp is redirected into USB_5V or the charger rail.

## Part checks and model limits

[TI's U4 datasheet](https://www.ti.com/lit/ds/symlink/tpd2e2u06-q1.pdf) specifies
a ground-referenced, 5.5 V working-voltage dual TVS with 1.5 pF typical
capacitance. [D5's datasheet](https://www.ti.com/lit/ds/symlink/tpd1e10b06.pdf)
specifies a bidirectional 5.5 V TVS in the DYA/SOD-523 package. JLC calls DYA
“SOT-5X3”; selection follows the exact TI part number and package drawing.
These devices are transient clamps, not precision overvoltage regulators.
The board's ESD performance is not established by the component ratings.

[TI's switch datasheet](https://www.ti.com/lit/ds/symlink/ts3usb30e.pdf) specifies
3–4.3 V recommended supply, 10 Ω maximum on-resistance, 1 µA maximum disabled
I/O leakage and 2 µA maximum power-off leakage. The retained 22 Ω resistors
therefore give up to about 32 Ω external series resistance per conductor.
Full-speed USB packet integrity and enumeration must be tested; this is not a
controlled-impedance or eye-diagram qualification. The external U4 remains
necessary because U10's HBM rating is not board-level IEC ESD qualification.

The layout audit reports 63.1029 mm of D− copper and 50.8970 mm of D+ copper
from connector through the switch to the series resistors: a 12.2059 mm
imbalance, exceeding its 0.5 mm advisory target. This sum includes connector
branches and is not an extracted propagation delay. Two existing In2 ground
reference gaps remain near the connector, among 2,097 sampled back-layer
trace points. These advisories remain visible; neither DRC nor the DC model
qualifies USB signal integrity.

New-part public catalogue availability was observed on 6 October: U4 5,424,
U10 2,201, D5 4,647. These are dated observations, not reserved inventory.
The [assembly snapshot](../assembly/jlc-stock-snapshot.json) records sources,
timestamps, package alias and response hashes. The BOM now has 119 populated
components per board, 129 schematic components and 131 PCB footprints including
the mechanical breakaway patterns.

## Validation and follow-up

[The independent USB check](usb-backfeed-check.json) checks the exact circuit
and package pins. Fault-injection tests reconnect the TVS to VBUS, force the
switch on, select the wrong port, use the wrong supply and bridge the unused
port. They must fail even when the altered schematic and PCB agree.

[SPICE screening](usb-spice-results.json) retains 36 historical Rev-A
DC cases with the **old 100 kΩ R18**, plus three revised discharge cases and
18 revised DC cases: 57 total. The revised cases assume the switch truth table
and Q2 state; they are not complete IC models. With a 15 kΩ host pull-down and
the modeled disabled leakage, connector D+ stays below 20 mV. A separate
10 µA VBUS injection stress gives at most 101 mV through the new 10 kΩ +1%
bleeder. The bleeder discharges 100 nF from 5.25 V to 0.8 V in approximately
1.88 ms nominal after **all** sources are removed. It draws 0.525 mA at 5.25 V.
Neither calculation reproduces every unplug transient or proves zero leakage.

On the revised assembled board, repeat battery-only RESET released/held readings
at C14.1 (VBUS) and C11.1 (3.3 V). Check connector-side D+ at **U4.2**; R13.1 is
now behind the switch and can legitimately remain high while disconnected.
With no host attached the connector-side data pins can float; the model's
20 mV result assumes a 15 kΩ host pull-down and is not a no-load meter limit.
With USB absent, U10.9 should be near 3.3 V and VBUS near ground. With USB
present, U10.9 should be low. Verify enumeration, ROM flashing, repeated
unplug/replug, battery-only operation and USB-powered startup without a battery.
The old Rev-A pad map remains an evidence record and does not describe U4's
new three-pin package.

Validation: ERC has zero violations; DRC has zero errors, zero unconnected
nets and zero schematic-parity findings. Its 45 reviewed cosmetic warnings
comprise 42 library/legend differences, two existing ESP32 edge/legend warnings
and one back-artwork/mask overlap clipped in the export. All 22 layout checks,
16 fabrication checks, six routing checks, eight display checks, 14 USB
topology checks and 13 Gerber/drill/stencil checks pass. The 13 regression
tests, 261 preflight SPICE cases, 57 USB SPICE cases and 12 native NFC
fixtures also pass within their documented scopes. The two USB layout
advisories above remain unmet. The [validation record](usb-backfeed-validation.json)
binds reports to the saved design. Validation exports are not a new manufacturing
release; historical manufacturing archives remain unchanged.

## Current PCB detail

These drawings show the **revised design**, not the fabricated Rev-A board.

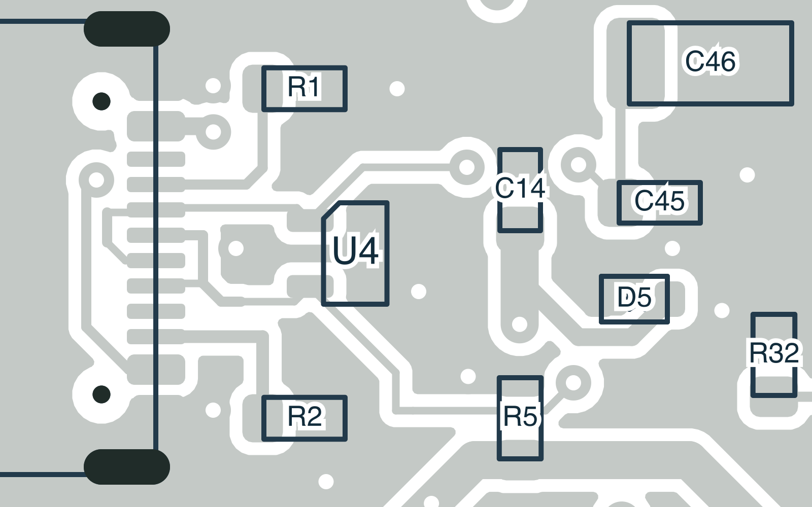
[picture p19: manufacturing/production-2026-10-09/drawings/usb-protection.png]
USB-C, new U4 and separate D5 protection


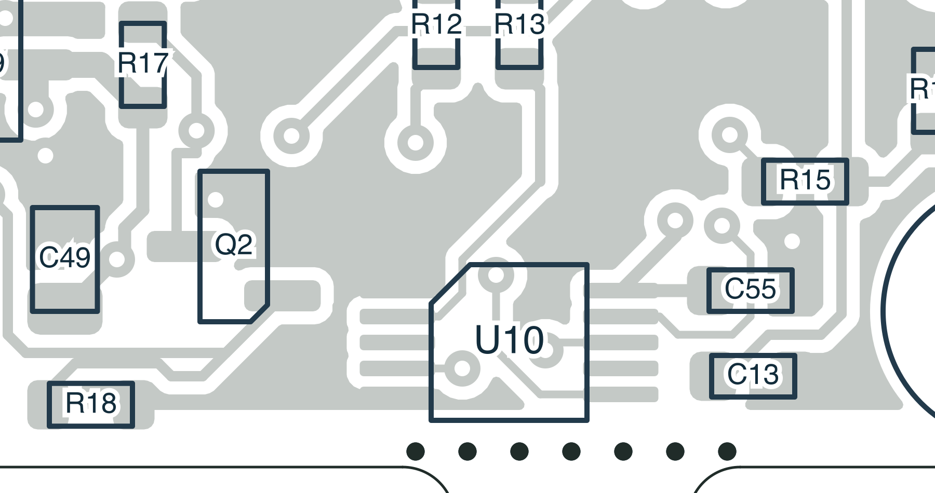
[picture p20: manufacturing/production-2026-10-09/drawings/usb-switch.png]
U10 switch, series resistors and C55 decoupling


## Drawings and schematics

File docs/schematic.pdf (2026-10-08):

1 | 2 | 3 | 4 | 5 | 6 | 7 | 8

AB

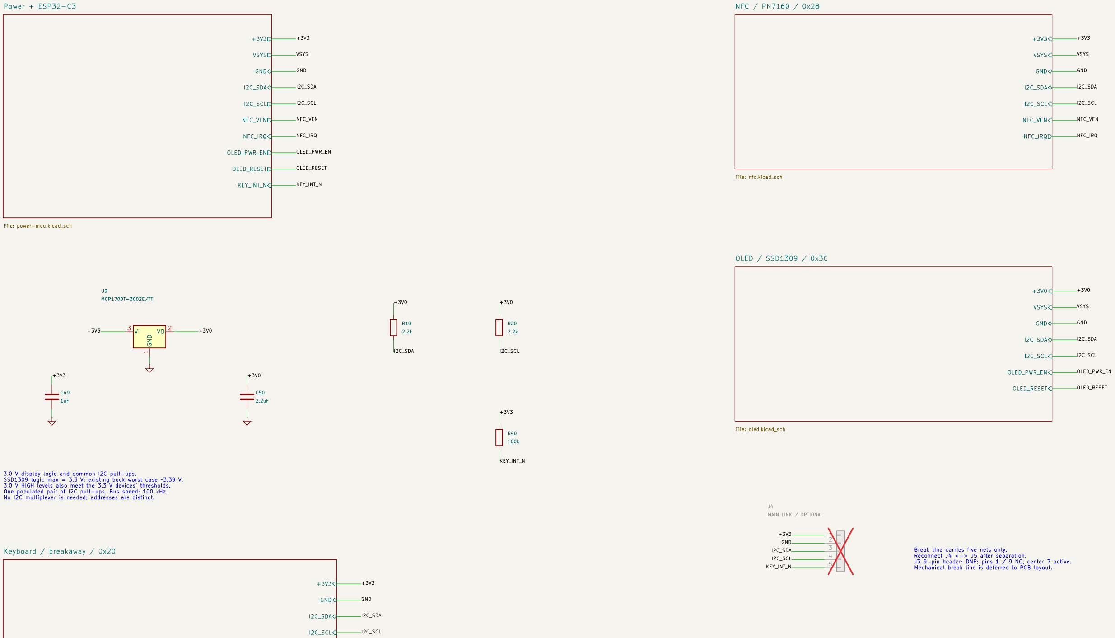
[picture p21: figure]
VSYS GND; I2C_SDA; I2C_SCL OLED_PWR_EN; OLED_RESET OLED / SSD1309 / 0x3C; File: oled.kicad_sch; I2C_SCL NFC_VEN; NFC_IRQ; OLED_PWR_EN; OLED_RESET KEY_INT_N Power + ESP32-C3; File: power-mcu.kicad_sch; +3V3 GND; NFC_IRQ NFC / PN7160 / 0x28; File: nfc.kicad_sch R20; 2.2k GND; U9MCP1700T-3002E/TT; J4MAIN LINK / OPTIONAL R40; GND; KEY_INT_N; OLED_RESET NFC_VEN; KEY_INT_N +3V0; I2C_SCL; VSYS +3V0 +3V3; I2C_SDA +3V3; I2C_SDA GND; I2C_SCL +3V0; NFC_VEN; VSYS; GND +3V3; I2C_SCL +3V3; OLED_RESET
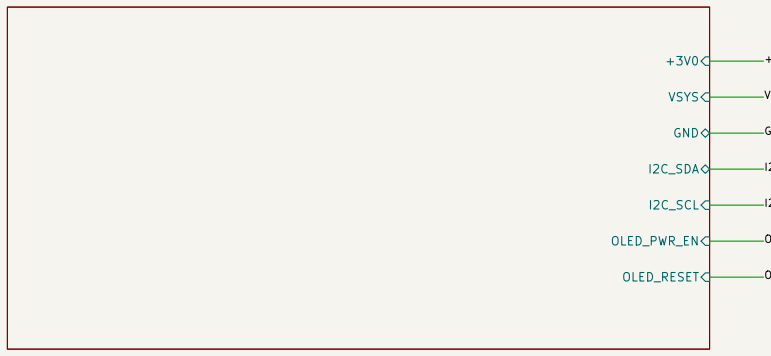
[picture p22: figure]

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
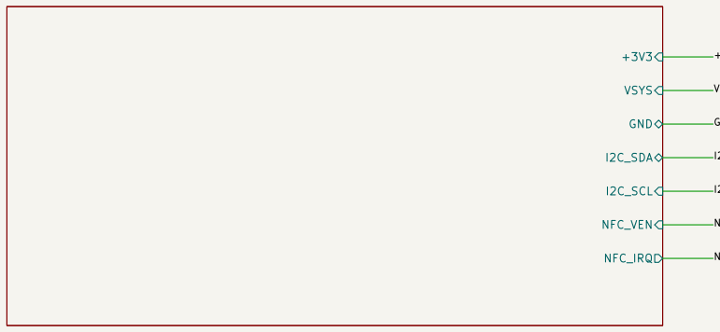
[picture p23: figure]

Size: A3 | Rev: B-draft | F Date: 2026-09-20
KiCad E.D.A. 10.0.6 | Id: 1/5

# Title: Nucula v2 - system interconnect

## File: nucula-v2.kicad_sch

## Sheet: /

## I2C_SCL KEY_INT_N Keyboard / breakaway / 0x20

File: keyboard.kicad_sch

KEY_INT_N

3.0 V display logic and common I2C pull-ups. SSD1309 logic max = 3.3 V; existing buck worst case ~3.39 V. 3.0 V HIGH levels also meet the 3.3 V devices' thresholds. One populated pair of I2C pull-ups. Bus speed: 100 kHz. No I2C multiplexer is needed; addresses are distinct. NFC / OLED power comes from VSYS; digital logic from regulated rails. USB prototype: user-confirmed 5 V / >=1.5 A supply; ~1.10 A estimate. Battery performance / low-battery improvements deferred this iteration. OLED: supplied 24-contact CON24 electrical pinout; verify actual flex fit. RF matching and crystal load selected; final tuning needs measurement. | Break line carries five nets only. Reconnect J4 <-> J5 after separation. J3 9-pin header: DNP; pins 1 / 9 NC, center 7 active. Mechanical break line is deferred to PCB layout.

# NUCULA v2 / system interconnect

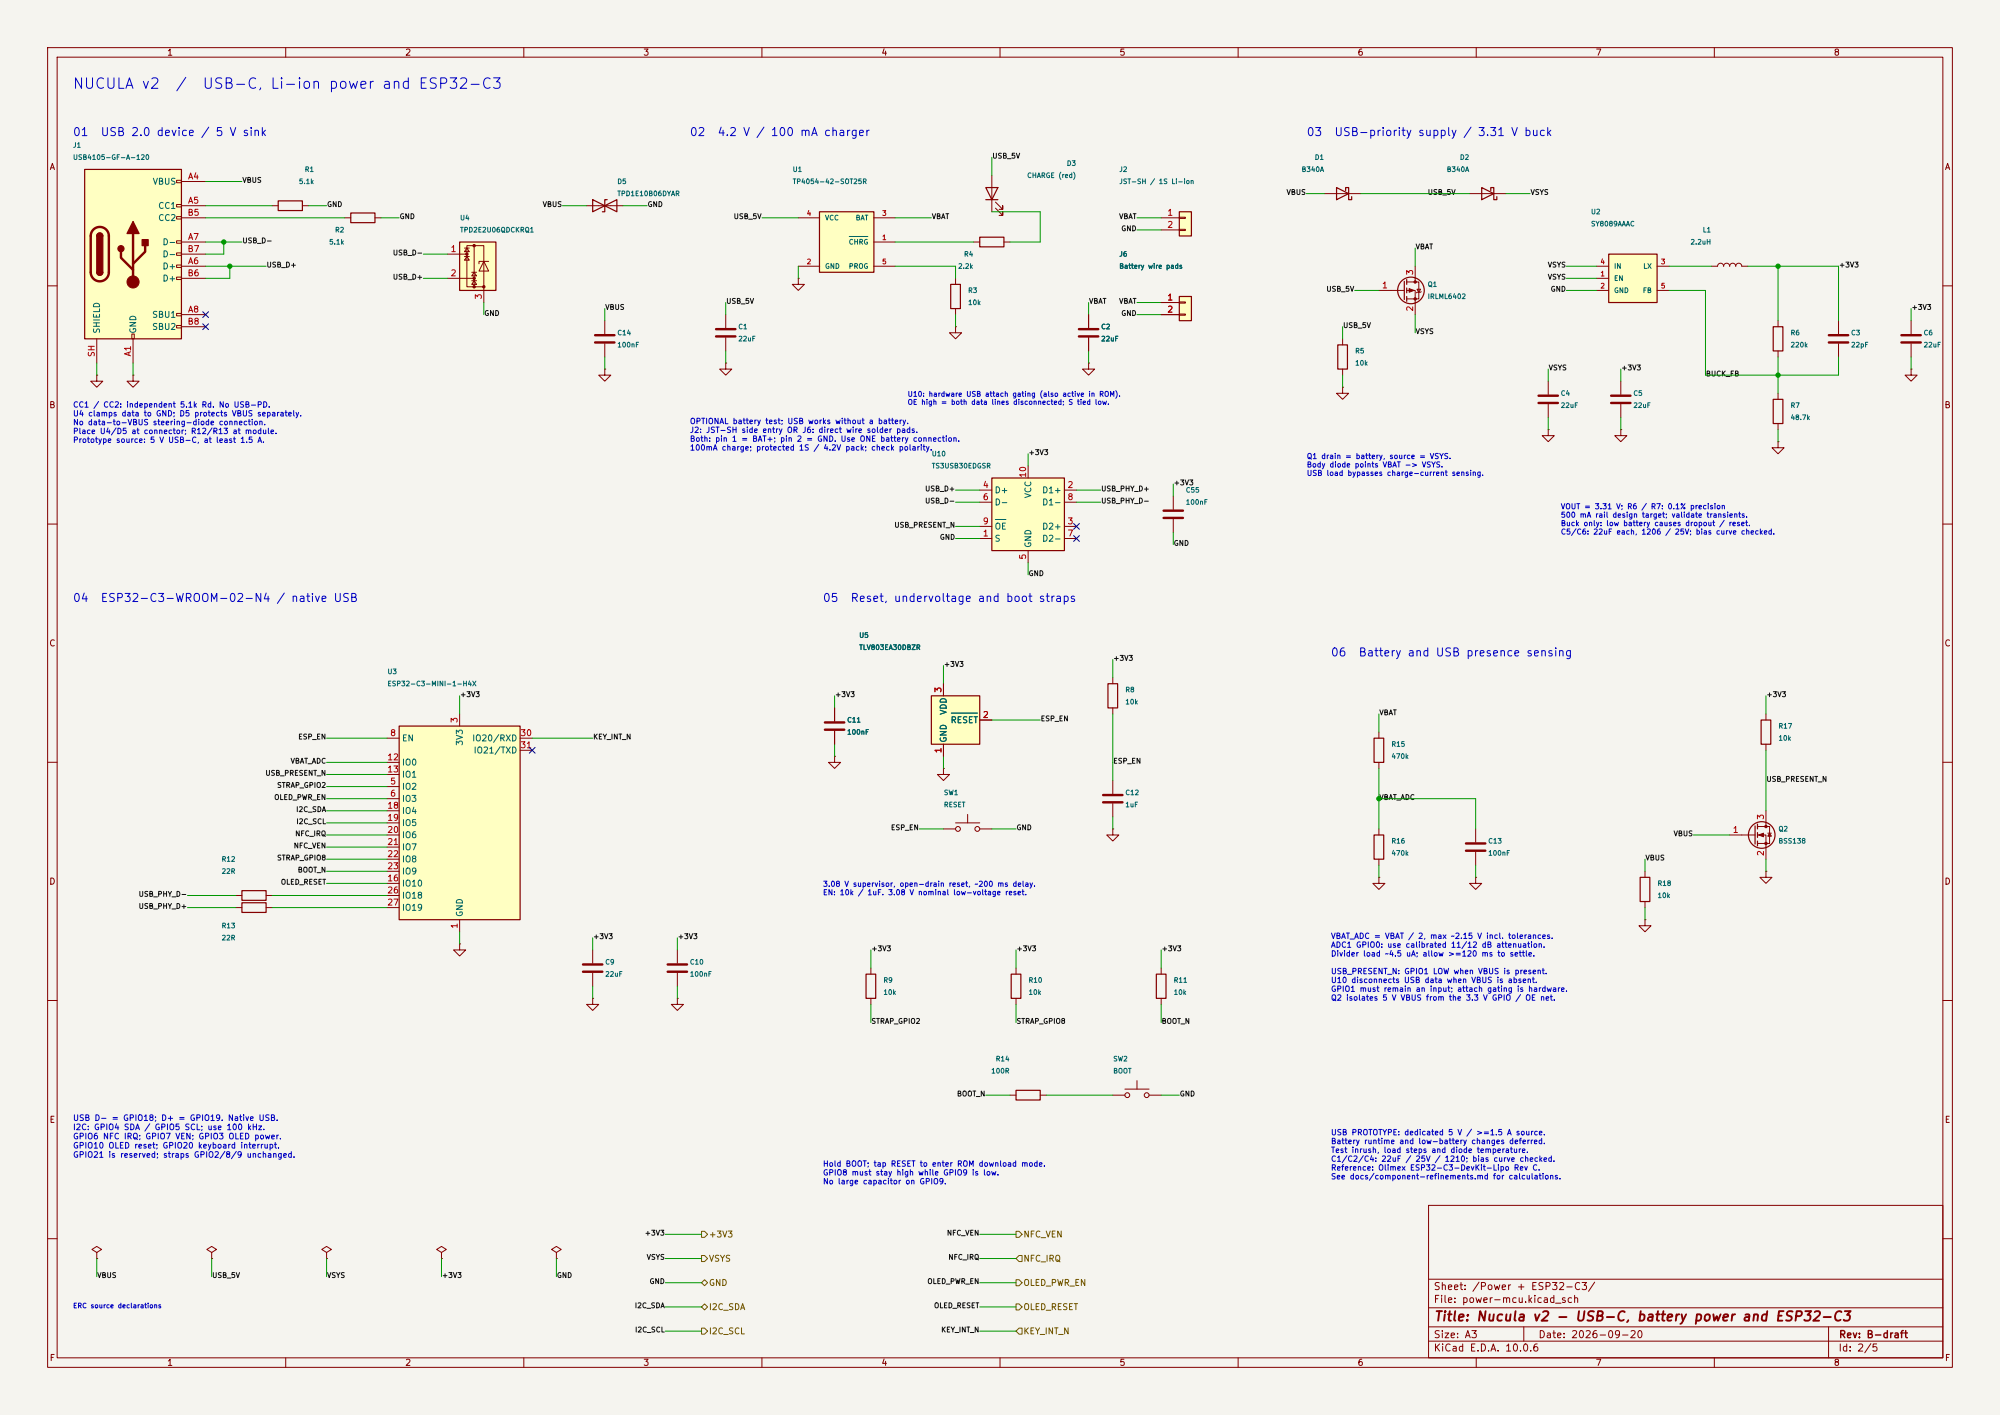
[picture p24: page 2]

NUCULA v2 / USB-C, Li-ion power and ESP32-C3

U10: hardware USB attach gating (also active in ROM). OE high = both data lines disconnected; S tied low. 3.08 V supervisor, open-drain reset, ~200 ms delay. EN: 10k / 1uF. 3.08 V nominal low-voltage reset. USB D- = GPIO18; D+ = GPIO19. Native USB.

OPTIONAL battery test; USB works without a battery. J2: JST-SH side entry OR J6: direct wire solder pads. Both: pin 1 = BAT+; pin 2 = GND. Use ONE battery connection. 100mA charge; protected 1S / 4.2V pack; check polarity.

Q1 drain = battery, source = VSYS. Body diode points VBAT -> VSYS. USB load bypasses charge-current sensing.

VOUT = 3.31 V; R6 / R7: 0.1% precision 500 mA rail design target; validate transients. Buck only: low battery causes dropout / reset. C5/C6: 22uF each, 1206 / 25V; bias curve checked. 04 ESP32-C3-WROOM-02-N4 / native USB

06 Battery and USB presence sensing

VBAT_ADC = VBAT / 2, max ~2.15 V incl. tolerances. ADC1 GPIO0: use calibrated 11/12 dB attenuation. Divider load ~4.5 uA; allow >=120 ms to settle. USB_PRESENT_N: GPIO1 LOW when VBUS is present. U10 disconnects USB data when VBUS is absent. GPIO1 must remain an input; attach gating is hardware. Q2 isolates 5 V VBUS from the 3.3 V GPIO / OE net. USB PROTOTYPE: dedicated 5 V / >=1.5 A source. Battery runtime and low-battery changes deferred. Test inrush, load steps and diode temperature.

I2C: GPIO4 SDA / GPIO5 SCL; use 100 kHz. GPIO6 NFC IRQ; GPIO7 VEN; GPIO3 OLED power. GPIO10 OLED reset; GPIO20 keyboard interrupt. GPIO21 is reserved; straps GPIO2/8/9 unchanged.

Hold BOOT; tap RESET to enter ROM download mode. GPIO8 must stay high while GPIO9 is low. No large capacitor on GPIO9. ERC source declarations

C1/C2/C4: 22uF / 25V / 1210; bias curve checked. Reference: Olimex ESP32-C3-DevKit-Lipo Rev C. See docs/component-refinements.md for calculations.

Sheet: /Power + ESP32-C3/
File: power-mcu.kicad_sch
Title: Nucula v2 - USB-C, battery power and ESP32-C3

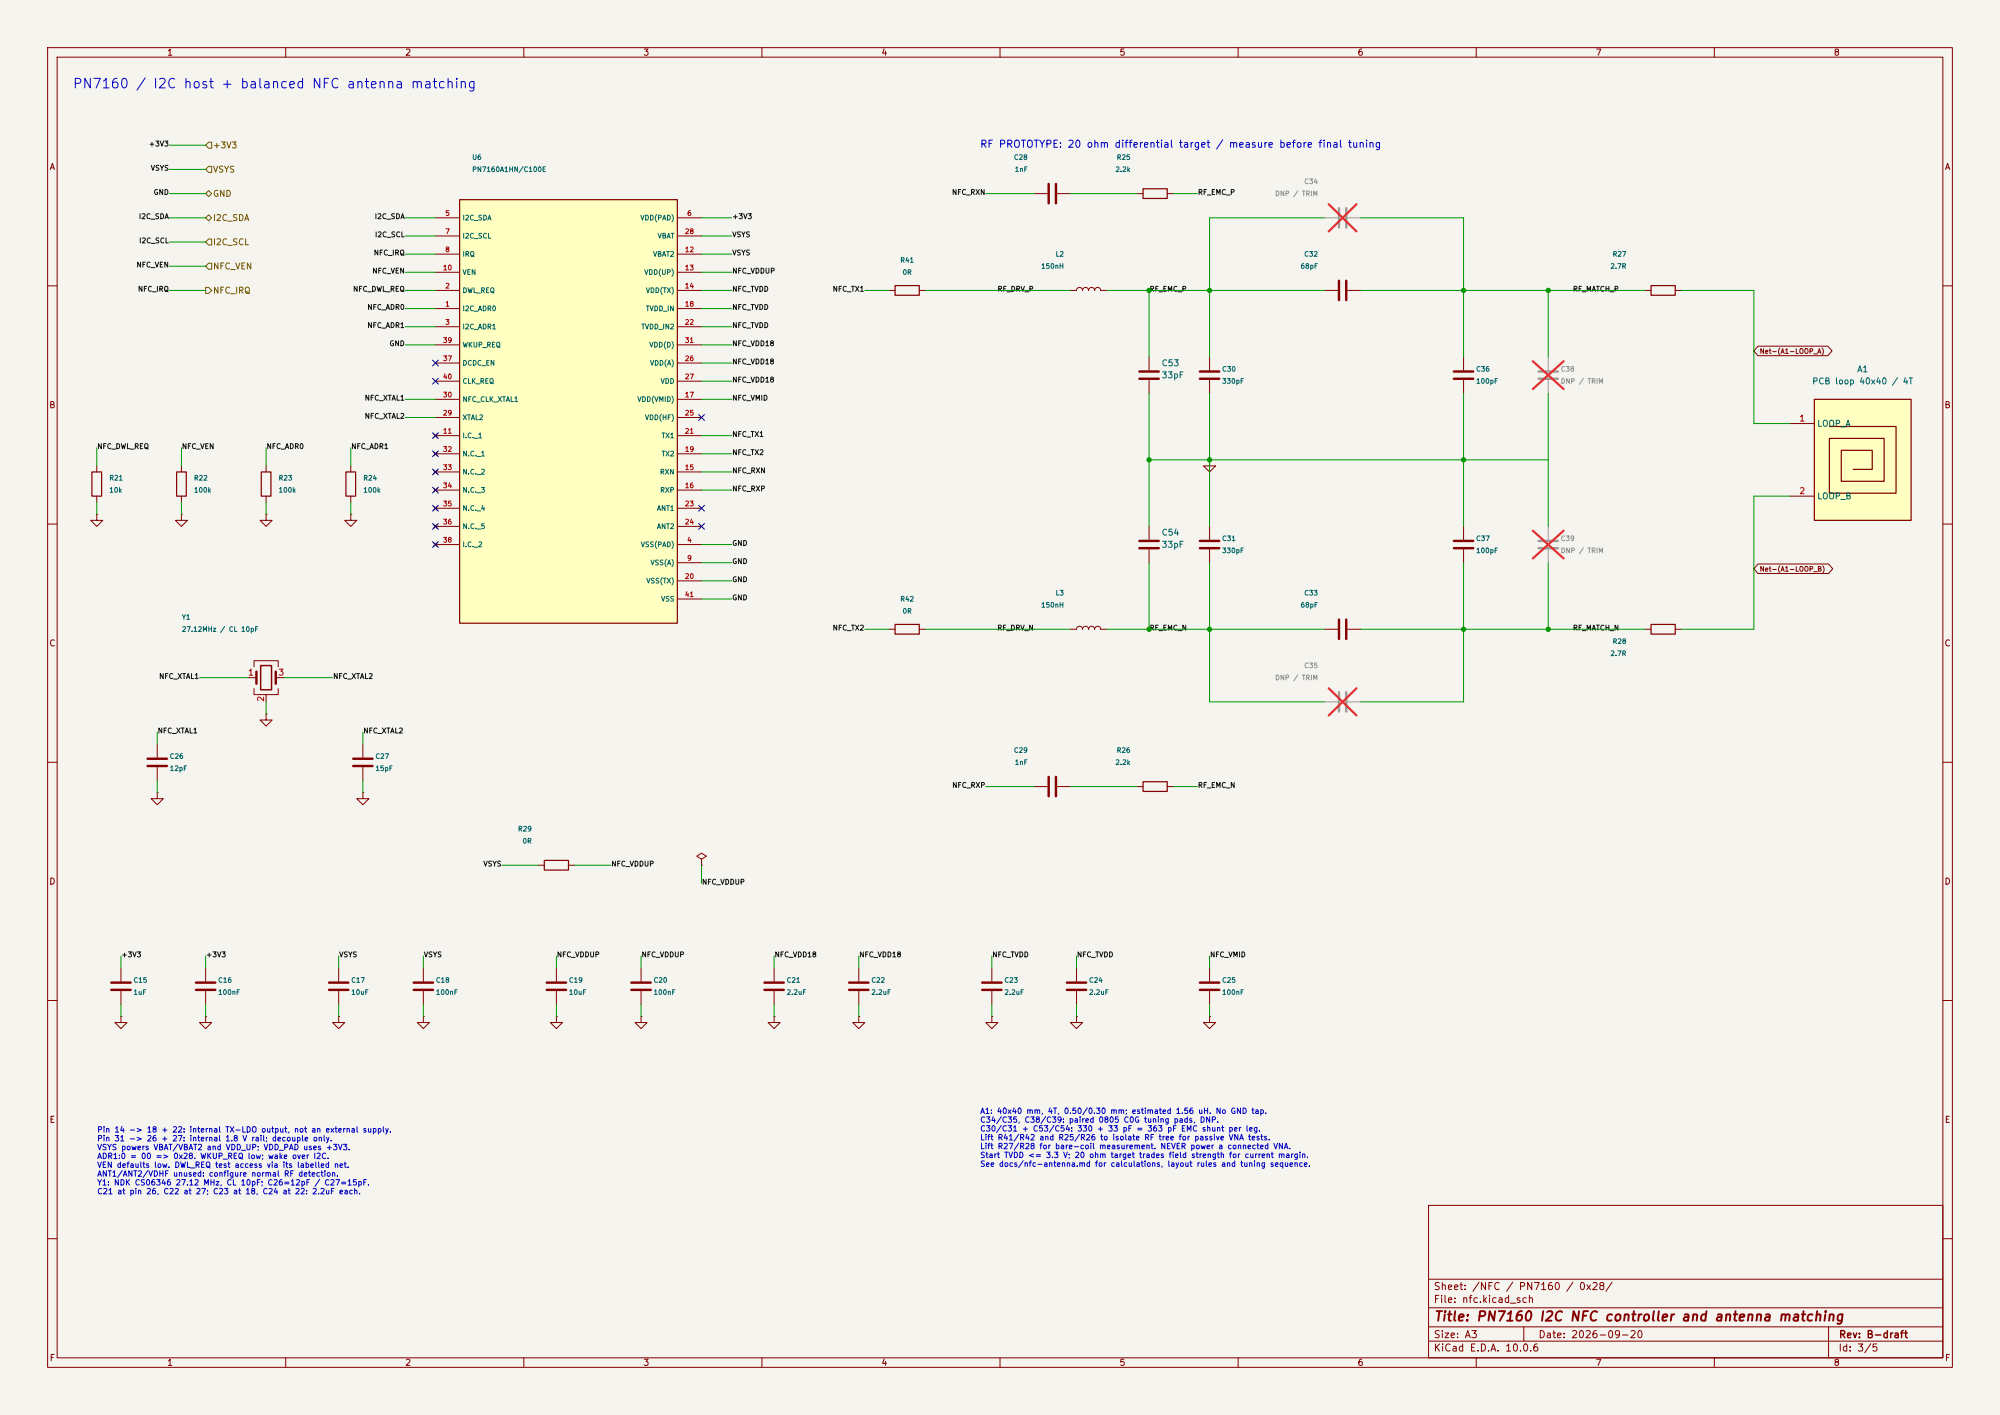
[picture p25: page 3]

PN7160 / I2C host + balanced NFC antenna matching

RF PROTOTYPE: 20 ohm differential target / measure before final tuning

C34/C35, C38/C39: paired 0805 C0G tuning pads, DNP. C30/C31 + C53/C54: 330 + 33 pF = 363 pF EMC shunt per leg. Lift R41/R42 and R25/R26 to isolate RF tree for passive VNA tests. Lift R27/R28 for bare-coil measurement. NEVER power a connected VNA. Start TVDD <= 3.3 V; 20 ohm target trades field strength for current margin. See docs/nfc-antenna.md for calculations, layout rules and tuning sequence.

Sheet: /NFC / PN7160 / 0x28/
File: nfc.kicad_sch
Title: PN7160 I2C NFC controller and antenna matching

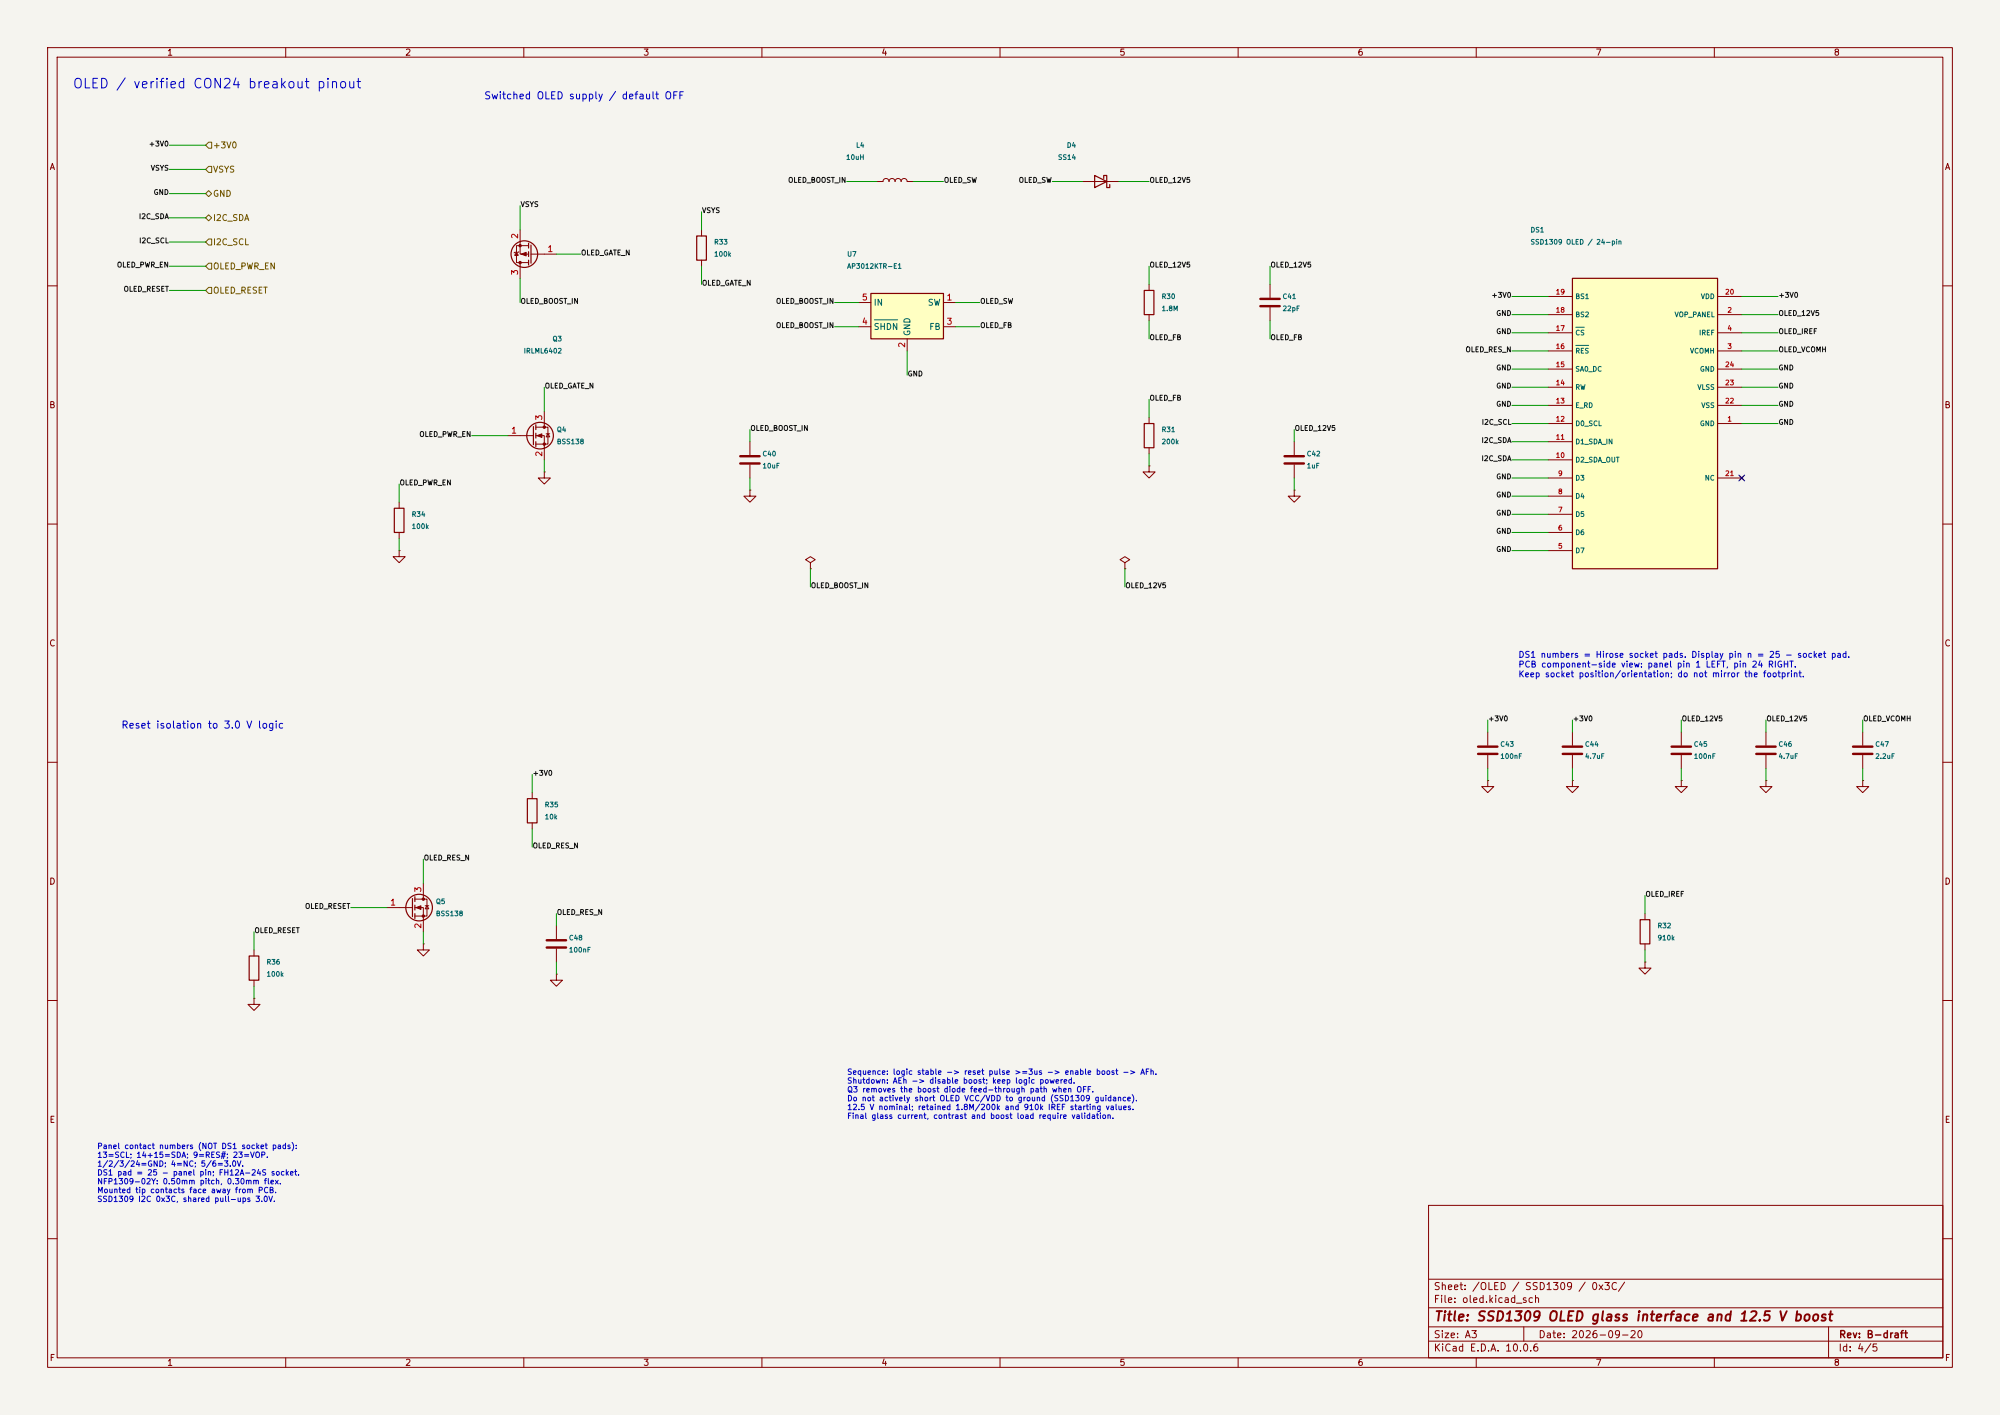
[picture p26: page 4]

OLED / verified CON24 breakout pinout

Switched OLED supply / default OFF
VSYS OLED_GATE_N
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

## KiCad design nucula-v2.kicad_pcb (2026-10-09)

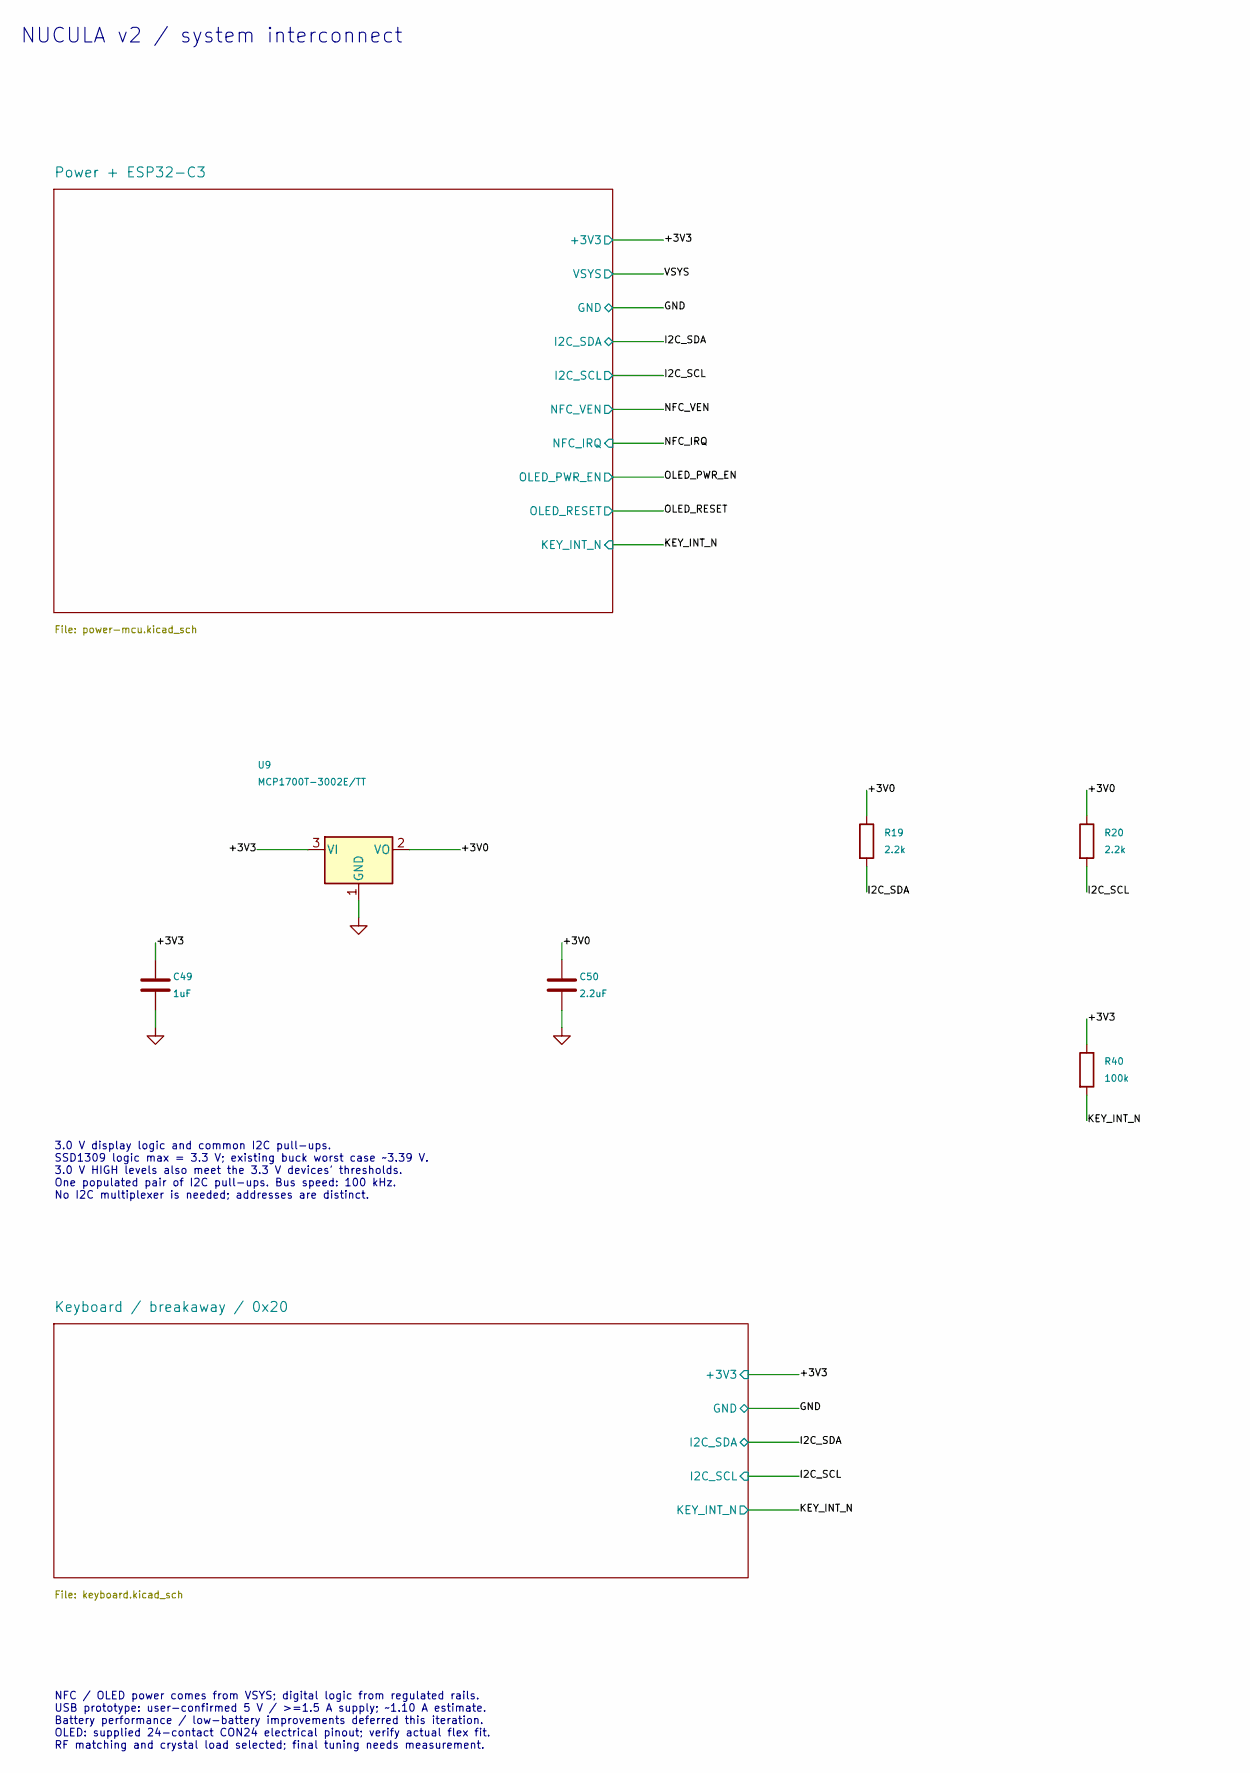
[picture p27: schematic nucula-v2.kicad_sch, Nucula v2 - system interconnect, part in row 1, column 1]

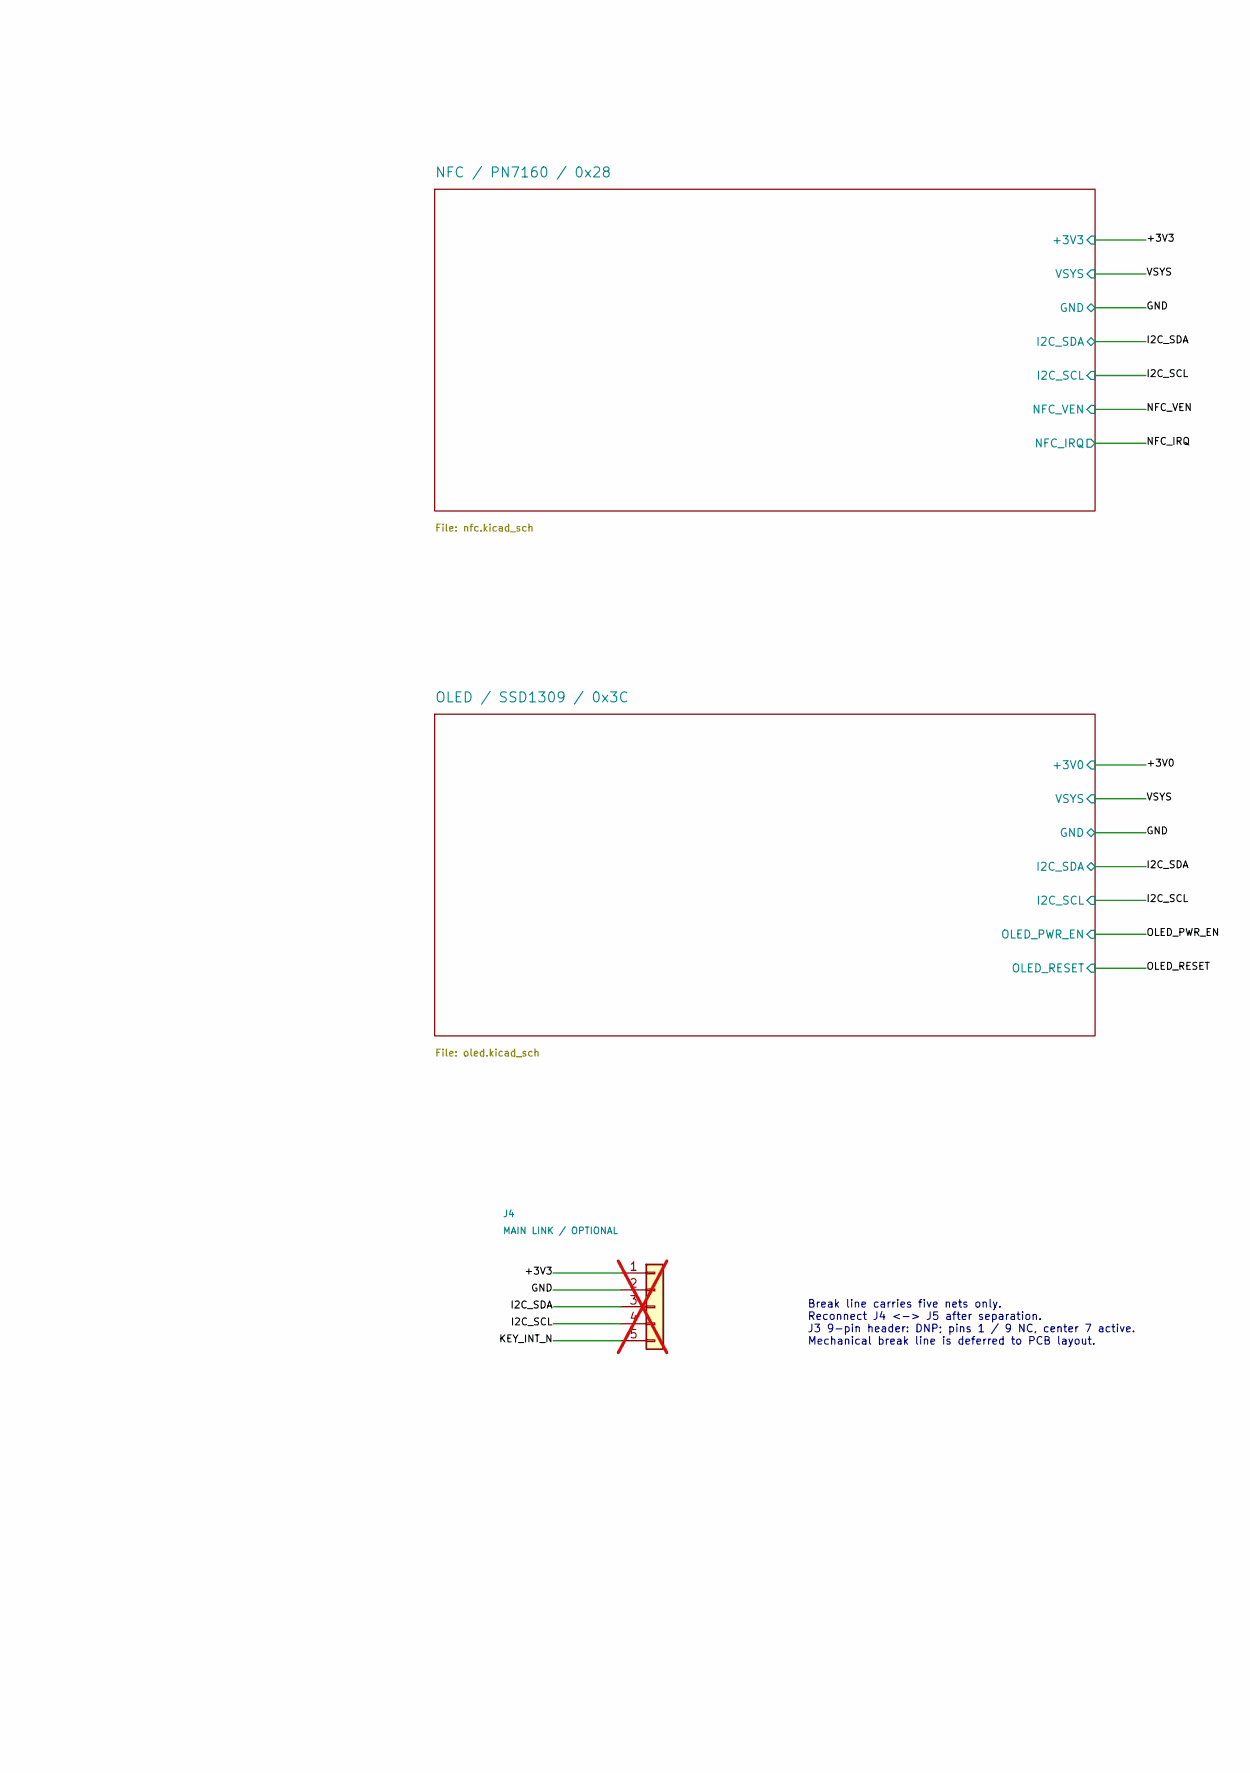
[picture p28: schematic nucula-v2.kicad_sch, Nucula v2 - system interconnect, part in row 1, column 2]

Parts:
C49: 1uF; C_0805_2012Metric; Voltage 50 V; Tolerance 10%; MPN CL21B105KBFNNNE; LCSC C28323
C50: 2.2uF; C_0805_2012Metric; Voltage 25 V; Tolerance 10%; MPN CL21B225KAFNNNE; LCSC C19110
J4: MAIN LINK / OPTIONAL; PinHeader_1x05_P2.54mm_Vertical; not fitted
R19, R20: 2.2k; R_0603_1608Metric; Tolerance 1%; Rating 0.1 W; MPN 0603WAF2201T5E; LCSC C4190
R40: 100k; R_0603_1608Metric; Tolerance 1%; Rating 0.1 W; MPN 0603WAF1003T5E; LCSC C25803
U9: MCP1700T-3002E/TT; SOT-23; MPN MCP1700T-3002E/TT; LCSC C62244

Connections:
/+3V0: C50.1, R19.1, R20.1, U9.2 (VO); also elsewhere on the board
/+3V3: C49.1, J4.1, R40.1, U9.3 (VI); also elsewhere on the board
/I2C_SCL: J4.4, R20.2; also elsewhere on the board
/I2C_SDA: J4.3, R19.2; also elsewhere on the board
/KEY_INT_N: J4.5, R40.2; also elsewhere on the board
GND: C49.2, C50.2, J4.2, U9.1 (GND); also elsewhere on the board

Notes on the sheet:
NUCULA v2 / system interconnect
3.0 V display logic and common I2C pull-ups. SSD1309 logic max = 3.3 V; existing buck worst case ~3.39 V. 3.0 V HIGH levels also meet the 3.3 V devices' thresholds. One populated pair of I2C pull-ups. Bus speed: 100 kHz. No I2C multiplexer is needed; addresses are distinct.
Break line carries five nets only. Reconnect J4 <-> J5 after separation. J3 9-pin header: DNP; pins 1 / 9 NC, center 7 active. Mechanical break line is deferred to PCB layout.
NFC / OLED power comes from VSYS; digital logic from regulated rails. USB prototype: user-confirmed 5 V / >=1.5 A supply; ~1.10 A estimate. Battery performance / low-battery improvements deferred this iteration. OLED: supplied 24-contact CON24 electrical pinout; verify actual flex fit. RF matching 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

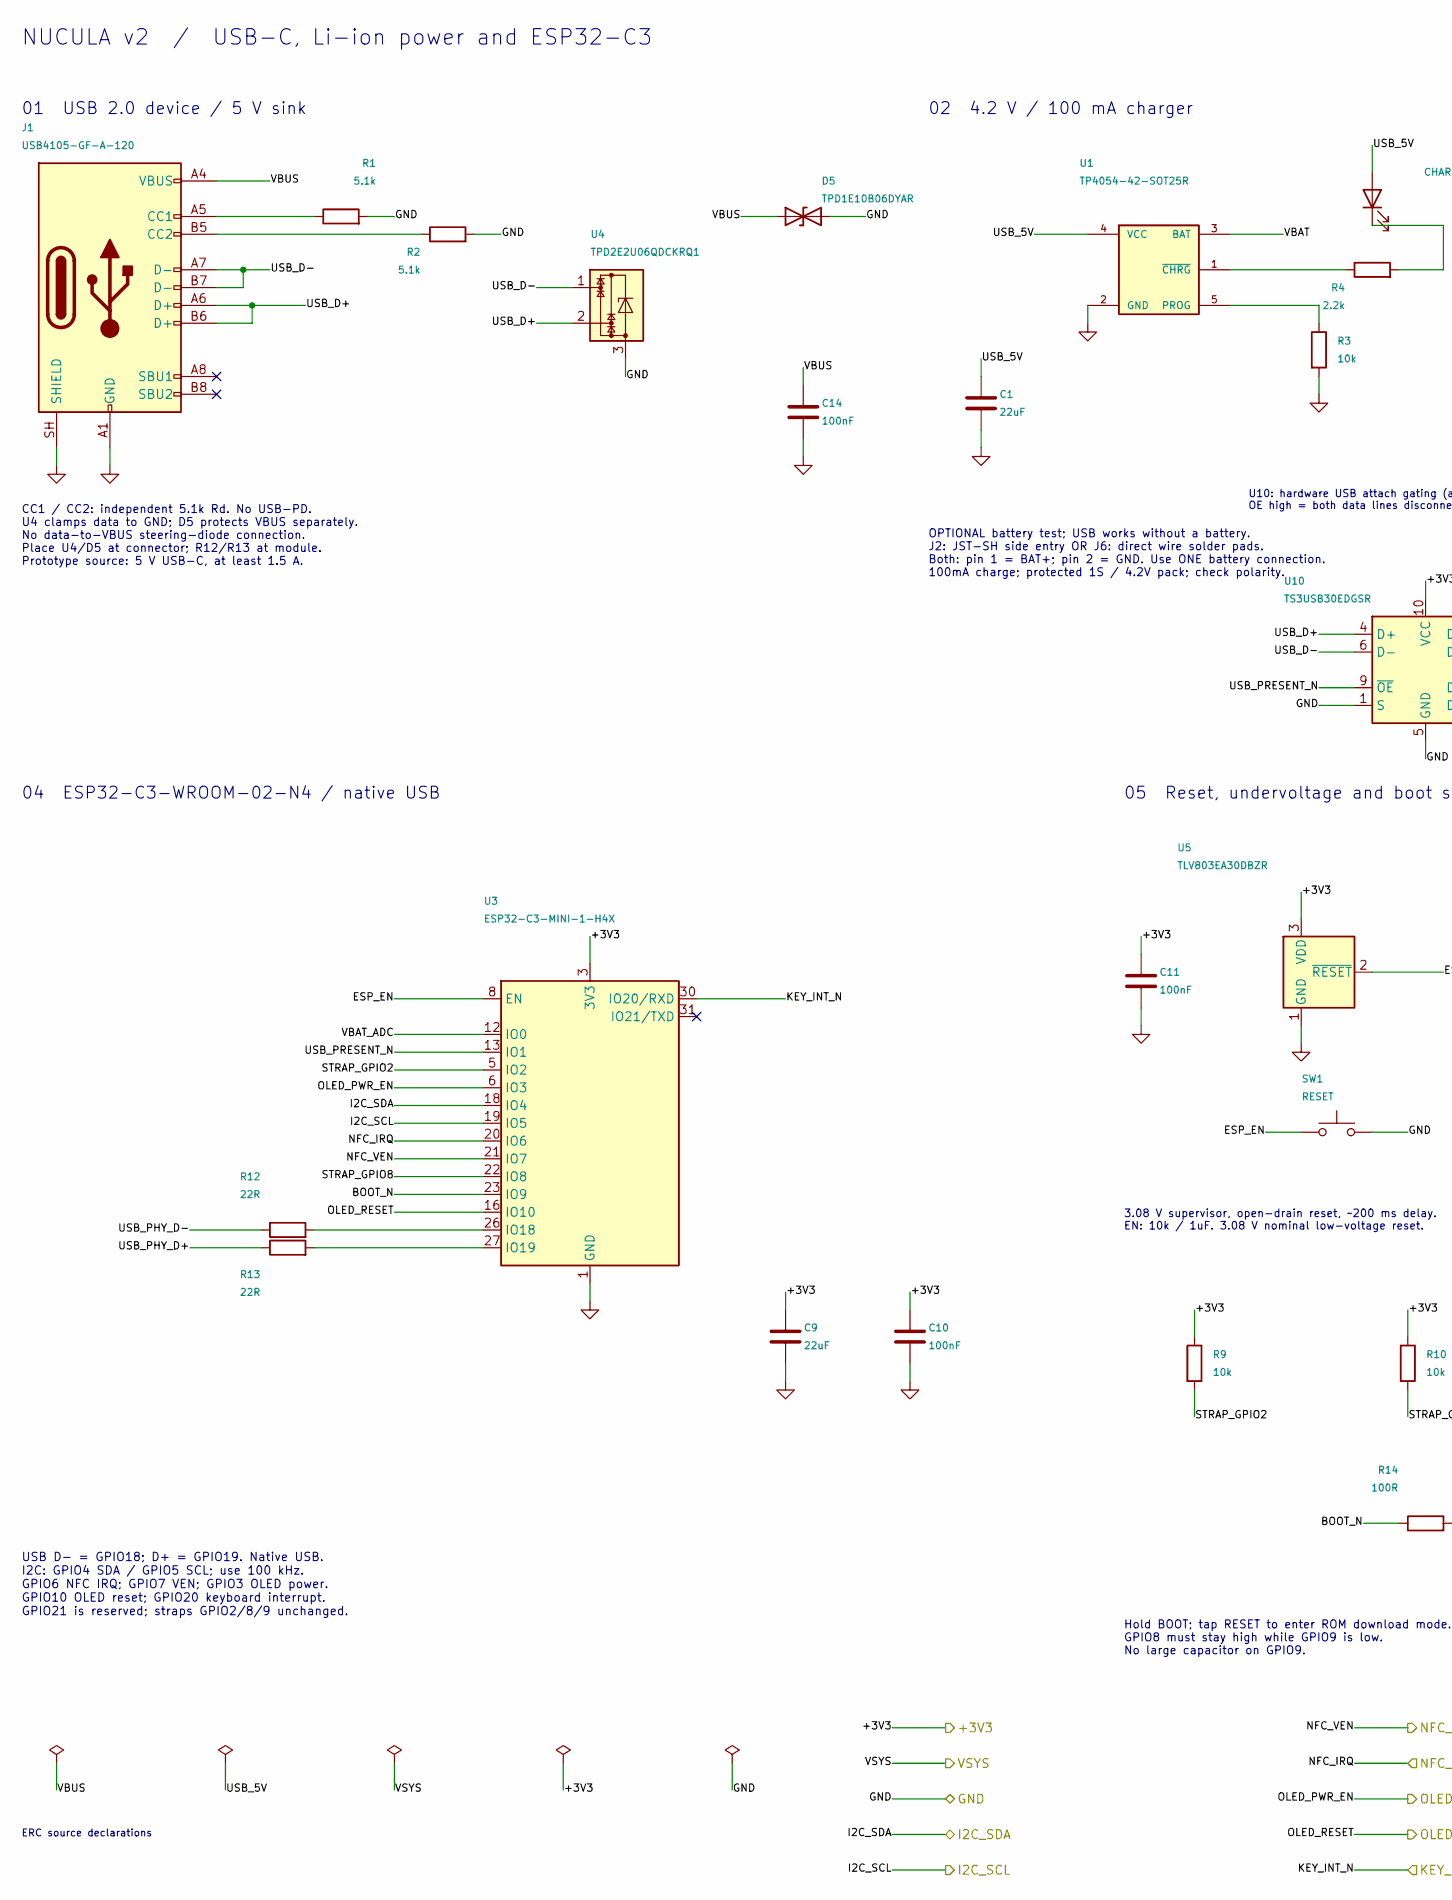
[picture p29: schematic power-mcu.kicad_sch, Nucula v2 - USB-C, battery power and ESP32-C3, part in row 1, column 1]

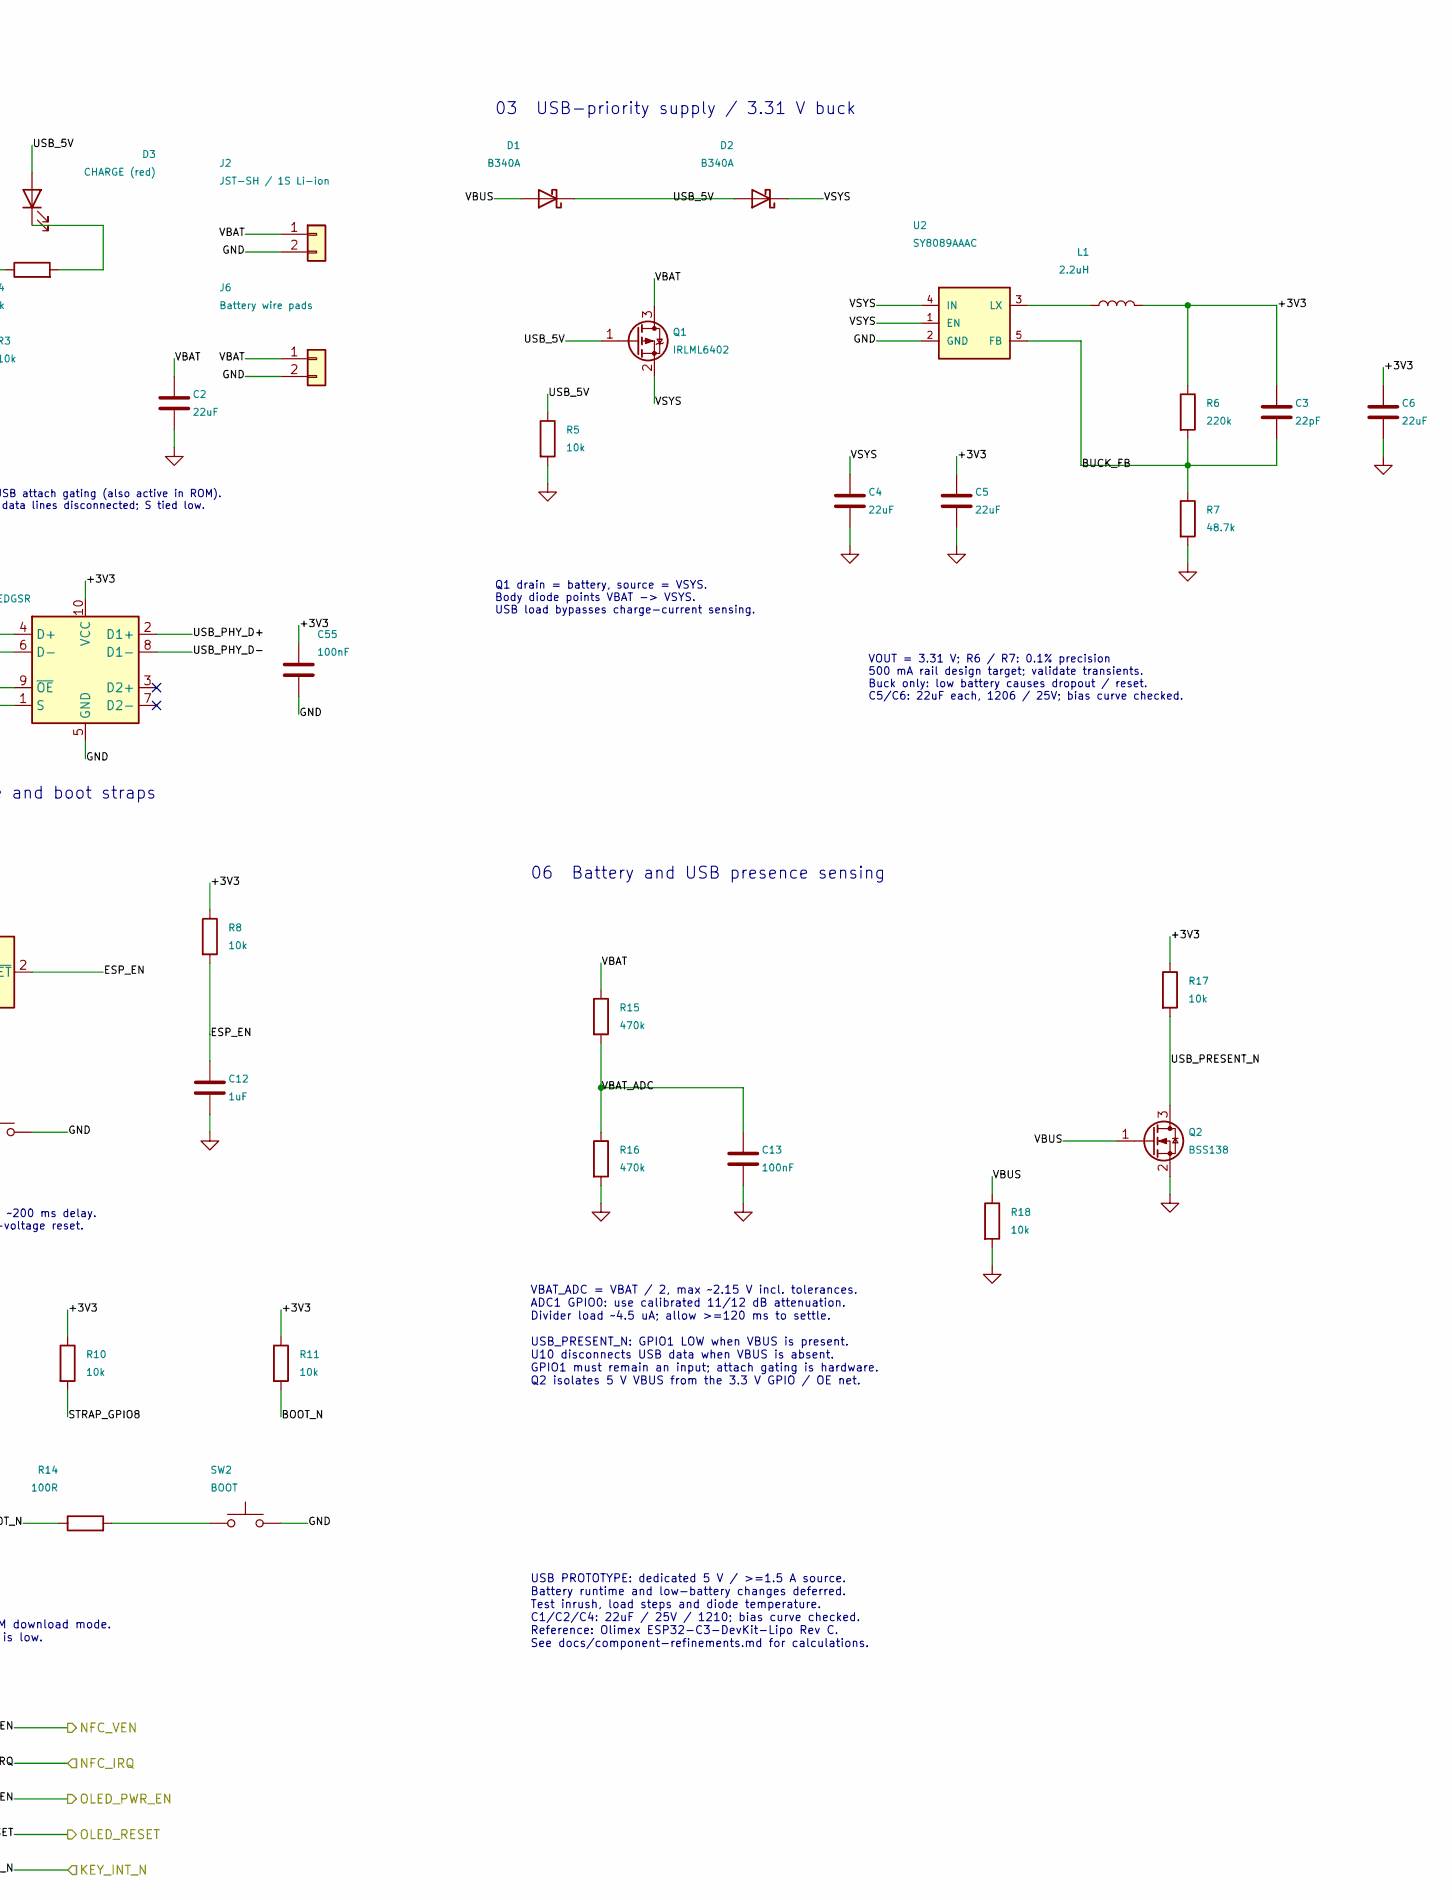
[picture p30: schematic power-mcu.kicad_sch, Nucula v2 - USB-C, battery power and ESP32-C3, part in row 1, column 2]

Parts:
C1, C2, C4: 22uF; C_1210_3225Metric; Voltage 25 V; Tolerance 10%; MPN CL32B226KAJNNNE; LCSC C309062
C3: 22pF; C_0603_1608Metric; Voltage 50 V; Tolerance 5%; MPN CL10C220JB8NNNC; LCSC C1653
C5, C6, C9: 22uF; C_1206_3216Metric; Voltage 25 V; Tolerance 10%; MPN CL31A226KAHNNNE; LCSC C12891
C10, C11, C13, C14, C55: 100nF; C_0603_1608Metric; Voltage 50 V; Tolerance 10%; MPN CL10B104KB8NNNL; LCSC C913912
C12: 1uF; C_0603_1608Metric; Voltage 25 V; Tolerance 10%; MPN CL10B105KA8NNNC; LCSC C29936
D1, D2: B340A; D_SMA; Rating 3 A / 40 V; SMA; layout thermal deratin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; MPN B340A-13-F; LCSC C85098
D3: CHARGE (red); LED_0603_1608Metric; MPN KT-0603R; LCSC C2286
D5: TPD1E10B06DYAR; D_SOD-523; MPN TPD1E10B06DYAR; LCSC C3712135
J1: USB4105-GF-A-120; USB_C_GCT_USB4105_16P_Standard; MPN USB4105-GF-A-120; LCSC C5184243
J2: JST-SH / 1S Li-ion; JST_SH_SM02B-SRSS-TB_1x02-1MP_P1.00mm_Horizontal; MPN SM02B-SRSS-TB(LF)(SN); LCSC C160402
J6: Battery wire pads; Battery_Lead_SolderPads_2x2.2x2.5mm_P3.4mm
L1: 2.2uH; L_Taiyo-Yuden_NR-30xx; Rating Isat >=1.48 A, Irms >=1.5 A; 2.2uH +/-2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; MPN LSXND3030QKT2R2MNG; LCSC C6980123
Q1: IRLML6402; SOT-23; MPN IRLML6402TRPBF; LCSC C2593
Q2: BSS138; SOT-23; MPN BSS138; LCSC C52895
R1, R2: 5.1k; R_0603_1608Metric; Tolerance 1%; Rating 0.1 W; MPN 0603WAF5101T5E; LCSC C23186
R3, R5, R8, R9, R10, R11, R17, R18: 10k; R_0603_1608Metric; Tolerance 1%; Rating 0.1 W; MPN 0603WAF1002T5E; LCSC C25804
R4: 2.2k; R_0603_1608Metric; Tolerance 1%; Rating 0.1 W; MPN 0603WAF2201T5E; LCSC C4190
R6: 220k; R_0603_1608Metric; Tolerance 0.1%; Rating 0.1 W; MPN RT0603BRD07220KL; LCSC C861231
R7: 48.7k; R_0603_1608Metric; Tolerance 0.1%; Rating 0.1 W; MPN RT0603BRD0748K7L; LCSC C861429
R12, R13: 22R; R_0603_1608Metric; Tolerance 1%; Rating 0.1 W; MPN 0603WAF220JT5E; LCSC C23345
R14: 100R; R_0603_1608Metric; Tolerance 1%; Rating 0.1 W; MPN 0603WAF1000T5E; LCSC C22775
R15, R16: 470k; R_0603_1608Metric; Tolerance 1%; Rating 0.1 W; MPN 0603WAF4703T5E; LCSC C23178
SW1: RESET; SW_SPST_B3U-1000P; MPN B3U-1000P; LCSC C231329
SW2: BOOT; SW_SPST_B3U-1000P; MPN B3U-1000P; LCSC C231329
U1: TP4054-42-SOT25R; SOT-23-5; MPN TP4054-42-SOT25R; LCSC C32574
U2: SY8089AAAC; SOT-23-5; MPN SY8089AAAC; LCSC C78988
U3: ESP32-C3-MINI-1-H4X; ESP32-C3-MINI-1-H4X_NoEPADSolder; MPN ESP32-C3-MINI-1-H4X; LCSC C41349510
U4: TPD2E2U06QDCKRQ1; SOT-323_SC-70; MPN TPD2E2U06QDCKRQ1; LCSC C915089
U5: TLV803EA30DBZR; SOT-23; MPN TLV803EA30DBZR; LCSC C5218924
U10: TS3USB30EDGSR; TSSOP-10_3x3mm_P0.5mm; MPN TS3USB30EDGSR; LCSC C131998

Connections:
/+3V3: C3.1, C5.1, C6.1, C9.1, C10.1, C11.1, C55.1, L1.2, R6.1, R8.1, R9.1, R10.1, R11.1, R17.1, U3.3 (3V3), U5.3 (VDD), U10.10 (VCC); also elsewhere on the board
/I2C_SCL: U3.19 (IO5); also elsewhere on the board
/I2C_SDA: U3.18 (IO4); also elsewhere on the board
/KEY_INT_N: U3.30 (IO20/RXD); also elsewhere on the board
/NFC_IRQ: U3.20 (IO6); also elsewhere on the board
/NFC_VEN: U3.21 (IO7); also elsewhere on the board
/OLED_PWR_EN: U3.6 (IO3); also elsewhere on the board
/OLED_RESET: U3.16 (IO10); also elsewhere on the board
/Power + ESP32-C3/BOOT_N: R11.2, R14.1, U3.23 (IO9)
/Power + ESP32-C3/BUCK_FB: C3.2, R6.2, R7.1, U2.5 (FB)
/Power + ESP32-C3/ESP_EN: C12.1, R8.2, SW1.1, U3.8 (EN), U5.2 (~RESET)
/Power + ESP32-C3/STRAP_GPIO2: R9.2, U3.5 (IO2)
/Power + ESP32-C3/STRAP_GPIO8: R10.2, U3.22 (IO8)
/Power + ESP32-C3/USB_5V: C1.1, D1.1 (K), D2.2 (A), D3.2 (A), Q1.1 (G), R5.1, U1.4 (VCC)
/Power + ESP32-C3/USB_D+: J1.A6 (D+), J1.B6 (D+), U4.2, U10.4 (D+)
/Power + ESP32-C3/USB_D-: J1.A7 (D-), J1.B7 (D-), U4.1, U10.6 (D-)
/Power + ESP32-C3/USB_PHY_D+: R13.1, U10.2 (D1+)
/Power + ESP32-C3/USB_PHY_D-: R12.1, U10.8 (D1-)
/Power + ESP32-C3/USB_PRESENT_N: Q2.3 (D), R17.2, U3.13 (IO1), U10.9 (~OE)
/Power + ESP32-C3/VBAT: C2.1, J2.1, J6.1, Q1.3 (D), R15.1, U1.3 (BAT)
/Power + ESP32-C3/VBAT_ADC: C13.1, R15.2, R16.1, U3.12 (IO0)
/Power + ESP32-C3/VBUS: C14.1, D1.2 (A), D5.1 (A1), J1.A4 (VBUS), J1.A9 (VBUS), J1.B4 (VBUS), J1.B9 (VBUS), Q2.1 (G), R18.1
/VSYS: C4.1, D2.1 (K), Q1.2 (S), U2.1 (EN), U2.4 (IN); also elsewhere on the board
GND: C1.2, C2.2, C4.2, C5.2, C6.2, C9.2, C10.2, C11.2, C12.2, C13.2, C14.2, C55.2, D5.2 (A2), J1.A1 (GND), J1.A12 (GND), J1.B1 (GND), J1.B12 (GND), J1.SH (SHIELD), J2.2, J6.2, Q2.2 (S), R1.2, R2.2, R3.2, R5.2, R7.2, R16.2, R18.2, SW1.2, SW2.2, U1.2 (GND), U2.2 (GND), U3.1 (GND), U3.2 (GND), U3.11 (GND), U3.14 (GND), U3.36 (GND), U3.37 (GND), U3.38 (GND), U3.39 (GND), U3.40 (GND), U3.41 (GND), U3.42 (GND), U3.43 (GND), U3.44 (GND), U3.45 (GND), U3.46 (GND), U3.47 (GND), U3.48 (GND), U3.49 (GND), U3.50 (GND), U3.51 (GND), U3.52 (GND), U3.53 (GND), U4.3, U5.1 (GND), U10.1 (S), U10.5 (GND); also elsewhere on the board
unnamed: D3.1 (K), R4.2
unnamed: J1.A5 (CC1), R1.1
unnamed: J1.B5 (CC2), R2.1
unnamed: R14.2, SW2.1
unnamed: R3.1, U1.5 (PROG)
unnamed: R4.1, U1.1 (~CHRG)
unnamed: L1.1, U2.3 (LX)
unnamed: R12.2, U3.26 (IO18)
unnamed: R13.2, U3.27 (IO19)

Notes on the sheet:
NUCULA v2 / USB-C, Li-ion power and ESP32-C3
01 USB 2.0 device / 5 V sink
CC1 / CC2: independent 5.1k Rd. No USB-PD. U4 clamps data to GND; D5 protects VBUS separately. No data-to-VBUS steering-diode connection. Place U4/D5 at connector; R12/R13 at module. Prototype source: 5 V USB-C, at least 1.5 A.
02 4.2 V / 100 mA charger
OPTIONAL battery test; USB works without a battery. J2: JST-SH side entry OR J6: direct wire solder pads. Both: pin 1 = BAT+; pin 2 = GND. Use ONE battery connection. 100mA charge; protected 1S / 4.2V pack; check polarity.
03 USB-priority supply / 3.31 V buck
Q1 drain = battery, source = VSYS. Body diode points VBAT -> VSYS. USB load bypasses charge-current sensing.
VOUT = 3.31 V; R6 / R7: 0.1% precision 500 mA rail design target; validate transients. Buck only: low battery causes dropout / reset. C5/C6: 22uF each, 1206 / 25V; bias curve checked.
04 ESP32-C3-WROOM-02-N4 / native USB
USB D- = GPIO18; D+ = GPIO19. Native USB. I2C: GPIO4 SDA / GPIO5 SCL; use 100 kHz. GPIO6 NFC IRQ; GPIO7 VEN; GPIO3 OLED power. GPIO10 OLED reset; GPIO20 keyboard interrupt. GPIO21 is reserved; straps GPIO2/8/9 unchanged.
05 Reset, undervoltage and boot straps
3.08 V supervisor, open-drain reset, ~200 ms delay. EN: 10k / 1uF. 3.08 V nominal low-voltage reset.
Hold BOOT; tap RESET to enter ROM download mode. GPIO8 must stay high while GPIO9 is low. No large capacitor on GPIO9.
06 Battery and USB presence sensing
VBAT_ADC = VBAT / 2, max ~2.15 V incl. tolerances. ADC1 GPIO0: use calibrated 11/12 dB attenuation. Divider load ~4.5 uA; allow >=120 ms to settle. USB_PRESENT_N: GPIO1 LOW when VBUS is present. U10 disconnects USB data when VBUS is absent. GPIO1 must remain an input; attach gating is hardware. Q2 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
USB PROTOTYPE: dedicated 5 V / >=1.5 A source. Battery runtime and low-battery changes deferred. Test inrush, load steps and diode temperature. C1/C2/C4: 22uF / 25V / 1210; bias curve checked. Reference: Olimex ESP32-C3-DevKit-Lipo Rev C. See docs/component-refinements.md for calculations.
ERC source declarations
U10: hardware USB attach gating (also active in ROM). OE high = both data lines disconnected; S tied low.

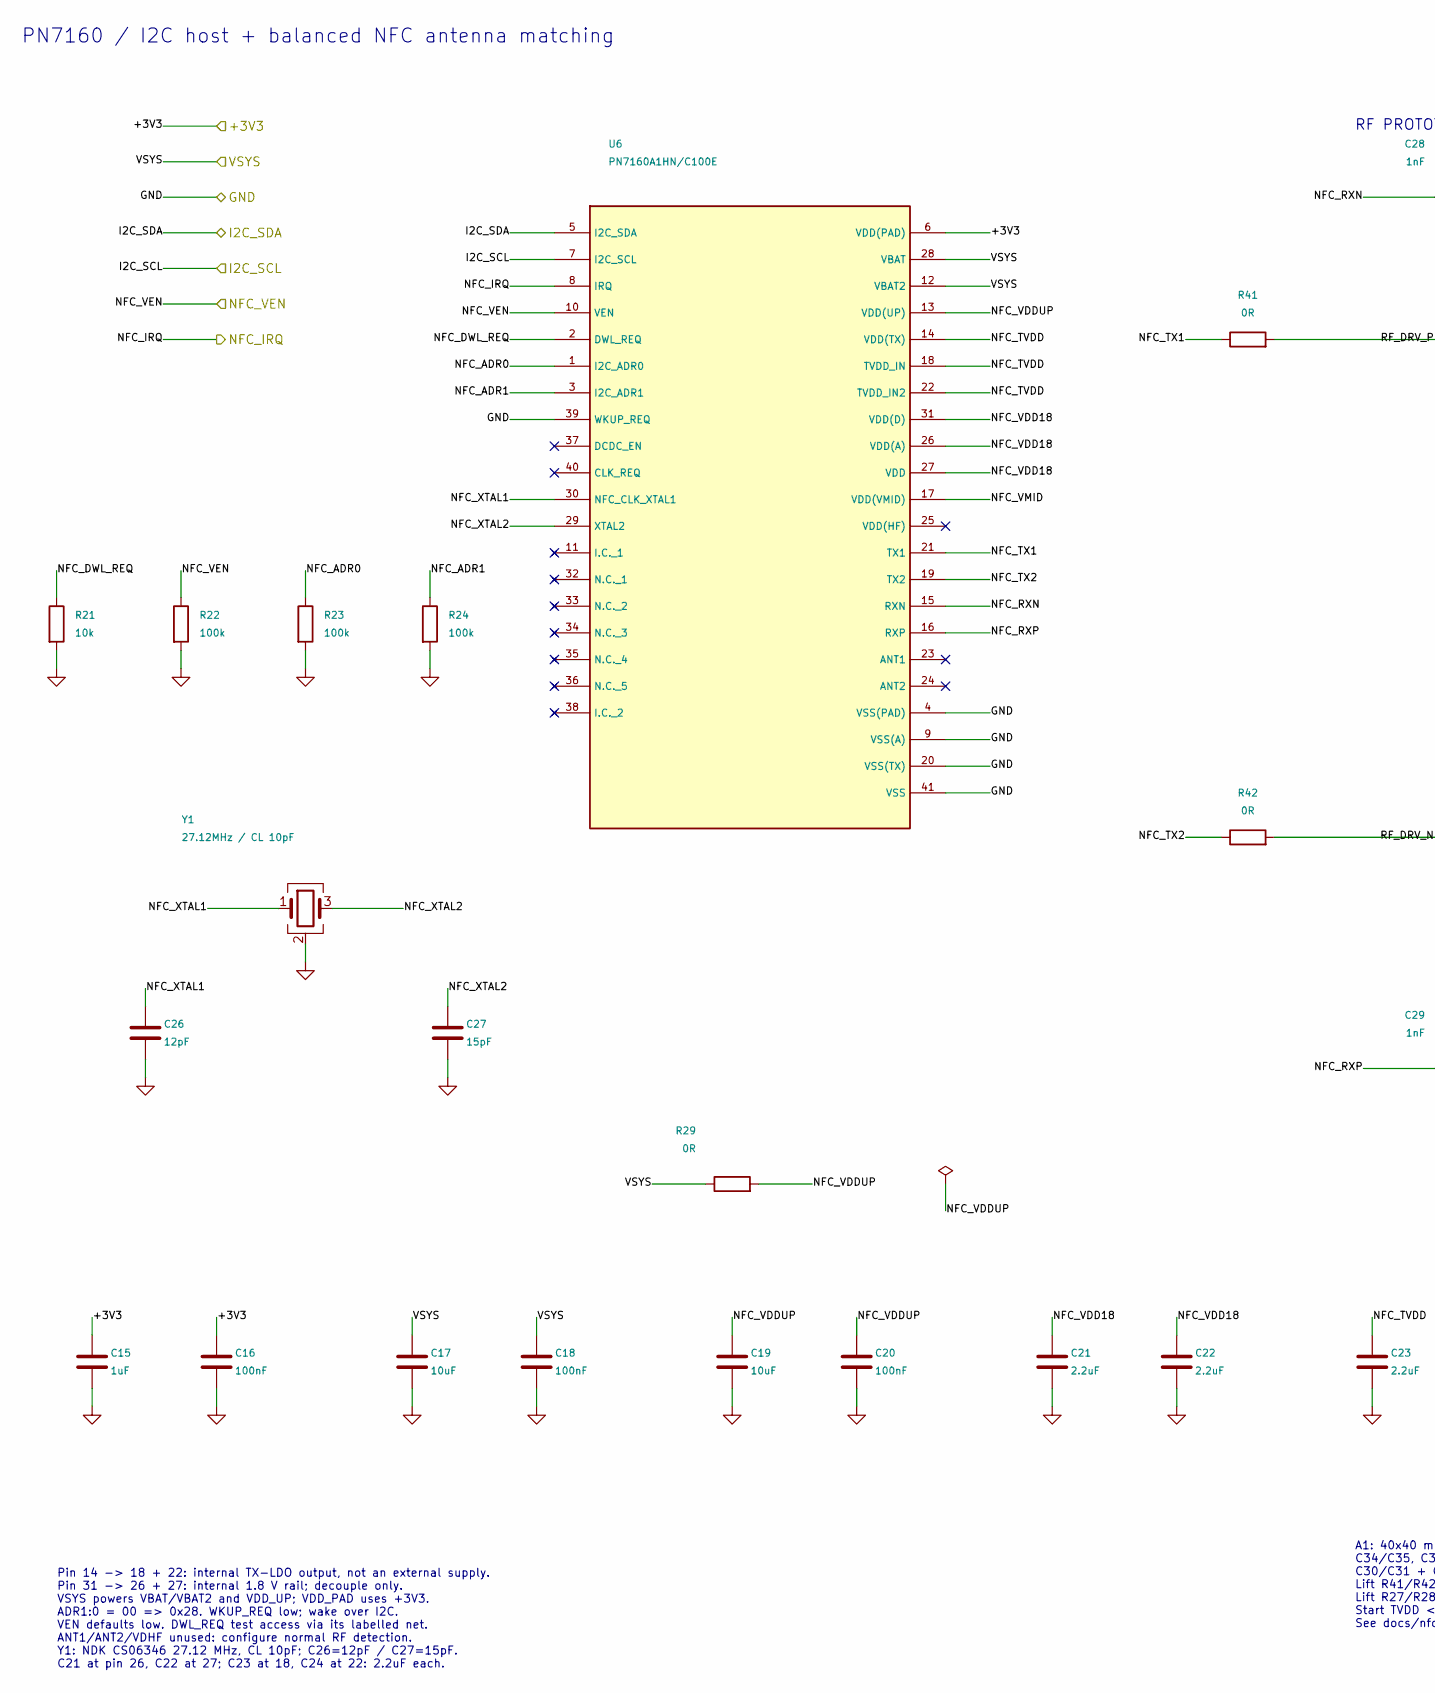
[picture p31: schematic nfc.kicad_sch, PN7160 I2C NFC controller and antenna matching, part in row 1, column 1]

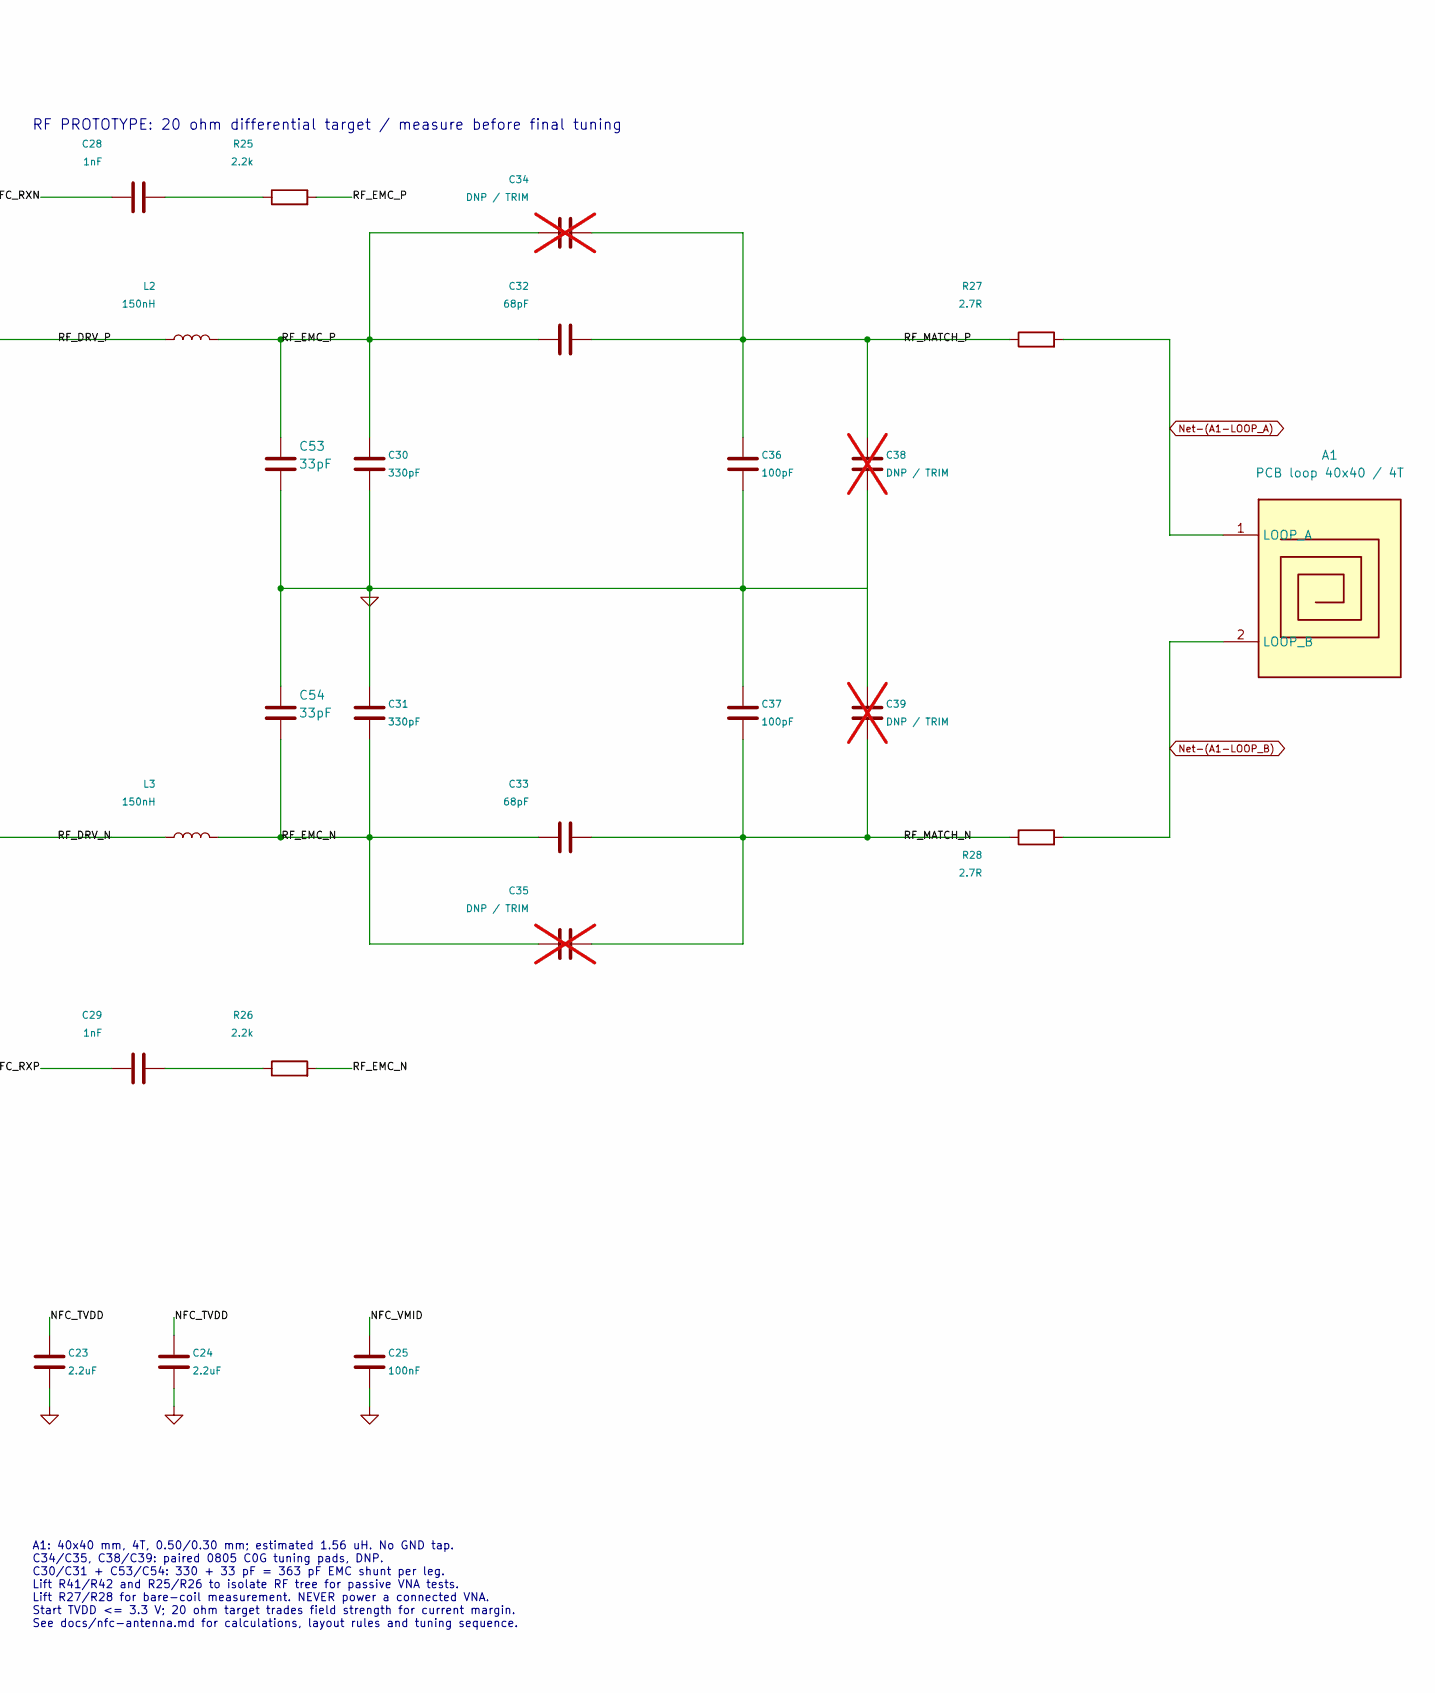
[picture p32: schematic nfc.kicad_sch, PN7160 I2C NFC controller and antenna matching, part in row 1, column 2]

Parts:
A1: PCB loop 40x40 / 4T; NFC_PCB_Loop_40x40_4T_W0.50_S0.30_InsideFeed
C15: 1uF; C_0805_2012Metric; Voltage 50 V; Tolerance 10%; MPN CL21B105KBFNNNE; LCSC C28323
C16, C18, C20, C25: 100nF; C_0603_1608Metric; Voltage 50 V; Tolerance 10%; MPN CL10B104KB8NNNL; LCSC C913912
C17, C19: 10uF; C_1206_3216Metric; Voltage 25 V; Tolerance 10%; MPN CL31B106KAHNNNE; LCSC C14860
C21, C22, C23, C24: 2.2uF; C_0805_2012Metric; Voltage 25 V; Tolerance 10%; MPN CL21B225KAFNNNE; LCSC C19110
C26: 12pF; C_0603_1608Metric; Voltage 50 V; Tolerance 5%; MPN CL10C120JB8NNNC; LCSC C38523
C27: 15pF; C_0603_1608Metric; Voltage 50 V; Tolerance 5%; MPN CL10C150JB8NNNC; LCSC C1644
C28, C29: 1nF; C_0805_2012Metric_Pad1.18x1.45mm_HandSolder; Voltage 100 V; Tolerance 5%; MPN CC0805JRNPO0BN102; LCSC C326940
C30, C31: 330pF; C_0805_2012Metric_Pad1.18x1.45mm_HandSolder; Voltage 100 V; Tolerance 1%; MPN CC0805FRNPO0BN331; LCSC C527075
C32, C33: 68pF; C_0805_2012Metric_Pad1.18x1.45mm_HandSolder; Voltage 100 V; Tolerance 1%; MPN CC0805FRNPO0BN680; LCSC C576904
C34, C35, C38, C39: DNP / TRIM; C_0805_HandSolder_NoPaste; Voltage 100 V; Tolerance <=2% or +/-0.1pF for small trims; not fitted
C36, C37: 100pF; C_0805_2012Metric_Pad1.18x1.45mm_HandSolder; Voltage 100 V; Tolerance 1%; MPN 0805CG101F101NT; LCSC C464454
C53, C54: 33pF; C_0805_2012Metric_Pad1.18x1.45mm_HandSolder; Voltage 100 V; Tolerance 5%; MPN CC0805JRNPO0BN330; LCSC C309485
L2, L3: 150nH; L_Coilcraft_0805CS_RevALands; Tolerance 2%; MPN 0805CS-151XGLC; LCSC C38190612
R21: 10k; R_0603_1608Metric; Tolerance 1%; Rating 0.1 W; MPN 0603WAF1002T5E; LCSC C25804
R22, R23, R24: 100k; R_0603_1608Metric; Tolerance 1%; Rating 0.1 W; MPN 0603WAF1003T5E; LCSC C25803
R25, R26: 2.2k; R_0805_2012Metric_Pad1.20x1.40mm_HandSolder; Tolerance 1%; Rating 0.125 W; MPN 0805W8F2201T5E; LCSC C17520
R27, R28: 2.7R; R_1206_3216Metric_Pad1.30x1.75mm_HandSolder; Tolerance 1%; Rating 0.75 W P70 only with Rth <=110 K/W; lim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; MPN CRCW12062R70FKEAHP; LCSC C2079511
R29: 0R; R_0603_1608Metric; Tolerance 1%; Rating 0.1 W; MPN 0603WAF0000T5E; LCSC C21189
R41, R42: 0R; R_0805_2012Metric_Pad1.20x1.40mm_HandSolder; Rating Jumper: 2 A rated; initial R <50 mOhm; 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; Tolerance Jumper; MPN RC0805JR-070RL; LCSC C96345
U6: PN7160A1HN/C100E; PN7160A1HN_C100E; MPN PN7160A1HN/C100E; LCSC C3303788
Y1: 27.12MHz / CL 10pF; Crystal_NDK_NX2016SA_2.0x1.6mm; MPN NX2016SA-27.12MHZ-EXS00A-CS06346; LCSC C3008209

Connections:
/+3V3: C15.1, C16.1, U6.6 (VDD(PAD)); also elsewhere on the board
/I2C_SCL: U6.7 (I2C_SCL); also elsewhere on the board
/I2C_SDA: U6.5 (I2C_SDA); also elsewhere on the board
/NFC / PN7160 / 0x28/NFC_ADR0: R23.1, U6.1 (I2C_ADR0)
/NFC / PN7160 / 0x28/NFC_ADR1: R24.1, U6.3 (I2C_ADR1)
/NFC / PN7160 / 0x28/NFC_DWL_REQ: R21.1, U6.2 (DWL_REQ)
/NFC / PN7160 / 0x28/NFC_RXN: C28.1, U6.15 (RXN)
/NFC / PN7160 / 0x28/NFC_RXP: C29.1, U6.16 (RXP)
/NFC / PN7160 / 0x28/NFC_TVDD: C23.1, C24.1, U6.14 (VDD(TX)), U6.18 (TVDD_IN), U6.22 (TVDD_IN2)
/NFC / PN7160 / 0x28/NFC_TX1: R41.1, U6.21 (TX1)
/NFC / PN7160 / 0x28/NFC_TX2: R42.1, U6.19 (TX2)
/NFC / PN7160 / 0x28/NFC_VDD18: C21.1, C22.1, U6.26 (VDD(A)), U6.27 (VDD), U6.31 (VDD(D))
/NFC / PN7160 / 0x28/NFC_VDDUP: C19.1, C20.1, R29.2, U6.13 (VDD(UP))
/NFC / PN7160 / 0x28/NFC_VMID: C25.1, U6.17 (VDD(VMID))
/NFC / PN7160 / 0x28/NFC_XTAL1: C26.1, U6.30 (NFC_CLK_XTAL1), Y1.1
/NFC / PN7160 / 0x28/NFC_XTAL2: C27.1, U6.29 (XTAL2), Y1.3
/NFC / PN7160 / 0x28/RF_DRV_N: L3.1, R42.2
/NFC / PN7160 / 0x28/RF_DRV_P: L2.1, R41.2
/NFC / PN7160 / 0x28/RF_EMC_N: C31.2, C33.1, C35.1, C54.2, L3.2, R26.2
/NFC / PN7160 / 0x28/RF_EMC_P: C30.1, C32.1, C34.1, C53.1, L2.2, R25.2
/NFC / PN7160 / 0x28/RF_MATCH_N: C33.2, C35.2, C37.2, C39.2, R28.1
/NFC / PN7160 / 0x28/RF_MATCH_P: C32.2, C34.2, C36.1, C38.1, R27.1
/NFC_IRQ: U6.8 (IRQ); also elsewhere on the board
/NFC_VEN: R22.1, U6.10 (VEN); also elsewhere on the board
/VSYS: C17.1, C18.1, R29.1, U6.12 (VBAT2), U6.28 (VBAT); also elsewhere on the board
GND: C15.2, C16.2, C17.2, C18.2, C19.2, C20.2, C21.2, C22.2, C23.2, C24.2, C25.2, C26.2, C27.2, C30.2, C31.1, C36.2, C37.1, C38.2, C39.1, C53.2, C54.1, R21.2, R22.2, R23.2, R24.2, U6.4 (VSS(PAD)), U6.9 (VSS(A)), U6.20 (VSS(TX)), U6.39 (WKUP_REQ), U6.41 (VSS), Y1.2 (G), Y1.4 (G); also elsewhere on the board
unnamed: A1.1 (LOOP_A), R27.2
unnamed: A1.2 (LOOP_B), R28.2
unnamed: C28.2, R25.1
unnamed: C29.2, R26.1

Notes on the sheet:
PN7160 / I2C host + balanced NFC antenna matching
RF PROTOTYPE: 20 ohm differential target / measure before final tuning
Pin 14 -> 18 + 22: internal TX-LDO output, not an external supply. Pin 31 -> 26 + 27: internal 1.8 V rail; decouple only. VSYS powers VBAT/VBAT2 and VDD_UP; VDD_PAD uses +3V3. ADR1:0 = 00 => 0x28. WKUP_REQ low; wake over I2C. VEN defaults low. DWL_REQ test access via its labelled net. ANT1/ANT2/VDH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
A1: 40x40 mm, 4T, 0.50/0.30 mm; estimated 1.56 uH. No GND tap. C34/C35, C38/C39: paired 0805 C0G tuning pads, DNP. C30/C31 + C53/C54: 330 + 33 pF = 363 pF EMC shunt per leg. Lift R41/R42 and R25/R26 to isolate RF tree for passive VNA tests. Lift R27/R28 for bare-coil measurement. NEVER power a conn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

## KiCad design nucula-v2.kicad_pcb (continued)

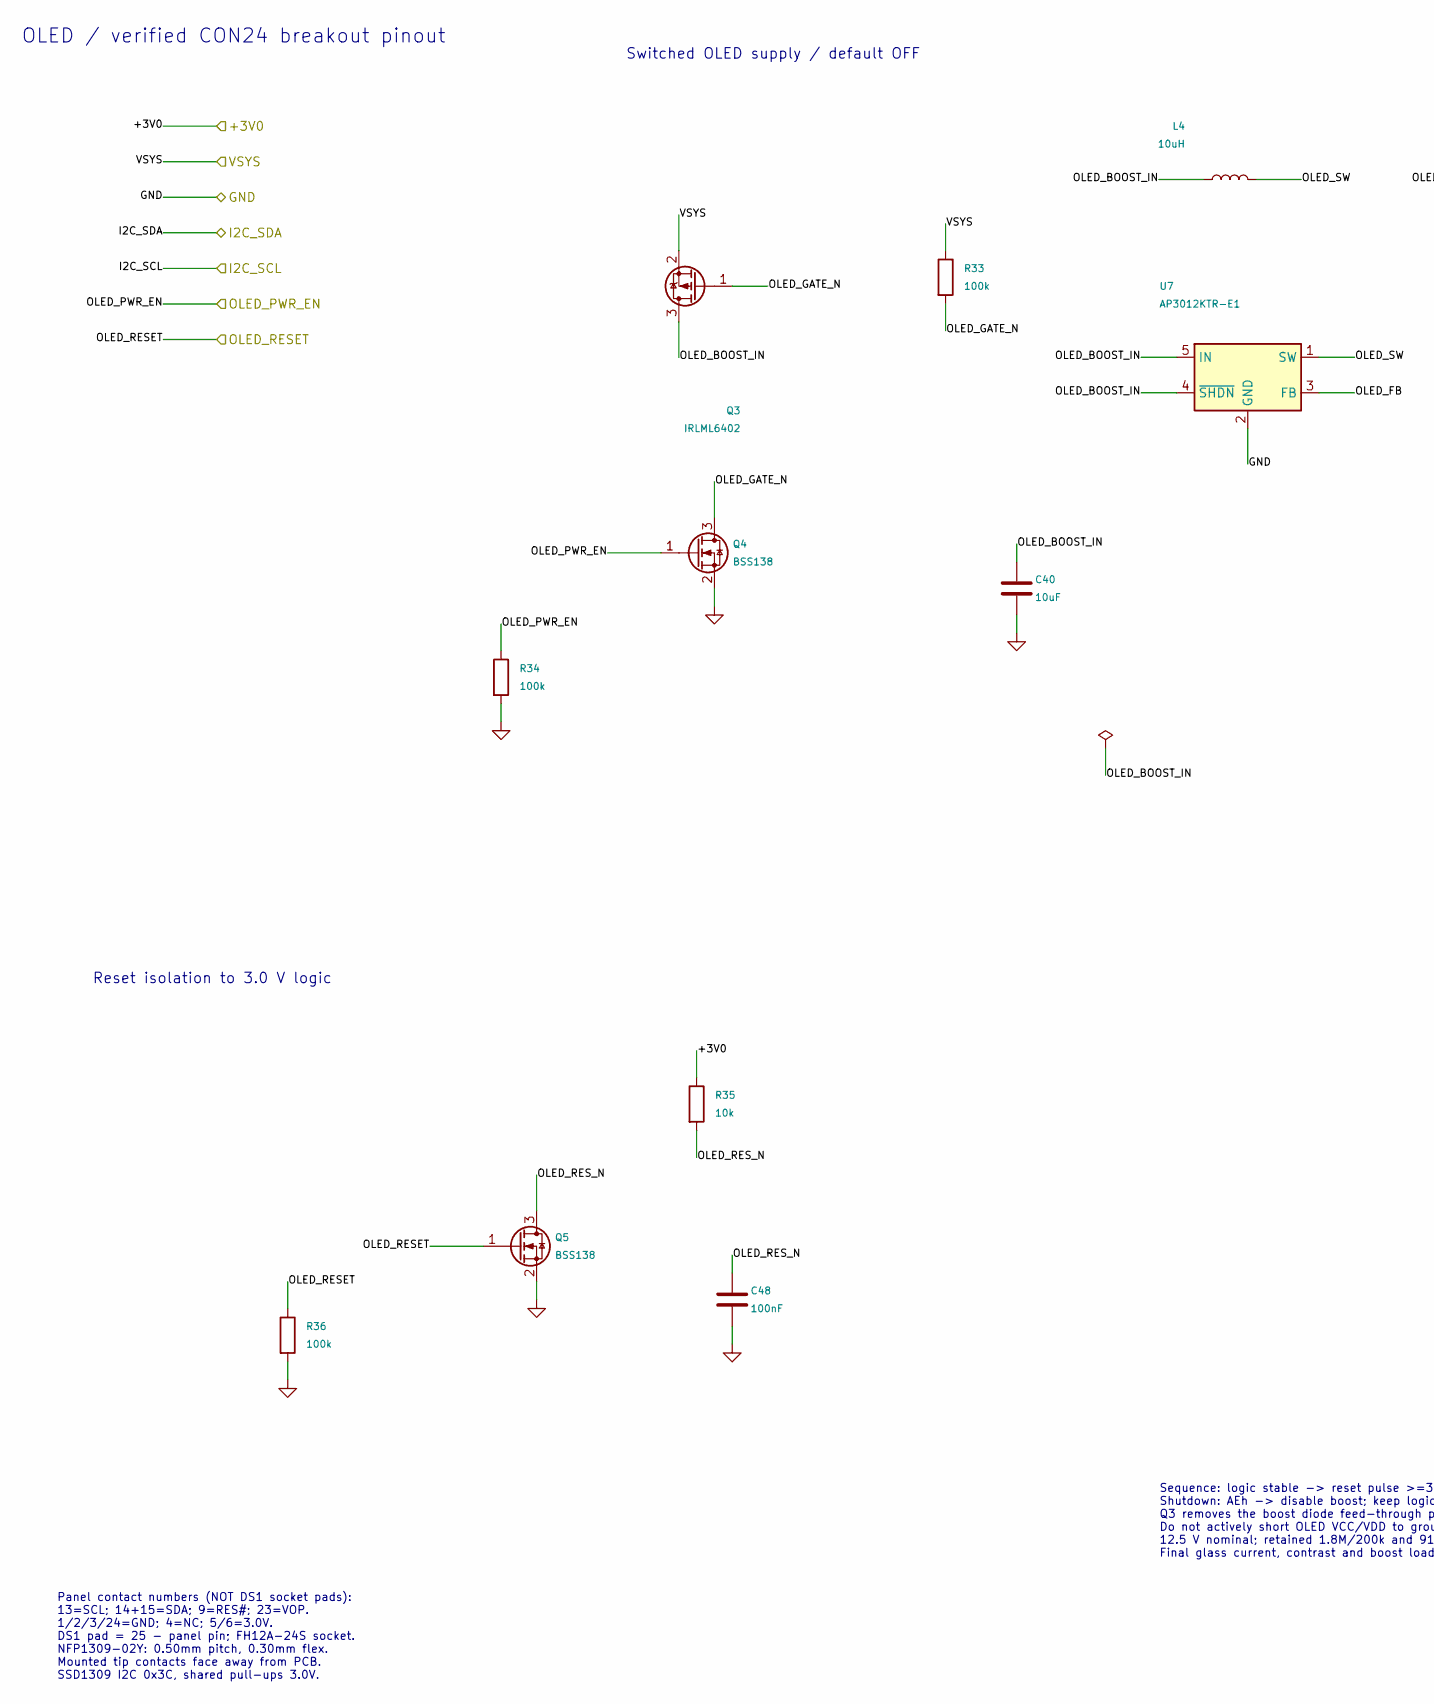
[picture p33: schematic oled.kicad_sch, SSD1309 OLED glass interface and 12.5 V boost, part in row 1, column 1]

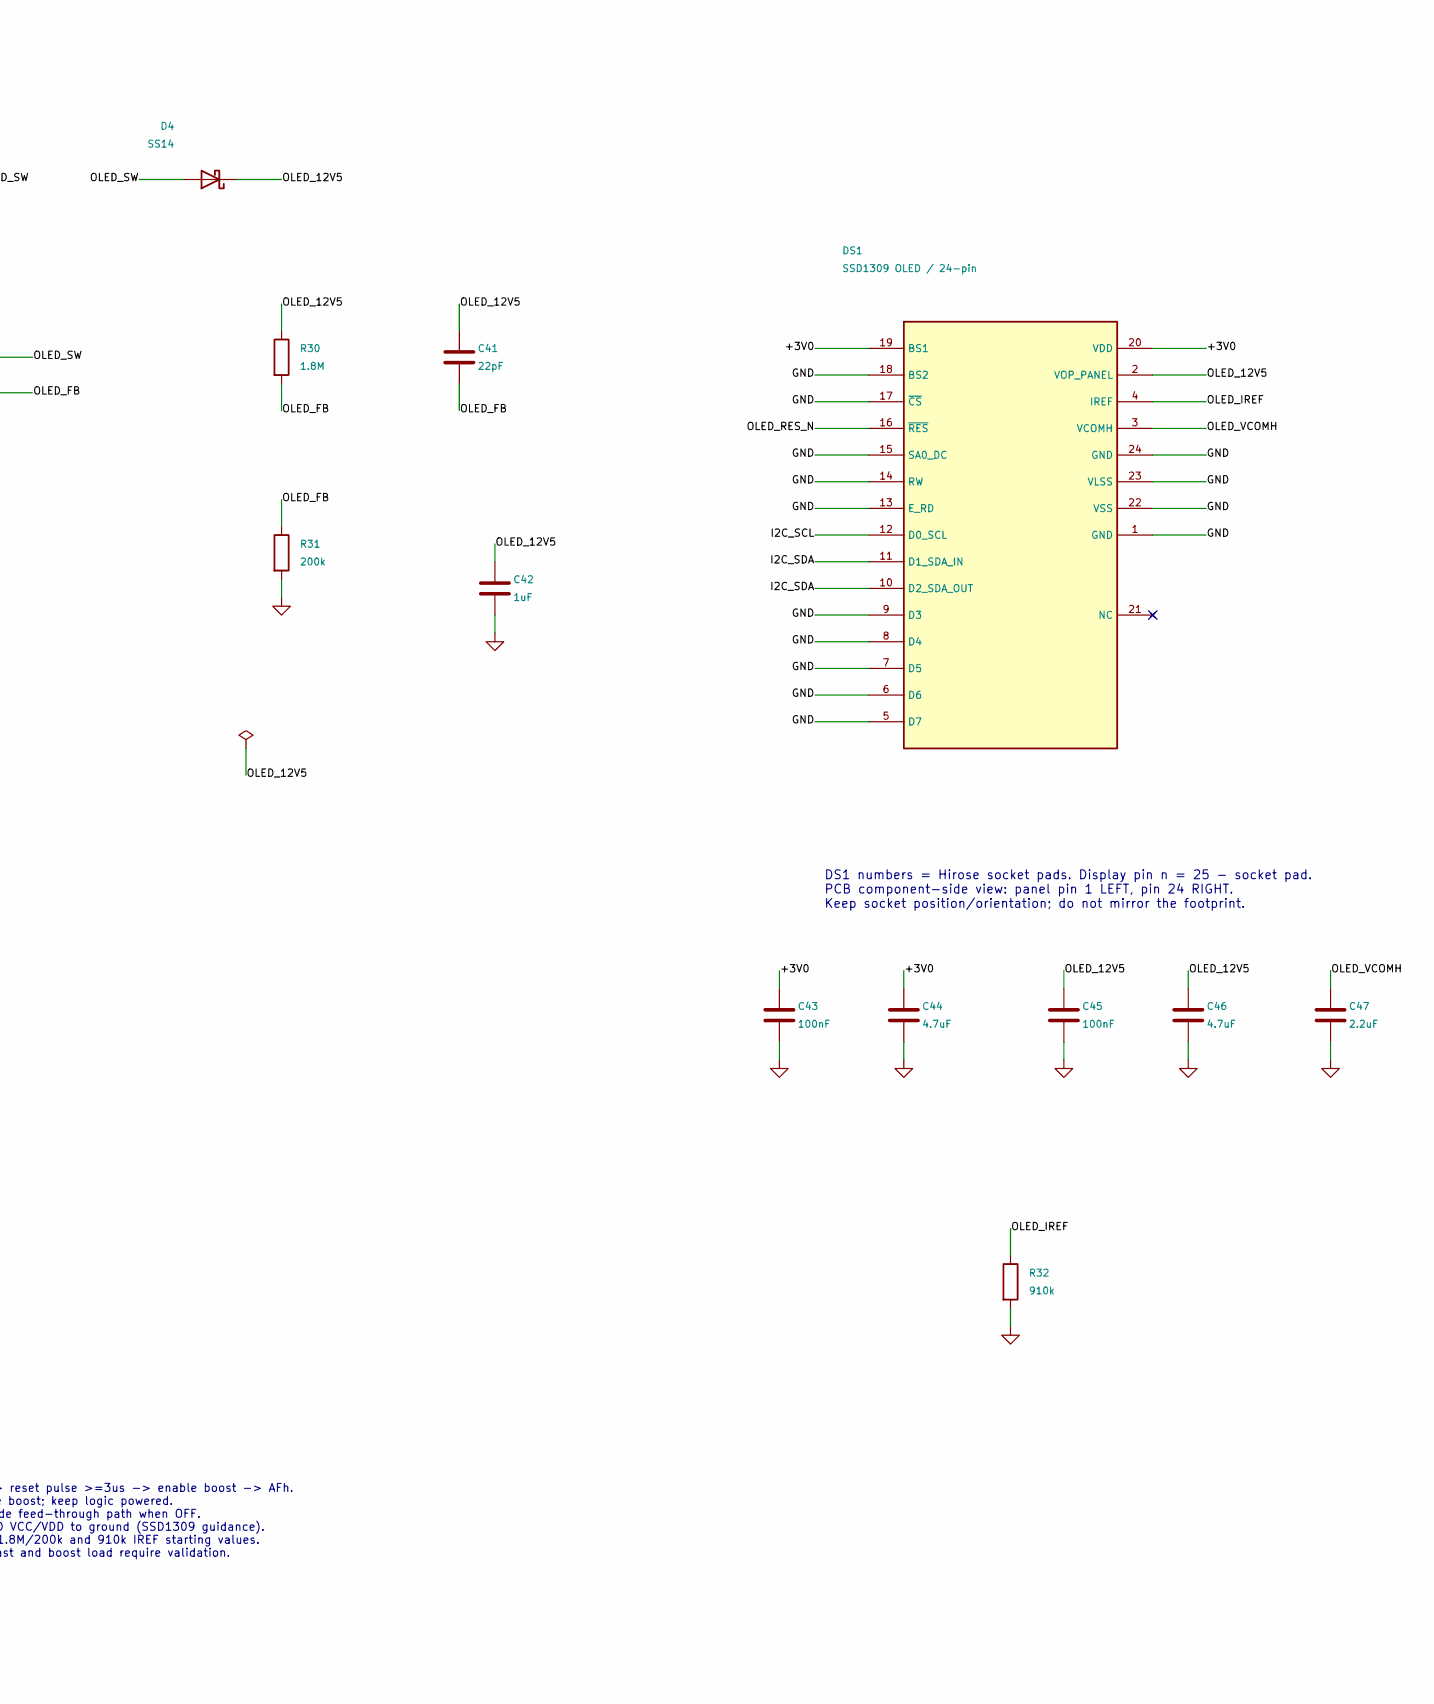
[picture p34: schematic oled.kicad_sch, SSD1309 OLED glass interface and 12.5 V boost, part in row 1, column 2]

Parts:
C40: 10uF; C_1206_3216Metric; Voltage 25 V; Tolerance 10%; MPN CL31B106KAHNNNE; LCSC C14860
C41: 22pF; C_0603_1608Metric; Voltage 50 V; Tolerance 5%; MPN CL10C220JB8NNNC; LCSC C1653
C42: 1uF; C_0805_2012Metric; Voltage 50 V; Tolerance 10%; MPN CL21B105KBFNNNE; LCSC C28323
C43, C45, C48: 100nF; C_0603_1608Metric; Voltage 50 V; Tolerance 10%; MPN CL10B104KB8NNNL; LCSC C913912
C44: 4.7uF; C_0805_2012Metric; Voltage 25 V; Tolerance 10%; MPN CL21B475KAFNNNE; LCSC C98195
C46: 4.7uF; C_1206_3216Metric; Voltage 50 V; Tolerance 10%; MPN CL31B475KBHNNNE; LCSC C51205
C47: 2.2uF; C_0805_2012Metric; Voltage 25 V; Tolerance 10%; MPN CL21B225KAFNNNE; LCSC C19110
D4: SS14; D_SMA; MPN SS14-E3/61T; LCSC C47460
DS1: SSD1309 OLED / 24-pin; Hirose_FH12A-24S-0.5SH_1x24-1MP_P0.50mm_Horizontal; MPN FH12A-24S-0.5SH(55); LCSC C506794
L4: 10uH; L_Coilcraft_LPS4018; Rating Isat 1.1 A at 10% drop; Irms 0.9 A at 2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; MPN LPS4018-103MRC; LCSC C6127589
Q3: IRLML6402; SOT-23; MPN IRLML6402TRPBF; LCSC C2593
Q4, Q5: BSS138; SOT-23; MPN BSS138; LCSC C52895
R30: 1.8M; R_0805_2012Metric; Tolerance 0.1%; Rating 0.1 W; 100 V; 25 ppm/K; MPN CPF0805B1M8E; LCSC C2088132
R31: 200k; R_0603_1608Metric; Tolerance 0.1%; Rating 0.1 W; MPN RT0603BRD07200KL; LCSC C728585
R32: 910k; R_0603_1608Metric; Tolerance 1%; Rating 0.1 W; MPN 0603WAF9103T5E; LCSC C23263
R33, R34, R36: 100k; R_0603_1608Metric; Tolerance 1%; Rating 0.1 W; MPN 0603WAF1003T5E; LCSC C25803
R35: 10k; R_0603_1608Metric; Tolerance 1%; Rating 0.1 W; MPN 0603WAF1002T5E; LCSC C25804
U7: AP3012KTR-E1; SOT-23-5; MPN AP3012KTR-E1; LCSC C460356

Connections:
/+3V0: C43.1, C44.1, DS1.19 (BS1), DS1.20 (VDD), R35.1; also elsewhere on the board
/I2C_SCL: DS1.12 (D0_SCL); also elsewhere on the board
/I2C_SDA: DS1.10 (D2_SDA_OUT), DS1.11 (D1_SDA_IN); also elsewhere on the board
/OLED / SSD1309 / 0x3C/OLED_12V5: C41.1, C42.1, C45.1, C46.1, D4.1 (K), DS1.2 (VOP_PANEL), R30.1
/OLED / SSD1309 / 0x3C/OLED_BOOST_IN: C40.1, L4.1, Q3.3 (D), U7.4 (~SHDN), U7.5 (IN)
/OLED / SSD1309 / 0x3C/OLED_FB: C41.2, R30.2, R31.1, U7.3 (FB)
/OLED / SSD1309 / 0x3C/OLED_GATE_N: Q3.1 (G), Q4.3 (D), R33.2
/OLED / SSD1309 / 0x3C/OLED_IREF: DS1.4 (IREF), R32.1
/OLED / SSD1309 / 0x3C/OLED_RES_N: C48.1, DS1.16 (~RES), Q5.3 (D), R35.2
/OLED / SSD1309 / 0x3C/OLED_SW: D4.2 (A), L4.2, U7.1 (SW)
/OLED / SSD1309 / 0x3C/OLED_VCOMH: C47.1, DS1.3 (VCOMH)
/OLED_PWR_EN: Q4.1 (G), R34.1; also elsewhere on the board
/OLED_RESET: Q5.1 (G), R36.1; also elsewhere on the board
/VSYS: Q3.2 (S), R33.1; also elsewhere on the board
GND: C40.2, C42.2, C43.2, C44.2, C45.2, C46.2, C47.2, C48.2, DS1.1 (GND), DS1.5 (D7), DS1.6 (D6), DS1.7 (D5), DS1.8 (D4), DS1.9 (D3), DS1.13 (E_RD), DS1.14 (RW), DS1.15 (SA0_DC), DS1.17 (~CS), DS1.18 (BS2), DS1.22 (VSS), DS1.23 (VLSS), DS1.24 (GND), Q4.2 (S), Q5.2 (S), R31.2, R32.2, R34.2, R36.2, U7.2 (GND); also elsewhere on the board

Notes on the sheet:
OLED / verified CON24 breakout pinout
Switched OLED supply / default OFF
Reset isolation to 3.0 V logic
Panel contact numbers (NOT DS1 socket pads): 13=SCL; 14+15=SDA; 9=RES#; 23=VOP. 1/2/3/24=GND; 4=NC; 5/6=3.0V. DS1 pad = 25 - panel pin; FH12A-24S socket. NFP1309-02Y: 0.50mm pitch, 0.30mm flex. Mounted tip contacts face away from PCB. SSD1309 I2C 0x3C, shared pull-ups 3.0V.
Sequence: logic stable -> reset pulse >=3us -> enable boost -> AFh. Shutdown: AEh -> disable boost; keep logic powered. Q3 removes the boost diode feed-through path when OFF. Do not actively short OLED VCC/VDD to ground (SSD1309 guidance). 12.5 V nominal; retained 1.8M/200k and 910k IREF starting v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
DS1 numbers = Hirose socket pads. Display pin n = 25 - socket pad. PCB component-side view: panel pin 1 LEFT, pin 24 RIGHT. Keep socket position/orientation; do not mirror the footprint.

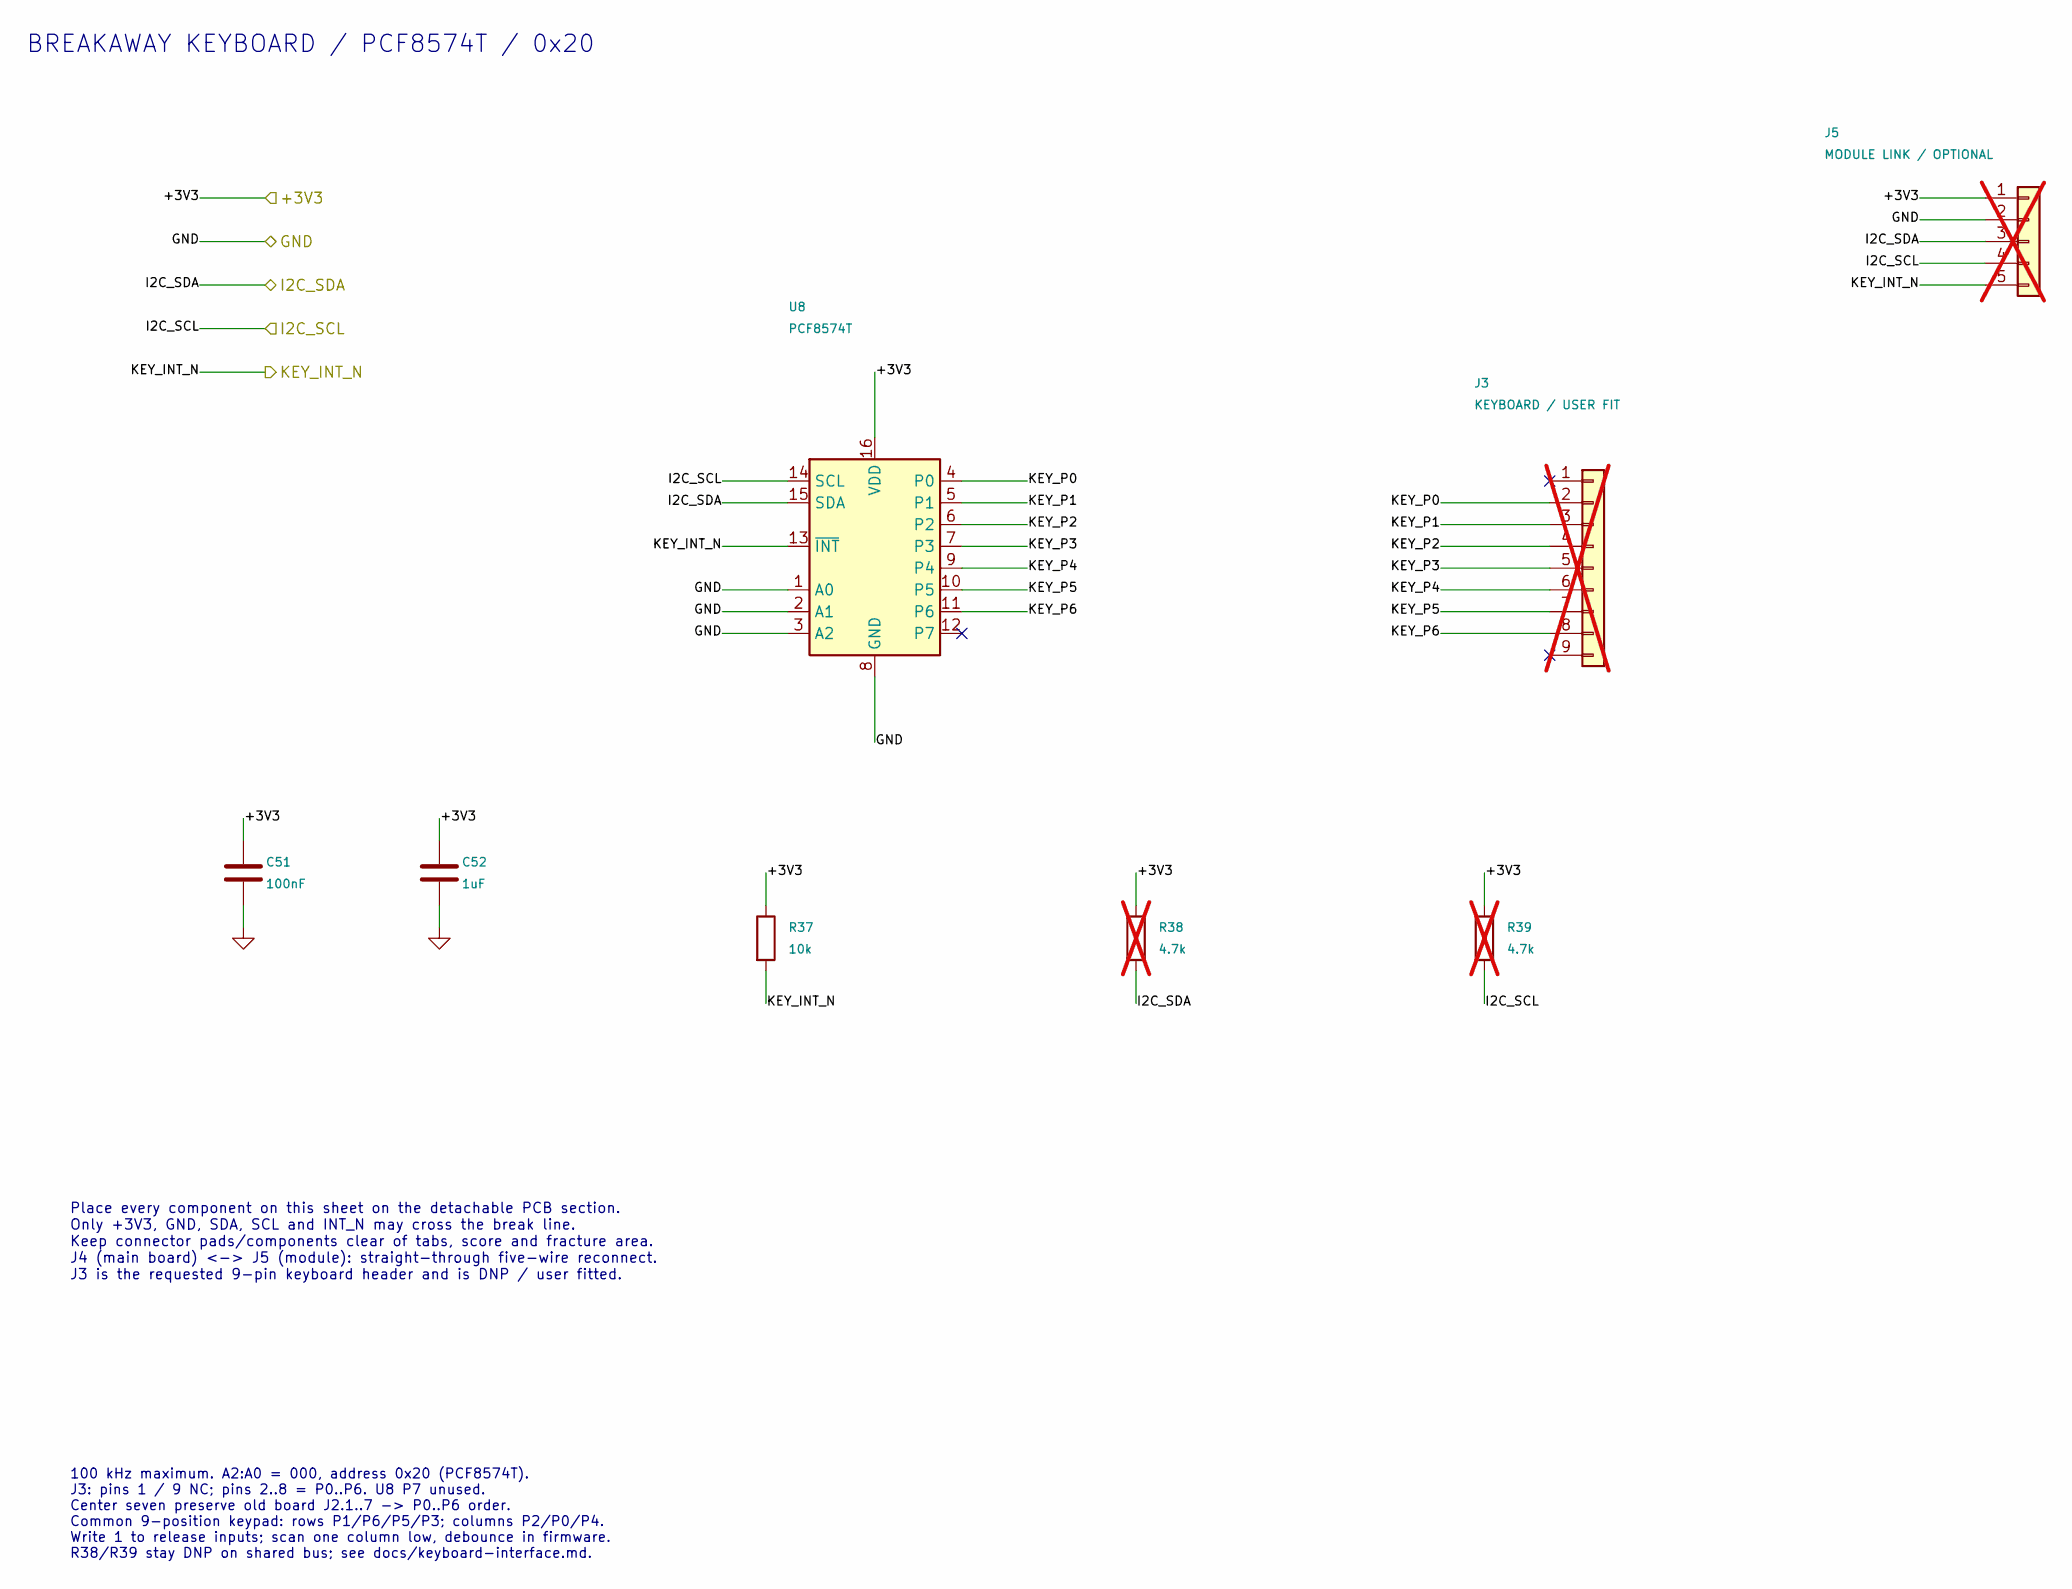
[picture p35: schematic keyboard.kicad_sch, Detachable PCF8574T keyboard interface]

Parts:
C51: 100nF; C_0603_1608Metric; Voltage 50 V; Tolerance 10%; MPN CL10B104KB8NNNL; LCSC C913912
C52: 1uF; C_0805_2012Metric; Voltage 50 V; Tolerance 10%; MPN CL21B105KBFNNNE; LCSC C28323
J3: KEYBOARD / USER FIT; PinHeader_1x09_P2.54mm_Vertical; not fitted
J5: MODULE LINK / OPTIONAL; PinHeader_1x05_P2.54mm_Vertical; not fitted
R37: 10k; R_0603_1608Metric; Tolerance 1%; Rating 0.1 W; MPN 0603WAF1002T5E; LCSC C25804
R38, R39: 4.7k; R_0603_1608Metric; Tolerance 1%; Rating 0.1 W; not fitted
U8: PCF8574T; SOIC-16W_7.5x10.3mm_P1.27mm; MPN PCF8574T/3,518; LCSC C7605

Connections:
/+3V3: C51.1, C52.1, J5.1, R37.1, R38.1, R39.1, U8.16 (VDD); also elsewhere on the board
/I2C_SCL: J5.4, R39.2, U8.14 (SCL); also elsewhere on the board
/I2C_SDA: J5.3, R38.2, U8.15 (SDA); also elsewhere on the board
/KEY_INT_N: J5.5, R37.2, U8.13 (~INT); also elsewhere on the board
/Keyboard / breakaway / 0x20/KEY_P0: J3.2, U8.4 (P0)
/Keyboard / breakaway / 0x20/KEY_P1: J3.3, U8.5 (P1)
/Keyboard / breakaway / 0x20/KEY_P2: J3.4, U8.6 (P2)
/Keyboard / breakaway / 0x20/KEY_P3: J3.5, U8.7 (P3)
/Keyboard / breakaway / 0x20/KEY_P4: J3.6, U8.9 (P4)
/Keyboard / breakaway / 0x20/KEY_P5: J3.7, U8.10 (P5)
/Keyboard / breakaway / 0x20/KEY_P6: J3.8, U8.11 (P6)
GND: C51.2, C52.2, J5.2, U8.1 (A0), U8.2 (A1), U8.3 (A2), U8.8 (GND); also elsewhere on the board

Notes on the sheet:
BREAKAWAY KEYBOARD / PCF8574T / 0x20
Place every component on this sheet on the detachable PCB section. Only +3V3, GND, SDA, SCL and INT_N may cross the break line. Keep connector pads/components clear of tabs, score and fracture area. J4 (main board) <-> J5 (module): straight-through five-wire reconnect. J3 is the requested 9-pin key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
100 kHz maximum. A2:A0 = 000, address 0x20 (PCF8574T). J3: pins 1 / 9 NC; pins 2..8 = P0..P6. U8 P7 unused. Center seven preserve old board J2.1..7 -> P0..P6 order. Common 9-position keypad: rows P1/P6/P5/P3; columns P2/P0/P4. Write 1 to release inputs; scan one column low, debounce in firmware. R3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

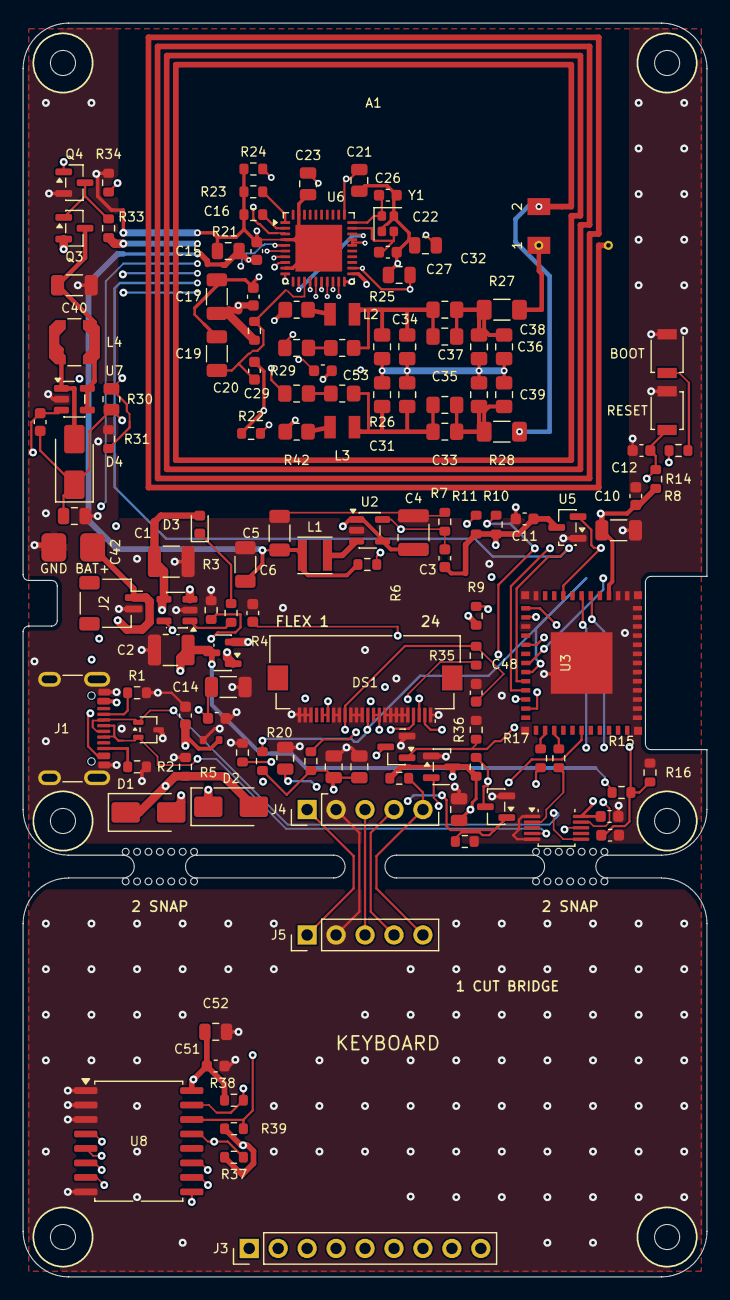
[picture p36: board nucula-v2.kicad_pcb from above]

Board: 4 copper layers, 60.0 x 110.0 mm, 138 parts (0 on the bottom side), 72 nets.

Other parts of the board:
H1, H2, H3, H4, H5, H6: M2 2.2mm NPTH; MountingHole_2.2mm_M2_5.5mm_Keepout
MB1, MB2: MouseBite_2Rows7_D0.60_P1.00_Inset_Gap2.00

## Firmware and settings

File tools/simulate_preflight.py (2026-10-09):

#!/usr/bin/env python3
"""Run scoped ngspice checks using the saved design's values and connectivity.

Requires numpy/matplotlib and shared ngspice (KiCad bundles it on macOS).
This does not simulate firmware, complete ICs, or extract PCB parasitics.
Generated circuits, measurements and plots go to docs/simulation by default.
"""
import argparse
import csv
import ctypes as ct
import hashlib
import itertools
import json
import math
import os
from pathlib import Path
import re
import subprocess
import xml.etree.ElementTree as ET

import numpy as np
import matplotlib
matplotlib.use('Agg')
import matplotlib.pyplot as plt

from kicad_sexpr import parse, child, children, uq
from nfc.inductor_models import MODELS

ROOT = Path(__file__).resolve().parents[1]
F0 = 13.56e6
RF_REFS = ['R41', 'R42', 'L2', 'L3', 'C28', 'C29', 'C30', 'C31',
           'C32', 'C33', 'C34', 'C35', 'C36', 'C37', 'C38', 'C39',
           'C53', 'C54', 'R25', 'R26', 'R27', 'R28']


def sha(path):
    return hashlib.sha256(path.read_bytes()).hexdigest()


class Design:
    def __init__(self):
        verification = json.loads((ROOT / 'docs/verification.json').read_text())
        for name, expected in verification['schematic_sha256'].items():
            assert sha(ROOT / name) == expected, 'Refresh schematic checks first: ' + name
        tree = ET.parse(ROOT / 'docs/netlist.xml').getroot()
        self.parts = {c.get('ref'): c for c in tree.find('components')}
        self.nets = {n.get('name'): n for n in tree.find('nets')}
        self.nodes = {name: 'n' + n.get('code') for name, n in self.nets.items()}
        self.nodes['GND'] = '0'
        self.pin_nets = {(p.get('ref'), p.get('pin')): name
                         for name, n in self.nets.items() for p in n.findall('node')}
        self.dnp = {r for r, p in self.parts.items()
                    if any(x.get('name') == 'dnp' for x in p.findall('property'))}
        # Compare actual PCB pad nets, values and population to the exported schematic.
        pcb = parse((ROOT / 'nucula-v2.kicad_pcb').read_text())
        seen = set()
        for fp in children(pcb, 'footprint'):
            props = {uq(p[1]): uq(p[2]) for p in children(fp, 'property')}
            ref = props['Reference']
            if ref not in self.parts:
                continue  # Mechanical mouse-bite patterns.
            seen.add(ref)
            assert props['Value'] == self.parts[ref].findtext('value'), ref
            attrs = children(fp, 'attr')
            assert bool(attrs and 'dnp' in attrs[0]) == (ref in self.dnp), ref
            for pad in children(fp, 'pad'):
                key = (ref, uq(pad[1]))
                if key in self.pin_nets:
                    net = child(pad, 'net')
                    assert uq(net[-1]).replace('{slash}', '/') == self.pin_nets[key], key
        assert seen == set(self.parts)

    def node(self, ref, pin):
        return self.nodes[self.pin_nets[ref, str(pin)]]

    def value(self, ref):
        value = self.parts[ref].findtext('value')
        match = re.fullmatch(r'([\d.]+)([RkMmunp]?)(?:[FH])?', value)
        assert match, (ref, value)
        scale = {'': 1, 'R': 1, 'k': 1e3, 'M': 1e6, 'm': 1e-3,
                 'u': 1e-6, 'n': 1e-9, 'p': 1e-12}[match[2]]
        return float(match[1]) * scale

    def tolerance(self, ref):
        fields = {p.get('name'): p.get('value') for p in self.parts[ref].findall('property')}
        return float(fields['Tolerance'].removesuffix('%')) / 100

    def passive(self, ref, scale=1):
        assert ref not in self.dnp
        return f'{ref} {self.node(ref, 1)} {self.node(ref, 2)} {self.value(ref)*scale:.15g}'


class Ngspice:
    class Complex(ct.Structure):
        _fields_ = [('real', ct.c_double), ('imag', ct.c_double)]

    class Vector(ct.Structure):
        pass

    Vector._fields_ = [('name', ct.c_char_p), ('type', ct.c_int), ('flags', ct.c_short),
                      ('real', ct.POINTER(ct.c_double)), ('complex', ct.POINTER(Complex)),
                      ('length', ct.c_int)]

    def __init__(self):
        libpath = os.environ.get('NGSPICE_LIBRARY',
            '/Applications/KiCad/KiCad.app/Contents/Frameworks/libngspice.0.dylib')
        self.lib = ct.CDLL(libpath)
        self.log, self.exits = [], []
        send_type = ct.CFUNCTYPE(ct.c_int, ct.c_char_p, ct.c_int, ct.c_void_p)
        exit_type = ct.CFUNCTYPE(ct.c_int, ct.c_int, ct.c_bool, ct.c_bool, ct.c_int, ct.c_void_p)
        self.send = send_type(lambda msg, *_: self.log.append(msg.decode(errors='replace')) or 0)
        self.exited = exit_type(lambda code, *_: self.exits.append(code) or 0)
        self.lib.ngSpice_Init.argtypes = [ct.c_void_p] * 7
        assert self.lib.ngSpice_Init(self.send, None, self.exited, None, None, None, None) == 0
        self.lib.ngSpice_Command.argtypes = [ct.c_char_p]
        self.lib.ngSpice_Circ.argtypes = [ct.POINTER(ct.c_char_p)]
        self.lib.ngGet_Vec_Info.argtypes = [ct.c_char_p]
        self.lib.ngGet_Vec_Info.restype = ct.POINTER(self.Vector)
        self.command('version')
        self.version = [s for s in self.log if 'ngspice-' in s]
        self.count = 0

    def command(self, text):
        assert self.lib.ngSpice_Command(text.encode()) == 0, text

    def run(self, lines):
        self.command('destroy all')
        start = len(self.log)
        data = (ct.c_char_p * (len(lines)+1))(*[s.encode() for s in lines], None)
        assert self.lib.ngSpice_Circ(data) == 0
        self.command('run')
        problems = [s for s in self.log[start:] if re.search(
            r'error|fatal|timestep too small|singular matrix|no convergence', s, re.I)]
        assert not problems and not self.exits, problems or self.exits
        self.count += 1

    def get(self, name):
        p = self.lib.ngGet_Vec_Info(name.lower().encode())
        assert p, name
        v = p.contents
        assert v.length > 0, name
        if v.complex:
            data = np.array([complex(v.complex[i].real, v.complex[i].imag) for i in range(v.length)])
        else:
            data = np.ctypeslib.as_array(v.real, shape=(v.length,)).copy()
        assert np.all(np.isfinite(data)), name
        return data


def save_circuit(out, name, lines):
    (out / (name + '.cir')).write_text('\n'.join(lines) + '\n')


def crossing(t, v, level, after=0):
    indices = np.flatnonzero((t[:-1] >= after) & (v[:-1] < level) & (v[1:] >= level))
    assert len(indices), (level, float(v.min()), float(v.max()))
    i = indices[0]
    return float(t[i] + (t[i+1]-t[i]) * (level-v[i]) / (v[i+1]-v[i]))


def rf_circuit(d, params, scales=None, sweep=False, inductor_mpn=None):
    scales = scales or {}
    lines = ['Nucula current schematic: passive NFC network',
             '* Ideal balanced 1 V differential AC excitation; no PN7160 macro-model.',
             '* Coil RL || C is an assumed scenario, NOT extracted from the routed PCB.',
             '* Coilcraft loss frozen at 13.56 MHz; sweeps are approximate away from f0.',
             f'VP {d.node("U6",21)} 0 DC 0 AC .5 0',
             f'VN {d.node("U6",19)} 0 DC 0 AC .5 180']
    for ref in RF_REFS:
        if ref in d.dnp:
            continue
        a, b = d.node(ref, 1), d.node(ref, 2)
        value = d.value(ref) * scales.get(ref, 1.)
        if ref.startswith('C'):
            esr = params.get('cap_esr_by_ref', {}).get(ref, .03)
            lines += [f'R_esr_{ref} {a} x_{ref} {esr:.15g}', f'{ref} x_{ref} {b} {value:.15g}']
        elif ref.startswith('L'):
            mpn = inductor_mpn or d.parts[ref].find("property[@name='MPN']").get('value')
            m = MODELS[mpn]  # Unknown parts must not silently inherit the original model.
            lines += [f'R_dc_{ref} {a} x_{ref} {m["rdc"]}',
                      f'R_skin_{ref} x_{ref} y_{ref} {m["k"]*math.sqrt(F0):.15g}',
                      f'{ref} y_{ref} {b} {m["l"]*(value/150e-9):.15g}',
                      f'C_par_{ref} x_{ref} z_{ref} {m["c"]}', f'R_par_{ref} z_{ref} {b} {m["rpar"]}']
        else:
            # A micro-ohm numerical short; actual jumper/trace impedance is unknown.
            lines.append(f'{ref} {a} {b} {max(value, 1e-6):.15g}')
    a, b = d.node('A1', 1), d.node('A1', 2)
    lines += [f'Ra {a} coil_inner {params["ra"]:.15g}',
              f'La coil_inner {b} {params["la"]:.15g}',
              f'Ca {a} {b} {params["ca"]:.15g}',
              f'R_rxn {d.node("U6",15)} 0 {params.get("rin",2200):.15g}',
              f'R_rxp {d.node("U6",16)} 0 {params.get("rin",2200):.15g}']
    if params.get('extra_shunt', 0):
        for ref in ['R27', 'R28']:
            lines.append(f'C_stray_{ref} {d.node(ref,1)} 0 {params["extra_shunt"]:.15g}')
    lines += ['.options reltol=1e-7 abstol=1e-12',
              '.ac lin 801 10Meg 18Meg' if sweep else '.ac lin 1 13.56Meg 13.56Meg', '.end']
    return lines


def rf_result(ng, d):
    z = 2 / (ng.get('vn#branch') - ng.get('vp#branch'))
    current = abs(ng.get('la#branch'))
    coil = abs(ng.get(d.node('A1', 1)) - ng.get(d.node('A1', 2)))
    drive_rms = 2 * math.sqrt(2) * 3.3 / math.pi
    return dict(z_real_ohm=float(z[0].real), z_imag_ohm=float(z[0].imag),
                z_abs_ohm=float(abs(z[0])),
                coil_rms_A_at_3V3_fundamental=float(current[0]*drive_rms),
                coil_peak_V_at_3V3_fundamental=float(coil[0]*drive_rms*math.sqrt(2)))


def run_rf(ng, d, out):
    old = json.loads((ROOT / 'docs/nfc/calculations.json').read_text())
    model = old['fitted_model_assumptions']
    base = dict(la=model['la_uH']*1e-6, ra=model['ra_ohm'], ca=model['ca_pF']*1e-12)
    scenarios = [('nominal_assumed_coil', base),
                 ('coil_L_minus_10pct', dict(base, la=base['la']*.9)),
                 ('coil_L_plus_10pct', dict(base, la=base['la']*1.1)),
                 ('extra_1pF_each_match_node', dict(base, extra_shunt=1e-12)),
                 ('extra_3pF_each_match_node', dict(base, extra_shunt=3e-12)),
                 ('rx_load_1k', dict(base, rin=1000)),
                 ('rx_load_10k', dict(base, rin=10000))]
    for la, ra, ca in itertools.product([.9, 1.1], [1., 2.5], [1e-12, 5e-12]):
        scenarios.append((f'coil_L{la:g}_R{ra:g}_C{ca*1e12:g}p', dict(la=base['la']*la, ra=ra, ca=ca)))
    rows = []
    for name, params in scenarios:
        lines = rf_circuit(d, params)
        if name == scenarios[0][0]:
            save_circuit(out, 'nfc-nominal', lines)
        ng.run(lines)
        rows.append(dict(scenario=name, **params, **rf_result(ng, d)))
    # Independent earlier half-circuit calculation checks extraction and factor-of-two.
    expected = complex(old['assembly']['z_diff_real_ohm'], old['assembly']['z_diff_imag_ohm'])
    actual = complex(rows[0]['z_real_ohm'], rows[0]['z_imag_ohm'])
    rel = abs(actual-expected)/abs(expected)
    assert rel < 1e-6, (actual, expected)
    rng = np.random.default_rng(7160)
    tolerance_rows = []
    populated = [ref for ref in RF_REFS if ref not in d.dnp and d.value(ref) > 0]
    for i in range(200):
        scales = {ref: 1+rng.uniform(-d.tolerance(ref), d.tolerance(ref)) for ref in populated}
        ng.run(rf_circuit(d, base, scales))
        tolerance_rows.append(dict(case=i, **rf_result(ng, d)))
    fig, ax = plt.subplots(1, 2, figsize=(11, 4.3), layout='constrained')
    frequency_rows = []
    for name, params in scenarios[:3]:
        lines = rf_circuit(d, params, sweep=True)
        ng.run(lines)
        z = 2/(ng.get('vn#branch')-ng.get('vp#branch'))
        f = ng.get('frequency').real/1e6
        ax[0].plot(f, abs(z), label=name.replace('_', ' '))
        frequency_rows.extend(dict(scenario=name, frequency_Hz=float(freq*1e6),
                                   z_real_ohm=float(zz.real), z_imag_ohm=float(zz.imag))
                              for freq, zz in zip(f, z))
    ax[0].axvline(13.56, color='grey', ls=':')
    ax[0].axhline(20, color='grey', ls='--', label='20 ohm design target')
    ax[0].set(xlabel='Frequency (MHz)', ylabel='Differential |Z| (ohm)', ylim=(0, 100),
              title='Coil sensitivity; PCB parasitics unextracted')
    ax[0].legend(fontsize=7)
    ax[1].scatter([r['z_real_ohm'] for r in tolerance_rows],
                  [r['z_imag_ohm'] for r in tolerance_rows], s=10, alpha=.55)
    ax[1].scatter([actual.real], [actual.imag], marker='x', c='black', label='Nominal')
    ax[1].set(xlabel='Resistance (ohm)', ylabel='Reactance (ohm)',
              title='Independent part tolerances at 13.56 MHz\n200 assumed uniform samples; fixed coil')
    ax[1].legend()
    fig.savefig(out / 'nfc-sensitivity.png', dpi=160)
    plt.close(fig)
    for name, data in [('nfc-scenarios.csv', rows), ('nfc-part-tolerances.csv', tolerance_rows),
                       ('nfc-frequency-sweeps.csv', frequency_rows)]:
        fields = list(dict.fromkeys(k for r in data for k in r))
        with (out/name).open('w') as f:
            writer = csv.DictWriter(f, fieldnames=fields, lineterminator='\n')
            writer.writeheader(); writer.writerows(data)
    return dict(nominal=rows[0], scenarios=rows, half_circuit_relative_difference=rel,
                part_tolerance_samples=200, random_seed=7160,
                tolerance_ranges={key: [min(r[key] for r in tolerance_rows),
                                        max(r[key] for r in tolerance_rows)]
                                  for key in ['z_real_ohm', 'z_imag_ohm', 'coil_peak_V_at_3V3_fundamental']},
                scope='Passive schematic with ideal TX and assumed RX/coil loads; no EM extraction, active RF or tag model.')


def run_i2c(ng, d, out):
    assert {'R38', 'R39'} <= d.dnp
    results = []
    fig, ax = plt.subplots(figsize=(7.5, 4.4), layout='constrained')
    for ref, cap in itertools.product(['R19', 'R20'], [100e-12, 200e-12, 400e-12, 600e-12]):
        supply, bus = d.node(ref, 1), d.node(ref, 2)
        scale = 1+d.tolerance(ref)
        lines = [f'Nucula {ref} I2C pull-up release, Cbus={cap:g}',
                 '* Bus capacitance is a scenario, not extracted from PCB/cable.',
                 '* Sink represented by an ideal controlled switch, 100 ohm on resistance.',
                 f'Vrail {supply} 0 3', d.passive(ref, scale), f'Cbus {bus} 0 {cap:.15g}',
                 'Vctrl ctrl 0 PULSE(1 0 2u 1n 1n 20u 40u)',
                 f'Ssink {bus} 0 ctrl 0 sink', '.model sink SW(Ron=100 Roff=1e12 Vt=.5 Vh=0)',
                 '.options reltol=1e-7', '.tran 2n 10u 0 2n', '.end']
        if cap == 400e-12:
            save_circuit(out, f'i2c-{ref.lower()}-400pf', lines)
        ng.run(lines)
        t, v = ng.get('time'), ng.get(bus)
        rise = crossing(t, v, 2.1, 2e-6)-crossing(t, v, .9, 2e-6)
        analytic = math.log(7/3)*d.value(ref)*scale*cap
        assert abs(rise/analytic-1) < .002
        results.append(dict(ref=ref, assumed_capacitance_pF=cap*1e12, rise_30_70_ns=rise*1e9,
                            standard_mode_rise_pass=rise <= 1e-6,
                            within_400pF_design_ceiling=cap <= 400e-12))
        if ref == 'R19':
            ax.plot((t-2e-6)*1e6, v, label=f'{cap*1e12:g} pF')
    ax.axhline(.9, color='grey', ls=':'); ax.axhline(2.1, color='grey', ls=':')
    ax.set(xlim=(0, 4), xlabel='Time after bus release (us)', ylabel='Bus voltage (V)',
           title='2.2 kohm +1% pull-up to 3.0 V; assumed bus capacitance')
    ax.legend(); fig.savefig(out/'i2c-rise.png', dpi=160); plt.close(fig)
    return dict(cases=results, pcf8574_max_bus_Hz=100000,
                scope='RC edge only; device protocol, clock stretching, pin leakage and rail startup not simulated.')


def run_rc(ng, d, out):
    results = {}
    for name, resistor, capacitor, high, fraction, stop in [
        ('esp-enable', 'R8', 'C12', 3.31, .75, .06),
        ('oled-reset', 'R35', 'C48', 3., .8, .01)]:
        supply, node = d.node(resistor, 1), d.node(resistor, 2)
        assert d.node(capacitor, 1) == node and d.node(capacitor, 2) == '0'
        rscale, cscale = 1+d.tolerance(resistor), 1+d.tolerance(capacitor)
        lines = [f'Nucula {name} passive release, +R and +C tolerance',
                 '* IC reset output is replaced by an ideal open circuit after release.',
                 '* No supervisor delay, glitch filtering, GPIO clamp or transistor model.',
                 f'Vrail {supply} 0 {high}', d.passive(resistor, rscale),
                 d.passive(capacitor, cscale) + ' IC=0',
                 '.options reltol=1e-8', f'.tran {stop/10000:.15g} {stop} uic', '.end']
        save_circuit(out, name, lines); ng.run(lines)
        t, v = ng.get('time'), ng.get(node)
        delay = crossing(t, v, fraction*high)
        tau = d.value(resistor)*rscale*d.value(capacitor)*cscale
        assert abs(delay/(-tau*math.log(1-fraction))-1) < .002
        results[name] = dict(time_to_logic_high_ms=delay*1000, high_fraction=fraction,
                             rc_tau_ms=tau*1000,
                             scope='Passive RC after ideal reset release; initial capacitance tolerance only.')
    a, node, ground = d.node('R15', 1), d.node('R15', 2), d.node('R16', 2)
    assert ground == '0' and d.node('R16', 1) == node and d.node('C13', 1) == node
    rscale, cscale = 1+d.tolerance('R15'), 1+d.tolerance('C13')
    lines = ['Nucula battery sense divider startup, +R and +C tolerance',
             '* ADC pin is ideal high impedance; sampling capacitor/leakage not included.',
             f'Vbattery {a} 0 4.2', d.passive('R15', rscale), d.passive('R16', rscale),
             d.passive('C13', cscale)+' IC=0', '.options reltol=1e-8',
             '.tran 20u 300m uic', '.end']
    save_circuit(out, 'battery-adc-settling', lines); ng.run(lines)
    t, v = ng.get('time'), ng.get(node)
    final = 4.2*d.value('R16')/(d.value('R15')+d.value('R16'))
    tau = (d.value('R15')*d.value('R16')/(d.value('R15')+d.value('R16'))
           *rscale*d.value('C13')*cscale)
    error = 1-float(np.interp(.12, t, v))/final
    assert abs(error/math.exp(-.12/tau)-1) < .002
    results['battery-adc'] = dict(rc_tau_ms=tau*1000, settling_error_at_120ms_pct=error*100,
                                  time_to_0_1pct_ms=crossing(t,v,final*.999)*1000,
                                  settling_error_at_200ms_pct=(1-float(np.interp(.2,t,v))/final)*100,
                                  scope='Initial R/C tolerance only; capacitor temperature, ADC sampling, DC error and leakage excluded.')
    return results


def run_dc_corners(ng, d, out):
    # Ideal feedback regulation with datasheet reference/bias bounds; NOT converter dynamics.
    results = {}
    for name, upper, lower, references, bias in [
        ('buck', 'R6', 'R7', [.588, .612], 50e-9),
        ('oled-boost', 'R30', 'R31', [1.17, 1.33], 100e-9)]:
        rail, fb = d.node(upper, 1), d.node(upper, 2)
        assert d.node(lower, 1) == fb and d.node(lower, 2) == '0'
        values = []
        for vref, hi, lo, ibias in itertools.product(references, [-1, 1], [-1, 1], [-bias, bias]):
            lines = [f'Nucula {name}: ideal regulated DC operating point',
                     '* Unlimited ideal regulator; no input/dropout/current-limit/dynamic model.',
                     f'Vref ref 0 {vref}', f'Ereg {rail} 0 ref {fb} 1e9',
                     d.passive(upper, 1+hi*d.tolerance(upper)),
                     d.passive(lower, 1+lo*d.tolerance(lower)),
                     f'Ibias {fb} 0 {ibias}', '.options reltol=1e-9', '.op', '.end']
            ng.run(lines)
            vout = float(ng.get(rail)[0])
            rt = d.value(upper)*(1+hi*d.tolerance(upper))
            rb = d.value(lower)*(1+lo*d.tolerance(lower))
            assert abs(vout-(vref*(1+rt/rb)+ibias*rt)) < 1e-6
            values.append(vout)
        save_circuit(out, name+'-dc-corner', lines)
        results[name] = dict(min_V=min(values), max_V=max(values), cases=len(values),
                             scope='Ideal DC regulation only; no startup, load regulation, stability, dropout or ripple validation.')
    release = 3.08*1.02*1.015
    results['reset_release_margin_mV'] = (results['buck']['min_V']-release)*1000
    results['reset_falling_margin_mV'] = (results['buck']['min_V']-3.08*1.02)*1000
    return results
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

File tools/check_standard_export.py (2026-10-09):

#!/usr/bin/env python3
"""Read current production Gerbers/drills with the existing Gerbonara stack.

Checks restored NFC mixed via sizes, corrected mounted display mapping, and
every native footprint anchor and assembly pad against the exported files.
"""
import argparse
from collections import Counter, defaultdict
import csv
import hashlib
import json
from pathlib import Path
import warnings

from gerbonara import LayerStack, ExcellonFile
from gerbonara.graphic_objects import Flash, Line, Arc
from gerbonara.utils import MM

from check_display_mapping import PANEL_NETS, ROOT, short_net


def sha(path):
    return hashlib.sha256(path.read_bytes()).hexdigest()


def main():
    ap = argparse.ArgumentParser(description=__doc__)
    ap.add_argument('export', type=Path)
    ap.add_argument('--out', type=Path, default=ROOT / 'docs/bringup/gerber-readback.json')
    args = ap.parse_args()
    out = args.export
    manifest = json.loads((out / 'manifest.json').read_text())
    assert manifest['source_board_sha256'] == sha(ROOT / 'nucula-v2.kicad_pcb')
    for name, digest in manifest['files_sha256'].items():
        assert sha(out / name) == digest, name
    geometry = json.loads((ROOT / 'docs/pcb/routing-geometry.json').read_text())
    assert geometry['source_board_sha256'] == manifest['source_board_sha256']
    with warnings.catch_warnings(record=True) as caught:
        stack = LayerStack.open(out / 'gerbers')
        pth = ExcellonFile.open(out / 'gerbers/nucula-v2-PTH.drl')
        npth = ExcellonFile.open(out / 'gerbers/nucula-v2-NPTH.drl')
    warning_text = sorted(set(str(w.message).split(':')[-1].strip() for w in caught))
    assert all('G90 header statement found after end of header' in w for w in warning_text)
    checks = {}
    copper = {side for (side, use) in stack.graphic_layers if use == 'copper'}
    checks['four_copper_layers'] = copper == {'top', 'bottom', 'inner_1', 'inner_2'}

    mini_pads = [o for o in stack.graphic_layers['top', 'copper'].objects
                 if isinstance(o, Flash) and o.attrs.get('.P', ('',))[0] == 'U3']
    mini_by_pin = {o.attrs['.P'][1]: o for o in mini_pads}
    checks['MINI_all_53_lands_exported'] = len(mini_pads) == 53 and set(mini_by_pin) == {str(n) for n in range(1, 54)}
    checks['MINI_USB_and_supply_manufacturer_pin_numbers'] = all(
        mini_by_pin[n].attrs['.N'][0].rsplit('/', 1)[-1] == net
        for n, net in {'3': '+3V3', '8': 'ESP_EN', '26': 'Net-(U3-IO18)', '27': 'Net-(U3-IO19)'}.items())
    for layer in ['mask', 'paste']:
        flashes = [o for o in stack.graphic_layers['top', layer].objects
                   if isinstance(o, Flash) and o.attrs.get('.C') == ('U3',)]
        checks['MINI_52_perimeter_lands_no_EPAD_in_' + layer] = (
            len(flashes) == 52 and all(abs(o.x - 49) > .01 or abs(o.y - 53.86) > .01 for o in flashes))
    checks['MINI_resized_notch_in_exported_outline'] = any(
        isinstance(o, Line) and abs(o.x1 - 54.6) < 1e-5 and abs(o.x2 - 54.6) < 1e-5
        and abs(min(o.y1, o.y2) - 46.76) < 1e-5 and abs(max(o.y1, o.y2) - 60.96) < 1e-5
        for o in stack.outline.objects)

    pads = [o for o in stack.graphic_layers['top', 'copper'].objects
            if isinstance(o, Flash) and o.attrs.get('.P', ('',))[0] == 'DS1'
            and o.attrs['.P'][1].isdigit()]
    pads.sort(key=lambda o: o.x)
    checks['all_24_display_contacts_correct_in_exported_copper'] = len(pads) == 24 and all(
        int(p.attrs['.P'][1]) == 24-i and short_net(p.attrs['.N'][0]) == PANEL_NETS[i]
        and abs(p.x-(24.25+.5*i)) < 1e-6 and abs(p.y-49.3) < 1e-6
        for i, p in enumerate(pads))
    def size(obj):
        (x1, y1), (x2, y2) = obj.bounding_box(MM)
        return round(x2-x1, 6), round(y2-y1, 6)
    checks['display_copper_lands_0_30_by_1_30'] = all(size(p) == (.3, 1.3) for p in pads)
    mask = [o for o in stack.graphic_layers['top', 'mask'].objects
            if isinstance(o, Flash) and o.attrs.get('.C') == ('DS1',) and abs(o.y-49.3) < 1e-6]
    checks['display_mask_matches_all_24_lands'] = len(mask) == 24 and all(size(o) == (.3, 1.3) for o in mask)
    paste = stack.graphic_layers['top', 'paste'].objects
    regions = [o for o in paste if not isinstance(o, Flash)]
    centers = set()
    for o in regions:
        (x1, y1), (x2, y2) = o.bounding_box(MM)
        centers.add((round((x1+x2)/2, 6), round((y1+y2)/2, 6)))
    checks['display_24_separate_0_25_by_1_30_paste_apertures'] = len(regions) == 24 and all(
        size(o) == (.25, 1.3) for o in regions) and centers == {(24.25+.5*i, 49.3) for i in range(24)}
    placements = list(csv.DictReader((out / 'assembly/placements.csv').open()))
    populated = {r['Ref'] for r in placements}
    # Manufacturer side-entry lands at the locked, outward-facing placement.
    j2_expected = [(9.7, 59.6, 1.55, .6), (9.7, 58.6, 1.55, .6),
                   (5.825, 60.9, 1.8, 1.2), (5.825, 57.3, 1.8, 1.2)]
    def j2_flashes(layer):
        return [o for o in stack.graphic_layers['top', layer].objects
                if isinstance(o, Flash) and (o.attrs.get('.P', ('',))[0] == 'J2'
                                             if layer == 'copper' else o.attrs.get('.C') == ('J2',))]
    for layer in ['copper', 'mask', 'paste']:
        actual = [(round(o.x, 6), round(o.y, 6), *size(o)) for o in j2_flashes(layer)]
        checks['J2_side_entry_four_lands_in_' + layer] = sorted(actual) == sorted(j2_expected)
    j2_signals = {o.attrs['.P'][1]: o for o in j2_flashes('copper')
                  if o.attrs.get('.P', ('', ''))[1] in ['1', '2']}
    checks['J2_exported_positive_and_ground_polarity'] = (
        set(j2_signals) == {'1', '2'} and
        j2_signals['1'].attrs['.N'][0].endswith('/VBAT') and
        j2_signals['2'].attrs['.N'][0] == 'GND' and
        abs(j2_signals['1'].y - 59.6) < 1e-6 and abs(j2_signals['2'].y - 58.6) < 1e-6)
    j2_tabs = [o for o in j2_flashes('copper') if o.attrs.get('.P', ('',''))[1] == 'MP']
    checks['J2_exported_hold_down_tabs_are_unconnected'] = len(j2_tabs) == 2 and all(
        o.attrs.get('.N', ('',))[0] == 'N/C' for o in j2_tabs)
    bom = list(csv.DictReader((out/'assembly/jlcpcb-bom.csv').open()))
    j2_bom = [r for r in bom if 'J2' in [s.strip() for s in r['Designator'].split(',')]]
    checks['J2_exact_side_entry_order_code_in_BOM'] = len(j2_bom) == 1 and (
        j2_bom[0]['Comment'] == 'SM02B-SRSS-TB(LF)(SN)' and j2_bom[0]['LCSC Part #'] == 'C160402')
    cpl = list(csv.DictReader((out/'assembly/jlcpcb-cpl.csv').open()))
    # Independently read the source footprint anchors, not the exporter copy
    # or its position CSV. This catches the old shared body-center-offset bug.
    from kicad_sexpr import parse, children, child, uq
    source = parse((ROOT/'nucula-v2.kicad_pcb').read_text())
    anchors = {}
    for fp in children(source, 'footprint'):
        ref = next(uq(p[2]) for p in children(fp, 'property') if uq(p[1]) == 'Reference')
        at = child(fp, 'at')
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

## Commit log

2026-09-19 Initialize KiCad project version control
    [nucula-v2.kicad_pcb, nucula-v2.kicad_sch]
2026-09-19 Draft ESP32-C3 USB-C and Li-ion power schematic
    [bom.csv, nucula-v2.kicad_sch]
2026-09-19 Set 400 mAh battery target with JST-PH connector
    [nucula-v2.kicad_sch]
2026-09-19 Integrate NFC, OLED and breakaway I2C keyboard
    [bom.csv, keyboard.kicad_sch, nfc.kicad_sch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]
2026-09-20 Add PCB NFC coil and refine prototype component selections
    Integrate a reusable 40 mm four-turn antenna footprint, calculated matching
    network, hand-solder tuning pads, and a fabrication-ready bare-coil coupon.
    Archive RF calculations, simulation results, reference sources, and tuning
    instructions.
    Select the PN7160 crystal and supply capacitors using manufacturer guidance
    and DC-bias data. Record the confirmed 26-contact OLED interface and dedicated
    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
    [bom.csv, impedance-sweep.csv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]
2026-09-20 Keep keypad signals on center seven header pins
    Retain the DNP nine-pin header with pins 1 and 9 isolated. Map pins 2-8
    to PCF8574 P0-P6, preserving the early prototype's seven-contact order,
    and leave P7 unconnected.
    Document the researched keypad matrix mapping and scanning behavior.
    Update schematic notes, connectivity checks, BOM, verification report,
    and schematic PDF.
    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
    [bom.csv, keyboard.kicad_sch, nucula-v2.kicad_sch]
2026-09-20 Prepare components and JLCPCB BOM for 10-board assembly
    [bom.csv, footprint-audit.csv, impedance-sweep.csv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]
2026-09-20 Checkpoint preliminary four-layer PCB layout
    Save initial component placement and a 60 x 110 mm rounded board outline with the four-layer stackup and project settings. Include the existing NFC wiring audit reports. Routing and ground zones rema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
    [nucula-v2.kicad_pcb]
2026-09-20 Add inside-feed NFC antenna and ESP antenna notch
    [footprint-audit.csv, nfc.kicad_sch, nucula-v2.kicad_pcb]
2026-09-20 add break-away mouse bite line
    [bom.csv, footprint-audit.csv, jlcpcb-bom.csv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]
2026-09-20 commit again after save
    [nucula-v2.kicad_pcb]
2026-09-21 Complete four-layer PCB placement and routing
    Preserve fixed placements and route all 91 nets with top-side components, symmetric NFC matching branches, antenna pour exclusions, and power/USB routing rules. Set front and back solder mask to black.
    Add layout drawings, validation tooling and reports, and explicit NFC antenna net labels. Validation records zero DRC errors, zero unconnected items, zero schematic parity findings, and 23 passing layout checks; two existing silkscreen-edge warnings remain documented.
    [nfc.kicad_sch, nucula-v2.kicad_pcb]
2026-09-21 add silkscreen label
    [nfc-frequency-sweeps.csv, nfc-part-tolerances.csv, nfc-scenarios.csv]
2026-09-21 post save commit
    [nucula-v2.kicad_pcb]
2026-09-21 Correct OLED interface and routing for 24-pin display
    Replace the 26-contact OLED symbol and socket with the verified CON24 pinout and Hirose FH12-24S connector. Preserve DS1 placement and all other board geometry while rerouting its local pad escapes. Update purchasing data, design exports and regression checks.
    Validation: zero ERC/DRC errors, no unconnected items or schematic parity issues; 54 layout/regression checks pass; all 261 scoped simulation results unchanged. The two existing U3 silkscreen-edge warnings remain.
    [bom.csv, footprint-audit.csv, jlcpcb-bom.csv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]
2026-09-21 Use top-contact OLED connector and document manufacturing preparation
    [bom.csv, footprint-audit.csv, jlcpcb-bom.csv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]
2026-09-21 Fix USB connector clearance and prepare JLCPCB manufacturing release
    Trim the two outer USB4105 ground lands by 0.04 mm at the locating-hole end, raising nominal NPTH clearance to 0.2333 mm. Use a project-local footprint and enforce JLCPCB's 0.20 mm minimum.
    Regenerate Gerbers, drills, assembly files, drawings and source/hash archives. Refresh stock and ten-board purchasing quantities; add native and independent geometry validation. Preserve all placement, routing, holes and the confirmed OLED interface.
    [bom.csv, export-board.kicad_pcb, footprint-audit.csv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]
2026-09-22 Publish Nucula Board hardware and corrected r2 manufacturing package
    [export-board.kicad_pcb, footprint-audit.csv, jlcpcb-bom.csv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]
2026-09-22 Standardize PCB fabrication and repair routing
    Use ordinary open vias and adapted connector lands, retain a 17.70 x 5.00 mm display-ribbon access area, and rebuild routing with substantial pad entries and continuous 45-degree trace joins.
    Add independent routing-quality checks, refreshed validation and simulations, sourcing notes, and complete five-board manufacturing packages. Preserve the submitted JLCPCB r2 archive.
    Validation: zero DRC errors, unconnected items or schematic-parity findings; six routing checks, 21 layout checks and 16 fabrication checks pass. All 261 scoped simulations complete without solver errors. Cosmetic warnings and USB advisories are documented.
    [bom.csv, export-board.kicad_pcb, footprint-audit.csv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]
2026-10-01 Record Rev-A bring-up findings and NFC bench references
    [tuning-log-template.csv]
2026-10-06 Fix display pin order and record USB backfeed diagnosis
    Reverse the mounted display-to-socket mapping while preserving connector
    geometry, reroute the local fanout, and add physical contact regression checks.
    Refresh electrical, routing, fabrication, simulation and export validation.
    Preserve the annotated Rev-A bench measurements and probe guides. Record
    the accepted U4 data-to-VBUS diagnosis and the decision to proceed without
    pin-isolation rework. The backfeed hardware remedy remains unimplemented.
    [bom.csv, nucula-v2.kicad_pcb, oled.kicad_sch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]
2026-10-06 Fix USB backfeed with ground-referenced protection and data isolation
    [bom.csv, footprint-audit.csv, jlcpcb-bom.csv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]
2026-10-07 Align ESP32 antenna cutout with module width
    [nucula-v2.kicad_pcb]
2026-10-07 Round breakaway endpoint corners to match board radius
    [nucula-v2.kicad_pcb]
2026-10-08 Switch to ESP32-C3-MINI-1 with a flush antenna cutout
    Replace WROOM-02 with MINI-1-H4X while preserving GPIO assignments and
    4 MB flash. Resize the antenna notch and align the antenna tip with the
    PCB edge; update the schematic, routing, footprint, model and BOM.
    Include the current JST-SH battery connector and direct battery solder
    pads, plus manufacturing archives and the new MINI prototype package.
    Record ESP-IDF 5.4+ compatibility and the remaining physical validation.
    Validation: zero ERC/DRC errors or unconnected nets; 17 MINI checks,
    16 fabrication checks, six routing checks and 30 export checks pass.
    The 261 scoped simulation cases completed without solver errors.
    [bom.csv, export-board.kicad_pcb, footprint-audit.csv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]
2026-10-08 Add six M2 mounting holes and validate the hardware revision
    Place 2.2 mm NPTH holes at all four main-board corners and the two
    lower keyboard corners. Reserve 5.5 mm copper and component clearances
    for hardware up to 5 mm across, and move R16 with local ADC rerouting.
    Preserve the MINI antenna fit, board outline and breakaway connections.
    Add mechanical clearance checks, a dimensioned mounting plan and the
    mounting-2026-10-08 manufacturing package with verified drill data.
    Validation: zero ERC/DRC errors, unconnected nets or parity findings;
    10 mounting checks, 32 export checks and 13 regression tests pass.
    All 261 scoped simulations complete without solver errors. Existing
    cosmetic warni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
    [bom.csv, export-board.kicad_pcb, jlcpcb-bom.csv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]
2026-10-08 Label PCB buttons BOOT and RESET on the silkscreen
    [nucula-v2.kicad_pcb]
2026-10-08 move jst connector, add notch for batt cable
    [nucula-v2.kicad_pcb]
2026-10-08 Update PCB silkscreen text and artwork
    [nucula-v2.kicad_pcb]
2026-10-09 Restore rev-A NFC layout and release validated production package
    [bom.csv, export-board.kicad_pcb, impedance-sweep.csv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]
2026-10-09 Qualify stocked parts and release October 9 production package
    Replace four unavailable BOM lines, preserve rev-A NFC copper and placement, and include 792 simulation cases with fresh production validation. Remove superseded manufacturing packages so only the latest release remains.
    [bom.csv, export-board.kicad_pcb, footprint-audit.csv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]
